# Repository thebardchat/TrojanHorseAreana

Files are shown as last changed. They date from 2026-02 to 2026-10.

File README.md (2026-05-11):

# Hazel Green Trojans Sports Complex — Phase 1 3D Model

**North Alabama Regional Athletic Complex**
*"Building Champions, One Mat at a Time"*

School Colors: **Red (#CC0000)** and **Black (#1A1A1A)**

This project operates under the [ShaneTheBrain Constitution](https://github.com/thebardchat/constitution/blob/main/CONSTITUTION.md).

---

## Infrastructure

All `thebardchat` repositories run on the following local-first infrastructure:

| Component | Detail |
|---|---|
| **Compute** | Raspberry Pi 5 (16 GB RAM) |
| **Chassis** | Pironman 5-MAX by Sunfounder (NVMe RAID) |
| **Storage** | 2x WD Blue SN5000 2 TB NVMe — RAID 1 via mdadm |
| **Core path** | `/mnt/shanebrain-raid/shanebrain-core/` |
| **Dev environment** | Claude Code on Pi 5 |

> Pi before cloud. Privacy before convenience. — Pillar 4

---

## Phase 1 Specifications

| Attribute | Value |
|---|---|
| Building Footprint | 120 ft x 250 ft |
| Total Area | ~30,000 SF |
| Ceiling Height | 24 ft (single story, arena clearance) |
| Seating Capacity | ~800 (bleachers on 2 sides) |
| Wrestling Mats | 4 practice (32 ft dia.) + 1 championship (42 ft dia.) |
| Estimated Budget | $4M - $6M |

### Layout Zones

- **Entrance Lobby** (1,500 SF) — Public entry with ticket/check-in
- **Boys Locker Room** (2,000 SF)
- **Girls Locker Room** (2,000 SF)
- **S&C / Weight Room** (3,000 SF)
- **Restrooms & Concessions** (1,000 SF)
- **Wrestling Arena** — Championship center mat + 4 practice mats with bleacher seating

---

## Generated Files

### 3D CAD Models
- `Hazel_Green_Trojans_Complex.step` — Universal CAD exchange format (opens in any CAD software)
- `Hazel_Green_Trojans_Complex.stl` — 3D print / mesh render format

### Rendered Views
- `render_floorplan_2d.png` — Professional annotated 2D floor plan (for presentations)
- `render_aerial.png` — Bird's eye 3D aerial view
- `render_entrance.png` — Front entrance perspective
- `render_arena.png` — Interior arena view showing championship mat

### FreeCAD Conversion
- `import_to_freecad.py` — Macro to import STEP into FreeCAD and save as `.FCStd`

### Source Scripts
- `build_3d_model.py` — CadQuery parametric 3D model generator (produces STEP & STL)
- `render_floorplan.py` — matplotlib 2D floor plan renderer
- `render_3d_views.py` — matplotlib 3D perspective view renderer

---

## How to Regenerate

```bash
# Install dependencies
pip install cadquery matplotlib Pillow numpy

# Generate 3D model (STEP + STL)
python3 build_3d_model.py

# Generate 2D floor plan
python3 render_floorplan.py

# Generate 3D rendered views
python3 render_3d_views.py

# Convert STEP to FreeCAD native format (run inside FreeCAD)
# Open FreeCAD > Macro > Execute Macro > select import_to_freecad.py
```

---

---

## Credits

Built with Claude (Anthropic) · Runs on Raspberry Pi 5 + Pironman 5-MAX

| Partner | Role |
|---|---|
| **Claude by Anthropic** · [claude.ai](https://claude.ai) | Co-built this entire ecosystem |
| **Raspberry Pi 5** · [raspberrypi.com](https://www.raspberrypi.com) | Local compute backbone |
| **Pironman 5-MAX** · [pironman.com](https://www.pironman.com) | NVMe RAID 1 chassis that made it real |

---

*Created for Hazel Green Trojans — [@thebardchat](https://github.com/thebardchat) · Hazel Green, Alabama*

---

<div align="center">

Pulsar Sentinel — Quantum Security (https://sentinel.shanebrain.cloud)

### ⚡ Pulsar Sentinel — Quantum Security for the Rest of Us





**800 million Windows computers just lost security updates.**
Pulsar Sentinel wraps them in ML-KEM post-quantum encryption, immutable blockchain audit trails, and automatic digital inheritance — no lawyers, no cloud dependency, no corporate kill switch.

**[→ Get Protected at sentinel.shanebrain.cloud](https://sentinel.shanebrain.cloud)**

*Built by Shane Brazelton + Claude (Anthropic) · Hazel Green, Alabama*



</div>

---

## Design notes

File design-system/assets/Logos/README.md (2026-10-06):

# Logos

The THA (Trojan Horse Arena) mark lives in `blueprints/brand/` and is not duplicated here, so there is one copy to keep current.

| File | Ink | Use on |
|---|---|---|
| `blueprints/brand/THA_logo_red.svg` | #cc0000 (`school-red`) | paper or light grounds |
| `blueprints/brand/THA_logo_white.svg` | #ffffff | dark grounds, `brand` fills |
| `blueprints/brand/THA_logo_black.svg` | #1a1a1a (`school-black`) | one-color print |

Each file is a fixed fill. Do not recolor or redraw the mark.

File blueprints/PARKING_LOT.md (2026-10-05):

# PARKING LOT — KEYSTONE

Ideas that don't serve the current mission go here. Nothing on this list gets drawn, sized, or put in a params file until Shane promotes it in writing.

## Sustainability inspiration (parked per prompt §4)
- 2026-10-03: **D-018 DECIDED.** Rooftop solar + stormwater storage PROMOTED to Phase 2 as design intent (phase2.yaml `sustainability`, unsized). Retractable roof CUT. The stadium numbers below stay reference only and never go in params.

The concept compares Phase 2 to **Mercedes-Benz Stadium**. **These are that stadium's numbers, not this project's.** Don't draw them, size them, or put them in `phase2.yaml`.

- Retractable 8-petal ETFE roof (CUT per D-018)
- 4,000+ solar panels
- 680,000-gallon cistern
- 2.1M-gallon vault
- "47% less water"

If Shane asks later: a cited R-file on what *scaled* versions would mean here (rooftop solar, rainwater harvest for field irrigation, daylighting, LED + efficient HVAC). Source: prompt §4 and intake LOOK & FEEL.

## Phase 2 program (parked by D-030)

- 2026-10-03 11:39 PM CT (D-030, "Shane, firsthand"): **Suites** — future add-on, study after attendance is proven. Not drawn and not in the locked program. Starting point when promoted: P2-G-003 Rev C (frozen) + R-016 (suite sizes, precedents, code flags; a suite level would be a 3rd story).

## Other parked items

- From the 2026-10-03 intake: an early Gemini prompt used Kelly Green #006B3C + gold. **Rejected.** Red and black, never green. Kept here only so nobody brings it back.
- The repo's public landing page (`index.html`, protected) calls the project "A strategy battle arena built in the ShaneBrain ecosystem." That doesn't describe the athletic complex. KEYSTONE won't edit it (protected file). Shane, your call.

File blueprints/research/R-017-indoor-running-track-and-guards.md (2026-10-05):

# R-017 — Indoor running / walking track: lane width, lane count, laps per mile, crossings, guards (Phase 2, Level 2 loop)

Researched by KEYSTONE 2026-10-04 for P2-T-004 Rev D (P2-A-101/102 Rev D) and P2-G-003 Rev F, after Shane's 4:55 AM CT direction (D-035 DECIDED): a complete continuous walkway / running-training loop around the top of Level 2. All sources retrieved 2026-10-04.
Status: research note. The track sources are design guides (one DoD criteria document, two trade-press articles), not building code. Guard text is IBC 2021 (UpCodes, Alabama). AHJ and code edition are OPEN (D-008).

## Sources
- **S1** — UFC 4-740-02N, *Fitness and Recreational Facilities* (DoD Unified Facilities Criteria), §4.1.7 indoor running track — https://www.constructionknowledge.net/public_domain_documents/Div_11_Equipment/DOD_Fitness_and_Rec_facilities_4_740_02n.pdf — retrieved 2026-10-04. CRITERIA (federal design guide; not binding here).
- **S2** — Athletic Business, "A Running Start" — https://www.athleticbusiness.com/facilities/fitness/article/15140481/a-running-start — retrieved 2026-10-04. TRADE PRESS.
- **S3** — Athletic Business, "Designing Tracks for Recreational Users" — https://www.athleticbusiness.com/facilities/rec-center/article/15146121/designing-tracks-for-recreational-users — retrieved 2026-10-04. TRADE PRESS.
- **S4** — IBC 2021 Chapter 10, Means of Egress, §§1015.2-1015.4, 1030.17 (UpCodes, Alabama) — https://up.codes/viewer/alabama/ibc-2021/chapter/10/means-of-egress — retrieved 2026-10-04. PRIMARY (via viewer).

## R-017.1 Lane width and lane count

QUESTION: How wide should a recreational indoor running / walking loop be, per lane and overall?

ANSWER: S1 §4.1.7 sets an indoor running track at a minimum of 12 ft wide with at least 3 lanes of 42 in. S2 reports three lanes of 36-42 in as typically adequate for recreational tracks and cites ACSM's 20 ft inside radius for turns. KEYSTONE uses **42 in per lane** (the top of S2's range, S1's figure). With the upper tier fixed at 15 ft and the box at 204 x 252 ft, only **7 ft = 2 lanes** fits without moving the tier or growing the box; the existing Rev C east walkway was already 7 ft. **2 lanes is ASSUMED and is fewer than both guides recommend (3).** 3 lanes x 42 in = 10.5 ft (S2); 12 ft (S1). The loop has squared corners (no 20 ft radius turns), so it suits walking and easy running more than fast running.

## R-017.2 Laps per mile

ANSWER: S3: no more than 12 laps per mile, 8-10 preferred. Rev D centerline = 2 x (148 + 205) = 706 ft → 5,280 / 706 = **7.48 laps per mile**, which is fewer laps (a longer loop) than the preferred range, so it meets the guidance. Lane 1 (inside) ≈ 2 x (144.5 + 201.5) = 692 ft; lane 2 (outside) ≈ 720 ft (arithmetic, lane centerlines 1.75 ft in from each edge).

## R-017.3 Crossings

ANSWER: S3 names users crossing the track as a hazard and recommends bringing stairs up inside the track perimeter. In Rev D the stairs and the elevator open onto the outside of the loop, and on event days spectators cross it to reach the upper tier (the loop is the upper concourse on event days). KEYSTONE treats the loop as a training feature on non-event days only; crossing points, signage and lane markings are architect / operations items.

## R-017.4 Guards at open edges

ANSWER: S4 §1015.2: guards are required along open-sided walking surfaces located more than 30 in above the floor or grade below, measured within 36 in horizontally of the edge. §1015.3: guards at least 42 in high. §1015.4: openings must not pass a 4 in sphere (with listed exceptions). §1030.17: guards at assembly seating (cross aisles, perimeter of tiers) have their own heights. Rev D marks 42 in guards on the loop's west edge (over the arena / athlete corridor) and the south edge over the double-height lobby; the tier backs need rails / guards per 1030.17 (architect).

EDITION / SECTION: IBC 2021 §§1015.2, 1015.3, 1015.4, 1030.17. 2018 numbering differs for assembly (1029.x); D-008 edition OPEN.

CONFIDENCE: MEDIUM for lane width and laps (design guides) / HIGH for the guard rules / LOW for the loop geometry (ASSUMED).

NEEDS ARCHITECT CONFIRMATION: YES (lane count, track surface, corner treatment, crossings, guard design, structure under the west leg).

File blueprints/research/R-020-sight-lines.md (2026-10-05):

# R-020 — Sight-line study: C-values for the telescopic lower tier and the fixed upper tier (P2-A-302 Rev A)

Researched and computed by KEYSTONE 2026-10-04 (Shane 7:24 AM CT: "sight-line study BEFORE more seating detail"). All sources retrieved 2026-10-04.
Status: research note + schematic calculation. Not a design by a licensed architect; the AHJ / architect confirm. Values and method: `params/phase2_sightlines.yaml`; sheet P2-A-302 Rev A; generator `phase2/src/p2_a_302.py` (`--md` prints the table below).

## Sources
- **S1** — Starena Group, "Sight Lines for Seated Spectators" (reprints Green Guide diagram 12.1 and the C formula) — https://www.starenaaust.com/products/stadium-seating/sight-lines — SECONDARY (the Green Guide itself, DCMS *Guide to Safety at Sports Grounds* 5th ed. 2008 §12.3, was not purchased).
- **S2** — Parametric Monkey, "Stadium seating bowl with Dynamo" (2017) — https://parametricmonkey.com/2017/10/23/seating-bowl/ — formula C = D(N+R)/(D+T) − R (Green Guide §12.3, p.109); BVN Stadium.Cvalue defaults: eye 1,200 mm above the tread, 150 mm forward of the row's rear edge, "considered industry standard"; C descriptors 60 / 90 / 120 / 150 mm.
- **S3** — FIFA, *Football Stadiums Guidelines* 2.3 Stadium Bowl — https://publications.fifa.com/es/football-stadiums-guidelines/general-process-guidelines/design/stadium-bowl/ — C = 120 optimal, 90 preferred, 60 minimum in specific areas, "should be avoided in lower tiers"; upper tiers may go lower.
- **S4** — CEN/TR 15913:2009 (iTeh preview) — https://cdn.standards.iteh.ai/samples/32554/d7b4616fb5e0479f8e98daf147f88d63/SIST-TP-CEN-TR-15913-2009.pdf — "C ≥ 90 mm generally acceptable for all newly constructed spectator stands"; uses 1.15 m (wheelchair user) and 1.8 m (standing person) in accessible-viewing checks.
- **S5** — DIN EN 13200-1:2019 summary (kpt-bj.com listing) — standing eye 1.6 m (SECONDARY; standard text not purchased). Shane's range 5'-2"–5'-6" (1.57–1.68 m) contains it.
- **S6** — Hussey Seating, MAXAM brochure, Dimensional Data + Notes (box copy `research_src/hussey_maxam.pdf`, R-008 S4): 6 rows @ 11⅝" → overall seat height 6'-3⅛", closed 3'-6"; recessed: +6" depth (4'-0"), +2¼" height (6'-5⅜"); rear row stays in the recess when open.
- **S7** — IBC 2021 1003.2 (ceiling ≥ 7'-6" in means of egress), 1003.3.1 (80" headroom), 1030.14.2 (aisle risers 4–8", treads ≥ 11"), 1030.17.3 (26" sightline-constrained guard) — UpCodes.

## Method
- C (mm) = D_front × R_behind / D_behind − R_front, every eye placed from the actual tier geometry (equivalent to S2's formula; also handles the step from the lower to the upper tier and the loop rail).
- Eyes: seated 1.2 m above the row tread, 0.15 m forward of the row's rear edge (S2); standing 1.6 m (S5). Rail stander: 1 ft behind the upper tier's back edge on the loop, standing (ASSUMED).
- Focal point (Shane): near edge of the nearest mat, at the floor (mat thickness ignored — slightly conservative). From the frozen plan Rev D: N and S tier fronts **25 ft** from the nearest mat edge (10 ft clear + 15 ft table zone); E tier front **10 ft**. No west tier.
- Grades (KEYSTONE): ≥ 90 mm PASS (S3 preferred, S4), 60–90 MARGINAL (Shane's 60–90 target; S3 minimum), < 60 FAIL.
- AS DRAWN = P2-A-301 geometry: lower 6 rows × 24" @ 11⅝" (Hussey, ASSUMED choice), front at the floor; upper 5 rows × 36" @ 14" stepping DOWN from the loop (L2 FF 15 ft, D-049) to a 9.17 ft front row; 26" fascia.
- PROPOSED (D-053, OPEN): upper riser 19" per row (3 aisle risers of 6⅓" on 12" treads — within 1030.14.2) → front row 15 − 5 × 19/12 = **7.08 ft**; east tier 6 ft further from the mats (focal 16 ft). Lower tier unchanged.
- 2D sections only (perpendicular to each side). Corners, wheelchair positions (S4 1.15 m eye), the mixed case (front row standing, row behind seated) and the focal height of a raised mat are NOT checked.

## Results (C in mm; ~ = marginal, ✗ = fail)

| Row | drawn N/S 25 ft seated | drawn N/S 25 ft standing | drawn E 10 ft seated | drawn E 10 ft standing | proposed N/S 25 ft seated | proposed N/S 25 ft standing | proposed E 16 ft seated | proposed E 16 ft standing |
|---|---|---|---|---|---|---|---|---|
| L2 | 190 | 162 | 74 ~ | 15 ✗ | 190 | 162 | 142 | 101 |
| L3 | 178 | 152 | 64 ~ | 13 ✗ | 178 | 152 | 129 | 92 |
| L4 | 167 | 142 | 57 ✗ | 11 ✗ | 167 | 142 | 118 | 84 ~ |
| L5 | 157 | 134 | 51 ✗ | 10 ✗ | 157 | 134 | 109 | 77 ~ |
| L6 | 149 | 127 | 46 ✗ | 9 ✗ | 149 | 127 | 101 | 72 ~ |
| U1 | 1014 | 984 | 829 | 780 | 428 | 397 | 352 | 313 |
| U2 | 49 ✗ | 20 ✗ | -119 ✗ | -162 ✗ | 211 | 183 | 139 | 103 |
| U3 | 45 ✗ | 19 ✗ | -107 ✗ | -146 ✗ | 198 | 171 | 127 | 94 |
| U4 | 43 ✗ | 18 ✗ | -97 ✗ | -133 ✗ | 185 | 161 | 118 | 87 ~ |
| U5 | 40 ✗ | 17 ✗ | -89 ✗ | -122 ✗ | 175 | 151 | 109 | 81 ~ |
| RAIL | 582 | 182 | 513 | 113 | 709 | 309 | 673 | 273 |
| fascia clearance U1 (mm) | 286 | 661 | 131 | 490 | 326 | 701 | 263 | 631 |
| upper front row deck (ft) | 9.17 | 9.17 | 9.17 | 9.17 | 7.08 | 7.08 | 7.08 | 7.08 |

Failures AS DRAWN:
- **Upper tier fails on every side**: N/S seated 40–49, standing 17–20; east negative (rows U2–U5 cannot see the near mat edge over the row in front). 14" per 36" row is too flat for a 25 ft (or 10 ft) focal distance.
- **East lower tier** (10 ft focal): seated L4–L6 fail (46–57), L2–L3 marginal (64–74); standing 9–15 (all fail).
- N/S lower tier passes (seated 149–190, standing 127–162). U1 sees well over the lower tier (≥ 780) and over the fascia (clearance 131–661 mm). Rail standers pass (113–582).

Riser / layout changes that close it (all seated rows ≥ 101, PROPOSED column):
1. **Upper riser 14" → 19" per row.** Because the back stays at the loop (D-049), the front row drops 9.17 → 7.08 ft. 16" passes N/S (94–114) but not the east side; 19" is the smallest round value tested that passes both with change 2.
2. **East side: move the east tier 6 ft further from the mats (10 → 16 ft clear).** With the loop fixed at 15 ft and a 10 ft focal distance no riser pair reaches 60 mm (best ≈ 46 mm with 19" upper). 12 ft → 68; 14 ft → 85; 16 ft → 101 (seated). Cost: +6 ft east-west ≈ +1,512 SF footprint (51,503 → 53,015, still < 55,000 cap, D-031), or take 6 ft from the 22 ft east support zone.
3. Lower tier stays at 11⅝" (Hussey). A 16" Hussey rise fixes the east lower rows alone, but its top (≈ 6.7 ft) then collides with the stepped-down upper tier front.
- East standing stays MARGINAL (72–103) with the proposal. Sensitivity: with S4's 1.8 m standing eye the east L6 standing value drops to 57 (fail), N/S stays ≥ 116.

## Telescopic stack under the upper-tier front (D-049)
- **Closed, recessed** (S6 minimum recess 4'-0" deep × 6'-5⅜" high): as drawn (front 9.17 ft) it fits only if the tier structure + finish at the front edge is **≤ 32.6 in** (9.17 − 6.45 ft). With the proposed 7.08 ft front only **7.6 in** remain → does not fit.
- **Open**: in a recessed application the rear rows stay in the recess (S6), so rows 5–6 would sit under the overhang. Row 6 deck 4.84 ft + 7'-6" (1003.2, aisle = means of egress) = 12.34 ft needed vs the tier deck ≈ 10.72 ft at the recess back, less structure → **CONFLICT** (as drawn and proposed).
- Recommendation: keep the stack **wall-attached in front of the upper-tier face** (as P2-A-301 Rev A/B draws it); use the low zone under the tier for storage / mechanical only (D-049). Exit passages that run under the tier front (EXIT N / E passages) still need a ≥ 7'-6" ceiling → local raise or vomitory cut at the next A-101/A-102 revision.

QUESTION: Do the drawn tiers give acceptable sight lines to the near mat edge, seated and standing?

ANSWER: **No for the upper tier (all sides) and the east lower tier.** Upper risers of 19" per row plus a 16 ft east focal distance bring every seated row to ≥ 101 mm (PASS) and standing to ≥ 72 mm (east marginal). Logged as D-053 (OPEN, Shane decides). Seating detail should wait for that decision.

CONFIDENCE: HIGH for the arithmetic / MEDIUM for the inputs (secondary sources for eye heights; geometry schematic; focal point per Shane).

NEEDS ARCHITECT CONFIRMATION: YES (final tier section, wheelchair sightlines, guard type at the fascia, structure depth under the tier, scoreboard / rigging obstructions).

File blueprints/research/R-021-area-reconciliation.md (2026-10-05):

# R-021 — Area reconciliation: program basis vs drawn basis (Phase 2)

Written 2026-10-04 8:40 AM CT by KEYSTONE for Shane (8:36 AM CT order, item 4). Read-only arithmetic; no drawing, no new sheet.
**Rules applied:** there is **no 55,000 SF cap** (D-056 — "55,000 SF = early rough estimate, not a limit"; D-031 retired), so this note has no margin lines. Every area table reports **L1 footprint, L2 area, TOTAL GSF and change vs the last revision** (D-057).

## Sources

- **S1** `params/phase2_plan_rev_d.yaml` — P2-A-101/102 Rev D geometry (building 204 x 252 ft + NE tower 19 x 5; arena volume [56,56,182,224]; L2 open-to-below: arena 126 x 168, lobby 58 x 34). Frozen with Phase 2 Schematic Set Rev A (D-036).
- **S2** P2-A-102 Rev D area check (sheet text): "Drawn L2 floor 28,363 SF (building minus open-to-below) … Total drawn ≈ 79,866 vs 78,784 program GSF (P2-G-003 Rev F)."
- **S3** `phase2/src/p2_testfit.py` `summary_f()` / `compute_loop()` + `params/phase2_program.yaml` — P2-G-003 Rev F method: gross-up g = 1.25, mechanical 5 % of gross on L1, arena volume AV = g x (event floor + lower seating), footprint F = max(L1, AV + L2), loop 4,942 SF added to L2 without gross-up. Re-run 2026-10-04 8:38 AM CT (unchanged code, output below).
- **S4** D-052 (4 stairs x 76 in, mid landing = width → 152 x 256 in = 12.67 x 21.33 ft = 270.2 SF per stair per level; Rev F program stair = 63.95 in x (132 + 2 x 48) in = 202.5 SF); D-051 (landing ≥ width, IBC 2021 1011.6).
- **S5** D-053 (east seats 6 ft further from the mats → east wall + 6 ft; 6 x 252 = 1,512 SF L1).
- **S6** `params/phase2_site.yaml` `footprint_check` (P2-C-101 Rev A arithmetic, 7:44 AM CT).

ASSUMED (KEYSTONE, LOW): the east shift widens the arena volume / L2 open-to-below by 6 ft over its 168 ft N-S length (6 x 168 = 1,008 SF), so L2 gains 1,512 − 1,008 = 504 SF; the 19 in upper risers (D-053) change heights, not plan area; the 76 in stairs grow inward from their corners (P2-C-101 Rev A), so only the NE tower (ST-2) widens (2.333 x 5 = 11.67 SF, on both levels).

## 1. True current size (drawn basis) — D-057 table

| Basis | L1 footprint (SF) | L2 area (SF) | TOTAL GSF (SF) | Change vs last revision |
|---|---:|---:|---:|---|
| **As drawn: P2-A-101/102 Rev D** (frozen) | 51,503.0 | 28,363.0 | 79,866.0 | vs Rev C: see P2-A-102 Rev D |
| **Decided, next A-101/A-102 revision** (D-052 + D-053, not yet drawn) | **53,026.7** | **28,878.7** | **81,905.3** | **+1,523.7 / +515.7 / +2,039.3** vs Rev D |

Arithmetic:
- Rev D L1 = 204 x 252 = 51,408 + 19 x 5 = 95 → **51,503.0** (S1).
- Rev D L2 = 51,503 − 126 x 168 (21,168, arena open) − 58 x 34 (1,972, lobby open) → **28,363.0** (S1, S2). TOTAL = 51,503 + 28,363 = **79,866.0**.
- Next rev L1 = 51,503 + 1,512 (east shift) + 11.67 (NE tower) = **53,026.7**.
- Next rev L2 = 28,363 + 1,512 − 1,008 (wider arena opening, ASSUMED) + 11.67 = **28,878.7**. TOTAL = **81,905.3**.

**Answer: the true current size is L1 footprint 53,027 SF / L2 area 28,879 SF / TOTAL GSF 81,905 SF** (decided state; the frozen drawings still show 51,503 / 28,363 / 79,866). The program basis below is a planning-factor estimate, not the size.

## 2. Program basis (P2-G-003 Rev F method) — same table form

| Step | L1 gross (SF) | L2 gross (SF) | Footprint F (SF) | TOTAL GSF (SF) |
|---|---:|---:|---:|---:|
| Rev F as approved (S3) | 51,194.1 | 27,589.5 | 52,738.4 (AV 25,148.8 + L2) | 78,783.6 |
| + 76 in stairs (S4): stairs + elevator 874.0 → 1,144.9 net per level (+270.9) | 51,577.8 | 27,928.1 | 53,076.9 | 79,505.9 |
| + east shift (S5, flat add as on P2-C-101 Rev A; L2 +504 ASSUMED as above) | — | 28,432.1 | **54,588.9** | **81,521.9** (79,505.9 + 1,512 + 504) |

Note: in the program the footprint is set by AV + L2 (25,148.8 + 27,589.5 = 52,738.4), which is larger than the programmed L1 gross (51,194.1): the L2 deck needs 1,544 SF more ring than the L1 rooms make, so the footprint carries ≈ 1,544 SF of L1 space that no program line counts. In the drawn plan that is the FLEX space (team assembly ≈ 2,072, FLEX / storage 1,011).

## 3. Line-by-line reconciliation: footprint 54,588.9 (program) vs 53,026.7 (drawn) = 1,562.2

| # | Line | What the program counts | What the drawing counts | Program | Drawn | Δ (P − D) |
|---|---|---|---|---:|---:|---:|
| 1 | Arena volume (event floor + telescopic lower tier, double height) | 1.25 x (16,400 floor + 3,719 telescopic seats [1,100 x 3.38]) | 126 x 168 box: floor 114 x 144 = 16,416 + tier bands N/S 2 x 126 x 12 = 3,024 + E 12 x 144 = 1,728 | 25,148.8 | 21,168.0 | **+3,980.8** |
| 2 | L2 deck over the L1 ring (upper tier, S&C, cross-training, admin, restrooms, stairs/elevator, loop) | 1.25 x 18,118.0 net + 4,942 loop | building − arena opening − lobby opening (incl. L2 corridor, stretch strip, upper concourse) | 27,589.5 | 28,363.0 | **−773.5** |
| 3 | Lobby open-to-below (double-height lobby inside the footprint) | not modelled (foyer is 800 net on L1 only) | 58 x 34 inside the footprint, no L2 floor | 0.0 | 1,972.0 | **−1,972.0** |
| = | Subtotal: Rev F program vs Rev D drawn | | | 52,738.4 | 51,503.0 | **+1,235.4** |
| 4 | 76 in stairs (D-052) | 4 x (270.2 − 202.5) = 270.9 net per level, x 1.25 on L2 (F follows AV + L2) | stairs grow inward; only the NE tower widens 2.333 x 5 | +338.6 | +11.7 | **+326.9** |
| 5 | East shift 6 ft (D-053) | flat +6 x 252 | +6 x 252 | +1,512.0 | +1,512.0 | **0.0** |
| = | **Total** | | | **54,588.9** | **53,026.7** | **+1,562.2** |

Check: 3,980.8 − 773.5 − 1,972.0 = 1,235.3 (1,235.35 unrounded) + 326.9 + 0 = **1,562.2** ✓.

Where the gap comes from, in plain terms:
1. **+3,981** — the program grosses up the event floor and seats by 25 % as if they were rooms with walls and corridors (16,400 x 0.25 = 4,100 alone). The real arena volume is one open box, so the drawing is smaller there.
2. **−774** — the drawn L2 deck is a bit bigger than the program's L2 (the drawing has a full L2 corridor zone and a 6 ft stretch strip that the program does not list).
3. **−1,972** — the program never counted the double-height lobby's footprint above the 800 SF foyer; the drawing does.
4. **+327** — the program adds the 76 in stairs as new grossed-up area; the drawing absorbs them inside the existing box.

## 4. TOTAL GSF reconciliation (decided state)

| | Program estimate | Drawn basis | Δ (P − D) |
|---|---:|---:|---:|
| L1 | 53,089.8 (51,577.8 + 1,512; programmed rooms only) | 53,026.7 (full footprint) | +63.1 |
| L2 | 28,432.1 | 28,878.7 | −446.6 |
| **TOTAL GSF** | **81,521.9** | **81,905.3** | **−383.4** |

The totals sit within 0.5 %: the program's extra arena gross-up is roughly offset by the space it never counts (lobby void footprint, unprogrammed L1 ring under the L2 overhang).

## Confidence

HIGH for the arithmetic (re-run from params); LOW for the geometry behind it (every plan coordinate is ASSUMED, schematic). The east-shift L2 split (+504) is ASSUMED until the next A-101/A-102 revision draws it.

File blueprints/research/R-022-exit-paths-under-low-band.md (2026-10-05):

# R-022 — Exit paths under the upper tier's low band (Phase 2)

Written 2026-10-04 by KEYSTONE for Shane (9:47 AM CT order: "do NOT redesign silently — write the finding with TWO options with numbers, log OPEN, show the conflict on A-301 Rev C"). This is arithmetic only. Nothing is redesigned: P2-A-101/102 Rev E stay as drawn and P2-A-301 Rev C shows the conflict in red. Decision: **D-061 OPEN**.

## Sources

- **S1** `params/phase2_plan_rev_e.yaml` (P2-A-101/102 Rev E). Upper tier: 5 rows × 36 in, 19 in risers, front row 7.08 ft, steps down from the loop at L2 FF 15 ft (D-049, D-053). `low_band_ft: 6` = rows 1–2. Zones: exit_n [123.85,224,131.85,252], exit_e [188,175.09,210,183.09], conc_e [165,0,210,56], lobby [84,0,142,56] (PORTAL x 107–119), ath_route [56,48,84,56], concession [127,37.67,142,56]. Upper bands: N [56,224,188,239], S [56,41,188,56], E [188,41,203,239].
- **S2** `params/phase2_sect.yaml` `rev_c`: 1.5 ft deck structure under each tread (ASSUMED). Clear under rows 1–5 = 5.58 / 7.17 / 8.75 / 10.33 / 11.92 ft.
- **S3** IBC 2021 1003.2: the means of egress needs a ceiling height of at least 7 ft 6 in (UpCodes, retrieved 2026-10-04, the same citation as P2-A-301 Rev B and P2-A-302 Rev A).
- **S4** `phase2/src/p2_testfit.py` `summary_g()` / P2-G-003 Rev G: upper-tier capacity 1,155 for the 1,100 required (55 spare). Upper seat factor is 6.0 SF/seat (R-008) on 3 ft rows, so 2 ft of row per seat = **0.5 seat per foot per row**.
- **S5** `phase2/src/p2_a_302.py` `calc()`: C-values for the raised-tier variant (Option B).
- **S6** D-052 (76 in stairs, 26 risers at 6.92 in), D-051 (intermediate landing = width, IBC 2021 1011.6), IBC 2021 1011.5.2 (risers 4–7 in, treads ≥ 11 in), 1030.14.2 (aisle risers 4–8 in), 1030.6.2.2 (roof ≥ 15 ft above the highest aisle, if smoke-protected).

## 1. Finding: exit paths under the 6 ft low band

The clear height under rows 1–2 is 5.6 ft and 7.2 ft (S2). Both are below 7'-6" (S3). These paths cross the band:

| Path | Where it crosses the band | Length under rows 1–2 |
|---|---|---:|
| EXIT (N) | x 123.85–131.85, y 224–230 (V1 → X5) | 8 ft |
| EXIT (E) | y 175.09–183.09, x 188–194 (V2 → X7) | 8 ft |
| SE concourse | S strip x 165–188 (y 50–56) + E strip y 41–56 (x 188–194) | 23 + 15 = 38 ft |
| Lobby / portal / athlete-route edge | x 56–127, y 50–56: athlete route 28 ft (x 56–84) + lobby 43 ft (x 84–127, incl. PORTAL 12 ft at x 107–119) | 71 ft |
| **Total** | | **125 ft** |

Also noted (not an egress path): the concession's north 6 ft (x 127–142) is under the band. An occupiable room also needs a 7'-6" ceiling (IBC 2021 1208.2, KEYSTONE recollection, not re-read today). That strip should be counter-back storage, or it is resolved by Option B.

D-060 (which locker reading) stays OPEN, drawn as on A-101 Rev E: event lockers start behind the band (2,723 SF vs 3,600 programmed).

## 2. Option A — omit upper rows 1–2 over each path (vomitory-style cut)

Seats lost = 2 rows × length × 0.5 seat/ft (S4).

| Path | Seats lost |
|---|---:|
| EXIT (N) 8 ft | 8 |
| EXIT (E) 8 ft | 8 |
| SE concourse 38 ft | 38 |
| Lobby / portal / athlete-route edge 71 ft | 71 |
| **A (all paths)** | **125** |

- Upper capacity 1,155 → **1,030**, which is **70 short** of the 1,100 upper seats (only 55 spare). Holding 1,100 would need 70 × 6.0 = 420 SF of upper band somewhere else, or 70 seats moved to the lower tier (lower-tier room not checked).
- Building SF is unchanged. Seats delivered = 1,100 lower + 1,030 upper = 2,130, so GSF per seat = 81,976.4 ÷ 2,200 = 37.3 → 81,976.4 ÷ 2,130 = **38.5 SF/seat** if the 70 are not replaced.
- **A-min variant:** rail off the strips that are not exit paths (the SE concourse strip as storage, the lobby strip except the portal as display). Cut rows 1–2 only over EXIT (N) 8 + EXIT (E) 8 + PORTAL 12 + athlete route 28 = **56 seats** → 1,099, **1 short** of 1,100. The athlete route is 8 ft wide with 6 ft under the band, so it cannot be railed off.
- Clear under the cut: the soffit becomes row 3 = 8.75 ft ≥ 7'-6". The upper tier gets openings with guards at each cut (1015 / 1030.17). Lower-tier vomitories V1 / V2 already line up with Exit N / Exit E.
- Not drawn. (A non-option note: shifting the athlete route 6 ft south into Concourse W would take it out from under the band and cut A-min to 28 seats. That is a layout change and is not drawn either.)

## 3. Option B — raise the upper tier (and all of Level 2) so row 1 clears 7'-6"

The tier's back stays at the loop = L2 FF (D-049), so clearing row 1 means raising L2.

- **L2 FF 15'-0" → 17'-9" (213 in), upper risers 19 → 21 in** (3 aisle risers of 7.0 in, 12 in treads, inside 1030.14.2). Front row = 17.75 − 5 × 1.75 = **9.0 ft**. Clear under row 1 = 9.0 − 1.5 = **7.5 ft = 7'-6"** (meets 1003.2 exactly; no margin).
- Why 21 in and not 19: raising L2 by 1.92 ft with 19 in risers would also give a 9.0 ft front row, but east seated C would drop to 68 mm (standing 40, FAIL) (S5). At 21 in the minimum C equals Rev E: **N/S seated 149 / standing 127, E seated 101 / standing 72 mm**. Higher risers gain nothing because the lower tier then sets the minimum.
- **Seats lost: 0.** The low band disappears, so the event lockers can run back to the tier lines: **3,600 SF (+877)**, which makes D-060 moot.
- **Stairs:** 213 in ÷ 7 in max → 31 risers at 6.87 in, 2 flights (16 + 15), 15 treads × 11 in = 165 in run. Each stair is 152 × (48 + 165 + 76) = 152 × 289 in = 12.67 × 24.08 ft = **305.1 SF vs 270.2: +34.8 SF per stair per level, ≈ +279 SF** for 4 stairs × 2 levels (clear dimensions). Each stair is 2.75 ft longer. If ST-2 grows outward, the NE tower goes 6.67 → about 9.4 ft deep (+58.7 SF L1 footprint).
- **SF/seat:** +279 SF ÷ 2,200 = **+0.13 SF/seat** (37.3 → 37.4 GSF/seat), with no seats lost.
- **Heights:** ring roof 30 → **32.75 ft** (L2 + 15). Ring walls on A-201 are 2.75 ft taller. Arena U/S structure stays 36 ft and roof 42 ft, so the court clear is unchanged. 1030.6.2.2 (if smoke-protected): highest aisle = loop 17.75 ft → roof ≥ 32.75 ft; 36 ft drawn (3.25 ft margin). Elevator travel 17.75 ft.
- **Also re-check:** the telescopic stack still sits at the tier face (P2-A-302 Rev B). L2 rooms (S&C, cross-training) sit 2.75 ft higher. The 26 in fascia at the front still clears (U1 C unchanged).

## 4. Comparison

| | Option A (cut rows 1–2) | A-min (rails + cut 4 paths) | Option B (L2 17'-9", 21 in risers) |
|---|---:|---:|---:|
| Upper capacity lost | 125 | 56 | 0 |
| Upper capacity vs 1,100 | 1,030 (−70) | 1,099 (−1) | 1,155 (+55) |
| Building SF change | 0 | 0 | ≈ +279 (stairs) |
| Seats delivered / GSF per seat | 2,130 / 38.5 | 2,199 / 37.3 | 2,200 / 37.4 |
| Event lockers | 2,723 SF (D-060 open) | 2,723 SF (D-060 open) | 3,600 SF (D-060 moot) |
| Sight lines (min C seated N/S / E) | unchanged 149 / 101 | unchanged | 149 / 101 |
| Other | guards at each cut | rails + storage strips | ring roof 32.75', taller walls, longer stairs |

KEYSTONE does not pick an option. Shane decides **D-061**.

## 5. Decided (2026-10-04 10:27 AM CT)

Shane chose **Option B** (D-061 DECIDED): "raise Level 2 to 17'-9" with 21 in upper risers. No seats lost; upper-tier front row ≥ 7'-6" clear over ALL exit paths." D-060 is settled in the same message: event lockers go back to the full 3,600 SF behind the tier.

How it was drawn (P2-A-101/102 Rev F, P2-A-301 Rev D, P2-A-302 Rev C, P2-A-201 Rev G, P2-C-101 Rev C, P2-G-003 Rev I):

- **Stairs grow inward.** Each stair is 12.67 × 24.08 ft (31 risers at 6.87 in, 16 + 15). ST-2 grows **west** along the north wall, not north. The NE tower becomes 24.08 × 6.67 ft (was 21.33 × 6.67), not the ~9.4 ft deep tower estimated in §3. The rest of the growth comes out of interior rooms (mech N, S&C, stretch).
- **Drawn size (D-057):** L1 53,080.6 / L2 28,932.6 / TOTAL 82,013.1 GSF, which is **+36.7 vs Rev E** (only the tower's +18.3 SF on each level). §3's ≈ +279 SF was the program-side growth. The program (G-003 Rev I) grows +371.6 (L1 + L2 gross 81,119.1) because vertical circulation goes from 1,144.9 to 1,284.2 SF per level.
- **Clearance:** front row 9.0 ft. Clear = 7'-6" exactly with 1.5 ft structure ASSUMED: **no margin, structural engineer to confirm.**
- **Sight lines (A-302 Rev C):** the lower tier still governs, at N/S 149 / 127 and E 101 / 72 mm. Upper tier N/S 179 / 156, E 105 / 76 mm. No FAIL. East standing stays MARGINAL.
- **1030.6.2.2 (if smoke-protected):** highest aisle = loop 17.75 ft, so the roof must be ≥ 32.75 ft. The arena's U/S structure is drawn at 36 ft, so it PASSES with a 3.25 ft margin.

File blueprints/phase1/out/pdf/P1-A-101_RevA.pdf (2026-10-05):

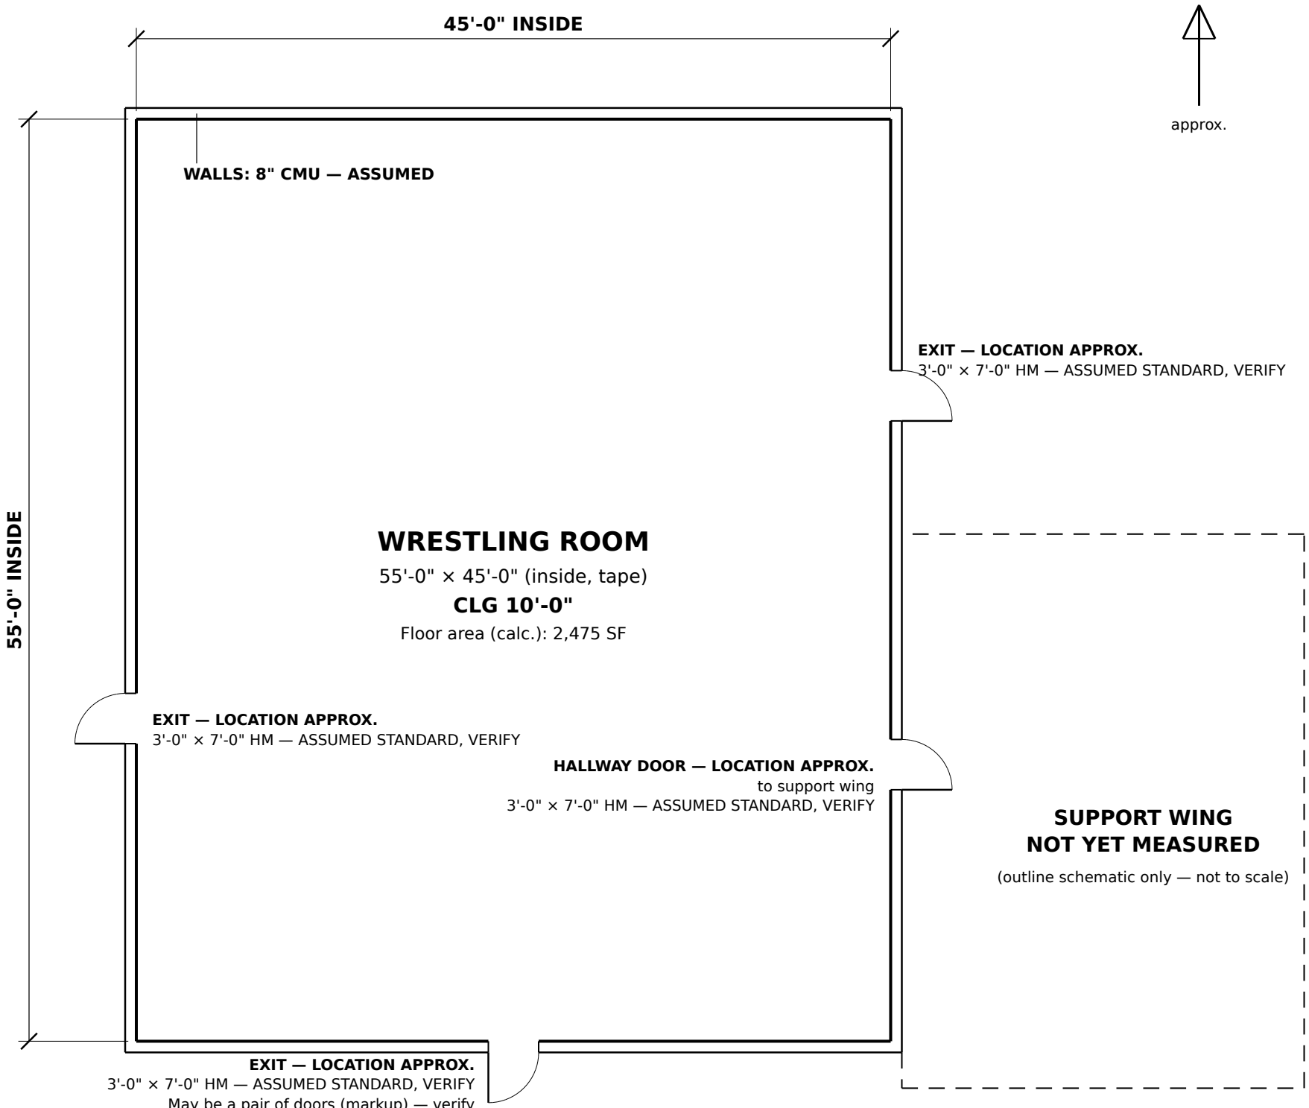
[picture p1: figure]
EXIT — LOCATION APPROX.; HALLWAY DOOR — LOCATION APPROX. to support wing; WRESTLING ROOM; 55'-0" × 45'-0" (inside, tape) CLG 10'-0"; Floor area (calc.): 2,475 SF; WALLS: 8" CMU — ASSUMED; 45'-0" INSIDE; 55'-0" INSIDE; SUPPORT WING NOT YET MEASURED; (outline schematic only — not to scale); approx.

# PRELIMINARY — CONCEPTUAL DESIGN — NOT FOR CONSTRUCTION

PROJECT

### Hazel Green Regional Athletic Complex Hazel Green, Madison County, Alabama

PHASE

## PHASE 1 REMODEL

SHEET TITLE

### EXISTING CONDITIONS PLAN WRESTLING ROOM — ROOM OUTLINE ONLY

SCALE
1/8" =
1'-0"

DATE

## October

2026

REV
A

DRAWN BY
Drawn by KEYSTONE (AI) for Shane Brazelton

SHEET
P1-A-101

# EXISTING CONDITIONS PLAN

### WRESTLING ROOM — ROOM OUTLINE ONLY

Scale 1/8" = 1'-0" (11x17 printed at 100%)

3'-0" × 7'-0" HM — ASSUMED STANDARD, VERIFY

3'-0" × 7'-0" HM — ASSUMED STANDARD, VERIFY May be a pair of doors (markup) — verify

3'-0" × 7'-0" HM — ASSUMED STANDARD, VERIFY

3'-0" × 7'-0" HM — ASSUMED STANDARD, VERIFY

N

0' | 4' | 8' | 16'
GRAPHIC SCALE 1/8" = 1'-0"

## NOTES

1. Dimensions are to the INSIDE face of the walls, from Shane's tape measurement 2026-10-03: 55'-0" north-south × 45'-0" east-west, wall to wall.
2. Walls: CMU building. Walls drawn as 8" CMU outside the inside face — thickness ASSUMED, verify.
3. Ceiling: 10'-0" (Shane, firsthand).
4. Doors: all 4 openings (3 emergency exits + 1 hallway door) drawn as 3'-0" × 7'-0" single hollow metal doors — ASSUMED STANDARD, VERIFY. Swing and hinge side drawn are assumed.
5. Door LOCATIONS are APPROXIMATE, read from Shane's aerial sketch markup. Not measured, not dimensioned.
6. The south exit may be a pair of doors (two marks on Shane's markup) — verify.
7. The support wing is not yet measured. Its dashed outline is schematic only and not to scale.
8. North arrow is approximate (from the Google Maps aerial). Plan north is up.
9. Windows, wall devices, and existing pads are TBD.

## LEGEND

CMU wall, 8" ASSUMED (inner line = tape-measured inside face)

Door, 3'-0" leaf + swing — ASSUMED STANDARD, VERIFY; location APPROX.

Not yet measured (schematic only)

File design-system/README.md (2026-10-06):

# Trojan Horse Arena

> Building Champions, One Mat at a Time.

The visual language of the Hazel Green Trojans Sports Complex project (North Alabama Regional Athletic Complex): school red and black on architectural drawing sheets, and a neon-on-dark look for the web pages and 3D viewer. Extracted from `thebardchat/TrojanHorseAreana` (render scripts, `index.html`, the 3D viewer, and the KEYSTONE sheet kit in `blueprints/`).

This project operates under the [ShaneTheBrain Constitution](https://github.com/thebardchat/constitution/blob/main/CONSTITUTION.md).

## One brand, two themes

| Theme | Where it is used | Ground |
|---|---|---|
| `paper` | PDF and PNG drawing sheets, floor plans, elevations, print | `surface` #f5f5f0 with white `panel` |
| `arena` | `index.html` landing page, the 3D viewer | `surface` #080c10 with `panel` #0d1520 |

Both share the same role names (`surface`, `panel`, `ink`, `ink-muted`, `brand`, `accent`). Only the values change, so a component written against the tokens works in either.

## Content fundamentals

- **Voice:** short, declarative, sports-program confident. Taglines are three beats: "Strategy. Deception. Victory." and "Building Champions, One Mat at a Time."
- **Casing:** headings, buttons, nav links and labels are UPPERCASE with tracking. Body copy is sentence case.
- **Labels:** web section labels are written as code comments, `// Core Features`. Do not decorate them further.
- **Sheets:** every sheet carries the stamp `PRELIMINARY — CONCEPTUAL DESIGN — NOT FOR CONSTRUCTION` and never says anything stronger than that. Dimensions are written `120 ft`, `32ft Dia.`, `1" = 250'`.
- **Credit line:** `Built together, not alone.` and `Hazel Green, AL` in the footer.

## Visual foundations

- **Color:** red is the only loud color. Use `brand` for the one thing that matters on a screen or sheet; use `ink` and `ink-muted` for everything else. `accent` (yellow on arena, gold fill on paper) marks labels and badges. `success` and `violet` are decoration for feature accents on arena, one per card.
- **Contrast:** `ink` and `ink-muted` hold 4.5:1 on `surface` and `panel` in both themes. `brand` text holds it on `surface` in both themes. `accent` on paper and `violet` on paper are fills only. `brand-deep` is a fill or border, never text.
- **Shape:** square. `radius-sharp` (0) everywhere on the web. The only rounding is `radius-glass` on the 3D viewer's info panel. The only circles are wrestling mats on plans: 42 ft championship, 32 ft practice.
- **Lines:** drawings are built from line weights, not shadows. Use `lw-exterior` for the building outline, `lw-sheet-border` for the sheet frame, `lw-detail` for ordinary edges, `lw-hairline` for tags.
- **Glow:** arena only. `glow-brand` under a primary button, `glow-accent` on the pulsing badge. Never on paper.
- **Backdrop:** arena pages carry a 40px grid of 3%-opacity cyan lines behind content. Sections are separated by a 1px gradient rule, `brand` fading to transparent at 25% opacity.
- **Motion:** one pulse on the accent badge (2s, box-shadow only), color transitions at 0.2s, and a 2–3px lift on hover. Nothing else moves.
- **Layout:** sections max 1000px wide with `space-16` vertical padding and `space-8` gutters. Feature grids use `minmax(240px, 1fr)` with `space-5` gaps.
- **Type:** arena is monospace (`arena` family, Courier New), sheets are DejaVu Sans, the 3D viewer is Inter. Do not mix them on one surface.

## Iconography and marks

- The `THA` mark ships in three single-ink versions in `blueprints/brand/` (see `assets/Logos/README.md`): red (#cc0000), black (#1a1a1a), white. Use red on paper, white on dark or on a `brand` fill, black for one-color print. Never recolor, outline or stretch it. Keep clear space of at least one quarter of the mark's width.
- The web pages use the stadium emoji as a stand-in logo in `index.html`. That is a placeholder; prefer the THA mark.
- No icon set exists in the repo. Use text labels.

## Components

Four static component cards document the patterns that exist in the source: `Button`, `Badge`, `StatBlock`, `TitleBlock`. They are hand-written from `index.html` and `blueprints/shared/titleblock.py`; there is no compiled library to bundle.

## Using it

- CSS: every token is a custom property (`var(--brand)`, `var(--space-6)`, `var(--font-arena)`). Switch theme with `data-theme="paper"` or `data-theme="arena"` on `<html>`.
- Python drawings: the same hexes are constants in `render_floorplan.py`, `render_3d_views.py`, and `blueprints/shared/titleblock.py`. Match `school-red`, `school-black`, `plan-*`.

## Not extracted

- `index.html` uses `color-mix()` in glows and `rgba()` cyan for the grid. Both are rebuilt here as literal shadow and described above, not tokenized.
- The 3D viewer's blue (`rgba(0,170,255)`) drop-zone overlay is a tool state, not part of the brand, and is left out.
- Phase 2 tints (`plan-tint-*`, `brick*`) were read from script palettes; their exact room mapping is inferred.
- The blueprint scripts include many one-off hexes (greys, rooms). Only the ones repeated across scripts became tokens.
- No font files live in the repo; all three families are system or hosted fonts.

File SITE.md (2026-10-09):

# Site: how it updates

`index.html` is a fixed shell. Everything that changes lives in `updates.json` (hero image, direction text, update feed, gallery, upcoming list, documents). Push to `main` and `.github/workflows/deploy.yml` publishes ONLY the public site files (index.html, updates.json, hazel-green-complex-3d.html, concepts/) to Cloudflare Pages (`trojan-horse-arena`). Everything else in the repo (blueprints/, research, decisions, status, cost notes, the Set Rev D PDF, whose cover prints the planning budget range) is never served; add a path to the `Assemble public site` step to publish it.

```
python add_update.py "Title" "What changed." --tag Concept --image concepts/new.png     # new update card
python add_update.py --gallery concepts/new.png "Title" "Caption."                       # new gallery image
python add_update.py --upcoming "Title" "What is next." --status Open                    # new upcoming item
git add -A && git commit -m "site: <what>" && git push origin main
```

Concept images are generated by `render_revD_srm_concept.py`, `render_srm_concept_interior.py`, `render_srm_concept_plan.py` and `render_revD_views.py` into `concepts/`.

Rules: keep the PRELIMINARY stamp; do not publish budget figures, owner-only planning numbers or any claim of an agreement with a named company; no company logos or marks without written permission. The approved set stays `blueprints/phase2/out/pdf/Phase2_Schematic_Set_RevD.pdf` (not published); concept work never overwrites it.

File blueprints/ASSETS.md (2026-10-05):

# ASSETS — KEYSTONE inventory

Inventory date: 2026-10-03 (P1-T-001). **Full ARENA re-inventory 2026-10-04 8:16 AM CT (C-0, prompt v1.3) — §0 is current; §1-§3 are the 2026-10-03 snapshot kept as history.** Times are Central (CT).
Rule: Shane's files are read-only. ARENA is the master (v1.3). **None of Shane's originals are committed to this repo.**

## 0. ARENA master inventory — C-0 (2026-10-04 8:16 AM CT, KEYSTONE prompt v1.3)

**Rule (v1.3):** `C:\Users\Hubby\Desktop\ARENA\` on Shane's PC (Pulsar00100) is the **MASTER**. Repo `blueprints/` is a mirror whose layout follows ARENA. KEYSTONE never moves, renames, reorganizes, deletes or overwrites anything in ARENA. Only `ARENA\_KEYSTONE\` is ours. New revs are new files (sheet + rev letter) in the folder where like files live.
**Method:** read-only `Get-ChildItem -Recurse -Force` + `Get-FileHash SHA256` on Pulsar00100, 2026-10-04 8:15 AM CT. Box copies (read-only pulls) of the intake, the arch photo and the two `_KEYSTONE` STATUS files went to `/workspace/arena_c0/`. Nothing was created or changed in ARENA outside `_KEYSTONE`.
**Count:** 1 folder (`_KEYSTONE`), 27 files, 4,439,503 B total.

### 0a. Folder tree as found (top two levels)

```
C:\Users\Hubby\Desktop\ARENA\
├── _KEYSTONE\            (KEYSTONE's folder: STATUS.json, STATUS.md — now + ASSETS.md)
└── 25 files at the root, no other subfolders:
    sheets (flat, no rev letter in the name):  P1-G-001.pdf, P1-A-101.pdf, P2-G-003.pdf, P2-A-101.pdf, P2-A-102.pdf,
                                               P2-A-201.pdf, P2-A-301.pdf, P2-A-302.pdf, P2-C-101.pdf
    bundles:                                   Phase1_Package_for_Dr_Headen.pdf, Phase2_Schematic_Set_RevA.pdf
    brand:                                     THA_logo_black.svg, THA_logo_red.svg, THA_logo_white.svg,
                                               trojan_horse_logo_Gemini_Generated.jpg
    references / images:                       arenav1-floor-plan.png, Phase2-floor-plan-flat.png, Phase2-floor-plan.jpeg,
                                               wrestle-room-measure.png, THA_grand_entrance_stand_alone_structure_champions_walk.png
    vendor data:                               Champion_Walk_Brick_Pricing - Vendor Prices.pdf
    governing / tooling:                       KEYSTONE_ARCHITECT_PROMPT.md, KEYSTONE_INTAKE_2026-10-03.md, keystone_status.sh,
                                               north_alabama_3d_diorama.html
```

### 0b. Inventory (every file; modified = Pulsar00100 local time, CT)

| # | File (path under ARENA) | Type | Size (B) | Modified (CT) | What it shows (best guess from name / peek / hash match) | Phase | Status |
|---|---|---|---|---|---|---|---|
| 1 | `_KEYSTONE\` | folder | — | 2026-10-04 7:58 AM | KEYSTONE's own folder (status bridge) | shared | ours |
| 2 | `_KEYSTONE\STATUS.json` | JSON | 3,496 | 2026-10-04 7:58 AM | KEYSTONE status; sha256 `e2d3dc90…7334` = repo `blueprints/STATUS.json` @ 1068709 | shared | current (replaced by this C-0 update) |
| 3 | `_KEYSTONE\STATUS.md` | Markdown | 1,028 | 2026-10-04 7:58 AM | Human status; sha256 `495f92b1…1635` = repo `STATUS.md` — **stale text from the 7:24 AM session** (repo had not regenerated it) | shared | stale → replaced by this C-0 update |
| 4 | `KEYSTONE_ARCHITECT_PROMPT.md` | Markdown | 26,643 | 2026-10-03 4:08 PM | KEYSTONE standing instructions, **prompt v1.1** (sha256 `6673735b…1081`). v1.3 (8:13 AM CT) is **not** in ARENA | shared (governing) | superseded by v1.3 (not on disk) |
| 5 | `KEYSTONE_INTAKE_2026-10-03.md` | Markdown | 4,901 | 2026-10-03 4:08 PM | First-session intake (header says "MOVIE MAKER INTAKE", D-015) | shared | **SUPERSEDED where it conflicts (C-9)** — see 0c |
| 6 | `keystone_status.sh` | Bash | 3,360 | 2026-10-03 4:08 PM | Pi-side status reader (SSH to Pulsar00100, GitHub raw fallback, stale after 26 h) | shared (tooling) | current |
| 7 | `north_alabama_3d_diorama.html` | HTML + Three.js | 19,103 | 2026-10-03 4:02 PM | Interactive diorama; hover zones Arena 22,000 / Boys 3,500 / Girls 3,503 / S&C 6,000 / XT 4,000 SF. Same content as repo `hazel-green-complex-3d.html` (CRLF there) | P2 | **SUPERSEDED (C-9): zone data stale; file PROTECTED — do not edit** |
| 8 | `arenav1-floor-plan.png` | PNG 1024×687 | 744,067 | 2026-10-03 5:47 PM | First-draft "Master Floor Plan" board: 55,000 SF, Arena 22,000 SF, green/gold ("Kelly Green") legend, garbled labels. sha256 `d030dcb4…bd54` | P2 | **SUPERSEDED (C-9)** — history; layout source is now the frozen set + decisions |
| 9 | `Phase2-floor-plan-flat.png` | PNG 1024×687 | 744,067 | 2026-10-03 5:47 PM | **Byte-identical copy of #8** (same sha256). Was the D-017 "reference plan" | P2 | **SUPERSEDED (C-9)** (same image as #8) |
| 10 | `Phase2-floor-plan.jpeg` | **WebP** despite .jpeg, 1024×687 | 105,532 | 2026-10-03 5:44 PM | Photo-style render of a 3D tabletop model of the same first-draft plan (wrong labels "CENTEB", girls 3,500). sha256 `528414ea…` | P2 | **SUPERSEDED** (derivative of #8; KEYSTONE call — confirm) |
| 11 | `wrestle-room-measure.png` | PNG 1108×816 | 127,301 | 2026-10-03 9:40 PM | Google Maps aerial of the existing wrestling-room building with measure path 276.85 ft + Shane's markup. **C-12 / D-063: ignore the 250 / 150 / 50 / 276.85 ft labels; never dimensions.** sha256 `4cd9756a…5808` (= box copy, §1c) | P1 | current (input) |
| 12 | `P1-G-001.pdf` | PDF | 54,988 | 2026-10-03 10:26 PM | P1 cover / scope, **Rev D principal** (sha256 = repo `phase1/out/pdf/P1-G-001_RevD_principal.pdf`) | P1 | current |
| 13 | `P1-A-101.pdf` | PDF | 44,766 | 2026-10-03 10:26 PM | P1 wrestling-room plan **Rev A** (= repo `P1-A-101_RevA.pdf`) | P1 | current |
| 14 | `Phase1_Package_for_Dr_Headen.pdf` | PDF | 99,554 | 2026-10-03 10:34 PM | P1 principal package bundle (= repo `phase1/out/pdf/Phase1_Package_for_Dr_Headen.pdf`) | P1 | current |
| 15 | `P2-G-003.pdf` | PDF | 58,134 | 2026-10-04 5:24 AM | Program test-fit **Rev F** (frozen; = repo `P2-G-003_RevF.pdf`) | P2 | current (frozen) |
| 16 | `P2-A-101.pdf` | PDF | 62,033 | 2026-10-04 5:24 AM | Level 1 block plan **"Rev D" — EARLY render, NOT the frozen Rev D**: room 23 "STORAGE (SW)", note "Unprogrammed … storage (SW)" (sha256 `6abfa622…cff7` = repo commit 900c1da, 5:06 AM CT) | P2 | **CONFLICT — C-1** (see 0e) |
| 17 | `P2-A-102.pdf` | PDF | 60,606 | 2026-10-04 5:24 AM | Level 2 block plan **Rev D** (frozen; = repo `P2-A-102_RevD.pdf`) | P2 | current (frozen) |
| 18 | `Phase2_Schematic_Set_RevA.pdf` | PDF | 103,948 | 2026-10-04 5:48 AM | Frozen set: G-003 F + A-101 D (**FLEX / STORAGE, D-039**) + A-102 D (= repo) | P2 | current (frozen) |
| 19 | `P2-A-201.pdf` | PDF | 100,246 | 2026-10-04 8:01 AM | Exterior elevations **Rev D** (portal 50 ft, crown 34 ft; = repo `P2-A-201_RevD.pdf`) | P2 | current |
| 20 | `P2-A-301.pdf` | PDF | 65,715 | 2026-10-04 8:01 AM | Building sections **Rev B** (70 in mid landing; = repo `P2-A-301_RevB.pdf`) | P2 | current (76 in stairs apply next rev) |
| 21 | `P2-A-302.pdf` | PDF | 59,246 | 2026-10-04 8:01 AM | Sight-line study **Rev A** (= repo `P2-A-302_RevA.pdf`) | P2 | current |
| 22 | `P2-C-101.pdf` | PDF | 57,696 | 2026-10-04 7:59 AM | Site plan / campus diagram **Rev A** (= repo `P2-C-101_RevA.pdf`) | P2 | current |
| 23 | `THA_logo_black.svg` | SVG | 24,732 | 2026-10-04 6:14 AM | Official mark, black (= repo `brand/`, sha256 `81d190a7…`) | brand | current |
| 24 | `THA_logo_red.svg` | SVG | 24,732 | 2026-10-04 6:14 AM | Official mark, red #CC0000 (= repo `brand/`) | brand | current |
| 25 | `THA_logo_white.svg` | SVG | 24,732 | 2026-10-04 6:14 AM | Official mark, white (= repo `brand/`) | brand | current |
| 26 | `trojan_horse_logo_Gemini_Generated.jpg` | JPG 2256×1888 | 1,651,859 | 2026-10-04 6:11 AM | Shane's source image of the horse-head badge (black on checker); sha256 `452cbfde…` (not committed, by rule) | brand | current (source) |
| 27 | `THA_grand_entrance_stand_alone_structure_champions_walk.png` | **WebP** despite .png, 1024×576 | 84,624 | 2026-10-04 6:25 AM | Freestanding limestone arch, crimson soffit, lit building beyond, paved promenade with low walls (Shane's own image, D-048). Same picture as the off-repo box ref `portal_freestanding_champion_walk_ref.png` (PNG, 847,527 B, sha256 `93ae1c77…`), different encoding | P2 / brand | current (reference; off-repo) |
| 28 | `Champion_Walk_Brick_Pricing - Vendor Prices.pdf` | PDF, 1 p | 82,394 | 2026-10-04 7:11 AM | Champion Walk brick vendor prices (= the 7:24 AM chat attachment, sha256 `13fcc39c…`; D-044 input) | P2 | current (input; not committed) |

### 0c. SUPERSEDED marks (C-9)

- **First-draft Master Floor Plan image (22,000 SF, Kelly Green legend):** `arenav1-floor-plan.png` and its byte-identical copy `Phase2-floor-plan-flat.png`; also the tabletop render `Phase2-floor-plan.jpeg` (same plan; KEYSTONE call). Superseded by the locked program (D-030: 16,400 SF floor), the frozen Phase 2 Schematic Set Rev A and today's decisions. Red/black only.
- **3D diorama zone data:** `north_alabama_3d_diorama.html` (and repo `hazel-green-complex-3d.html`): Arena 22,000 / S&C 6,000 / XT 4,000 SF and "permanent stadium seating" are stale (D-030, D-035, D-009 MIX). **Protected — not edited.**
- **Feb 2026 concept:** **not found in ARENA.** It lives only in the repo root (`README.md`, `CLAUDE.md`, `build_3d_model.py`, `render_*.py/.png`, `.step/.stl`: 120 x 250 ft, ~30,000 SF, ~800 seats, $4–6M) — already SUPERSEDED (§3), protected.
- **Intake (`KEYSTONE_INTAKE_2026-10-03.md`) — superseded where it conflicts:** "Total 55,000 SF" → footprint cap only, total GSF uncapped (D-031, D-055); "Championship arena 22,000 SF" → 16,400 SF floor (D-030); S&C 6,000 / XT 4,000 → 5,224 / 3,500 (D-035); "South portal … gold soffit; drive clear" → freestanding portal over the Champion Walk, crimson underside + gold trim, ≤ 50 ft (D-043, D-045, D-050); "Phase 2 master floor plan … path UNKNOWN" → found (#8, now superseded); "MOVIE MAKER INTAKE" header (D-015). The rest (vision, Phase 1 program, colors, constraints) stands.
- Also superseded by v1.3: `KEYSTONE_ARCHITECT_PROMPT.md` (v1.1) where v1.3 differs; and per D-055, today's decisions win over v1.3 text.

### 0d. Where things live — ARENA vs repo

| Item | ARENA (master) | Repo mirror (`blueprints/`) |
|---|---|---|
| Sheets (PDF) | root, **current rev only, no rev letter** (`P2-A-201.pdf`) | `phase1/out/pdf/`, `phase2/out/pdf/`, every rev as `<sheet>_Rev<X>.pdf` |
| Sheets (DXF) | **none** | `phase{1,2}/out/dxf/` |
| Bundles | root (`Phase1_Package_for_Dr_Headen.pdf`, `Phase2_Schematic_Set_RevA.pdf`) | `phase{1,2}/out/pdf/` |
| params (YAML) | **none** | `params/` (15 files) |
| DECISIONS / CHANGELOG / BACKLOG / PARKING_LOT / ENVIRONMENT | **none** | `blueprints/` root |
| research (R-files) | **none** | `research/` (18 files) |
| generators / validator | **none** | `phase{1,2}/src/`, `shared/` |
| brand | root (3 SVG + Gemini JPG) | `brand/` (3 SVG; JPG not committed) |
| references / photos / vendor PDF | root | not committed (box copies only) |
| ASSETS / STATUS | `_KEYSTONE\` | `blueprints/ASSETS.md`, `STATUS.json`, `STATUS.md` |
| prompt / intake / status script / diorama | root | not in `blueprints/` (diorama copy at repo root) |

### 0e. ARENA vs repo differences (ARENA wins — reported, NOT fixed)

1. **C-1 — two different "P2-A-101 Rev D" files.** `C:\Users\Hubby\Desktop\ARENA\P2-A-101.pdf` (62,033 B, 2026-10-04 5:24 AM, sha256 `6abfa622ca59b004ecc066c11f9cf82d86c292bfd2409fe45ab2da6948bacff7`) labels room 23 **"STORAGE (SW)"** ("unprogrammed (ASSUMED); team side"). Repo `blueprints/phase2/out/pdf/P2-A-101_RevD.pdf` (frozen, commit 0ec1fb2 5:40 AM, sha256 `6916d6115899c09f7403b8472ffdb14eae4b06a25cf1132b05d3a95d64d915cf`) and page 2 of `Phase2_Schematic_Set_RevA.pdf` (in both places) label it **"FLEX / STORAGE — kept as-is (D-039)"**. The ARENA standalone file is the first Rev D render (commit 900c1da 5:06 AM); the box preview `/workspace/keystone_previews/P2-A-101.pdf/.png` is that same early render. Both carry "REV D".
2. ARENA holds only the current rev of each sheet, with no rev letter in the file name; frozen older revs (P1-G-001 A-C, P2-G-003 A-E, P2-A-101/102 A-C, P2-A-201 A-C, P2-A-301 A) exist only in the repo.
3. **`P1-P-001` Rev A (plumbing scope) is not in ARENA** (repo only).
4. ARENA has no params, DECISIONS, research, CHANGELOG, BACKLOG, DXF or generators — repo-only content.
5. `_KEYSTONE\STATUS.md` (and repo `STATUS.md`) were stale (7:24 AM text) while `STATUS.json` was current — regenerated in this update.
6. Prompt in ARENA is v1.1; v1.3 is not on disk.
7. Arch photo: ARENA has a WebP-encoded `.png` (84,624 B); the box ref is a PNG (847,527 B) of the same picture.
8. Diorama: same content, line endings differ (ARENA LF 19,103 B; repo CRLF 19,531 B).
9. Repo root holds the Feb 2026 concept files and the public `index.html`; none are in ARENA.

## 1. Shane's ARENA folder: `C:\Users\Hubby\Desktop\ARENA\` (pulsar00100) — 2026-10-03 snapshot (history; see §0)

Per Shane, the folder first held **exactly 4 files**. On 2026-10-03 Shane added 2 images, and a byte-identical copy of the reference plan was saved there as `Phase2-floor-plan-flat.png`. **The folder then held 7 files.** Later on 2026-10-03 Shane added `wrestle-room-measure.png` (Phase 1 site sketch). **The folder now holds 8 files.** KEYSTONE read the box copies in `/workspace/arena_src/` and got nothing from Shane's PC. Sizes/times for the new files: box copies, plus Shane's info.

| File | Type | Size | Modified (CT) | What it is / shows | Phase |
|---|---|---|---|---|---|
| `KEYSTONE_ARCHITECT_PROMPT.md` | Markdown | 26,643 B | 2026-10-03 4:08 PM | KEYSTONE standing instructions, prompt v1.1: locked facts, repo contract, backlog, status bridge | Both (governing doc) |
| `KEYSTONE_INTAKE_2026-10-03.md` | Markdown | 4,901 B | 2026-10-03 4:08 PM | First-session intake compiled from the Gemini, Grok, and Claude sessions. **Header says "MOVIE MAKER INTAKE," but the content is KEYSTONE's** (D-015) | Both |
| `keystone_status.sh` | Bash script | 3,360 B | 2026-10-03 4:08 PM | Pi-side ShaneBrain preflight reader. Reads STATUS.json from pulsar00100 over SSH, falls back to the GitHub raw mirror on `grok/keystone`, flags stale after 26 h, always exits 0. Has a `KEYSTONE_LOCAL_FILE` test override | Bridge (both) |
| `north_alabama_3d_diorama.html` | HTML + Three.js r128 (CDN) | 19,103 B | 2026-10-03 4:02 PM | Interactive 3D diorama, see §1a. **Demoted to secondary 2026-10-03:** presentation viewer, not the layout source | Phase 2 (secondary) |
| `Phase2-floor-plan-flat.png` | PNG, 1024×687 | 744,067 B | 2026-10-03, time not given (copy saved on Shane's PC) | Byte-identical copy of `arenav1-floor-plan.png` (sha256 `d030dcb4…bd54`). **Phase 2 REFERENCE PLAN (primary), designated by Shane 2026-10-03.** See §1b | **Phase 2 (primary reference)** |
| `arenav1-floor-plan.png` | PNG, 1024×687 | 744,067 B | 2026-10-03, time not given (added by Shane) | Flat color-coded "HAZEL GREEN REGIONAL ATHLETIC COMPLEX - Master Floor Plan." sha256 `d030dcb46a65d98e47b2c0041a20554dc38465aa0028c8130b196723f880bd54`. **Phase 2 REFERENCE PLAN (primary), designated by Shane 2026-10-03** (D-017). See §1b | **Phase 2 (primary reference)** |
| `Phase2-floor-plan.jpeg` | Image, 1024×687. **The file is WebP-encoded despite the .jpeg name** | 105,532 B | 2026-10-03, time not given (added by Shane) | Photo-style render of a lit 3D tabletop model of the same plan in a lobby. sha256 `528414ead71092ce357e592dc0028bdb06672a901a6de23ce2094a853aba1b20`. **Presentation render only, NOT a source.** Its text is wrong: boys 3,900, girls 3,500, seating labels swapped (north 2,200 / south 3,200), and a "Conversion" legend (Wrestling 15,000 / Jiujitsu 36,000 / Basketball 25,000 / Volleyball 15,000 SF) that conflicts with the 22,000 SF floor | Phase 2 (presentation only) |
| `wrestle-room-measure.png` | PNG, 1108×816 (RGBA) | 127,301 B | 2026-10-03 ~9:46 PM (box copy; Shane's time not given) | Google Maps aerial of the wrestling room building with the 'Measure distance' tool (total path 276.85 ft / 84.38 m) and Shane's hand markup of rooms, exits, and fixtures. **C-12 / D-063: labels 250 / 150 / 50 / 276.85 ft are NOT dimensions.** sha256 `4cd9756ae606f7e8c688053619528abc0220d6045f12230eddc17ba071df5808`. Original `C:\Users\Hubby\Desktop\ARENA\wrestle-room-measure.png`. **Not committed.** See §1c | **Phase 1 (rough estimate + layout notes only)** |

### 1a. What the diorama shows (`north_alabama_3d_diorama.html`)

- Page title "North Alabama Interactive Diorama." A dark scene with a 3D presentation board (100 × 60 scene units, **not to scale, no feet**) under bloom lighting and orbit controls.
- The board top starts as a grid placeholder: "DRAG & DROP MASTER FLOOR PLAN HERE." Dropping an image on the page maps it onto the board. **The master floor plan image is not bundled.**
- 5 hidden hover zones light up with a neon glow and an info panel (name, SF, blurb):
  - Championship Arena, 22,000 SF: "4 regulation wrestling mats… Permanent stadium seating surrounds the lowered event floor"
  - Boys Locker Room, 3,500 SF
  - Girls Locker Room, 3,503 SF
  - Strength & Conditioning, 6,000 SF
  - Cross-Training Mat Area, 4,000 SF
- SF values match the prompt §3 Phase 2 table. **Nothing in it is Phase 1** (no wrestling-room remodel content).
- **Same file as the repo's `hazel-green-complex-3d.html` (commit 8a2f4c6).** Content is identical once line endings are ignored. The repo copy uses CRLF (19,531 B); Shane's copy uses LF (19,103 B).
- Findings (no changes made):
  - The arena blurb says "Permanent stadium seating" and "lowered event floor." Seating type is still OPEN (D-009), and a lowered floor isn't a locked fact.
  - "4 regulation wrestling mats" is unverified (D-014 / R-005). **Update 2026-10-03:** R-005 written; 4 mats fit 22,000 SF by area only (arithmetic, room dims TBD). D-014 still OPEN.
  - Zone glow colors include blue and pink. That's a viewer UI choice, not a brand color, but brand colors are red/black (prompt §3).

### 1b. Phase 2 reference plan: what it shows (`Phase2-floor-plan-flat.png` = `arenav1-floor-plan.png`)

Shane's rule (D-017): **USE** zones, adjacencies, the 5 SF tags, and the room list. **IGNORE** dimension strings, scale bar, garbled text (e.g. "CENTEB," "ETAKD"), and the green/gold legend (red/black is locked). North is taken as up per prompt §3. The north arrow sits bottom-right but its direction isn't legible at this resolution.

**SF tags used:** Championship Wrestling Arena 22,000 · Boys Locker Room 3,500 · Girls Locker Room 3,503 · Strength & Conditioning 6,000 · Cross-Training Mat Area 4,000. Legend: "Total Square Footage 55,0?0 SF" (digits garbled) and "Arena Capacity: 2,200 Spectators."

**Adjacencies as drawn (objective read):**
- **Northwest:** Strength & Conditioning.
- **North center:** Cross-Training Mat Area, east of S&C.
- **West side:** Boys Locker Room directly above (north of) Girls Locker Room, under S&C. A north–south athlete corridor (solid gray arrows) runs on their east side.
- **Center:** concourse / concession core. A "Concession Stand" with a counter and seating sits next to a "Public Restroom" (flanked by two small fixture rooms labeled "RR"/"RM," garbled). The **Stage** is on the arena's west edge, facing the concourse.
- **East:** the arena, 4 mats labeled Wrestling Mat 1–4 in a 2×2 grid, on a red floor border. Seating banks on the **north** ("Stadium Seating (3,200 Capacity)"), **south** ("(2,200 Capacity)"), and **east** (no label). Short curved banks wrap the NW and SW corners and flank the stage on the west.
- **South center:** Public Entry. Dashed red spectator-flow arrows go from the entry north into the concourse and east into the arena. More dashed arrows run east–west along the north concourse between the Cross-Training door and the arena's NW corner.
- **Southwest of the concourse:** "Public Restroom," two "First Aid" rooms, an "Administrative Office," and a "First Aid Room" further south by the entry.
- **South edge, east of entry** (service strip under the south seating): an unlabeled room with toilets/sinks, an unlabeled room with a table, "Utility Room," "Administrative Storage," "Equipment Room," and "Mechanical / Electrical Room."
- **Northeast corner:** "Equipment Storage."
- **Southeast corner:** "Mechanical / Storage / Utility."
- Other small rooms: a fixture room at the north wall between Cross-Training and the arena (label garbled "P&D #08"), and a small room SW of the stage with a stair/lift-like symbol (label garbled).

**Observations (nothing changed):**
- **No 4 event/visitor locker rooms** under the bowl are shown yet, and **no mezzanine overlook** on the daily mat. Both are §3 design rules (3) and (4) still to add.
- The plan shows a **"Public Restroom" in the concourse core and another "Public Restroom" SW.** That's two, matching Shane's x2.
- Seating labels: north 3,200 vs south 2,200, while the legend says arena capacity 2,200. Locked value stays **2,200 total** (D-016 OPEN).
- The legend calls spectator arrows "Dashed Gold," but they're drawn red. The legend calls the arena "Nelly Green/Gold," but the arena is drawn red. Ignored per D-017.
- A gray athlete-flow arrow runs east–west from the locker corridor into the concourse, where the dashed spectator arrows also run. Whether the athlete/spectator split holds (§3 design rule 1) needs checking at A-101. No change made.
- Dimension strings and scale bar are inconsistent (e.g., overall "27.30'"). Ignored per D-017.

### 1c. Phase 1 aerial sketch: what it shows (`wrestle-room-measure.png`, Shane 2026-10-03)

**RULE (C-12, D-063, Shane 2026-10-04 10:48 AM CT, v1.3 §15): ignore the 250 / 150 / 50 / 276.85 ft labels on this markup; never use them as dimensions.** **What it is:** a Google Maps aerial with the measure tool, plus Shane's hand markup. **It is a rough aerial estimate, NOT a tape measurement.** It is never drawn as existing conditions and does not close D-001.

**Measure path (KEYSTONE check):** starts at "0" at the NW corner of the wrestling room roof, runs down the west side, across the south, up the east side, back across the north, then diagonally NW → SE. Total **276.85 ft (84.38 m)**. Side pixel lengths are about 413 / 350 / 413 / 354 px, and the diagonal is about 545 px. That gives 7.49 px/ft, and the 5 ft minor ticks independently measure 7.46 px/ft. **Exterior roof footprint ≈ 55 ft N-S × 47 ft E-W (diagonal ≈ 72.7 ft), confidence LOW.** The interior room will be smaller (walls, eaves). Tick check: the 50 ft tick lands about 49.9 ft down the west side, the 150 ft tick about 7 ft below the NE corner, and the 250 ft label about 63% along the diagonal. All three match the labels. Recorded in phase1.yaml `existing.wrestling_room.estimate_aerial`. **Update 2026-10-03 10:06 PM CT:** Shane's tape gives the inside dimensions as 55'-0" × 45'-0", which agrees with the estimate. The estimate stays a cross-check only.

**Used on P1-A-101 Rev A (door marks only):** the four door/exit triangles were read off this sketch as APPROX. positions along each wall (`existing.wrestling_room.doors_approx`):
- west exit about 0.65 of the way down from the north
- south exit at about mid-wall (two triangles, possibly a pair of doors)
- NE exit on the east wall about 0.30 from the north
- hallway door on the east wall about 0.70 from the north

These are not measured, and no dimensions are given.

**Update 2026-10-03 10:12 PM CT:**
- P1-A-101 now draws these four openings as 3'-0" doors. That size is ASSUMED STANDARD, VERIFY; the locations are still APPROX.
- The walls are drawn as 8" CMU (ASSUMED).
- **Photos not yet received:** Shane says Dr. Headen (principal) took photos. Copies are requested on P1-G-001 Rev D (ask #5). Once received, they go here.

**Layout per Shane's markup (qualitative, phase1.yaml `existing.layout_notes`):**
- The **wrestling room** is the large west block.
- **Emergency exits** are marked on its west side, its south side, and one near its NE corner.
- **Support wing** to the east:
  - two "broken showers"
  - a "private toilet"
  - a urinal
  - two toilets
  - a washer/dryer
  - an office
  - two storage rooms
- Two **"open hallway"** segments run east–west through the wing. This is the walk-through route.
- **Yellow stars** (water fountain / sink) sit near the urinal and hallway.
- The map label reads "Hazel Green Wrestling."
- Doors and exits are drawn as triangles.
- A **"flag football side"** field lies to the east.

**Odd or unclear items (no change made):**
- The vertex circles sit a few px off the path's corners. It looks like a screenshot rendering offset. KEYSTONE measured the path lines and ticks, not the circles.
- The path is drawn about 1.4° off north. So the aspect ratio taken from the diagonal (0.82) differs from the side lengths (0.85).
- The NE emergency-exit triangle is drawn just outside the roof outline.
- The "Hazel Green Wrestling" map label overlaps the support wing.
- The yellow-star legend floats north of the wing.
- There is a whited-out blank area between the private toilet and the storage rooms.
- One storage room has a green scribbled oval in it.
- The office/wing reaches east toward the red-outlined "flag football side" area.
- A separate gray building edge shows at the far west.

## 2. Assets referenced but NOT in the ARENA folder

| Asset | Status | Action |
|---|---|---|
| **Phase 2 master floor plan image** (55,000 SF, color-coded). Base reference for Phase 2 layout | **RECEIVED 2026-10-03:** `arenav1-floor-plan.png`, saved in ARENA as `Phase2-floor-plan-flat.png` (§1, §1b) | Use per D-017. Phase 1 still first |
| Grok session "Wrestling Facility Phase One Remodel Planning": proposal page with `/model.html` maquette | **Location unknown.** Not on this box. pulsar00100 not searched (see ENVIRONMENT.md) | Ask Shane where it's hosted/saved |
| Google Drive: "Trojan Horse Arena Trailer v2 - Widescreen.m4v", "Trojan Horse Arena Trailer v2 - Vertical.m4v" | Exist per intake. **Not inspected** | Reference only. Not needed for drawings |

### 2a. Possibly related material found on the KEYSTONE box (not in ARENA, not used, not committed)

- `/workspace/trojan-horse-arena/assets/floorplan_src.png` (1024×687), from an earlier trailer session on this box. It's an **AI render of a "HAZEL GREEN REGIONAL ATHLETIC COMPLEX - Master Floor Plan" board.** It *may* be a render of the master floor plan Shane means, but that's **unconfirmed.** Its AI text is unreliable and conflicts with locked facts:
  - boys locker tag reads like "3,900 SF"
  - girls reads "3,500 SF"
  - one seating sign reads "3,200"
  - legend says "Neily Green/Gold"
  - a "Conversion" legend lists SF numbers that don't match the 22,000 SF floor
  Per the intake: **don't copy text from renders.**
  **Update 2026-10-03:** this file (sha256 `39467dabdc8caef54f9fb200ae9b3d450c934e6afa3465d8030adc2263ec07f3`) is a **different file from both** new ARENA images. It's the same tabletop render as `Phase2-floor-plan.jpeg` (pixel mean difference ~0.8/255, i.e. a re-encode), with the same wrong labels. **Still unused.** The reference plan is `Phase2-floor-plan-flat.png`.
- `/workspace/trojan-horse-arena/loudon/` is a clone of `thebardchat/loudon-desarro` ("Loudon / DeSarro Athletic Complex," 50,000 SF). Its `wrestling_facility_phase1.py` describes a *new* 10,000 SF metal building as "Phase 1." **That's a different, older concept.** It doesn't match the locked Phase 1 (remodel) or Phase 2 (55,000 SF). Ignored.

## 3. Repo root inventory: `thebardchat/TrojanHorseAreana` @ `main` 8a2f4c6 (read-only)

| File | Last commit | What it is | Status |
|---|---|---|---|
| `README.md` | a102198 (2026-05-11) | Says "Phase 1 3D Model": 120 ft × 250 ft, ~30,000 SF, 24 ft ceiling, ~800 seats, $4M–$6M | **Superseded Feb 2026 concept.** Protected |
| `CLAUDE.md` | 537af8e (2026-03-14) | Claude Code config. Describes the same Feb 2026 model. Tells Claude to push to `claude/trojans-sports-complex-3d-r07Pw` | Protected. Claude's rules, not KEYSTONE's |
| `build_3d_model.py` | 3795c57 (2026-02-05) | CadQuery generator: 120×250×24 ft building | **Superseded Feb 2026 concept** |
| `render_floorplan.py` | 3795c57 (2026-02-05) | matplotlib 2D floor plan of that building | **Superseded** |
| `render_3d_views.py` | f834e50 (2026-02-05) | matplotlib 3D views of that building | **Superseded** |
| `import_to_freecad.py` | f834e50 (2026-02-05) | FreeCAD macro: STEP → FCStd | Superseded-concept tooling |
| `Hazel_Green_Trojans_Complex.step` / `.stl` | 3795c57 (2026-02-05) | CAD output of the Feb 2026 model | **Superseded** |
| `render_floorplan_2d.png` | 3795c57 (2026-02-05) | 2D plan render of the Feb 2026 model | **Superseded** |
| `render_aerial.png`, `render_entrance.png`, `render_arena.png` | f834e50 (2026-02-05) | 3D renders of the Feb 2026 model | **Superseded** |
| `hazel-green-complex-3d.html` | 8a2f4c6 (2026-10-03) | Phase 2 interactive diorama. Same as Shane's `north_alabama_3d_diorama.html` (§1a) | **Current, Phase 2.** Protected |
| `index.html` | 6beb65e (2026-04-23) | Public landing page: "Trojan Horse Arena — A strategy battle arena built in the ShaneBrain ecosystem." Doesn't describe the complex (see PARKING_LOT) | Protected. Auto-deploys |
| `LICENSE` | c0e58fa | GPL v3 | Protected |
| `.github/workflows/deploy.yml` | 435aed6 | Push to `main` → `wrangler pages deploy .` to Cloudflare Pages project `trojan-horse-arena` (public) | Protected. **Why KEYSTONE never touches `main`** |
| `.github/` other | — | FUNDING.yml, PR template, issue templates | Read-only |

Remote branches seen: `main`, `claude/add-article-vii-sponsorship-qtkOG`, `claude/trojans-sports-complex-3d-r07Pw` (not touched), plus `grok/keystone` (KEYSTONE's).
**Superseded numbers (120×250, ~30,000 SF, ~800 seats, $4–6M) are history. They're blocked from `params/` by `shared/validate.py`.**

## 2026-10-03 additions (10:29 PM CT session)
- **R-005 source copies** (box scratch `/workspace/research_src/`, **not committed**): `utah_2014_15.pdf` / `utah.txt` (NFHS 2014-15 Wrestling Rules Book, full public copy), `ahsaa_wr_2026_27.pdf` / `ahsaa.txt` (AHSAA 2026-27 Wrestling), `nfhs_changes_2026_27.pdf` (NFHS 2026-27 rule changes via LHSAA). `nfhs_wr_2023_24.pdf` is an AccessDenied error page, not a rulebook. The current NFHS rulebook is paywalled and was not obtained.
- **Print bundle** `blueprints/phase1/out/pdf/Phase1_Package_for_Dr_Headen.pdf` (also `/workspace/keystone_previews/`): `pdfunite` of the frozen `P1-G-001_RevD_principal.pdf` + `P1-A-101_RevA.pdf`, 2 pages, 1224 × 792 pt. Built from the committed files, not regenerated.

## 2026-10-03 additions (10:45 PM CT session, P2-T-003b)
- **Research source copies** (box scratch `/workspace/research_src/`, **not committed**): `upc_ibc10.txt` (IBC 2021 ch. 10 via UpCodes, Alabama), `upc_alabama_ipc-2021_…txt` (IPC 2021 ch. 4), `upc_texas_ibc-2018_…txt` (IBC 2018 ch. 29, for comparison), `loudoun.pdf/.txt` (Loudoun County Capital Facilities Manual 2014), `groton.pdf` (Groton MA feasibility study), `hussey_maxam.pdf` (Hussey MAXAM brochure). codes.iccsafe.org pages need a login to render; UFC 4-740-02 PDF returned 403.
- **New Phase 2 data file** `params/phase2_program.yaml` (test-fit factors + room list, every group sourced). Locked values stay in `phase2.yaml`.
- **New Phase 2 sheet** `phase2/out/pdf/P2-G-003_RevA.pdf` + `phase2/out/dxf/P2-G-003_RevA.dxf` (tabloid landscape, one page), generated by `phase2/src/p2_g_003.py`. Previews (box only): `/workspace/keystone_previews/P2-G-003.png`, `/workspace/keystone_previews/P2-G-003.pdf`.

## 2026-10-03 additions (11:09 PM CT session, P2-G-003 Rev B)
- **New Phase 2 sheet** `phase2/out/pdf/P2-G-003_RevB.pdf` + `phase2/out/dxf/P2-G-003_RevB.dxf` (two-level test-fit, tabloid landscape, one page), from `phase2/src/p2_g_003.py --rev B`. Rev A files are FROZEN and unchanged.
- **Previews (box only):** `/workspace/keystone_previews/P2-G-003.png` (now Rev B), `/workspace/keystone_previews/P2-G-003_RevA.png` (Rev A preview kept), `/workspace/keystone_previews/P2-G-003.pdf` (now Rev B).
- **New research** `research/R-015-two-level-stacking-and-vertical-circulation.md`.
- **Research source copies** (box scratch `/workspace/research_src/`, **not committed**): `upc_ibc_chapter_11_accessibility.html/.txt` (IBC 2021 ch. 11), `upc_ibc_chapter_9_fire-protection-and-life-safety-systems.html/.txt` (IBC 2021 ch. 9), `ada2010.html/.txt` (2010 ADA Standards, access-board.gov), `reed.pdf/.txt` (Reed Arena Facility Guide), `orleans.pdf/.txt` (Orleans Arena Production Guide 2024).

## 2026-10-03 additions (11:26 PM CT session, P2-G-003 Rev C)
- **New Phase 2 sheet** `phase2/out/pdf/P2-G-003_RevC.pdf` + `phase2/out/dxf/P2-G-003_RevC.dxf` (suites study, tabloid landscape, one page), from `phase2/src/p2_g_003.py --rev C`. Rev A and Rev B are FROZEN and unchanged.
- **Previews (box only):** `/workspace/keystone_previews/P2-G-003.png` (now Rev C), `P2-G-003_RevB.png` (Rev B kept), `P2-G-003_RevA.png`, `P2-G-003.pdf` (now Rev C).
- **New research** `research/R-016-suites-small-arenas.md`.
- **Research source copies** (box scratch `/workspace/research_src/`, **not committed**): `pitt.pdf/.txt` (Petersen Events Center Production Guide 2020), `wku.html/.txt` (College Heights Herald 2002), `sheldon.pdf/.txt` (Sheldon ISD Panther Stadium), `ttu.html/.txt` (Texas Tech arena facts).

## 2026-10-03 additions (11:39 PM CT session, D-030 locked program + block plans)
- **New Phase 2 sheet** `phase2/out/pdf/P2-G-003_RevD.pdf` + `phase2/out/dxf/P2-G-003_RevD.dxf` (LOCKED PROGRAM, tabloid landscape, one page), from `phase2/src/p2_g_003.py --rev D` (now the default). Revs A, B and C are FROZEN and unchanged.
- **New Phase 2 sheets** `phase2/out/{pdf,dxf}/P2-A-101_RevA` (Level 1) and `P2-A-102_RevA` (Level 2): schematic block plans, 1/32 in = 1 ft-0 in on tabloid, from `phase2/src/p2_a_plan.py --sheet P2-A-101|P2-A-102`. DXF in paper inches (1 in = 32 ft).
- **New Phase 2 data file** `params/phase2_plan.yaml` (block-plan coordinates in feet, every group sourced; layout ASSUMED).
- **Previews (box only):** `/workspace/keystone_previews/P2-G-003.png` + `P2-G-003.pdf` (now Rev D), `P2-G-003_RevC.png` (Rev C kept), `P2-G-003_RevB.png`, `P2-G-003_RevA.png`; `P2-A-101.png` + `P2-A-101.pdf`, `P2-A-102.png` + `P2-A-102.pdf`.
- Layout reference used (box only, not committed): `/workspace/arena_src/arenav1-floor-plan.png` (same plan as `Phase2-floor-plan-flat.png`).

## 2026-10-04 additions (4:30 AM CT session, D-009 MIX seating + Rev B block plans)
- **New Phase 2 sheet** `phase2/out/pdf/P2-G-003_RevE.pdf` + `phase2/out/dxf/P2-G-003_RevE.dxf` (LOCKED PROGRAM, MIX seating, tabloid landscape, one page), from `phase2/src/p2_g_003.py --rev E` (now the default). Revs A–D are FROZEN and unchanged.
- **New Phase 2 sheets** `phase2/out/{pdf,dxf}/P2-A-101_RevB` (Level 1) and `P2-A-102_RevB` (Level 2), from `phase2/src/p2_a_plan.py --sheet P2-A-101|P2-A-102` (`--rev B` default). Rev A files are FROZEN and unchanged (`--rev A` regenerates them byte-identical).
- **New Phase 2 data file** `params/phase2_plan_rev_b.yaml` (Rev B block-plan coordinates in feet, 204 × 252 ft box, every group sourced; layout ASSUMED). `params/phase2_plan.yaml` stays as the frozen Rev A geometry.
- **Previews (box only):** `/workspace/keystone_previews/P2-G-003.png` + `.pdf` (now Rev E), `P2-G-003_RevD.png` (Rev D kept); `P2-A-101.png` + `.pdf`, `P2-A-102.png` + `.pdf` (now Rev B), `P2-A-101_RevA.png`, `P2-A-102_RevA.png` (Rev A kept).

## 2026-10-04 additions (4:43 AM CT session, D-033 single controlled entry, Rev C block plans)
- **New Phase 2 sheets** `phase2/out/{pdf,dxf}/P2-A-101_RevC` (Level 1) and `P2-A-102_RevC` (Level 2), from `phase2/src/p2_a_plan.py --sheet P2-A-101|P2-A-102` (`--rev C` default). Rev A and Rev B files are FROZEN and unchanged.
- **New Phase 2 data file** `params/phase2_plan_rev_c.yaml` (Rev C geometry: checkpoint, controlled door, perimeter doors, exit passages; ASSUMED). `phase2_plan_rev_b.yaml` stays as the frozen Rev B geometry (also read by P2-G-003 Rev E).
- **Research:** `research/R-015-two-level-stacking-and-vertical-circulation.md` gains R-015.6 (single controlled entry: exit-only doors, main exit, checkpoint; IBC 2021 Ch. 10 re-read 2026-10-04).
- **Previews (box only):** `/workspace/keystone_previews/P2-A-101.png` + `.pdf`, `P2-A-102.png` + `.pdf` (now Rev C); `P2-A-101_RevB.png`, `P2-A-102_RevB.png` (Rev B kept); Rev A previews kept.

## 2026-10-04 additions (4:55 AM CT session, D-035 Level 2 loop, Rev D block plans, P2-G-003 Rev F)
- **New Phase 2 sheets** `phase2/out/{pdf,dxf}/P2-A-101_RevD` (Level 1) and `P2-A-102_RevD` (Level 2), from `phase2/src/p2_a_plan.py --sheet P2-A-101|P2-A-102` (`--rev D` default). Revs A-C are FROZEN and unchanged.
- **New Phase 2 sheet** `phase2/out/{pdf,dxf}/P2-G-003_RevF` (locked program + Level 2 loop), from `phase2/src/p2_g_003.py` (`--rev F` default). Revs A-E are FROZEN and unchanged.
- **New Phase 2 data file** `params/phase2_plan_rev_d.yaml` (Rev D geometry: loop, NE stair tower, moved stairs / elevator, trimmed S&C + cross-training; ASSUMED). `phase2_plan_rev_c.yaml` stays as the frozen Rev C geometry.
- **New research** `research/R-017-indoor-running-track-and-guards.md`.
- **Previews (box only):** `/workspace/keystone_previews/P2-G-003.png` + `.pdf` (now Rev F), `P2-G-003_RevE.png` (Rev E kept); `P2-A-101.png` + `.pdf`, `P2-A-102.png` + `.pdf` (now Rev D), `P2-A-101_RevC.png`, `P2-A-102_RevC.png` (Rev C kept).

## 2026-10-04 additions (5:27 AM CT session, Phase 2 Schematic Set Rev A freeze, R-018 egress, P2-A-201 Rev A)
- **New set bundle** `phase2/out/pdf/Phase2_Schematic_Set_RevA.pdf` (3 pages, 17 x 11 in: P2-G-003 Rev F, P2-A-101 Rev D, P2-A-102 Rev D; FROZEN) from new `phase2/src/p2_set.py`.
- **Re-issued (label-only)** `phase2/out/{pdf,dxf}/P2-A-101_RevD` with the FLEX labels (D-039); `params/phase2_plan_rev_d.yaml` labels updated.
- **New Phase 2 sheet** `phase2/out/{pdf,dxf}/P2-A-201_RevA` (exterior elevations: south primary with the portal, north / east / west schematic), from new `phase2/src/p2_a_201.py`; new data file `params/phase2_elev.yaml` (heights, portal, finishes; every group sourced, ASSUMED where marked).
- **New research** `research/R-018-level-2-egress-assembly.md`, `research/R-019-arena-clear-height.md`. IBC 2021 Ch. 10 text copy kept box-only (`/workspace/research_src/ibc2021_ch10_upcodes_full.txt`, not committed).
- **Look references used (box only, not committed):** `/workspace/trojan-horse-arena/PROJECT-BRIEF.md`, `assets/arch_src.png` (portal proportions, colors); `assets/logo_hghs_rgba.png` reviewed but NOT used (D-040).
- **Previews (box only):** `/workspace/keystone_previews/P2-A-201.png` + `.pdf`, `Phase2_Schematic_Set_RevA.pdf`; `P2-A-101.png` + `.pdf` (Rev D with FLEX labels).

## 2026-10-04 additions (~6:10 AM CT session, P1-T-008 plumbing scope)
- **New Phase 1 sheet** `phase1/out/{pdf,dxf}/P1-P-001_RevA` (plumbing / water restore scope narrative, 11x17 landscape, NTS), from new `phase1/src/p1_p_001.py`. Params: `existing.plumbing` structured inventory/scope/asks/licensed_trade + `sheets.P1-P-001`. Scope narrative only — no pipe sizing / no design. Cross-refs frozen P1-G-001 Rev D + P1-A-101 Rev A (`Phase1_Package_for_Dr_Headen`).
- **Preview (box only):** `/workspace/keystone_previews/P1-P-001.png`.

## 2026-10-04 additions (6:16 / 6:22 AM CT session, official mark, freestanding portal, P2-A-201 Rev B)
- **New brand files** (`blueprints/brand/`), Shane's chat attachments 6:16 AM CT = copies of `Desktop\ARENA\THA_logo_*.svg` on his PC; colour identified by the `fill` of the single path; identical geometry; official mark per D-041:

| File | Fill | sha256 |
|---|---|---|
| `brand/THA_logo_black.svg` | #1A1A1A | `81d190a7d3f9f95072ce683fa216d7c94a93202f9e7d77f8e41255cd67e6487f` |
| `brand/THA_logo_red.svg` | #CC0000 | `ae2423c926759bc07babfaef70b2154fb73be7a09222250de45687104741ed16` |
| `brand/THA_logo_white.svg` | #FFFFFF | `b6a8fea9a77b0e7d3d9a6cde903e0f5daa9e9f690e63ed5ca385aeb387b50510` |

- Not committed: Shane's JPG preview (black mark on a transparency checker, 2256 x 1888, sha256 `452cbfde78659d0dbed0a75ba7c9b553d9c1884c664992064f6f03eaf06ddd81`, box attachment only) and the `THA_logo_*.png` files on his PC (not on the box). Logo Concepts 01 / 02: SUPERSEDED by D-041, kept as history; not located in the repo or on the box.
- **New reference** `references/portal_freestanding_champion_walk_ref.png` (Shane 6:22 AM CT: freestanding limestone arch, crimson soffit, paved promenade, low walls / planters; 1024 x 576 PNG; sha256 `93ae1c778c192c3db4af6a21463264571d8e39402b64d5c71a8b80eedadd7570`). Look reference only (D-043).
- **New Phase 2 sheet** `phase2/out/{pdf,dxf}/P2-A-201_RevB` (exterior elevations with the official mark, freestanding portal, Champion Walk, key plan, brand detail) from `phase2/src/p2_a_201.py --rev B` (default); Rev A FROZEN and unchanged. New data file `params/phase2_elev_rev_b.yaml` (Rev B overlay; `phase2_elev.yaml` stays the frozen Rev A input).
- **Previews (box only):** `/workspace/keystone_previews/P2-A-201.png` + `.pdf` (now Rev B), `P2-A-201_RevA.png` (Rev A kept).

## 2026-10-04 additions (6:45 AM CT session, P2-A-201 Rev B frozen, Rev C, P2-A-301 Rev A)
- **Reference photo removed from the repo — held off-repo pending rights confirmation from Shane (D-048 OPEN).** `references/portal_freestanding_champion_walk_ref.png` was deleted with `git rm` (history NOT rewritten: the file is still in earlier commits of this public repo). Box copy: `/workspace/keystone_previews/refs/portal_freestanding_champion_walk_ref.png` (1024 x 576 PNG, sha256 `93ae1c778c192c3db4af6a21463264571d8e39402b64d5c71a8b80eedadd7570`, same file). AI-made → restore; from the internet → stays off-repo. The `references/` folder no longer exists in the branch.
- **New data files:** `params/phase2_elev_rev_c.yaml` (P2-A-201 Rev C overlay: 11 ft badge, portal 56 ft ASSUMED, wordmark 27 in caps, Champion Walk 28 x 30 ft + brick tiers, crimson underside + gold trim, layout keys); `params/phase2_sect.yaml` (P2-A-301 cuts, telescopic / fixed tier section geometry, guards, stair; each value CITED or ASSUMED).
- **New / updated sheets:** `phase2/out/{pdf,dxf}/P2-A-201_RevC` (from `phase2/src/p2_a_201.py --rev C`, default); `phase2/out/{pdf,dxf}/P2-A-301_RevA` building sections (new `phase2/src/p2_a_301.py`). P2-A-201 Rev B now FROZEN (regenerates byte-identical).
- **Source used for the tier section:** Hussey Seating MAXAM brochure Dimensional Data (box copy `/workspace/research_src/hussey_maxam.pdf`, retrieved 2026-10-03, R-008 S4): rises 9-5/8 / 11-5/8 / 16 in; 6 rows at 11-5/8 in overall seat height 6'-3 1/8"; 6 rows closed 3'-6"; 6 rows open at 24 in spacing 11'-3".
- **Previews (box only):** `/workspace/keystone_previews/P2-A-201.png` + `.pdf` (now Rev C), `P2-A-201_RevB.png` (frozen Rev B kept), `P2-A-201_RevA.png`; `P2-A-301.png` + `.pdf`.

## 2026-10-04 additions (7:24 AM CT session, D-048 closed, P2-A-201 Rev D, P2-A-301 Rev B, P2-A-302 Rev A)
- **Arch reference photo** `portal_freestanding_champion_walk_ref.png` (sha256 `93ae1c778c192c3db4af6a21463264571d8e39402b64d5c71a8b80eedadd7570`): **Shane's own image; held off-repo by choice** (D-048 CLOSED 7:24 AM CT — Shane made it himself, rights clear; the 6:45 AM CT `git rm` stands, history not rewritten). Box copy unchanged: `/workspace/keystone_previews/refs/portal_freestanding_champion_walk_ref.png`.
- **Shane's brick vendor cost sheet** (chat attachment 7:24 AM CT, PDF "Champion_Walk_Brick_Pricing", 1 page, Google Sheets export; vendor prices 2026 incl. engraving + shipping, pulled 2026-10-04): NOT committed. Box-only copy `/workspace/research_src/Champion_Walk_Brick_Pricing_Shane_2026-10-04.pdf`, sha256 `13fcc39c5fc6d5b3014798b7ba1b8296198e6404dfa39826ecf4ad1a89dd1179`. Values used in `phase2.yaml approach.champion_walk.vendor_cost` and D-044 (not re-verified by KEYSTONE).
- **New data files:** `params/phase2_elev_rev_d.yaml` (P2-A-201 Rev D overlay: portal 50 ft, crown 34 / springline 22.1 ft semi-elliptical, badge 34.4-45.4 ft, wordmark baseline 46.1 ft); `params/phase2_sightlines.yaml` (C-value method, eye heights, targets, focal point, cases, Hussey recess data — each sourced). `params/phase2_sect.yaml` gains a `rev_b` block (70 in mid landing, stair footprint, D-049 under-tier rule).
- **New / updated sheets:** `phase2/out/{pdf,dxf}/P2-A-201_RevD` (`p2_a_201.py --rev D`, default; Rev C FROZEN, byte-identical); `phase2/out/{pdf,dxf}/P2-A-301_RevB` (`p2_a_301.py --rev B`, default; Rev A FROZEN, byte-identical); `phase2/out/{pdf,dxf}/P2-A-302_RevA` sight-line study (new `phase2/src/p2_a_302.py`).
- **New research:** `research/R-020-sight-lines.md` (sources: Starena / Green Guide reprint, Parametric Monkey, FIFA Stadium Guidelines 2.3, CEN/TR 15913 iTeh preview, DIN EN 13200-1 summary, Hussey MAXAM, IBC 2021 — retrieved 2026-10-04). R-018.9 addendum (egress worst case).
- **Previews (box only):** `/workspace/keystone_previews/P2-A-201.png` + `.pdf` (now Rev D), `P2-A-201_RevC.png` (frozen Rev C kept); `P2-A-301.png` + `.pdf` (now Rev B), `P2-A-301_RevA.png` (frozen Rev A kept); `P2-A-302.png` + `.pdf`.

## 2026-10-04 additions (7:44 / 7:49 AM CT session, D-052 + D-053 decided, R-006 / R-007, P2-C-101 Rev A)
- **New data file:** `params/phase2_site.yaml` (campus diagram inputs: frozen Rev D outline, east shift 6 ft (D-053), stair growth 76 in (D-052), portal + 28 x 30 ft Champion Walk, south bus drop loop offset east, service drive + apron at north door S1, assumed road, fire access note, `footprint_check`). All site-level geometry is DIAGRAM ONLY (site TBD, D-006); nothing is surveyed.
- **New sheet:** `phase2/out/{pdf,dxf}/P2-C-101_RevA` — site plan / campus diagram (new `phase2/src/p2_c_101.py`), 17 x 11, 1 in = 60 ft. PDF sha256 `111c4938eb81761caf15e2ce105d9f5727a033a8d5e99d80b82c1c66827e43bc`.
- **New research:** `research/R-006-code-edition-and-ahj.md` (Madison County Inspection Department, county code adoption page, Alabama State Fire Marshal / ADECA, DCM State Building Code, Alabama architect licensing law — retrieved 2026-10-04); `research/R-007-occupancy-and-occupant-load.md` (IBC 2021 chapters 3 and 10, UpCodes / ICC digital codes — retrieved 2026-10-04).
- **Previews (box only):** `/workspace/keystone_previews/P2-C-101.png` + `.pdf`.

## 2026-10-04 additions (8:36 AM CT session, D-056 / D-057, R-021)
- **New note:** `research/R-021-area-reconciliation.md` (program vs drawn area, L1 / L2 / TOTAL GSF table per D-057). Copy at `C:\Users\Hubby\Desktop\ARENA\_KEYSTONE\R-021-area-reconciliation.md` (saved first).
- **ARENA backup status (read-only check, 8:45 AM CT):** Desktop = `C:\Users\Hubby\Desktop` (not redirected to OneDrive); OneDrive (personal) configured but not running; File History not configured (service stopped); Google Drive for desktop running, but ARENA is not in My Drive and not in `Other computers\My Laptop\Desktop` (that backup's newest item is Jan 2026); no Dropbox; Windows Backup / restore points need admin (not verified). **No backup of ARENA found.** ARENA-only files (not in the repo): `KEYSTONE_ARCHITECT_PROMPT.md`, `KEYSTONE_INTAKE_2026-10-03.md`, `keystone_status.sh`, `arenav1-floor-plan.png`, `Phase2-floor-plan-flat.png`, `Phase2-floor-plan.jpeg`, `wrestle-room-measure.png`, `THA_grand_entrance_stand_alone_structure_champions_walk.png`, `trojan_horse_logo_Gemini_Generated.jpg`, `Champion_Walk_Brick_Pricing - Vendor Prices.pdf`; `P2-A-101.pdf` (only in git history, commit 900c1da); `north_alabama_3d_diorama.html` (content in repo as `hazel-green-complex-3d.html`, line endings differ). KEYSTONE box copies of all of these exist (`/workspace/arena_src/`, `/workspace/research_src/`, `/workspace/arena_c0/`, chat attachments) — a working copy, not a backup.

## 2026-10-04 additions (9:10 AM CT session, v1.3.1 errata, Plan Rev E set) + 9:35 AM CT backup
- **ARENA backup: LIVE (D-059, Shane 9:35 AM CT) — the 8:45 AM CT "no backup found" flag above is CLEARED.** `C:\Users\Hubby\Desktop\ARENA` → `shanebrain:/tank/backups/ARENA`, nightly 11:00 PM CT (pulsar Task Scheduler, scp; test run Last Result 0), ZFS snapshot 11:30 PM CT, 30-day retention; first snapshot `tank/backups@first` verified by Shane. **bullfrog RETIRED; tank lives on the shanebrain Pi.** Search for "bullfrog" (9:40 AM CT, read-only): no hits in the repo, in `ARENA\_KEYSTONE` or in any text file under ARENA → nothing to update, no protected file affected.
- **Errata (new file, accepted D-058):** `ARENA\_KEYSTONE\KEYSTONE_PROMPT_v1.3.1_ERRATA.md` (saved first) + repo `blueprints/KEYSTONE_PROMPT_v1.3.1_ERRATA.md`, E-1..E-11 exact draft text, sha256 `c780e781…`. Shane's prompt files untouched.
- **New sheets (repo):** `phase2/out/{pdf,dxf}/P2-G-003_RevG`, `P2-A-101_RevE`, `P2-A-102_RevE`; geometry `params/phase2_plan_rev_e.yaml` (new); program `phase2_program.yaml` `meta_rev_g` + `rev_g`.
- **New files in the ARENA root (CopyFromBox, checked absent first; naming `<sheet>_Rev<X>.pdf` ASSUMED):** `P2-G-003_RevG.pdf`, `P2-A-101_RevE.pdf`, `P2-A-102_RevE.pdf`. Existing plain-named `P2-A-101.pdf`, `P2-A-102.pdf`, `P2-G-003.pdf` (= Rev D / Rev D / Rev F) not touched.
- **Previews (box only):** `/workspace/keystone_previews/P2-G-003.png/.pdf`, `P2-A-101.png/.pdf`, `P2-A-102.png/.pdf` (Rev G / Rev E).
- **C-4 check:** ARENA `P2-A-201.pdf` = repo P2-A-201 Rev D byte-identical (sha256 `945745df…`); its heights note already says "the highest aisle is the loop at 15'", same as P2-A-301 Rev A / B → no A-201 Rev E needed for C-4.

## 2026-10-04 additions (9:47 AM CT session, set coordinated with Plan Rev E)
- **New data:** `params/phase2_elev_rev_e.yaml` (A-201 Rev E overlay, `plan_file` = Plan Rev E, arena volume override); `phase2_sect.yaml` `rev_c`; `phase2_sightlines.yaml` `rev_b`; `phase2_site.yaml` `rev_b`; `phase2.yaml` sheet entries A-201 E, A-301 C, A-302 B, C-101 B (A-201 D, A-301 B, A-302 A, C-101 A now frozen).
- **New sheets (repo):** `phase2/out/{pdf,dxf}/P2-A-201_RevE` (PDF sha256 `f3b53df3a21215f5…`), `P2-A-301_RevC` (`c83f405a22782a19…`), `P2-A-302_RevB` (`1acc663014bdd774…`), `P2-C-101_RevB` (`ec0b8e1803cf66f9…`).
- **New research:** `research/R-022-exit-paths-under-low-band.md` (arithmetic from Plan Rev E + p2_testfit / p2_a_302; IBC 2021 1003.2, 1011, 1030). Copy at `ARENA\_KEYSTONE\R-022-exit-paths-under-low-band.md`.
- **New files in the ARENA root (CopyFromBox, checked absent first; naming `<sheet>_Rev<X>.pdf` ASSUMED):** `P2-A-201_RevE.pdf`, `P2-A-301_RevC.pdf`, `P2-A-302_RevB.pdf`, `P2-C-101_RevB.pdf`. Plain-named files untouched.
- **Previews (box only):** `/workspace/keystone_previews/P2-A-201.png/.pdf` (Rev E), `P2-A-301.png/.pdf` (Rev C), `P2-A-302.png/.pdf` (Rev B), `P2-C-101.png/.pdf` (Rev B).

## 2026-10-04 additions (10:03 AM CT session, reviewer C-5..C-11 without D-061)
- **New data:** `params/phase2_elev_rev_f.yaml` (A-201 Rev F overlay: REFERENCE label, `se_callout`, `notes_override.not_shown` / `open_question`, `layout.notes_dy`); `phase1.yaml` `sheets.P1-G-001.revisions.E` (`code_edition_suffix`, `code_edition_note`, `hide_phase2_size`); `phase2_program.yaml` `meta_rev_h`; `phase2.yaml` sheet entries A-201 F, G-003 H (A-201 E, G-003 G now frozen; P1-G-001 D frozen as approved).
- **New sheets (repo):** `phase2/out/{pdf,dxf}/P2-A-201_RevF` (PDF sha256 `0815ca977f8152a4…`), `phase2/out/{pdf,dxf}/P2-G-003_RevH` (`2048bf828bec355e…`), `phase1/out/{pdf,dxf}/P1-G-001_RevE_principal` (`c9255d7769f05dfe…`).
- **New tools:** `shared/status_writer.py` (C-10); `shared/keystone_status.sh` (byte-identical copy of `ARENA\keystone_status.sh`, sha256 `47ecb0637f26ae4a…`; ShaneBrain preflight bridge, `C:\Users\Hubby\shanebrain-core\scripts\preflight.sh` exists on Pulsar00100 — not read or edited).
- **New files in the ARENA root (CopyFromBox, checked absent first; naming `<sheet>_Rev<X>.pdf` ASSUMED):** `P2-A-201_RevF.pdf`, `P2-G-003_RevH.pdf`, `P1-G-001_RevE.pdf`. Plain-named files untouched.
- **Previews (box only):** `/workspace/keystone_previews/P2-A-201.png/.pdf` (Rev F), `P2-G-003.png/.pdf` (Rev H), `P1-G-001.png/.pdf` (Rev E).

## 2026-10-04 additions (10:17 AM CT session, R-023 brick budget)
- **New research:** `research/R-023-champion-walk-brick-budget.md`, also at `ARENA\_KEYSTONE\R-023-champion-walk-brick-budget.md` (saved there first). Inputs: Shane's vendor price sheet (ARENA #28 `Champion_Walk_Brick_Pricing - Vendor Prices.pdf`, sha256 `13fcc39c…`, not committed) and HomeGuide brick walkway cost page (https://homeguide.com/costs/brick-walkway-cost, retrieved 2026-10-04, REFERENCE LOW).

## 2026-10-04 additions (10:27 AM CT session, D-061 Option B + approvals)
- **New data:** `params/phase2_plan_rev_f.yaml` (Plan Rev F: stairs 12.67 x 24.08, NE tower 24.08 x 6.67, event lockers to the tier lines = 3,600 SF, upper tier 21 in / front row 9.0 / L2 17.75). `params/phase2_elev_rev_g.yaml` (A-201 Rev G overlay: heights_override, datum_labels, tower label, raised labels). Other params: `phase2_program.yaml` `meta_rev_i` + `rev_i`; `phase2_sect.yaml` `rev_d`; `phase2_sightlines.yaml` `rev_c`; `phase2_site.yaml` `rev_c`; `phase2.yaml` v16 (new revs; A-101 E, A-102 E, G-003 H, A-201 F, A-301 C, A-302 B, C-101 B frozen); `phase1.yaml` P1-G-001 E frozen (approved, D-062).
- **New sheets (repo, `phase2/out/{pdf,dxf}/`), with PDF sha256:**
  - `P2-A-101_RevF` (`565cc88e54287c95…`)
  - `P2-A-102_RevF` (`76cd29c440d9dac4…`)
  - `P2-G-003_RevI` (`5a36b05105aac5c2…`)
  - `P2-A-301_RevD` (`3464113d2c139d87…`)
  - `P2-A-302_RevC` (`80f2bd987c16df98…`)
  - `P2-A-201_RevG` (`c2373b643082ff58…`)
  - `P2-C-101_RevC` (`30cb2e154291d86b…`)
- **Research updated:** `research/R-022-exit-paths-under-low-band.md` §5 Decided; `research/R-023-champion-walk-brick-budget.md` APPROVED. Copies are in `ARENA\_KEYSTONE`.
- **New files in the ARENA root** (CopyFromBox, checked absent first; naming `<sheet>_Rev<X>.pdf` ASSUMED): `P2-A-101_RevF.pdf`, `P2-A-102_RevF.pdf`, `P2-G-003_RevI.pdf`, `P2-A-301_RevD.pdf`, `P2-A-302_RevC.pdf`, `P2-A-201_RevG.pdf`, `P2-C-101_RevC.pdf`. Plain-named files untouched.
- **Previews (box only):** `/workspace/keystone_previews/` P2-A-101, P2-A-102 (Rev F), P2-G-003 (Rev I), P2-A-301 (Rev D), P2-A-302 (Rev C), P2-A-201 (Rev G), P2-C-101 (Rev C), each `.png` + `.pdf`.

## 2026-10-04 additions (10:48 AM CT session, C-12 + P2-G-002 Rev A)
- **Rule marks:** `wrestle-room-measure.png` rows (§0 #11, §1a) and §1c carry the C-12 / D-063 rule: the 250 / 150 / 50 / 276.85 ft labels are never dimensions. `validate.py` check 8 enforces it in params.
- **New data:** `params/phase2_code.yaml` (code analysis inputs: editions, occupancy, factors, spaces, event-floor cases, door width assumption, open items). `phase2.yaml` v17 adds sheet P2-G-002. `phase2_sect.yaml rev_d.structure_status` (1'-6" ASSUMED basis). `phase1.yaml estimate_aerial.c12_rule`.
- **New sheet (repo):** `phase2/out/{pdf,dxf}/P2-G-002_RevA` (PDF sha256 `de283046fc4d9ccf…`).
- **Research updated:** `research/R-007-occupancy-and-occupant-load.md` §R-007.3 (sections looked up this session, from the box copy `research_src/upc_ibc10.txt`).
- **New file in the ARENA root** (CopyFromBox, checked absent first; naming `<sheet>_Rev<X>.pdf` ASSUMED): `P2-G-002_RevA.pdf`.
- **Preview (box only):** `/workspace/keystone_previews/P2-G-002.png` / `.pdf`.

## 2026-10-04 additions (11:07 AM CT session, Option 1 + P2-A-101 Rev G + P2-A-111 Rev A)
- **New data:**
  - `params/phase2_plan_rev_g.yaml`: Plan Rev G, Level 1 only. Adds the E1 bank, the widened vestibule, the moved first aid room and the checkpoint conflict flag.
  - `params/phase2_life_safety.yaml`: P2-A-111 inputs (travel paths, common path, separation pairs, findings).
  - `phase2.yaml` v18.
- **New sheets (repo):**
  - `phase2/out/{pdf,dxf}/P2-A-101_RevG` (PDF sha256 `745973e0c547eabf…`). Rev F is frozen.
  - `phase2/out/{pdf,dxf}/P2-A-111_RevA` (PDF sha256 `190e8cfbb03360ca…`).
- **Research updated:** `research/R-007-occupancy-and-occupant-load.md` §R-007.4 (life safety sections, from `research_src/upc_ibc10.txt`).
- **New files in the ARENA root** (CopyFromBox, checked absent first; naming `<sheet>_Rev<X>.pdf` ASSUMED): `P2-A-101_RevG.pdf`, `P2-A-111_RevA.pdf`.
- **Previews (box only):** `/workspace/keystone_previews/P2-A-101.png` / `.pdf` (Rev G), `P2-A-111.png` / `.pdf`.

## 2026-10-04 additions (11:24 AM CT session, D-066 + P2-A-401 Rev A)
- **New data:** `params/phase2_enlarged.yaml` holds the event locker room templates N / E, the ADA 2010 rules and the common path routes. `phase2.yaml` is now v19.
- **New sheet (repo):** `phase2/out/{pdf,dxf}/P2-A-401_RevA` (PDF sha256 `e25dc447334e3373…`).
- **New research source (box only):** `research_src/ada2010_v2.txt`, the 2010 ADA Standards text from www.ada.gov (retrieved 2026-10-04). New note `research/R-024-ada-locker-rooms.md`.
- **New file in the ARENA root** (CopyFromBox, checked absent first; naming `<sheet>_Rev<X>.pdf` ASSUMED): `P2-A-401_RevA.pdf`.
- **Preview (box only):** `/workspace/keystone_previews/P2-A-401.png` / `.pdf`.

## 2026-10-04 additions (11:45 AM CT session, P2-A-103 Rev A)
- **New data:** `params/phase2_overlays.yaml` holds the wrestling clearances (NFHS, R-005), the furniture sets (ASSUMED), the court notes, the telescopic open / closed basis and the floor-case hatches and notes. `phase2.yaml` is now v20.
- **New sheet (repo):** `phase2/out/{pdf,dxf}/P2-A-103_RevA` (PDF sha256 `c2c743efd8592130…`).
- **Research:** `research/R-007-occupancy-and-occupant-load.md` §R-007.5 (sections quoted from `research_src/upc_ibc10.txt`).
- **New file in the ARENA root** (CopyFromBox, checked absent first; naming `<sheet>_Rev<X>.pdf` ASSUMED): `P2-A-103_RevA.pdf`.
- **Preview (box only):** `/workspace/keystone_previews/P2-A-103.png` / `.pdf`.

## 2026-10-04 additions (12:10 PM CT session, P2-A-901 Rev A massing)
- **New data:** `params/phase2_massing.yaml` holds the model inputs (references to the plan / elevation / site / section params), the drawn door symbol (ASSUMED), colours by finish id, the 5 view definitions and the open-item notes. `phase2.yaml` is now v21.
- **New sheet (repo):** `phase2/out/{pdf,dxf}/P2-A-901_RevA` (PDF sha256 `a0f3068b3eb344f0…`).
- **New model files (repo):** `phase2/out/3d/P2-A-901_RevA_massing.obj` (sha256 `692f1826f68a56a5…`) + `.mtl` (sha256 `ad45ca9ed684bc36…`); feet, Y-up, massing only.
- **New file in the ARENA root** (CopyFromBox, checked absent first; naming `<sheet>_Rev<X>.pdf` ASSUMED): `P2-A-901_RevA.pdf`.
- **Preview (box only):** `/workspace/keystone_previews/P2-A-901.png` / `.pdf`.

## 2026-10-04 additions (1:21 PM CT session, decisions D-054 / 064 / 065 / 066 + D-067 storage applied)
- **New data:** `params/phase2_plan_rev_h.yaml`, `phase2_code_rev_b.yaml`, `phase2_life_safety_rev_b.yaml`, `phase2_enlarged_rev_b.yaml`, `phase2_overlays_rev_b.yaml`, `phase2_massing_rev_b.yaml`; `phase2_site.yaml` rev_d; `phase2_program.yaml` rev_j. `phase2.yaml` is now v22 (A-111 A, A-401 A, A-103 A, G-002 A frozen + approved, D-068).
- **New sheets (repo, `phase2/out/{pdf,dxf}/`)** — PDF sha256 (first 16):
  - `P2-A-101_RevH` `f5779c999d5733c8`
  - `P2-A-111_RevB` `a07197bb4fc4f967`
  - `P2-G-002_RevB` `7cf8fc84ada11452`
  - `P2-G-003_RevJ` `eb4008bceb9dc5f9`
  - `P2-A-401_RevB` `9065da62c61f7be2`
  - `P2-A-103_RevB` `2ce22f72dcf88d23`
  - `P2-C-101_RevD` `abdf40208c9256f8`
  - `P2-A-901_RevB` `91e30b16546e38c3`
- **New model files (repo):** `phase2/out/3d/P2-A-901_RevB_massing.obj` (sha256 `2a33cf8382d7793c…`) + `.mtl` (sha256 `459343775539683b…`); feet, Y-up, massing only.
- **Storage sizing source (D-067):** National Public Seating 42-8 chair / table truck, 67 x 33.25 in, 42 chairs (vendor listings, retrieved 2026-10-04); stage carts ASSUMED.
- **New files in the ARENA root** (CopyFromBox, checked absent first; naming `<sheet>_Rev<X>.pdf` ASSUMED): `P2-A-101_RevH.pdf`, `P2-A-111_RevB.pdf`, `P2-G-002_RevB.pdf`, `P2-G-003_RevJ.pdf`, `P2-A-401_RevB.pdf`, `P2-A-103_RevB.pdf`, `P2-C-101_RevD.pdf`, `P2-A-901_RevB.pdf`.
- **Previews (box only):** `/workspace/keystone_previews/<sheet>.png` / `.pdf` for the 8 sheets above.
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

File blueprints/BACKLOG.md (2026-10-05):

# BACKLOG — KEYSTONE

Source: KEYSTONE_ARCHITECT_PROMPT.md v1.1, Section 15 (verbatim). Checked = done. One ticket IN PROGRESS at a time.

**PRIORITY NOTE (Shane 2026-10-03 10:45 PM CT, D-027):** Phase 2 is ACTIVE in parallel with Phase 1. The Phase 1 package was delivered and Phase 1 waits on Dr. Headen. **When Shane brings Phase 1 data, Phase 1 tickets jump the line** (Phase 1 still outranks Phase 2 whenever its data exists). Phase 2 is Shane's build, not a school project (D-028).
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

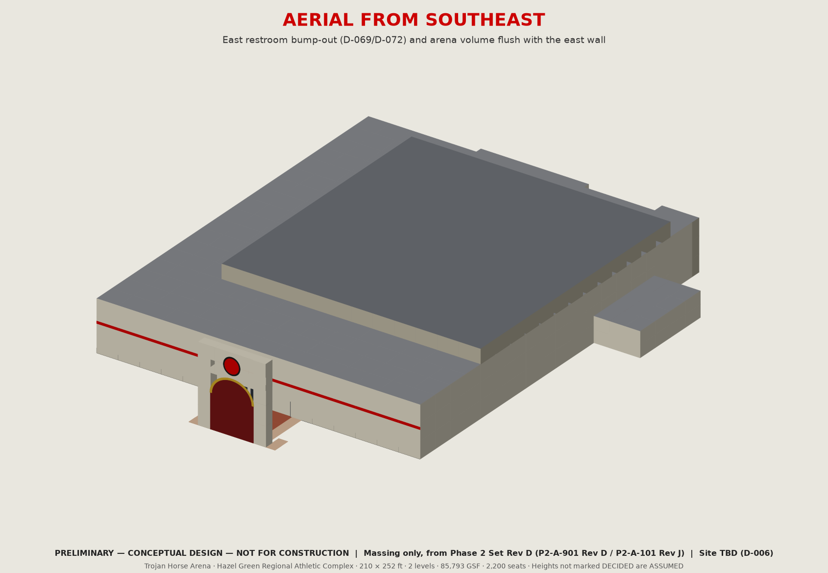
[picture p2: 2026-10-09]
concepts/render_revD_aerial_se.png

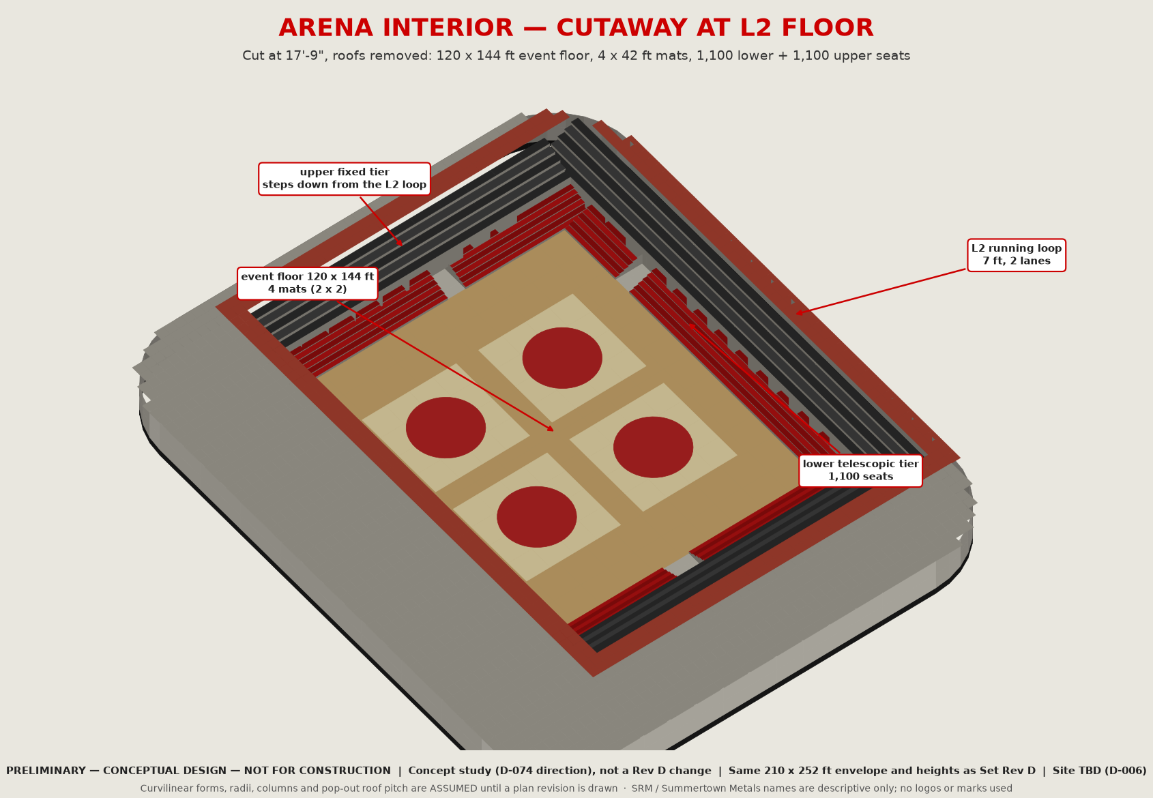
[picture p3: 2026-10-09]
concepts/render_srm_concept_interior.png

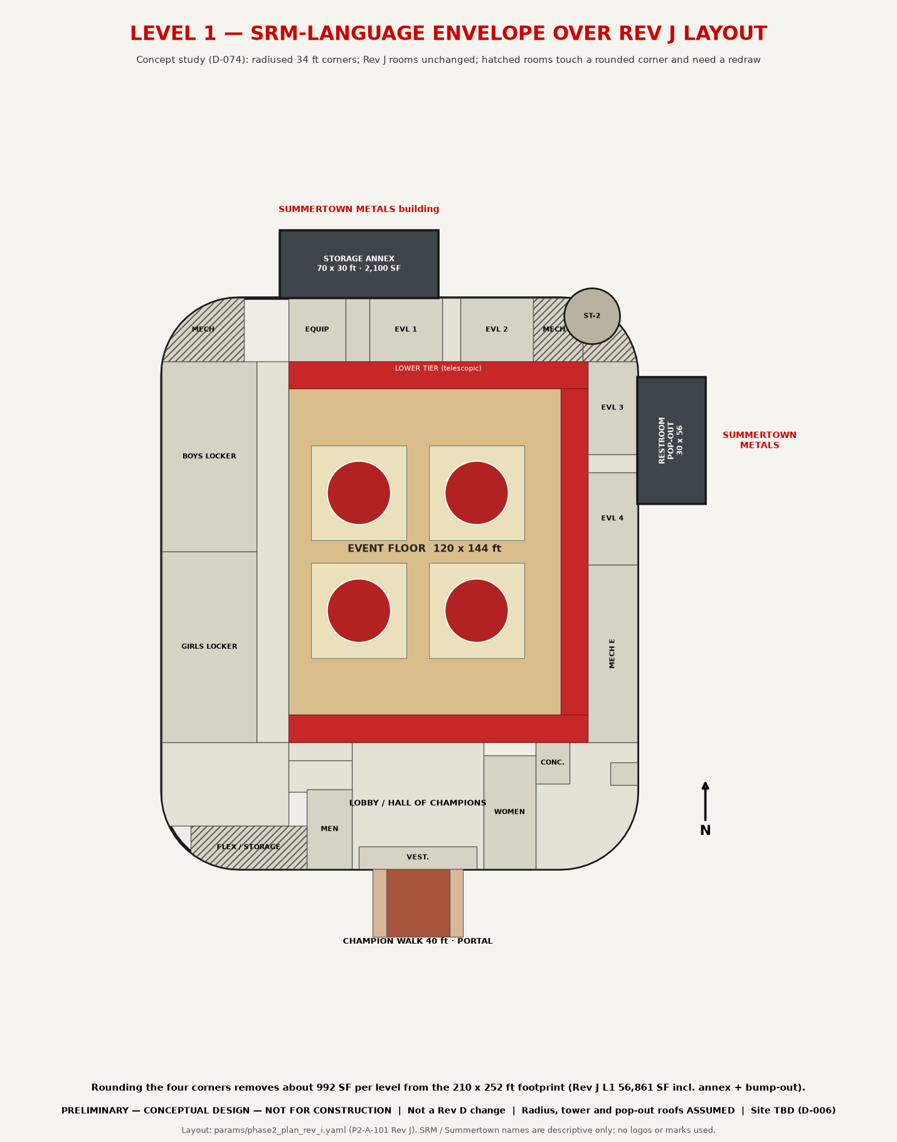
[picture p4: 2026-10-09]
concepts/render_srm_concept_plan.png

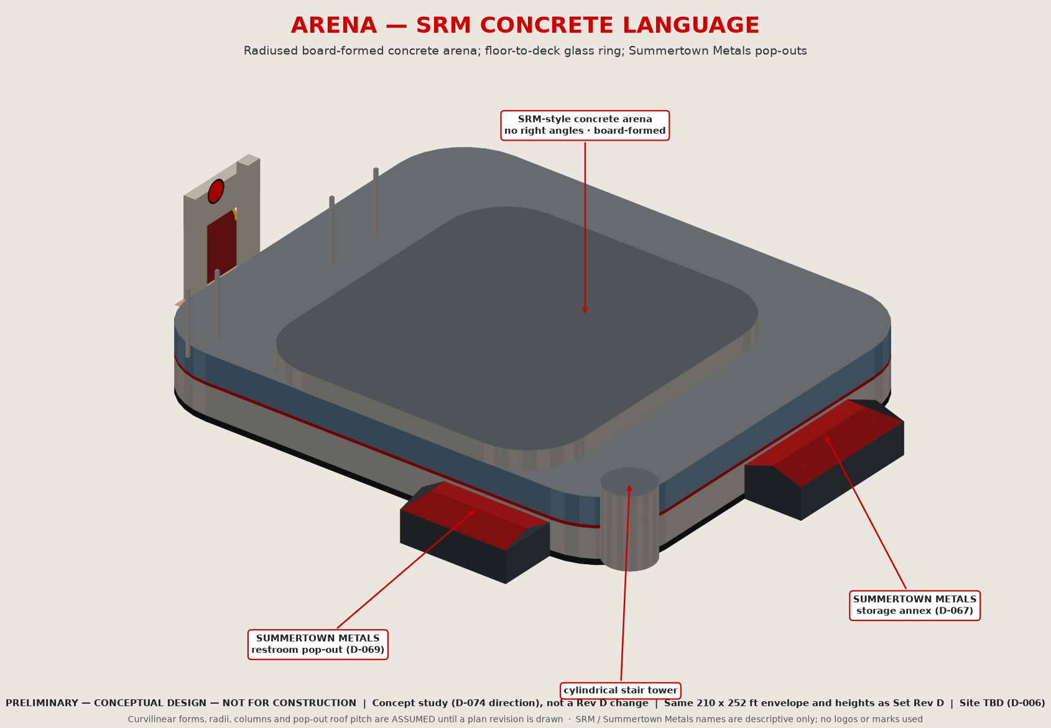
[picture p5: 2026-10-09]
concepts/render_srm_concept_aerial_ne.png

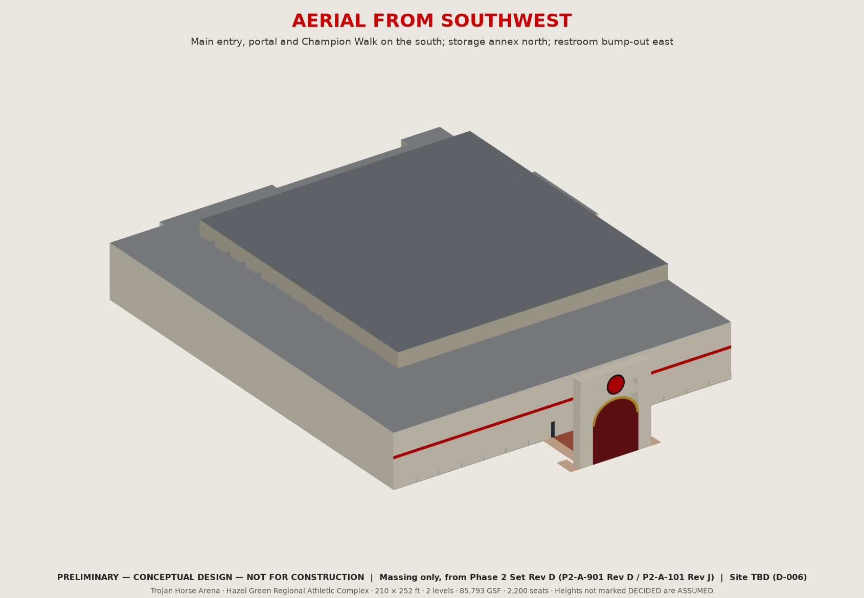
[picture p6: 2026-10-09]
concepts/render_revD_aerial_sw.png

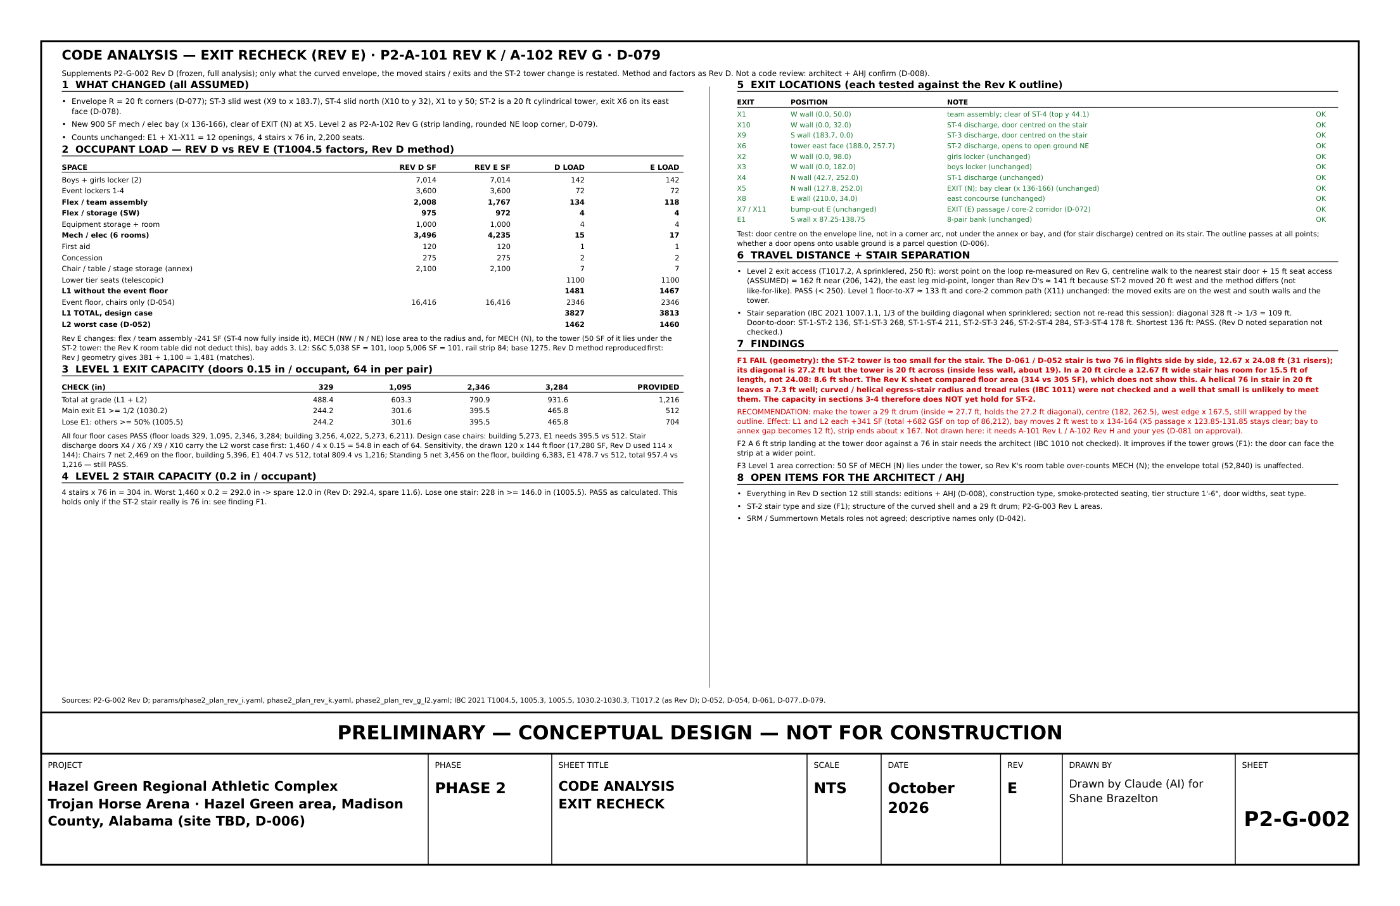
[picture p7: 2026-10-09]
concepts/P2-G-002_RevE_sheet.png

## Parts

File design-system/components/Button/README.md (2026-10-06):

The square, uppercase, monospace action button from the arena web pages, in a solid primary and an outlined ghost form.

**When to use:** one primary per view for the main action ("View on GitHub"); ghost for secondary links beside it.

**Rules**
- Primary: `brand` fill, `on-brand` text, `glow-brand` shadow, no border. On hover lift 2px and brighten.
- Ghost: transparent, 1px `border`, `ink` text; on hover border and text turn `brand`.
- Type is `arena-button` (uppercase, 0.1em tracking). Padding `space-3` by `space-8`. Radius `radius-sharp`.
- Buttons sit in a row with `space-4` between, wrapping on narrow screens.

**The consumer supplies** the label and the link target.

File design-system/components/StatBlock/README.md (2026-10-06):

A large brand-colored figure over a small muted caption, used in a centered stat bar under the hero.

**When to use:** two to four headline numbers (capacity, footprint, mats). Put them on a full-width `panel` strip with 1px `border` above and below.

**Rules**
- Figure: `arena-stat` in `brand`. Caption: `arena-label` in `ink-muted`, uppercase.
- Blocks sit in a row with 64px gaps, wrapping; 32px on narrow screens.
- Figures are facts from the Phase 1 spec: 120 x 250 ft footprint, about 800 seats, 5 mats.

**The consumer supplies** the figure and its caption.

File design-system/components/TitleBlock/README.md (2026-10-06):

The KEYSTONE drawing-sheet frame: a 1.6 pt border, a full-width PRELIMINARY stamp band, and an eight-cell title block along the bottom.

**When to use:** every PDF/DXF sheet. It is layout only; all values come from the `params/phase*.yaml` file for the sheet.

**Rules**
- Border `lw-sheet-border`, stamp band `lw-stamp-band`, cell dividers `lw-cell`, all in `ink` on `surface`. No fills, no color. `brand` is reserved for the drawing itself.
- Stamp text is exactly `PRELIMINARY — CONCEPTUAL DESIGN — NOT FOR CONSTRUCTION`, `sheet-stamp`, centered, on every sheet.
- Cells, left to right with width shares 4.7 / 1.5 / 3.1 / 0.9 / 1.45 / 0.75 / 2.1 / 1.5: PROJECT, PHASE, SHEET TITLE, SCALE, DATE, REV, DRAWN BY, SHEET. Labels `sheet-note`; values `sheet-cell`; the sheet number `sheet-number`, centered.
- Layers: `G-ANNO-TTLB` for the frame, `A-ANNO-TEXT` for text; DXF color 7 (prints black).
- Margin 0.5 in, title block 1.35 in tall, stamp band 0.5 in.

**The consumer supplies** project, phase, title, scale, date, revision, drafter and sheet number.

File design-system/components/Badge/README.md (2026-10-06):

The outlined accent badge that tags a hero or status, set in `arena-label` type.

**When to use:** once, above the hero title, to name the program or state ("ShaneBrain Ecosystem"). Not for counts or inline status.

**Rules**
- 1px `accent` border, `accent` text, transparent fill, `radius-sharp`.
- Padding 4px by 14px (source: 0.25rem by 0.9rem). Uppercase with 0.2em tracking.
- The only animation in the system: a 2s pulse of `glow-accent` on arena. Turn it off on paper and for reduced motion.
- On paper the accent is a gold fill that fails text contrast: there, use a `brand` outline and `brand` text instead.

**The consumer supplies** the label text.

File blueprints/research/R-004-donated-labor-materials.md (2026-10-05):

# R-004 — Donated labor and materials on Alabama public school property: bid law, licensing, insurance (Phase 1)

Researched by KEYSTONE 2026-10-03 for P1-T-009. All sources retrieved 2026-10-03.
Status: research note. **Not legal, procurement, or insurance advice.** It reports what the cited sources say and does not decide how they apply to this project. The district and its counsel decide. **PRELIMINARY — CONCEPTUAL DESIGN — NOT FOR CONSTRUCTION.**
Format follows prompt §10. Four sub-questions. Gaps and conflicts are at the end.

---

## R-004.1 — Bid law thresholds for school work in Alabama

QUESTION: Above what dollar amounts must a county board of education competitively bid construction work, and other purchases?

ANSWER (one paragraph): **Construction ("public works"): sealed bids above $100,000. Other purchases by a school board (Title 16 competitive bid law): $40,000 or more.**
- Ala. Code §39-2-2(a)(1): "Before entering into any contract for a public works involving an amount in excess of one hundred thousand dollars ($100,000), the awarding authority shall advertise for sealed bids."
- §39-2-2(b)(1): contracts of $100,000 or less may be let "with or without advertising or sealed bids."
- §39-2-2(a)(5): a project over $100,000 may not "be split into parts" to avoid bidding.
- "Public works" (§39-2-1(6), as quoted by DCM) means work on public property "to be paid, in whole or in part, with public funds."
- 2026 change: the enrolled text of 2026 SB196 amends §39-2-2, keeps the $100,000 threshold, and says "This act shall become effective on June 1, 2026."
- DCM adds its own rule for projects in its jurisdiction (which includes K-12 schools): for public works of $100,000 or less, DCM "requires solicitation of at least three bids," documented.
- Non-construction purchases by city and county boards of education fall under Ala. Code §16-13B-1. The threshold is **$40,000** "per Act 2023-203," according to the Alabama Department of Examiners of Public Accounts (Feb 2025 manual).
- The same manual lists an AG opinion: purchases by individual schools of money raised at "athletic events, snack bars, and other non-tax sources need not comply with the Competitive Bid Law" (AG 81-00584).

SOURCE:
- Ala. Code §39-2-2, quoted on DCM's "Public Works Projects Costing $100,000.00 or Less" — https://dcm.alabama.gov/forms_100K.aspx — retrieved 2026-10-03
- 2026 Regular Session SB196, Enrolled (amends §39-2-2) — https://alison.legislature.state.al.us/files/pdf/SearchableInstruments/2026RS/SB196-enr.pdf — retrieved 2026-10-03
- Alabama Dept. of Examiners of Public Accounts, *Alabama Competitive Bid and Public Works Law Manual for Counties and Local Governmental Entities* (Feb 2025) — https://alison.legislature.state.al.us/files/pdf/eopa/publications/county-local-bid.pdf — retrieved 2026-10-03
- DCM Memo "Title 39 public works updates, Act 2023-497" (informal bid threshold raised from $50,000 to $100,000, §39-1-1(e)) — https://dcm.alabama.gov/PDF/bulletins/02-01-24_Memo_Public_Works_updates_ACT_2023-497.pdf — retrieved 2026-10-03 (search-result excerpt; full memo not read)

EDITION / SECTION: Ala. Code §§39-2-1(6), 39-2-2(a)(1), (a)(5), (b)(1); §16-13B-1(a) (Act 2023-203). Examiners manual, Feb 2025. SB196 (2026 RS) enrolled text; **the governor's signature / act number was not confirmed.**

CONFIDENCE: HIGH on the $100,000 public-works threshold (statute text quoted by DCM, Examiners, and the 2026 enrolled bill). MEDIUM on $40,000 for §16-13B-1 (one state-agency source, Feb 2025; it may have changed since).

NEEDS ARCHITECT CONFIRMATION: NO (procurement, not design). **NEEDS DISTRICT CONFIRMATION: YES.** The district's purchasing office applies these.

---

## R-004.2 — Do donated labor or donated materials change the rules?

QUESTION: If labor or materials are donated (not paid with school money), do the bid law and state review still apply?

ANSWER (one paragraph): **The sources split the two questions. On bidding, Alabama AG opinions say work paid entirely with private funds is not "public works." On review and inspection, DCM and the district apply the same process whatever the funding.**
- AG opinions listed in the Examiners manual (Feb 2025):
  - "Works to be performed on public property … that are paid for entirely with private funds are not public works, and contracts to perform such works are not subject to the competitive bidding requirements of the Public Works Law" (AG 2004-026, City of Pelham).
  - "If the project will be paid for entirely with private funds, the project is not subject to the competitive bidding requirements of the Public Works Law" (AG 2004-223, City of Boaz).
  - "The donation of construction services to the Park and Recreation Authority is not subject to the Competitive Bid Law or the Public Works Law" (AG 2000-003, Tuscaloosa County Park and Recreation Authority).
- **None of these opinions involves a board of education**, and none was read in the original. They were read as summarized by the Examiners.
- The Alabama League of Municipalities adds its own view: "if private funds are disbursed by the city or through the city, they would become public funds." That is the League's opinion, not an AG holding.
- DCM: "fully locally-funded" K-12 projects expressly include "grants and donations," and DCM's jurisdiction covers K-12 work "regardless of funding source." Donations do not remove DCM review or inspection (see R-002.1).
- The MCSS Booster & Support Organizations Guidelines say:
  - "All projects should follow the same process regardless of funding."
  - Bid-law compliance "will be applicable in most situations depending on the funding sources."
  - A "Board employee should be in charge of the project."
- No source found addresses **volunteer (unpaid) labor** on a public school construction project in Alabama. The only volunteer-labor policy found was an ADECA CDBG housing policy (1995): volunteers supervised by a licensed contractor who carries liability insurance and workers' comp. It is a different program, noted for context only.

SOURCE:
- Examiners of Public Accounts manual (Feb 2025), Part II AG opinion lists (AG 2004-026, 2004-223, 2000-003, 81-00584) — https://alison.legislature.state.al.us/files/pdf/eopa/publications/county-local-bid.pdf — retrieved 2026-10-03
- Alabama League of Municipalities, "Public Works Bidding" (revised Jan 2026) — https://almonline.org/Assets/Files/46.%20Public-Works-Bidding_REVISED-01-2026.pdf — retrieved 2026-10-03 (secondary)
- DCM "Fully Locally-Funded Public K-12 School Projects" — https://dcm.alabama.gov/forms_publicK12.aspx — retrieved 2026-10-03
- MCSS "Booster & Support Organizations Guidelines" (2021 file date), "Self-Work Projects" — https://resources.finalsite.net/images/v1702383899/mcssk12org/t6hjd8fgrpwmbygecmpl/mcssboosterandsupportorganizationsguidelinesjuly.pdf — retrieved 2026-10-03
- ADECA CDBG Policy Letter 20, "Policy on Volunteer Labor…" (May 5, 1995) — https://adeca.alabama.gov/wp-content/uploads/Policy-Letter-20-Volunteer-labor.pdf — retrieved 2026-10-03 (search-result text; context only)

EDITION / SECTION: AG opinions as summarized by Examiners (Feb 2025). The AG opinions themselves were NOT read. MCSS guidelines (2021 file).

CONFIDENCE: MEDIUM that AG opinions treat entirely privately funded work as outside the Public Works bid law (two state-agency summaries agree). LOW on how that applies to a school board when donations pass through school accounts. HIGH that DCM review and inspection still apply to donated K-12 work.

NEEDS ARCHITECT CONFIRMATION: NO. **NEEDS DISTRICT CONFIRMATION: YES.** Whether the district accepts donated labor or materials at all, and how (D-004).

---

## R-004.3 — Licensing: general contractor, plumbing, electrical

QUESTION: What state licenses apply to the people doing the work (general contractor threshold, plumbing, electrical)?

ANSWER (one paragraph): **General contractor license: at $100,000 or more. Plumbing and electrical: a state license is required except listed exemptions (owner, owner's regular maintenance employee). The sources do not say whether volunteers fit any exemption.**
- **General contractor.** Ala. Code §34-8-1(a), as changed by Act 2024-277 (effective Oct 1, 2024), defines a general contractor as one who "for a fixed price, commission, fee, or wage" undertakes construction, alteration, maintenance, or repair "where the cost of the undertaking is one hundred thousand dollars ($100,000) or more."
  - The GC Board says the cost includes "labor and materials."
  - DCM: "A General Contractor's License is not required for contracts in amounts of less than $100,000.00."
- **Plumbing.** Ala. Code §34-37-6(a) makes it unlawful to "contract, engage in, offer to engage, or convey the impression that he or she is certified in plumbing" without a state certificate, "except as hereinafter provided." §34-37-15(a) lists work anyone may do without a certificate, still "subject to an inspection and approval." That includes:
  - (1) a person "regularly employed or acting as a maintenance person" doing work "on the premises of the employer"
  - (5) "Plumbing work performed by a property owner in or about a building owned or occupied by the owner"
  - The PGFB FAQ lists the same exemptions plus small items: lavatory fixture work that doesn't remove a stop valve; toilet filler/flapper/handle repair.
  - Note: the chapter defines "plumbing work" as work on pipes and fixtures "located on private property" (§34-37-1(12)). The sources do not explain how that applies on public school property.
- **Electrical.** Board of Electrical Contractors rule 303-X-3-.07 (eff. Feb 14, 2026) exempts, among others:
  - "(2) Electrical installation, service or repair work performed by an owner of a building on said building owned by him or her"
  - "(3) … anyone who is regularly employed as a maintenance person … on the premises of said owner"
  - "(8) The owner of any premises or any employee of any such owner"
- **This project's own rule** (prompt §2 / phase1.yaml W2): plumbing design is "BY LICENSED PLUMBER / ENGINEER OF RECORD" whatever the exemptions.

SOURCE:
- Alabama Licensing Board for General Contractors, "Changes to the … Code of Alabama" (Act 2024-277) — https://genconbd.alabama.gov/14104/changes-to-the-alabama-licensing-board-for-general-contractors-section-of-the-code-of-alabama/ — retrieved 2026-10-03; Board "Law" page — https://genconbd.alabama.gov/about/law/ — retrieved 2026-10-03 (search-result text)
- DCM "Public Works Projects Costing $100,000.00 or Less" — https://dcm.alabama.gov/forms_100K.aspx — retrieved 2026-10-03
- State of Alabama Plumbers and Gas Fitters Examining Board, law text PDF (Ch. 34-37, from 2022 signed bill) — https://pgfb.alabama.gov/wp-content/uploads/2023/01/PGFB-Law-from-Legislature-2022-draft-from-signed-bill.pdf — retrieved 2026-10-03; PGFB FAQ — https://pgfb.alabama.gov/licensees/frequently-asked-questions/ — retrieved 2026-10-03
- Alabama Administrative Code 303-X-3 (Board of Electrical Contractors, Licensing and Fees), rule 303-X-3-.07 — https://admincode.legislature.state.al.us/api/chapter/303-X-3 — retrieved 2026-10-03

EDITION / SECTION: Ala. Code §34-8-1(a) (Act 2024-277); §§34-37-1(12), 34-37-6(a), 34-37-15(a)–(b) (PGFB-hosted text, 2022); Ala. Admin. Code 303-X-3-.07 (effective 2026-02-14). The electrical statute §34-36-13 itself was not read; only the board rule was.

CONFIDENCE: HIGH on the $100,000 GC threshold. HIGH that plumbing and electrical licenses apply except listed exemptions. LOW on whether any exemption covers a school board's volunteers (no source addresses it).

NEEDS ARCHITECT CONFIRMATION: YES (architect/engineer of record and DCM inspector). **NEEDS DISTRICT CONFIRMATION: YES.**

---

## R-004.4 — Bonds and insurance

QUESTION: What do the sources say about bonds and insurance for small school projects or owner-run/volunteer work?

ANSWER (one paragraph): **Bonds: not required under $100,000. Insurance: DCM tells owners who self-perform to check with their carrier. No MCSS insurance or volunteer rule was found.**
- DCM: "Performance & Payment Bonds are not required for contracts in amounts of less than $100,000.00. §39-1-1(e)." Also: "Bid Bonds are not required for contracts in amounts of less than $100,000.00" (DCM Manual Ch. 6.D.2).
- DCM self-performance page: "Owners must consult their insurance carrier and verify the insurance carried is adequate for the proposed project to cover all parties."
- When there is a construction contract, DCM's General Conditions (Form C-8, Article 37) set the contractor's insurance requirements. That article was **not read**.
- MCSS guidelines mention insurance only as an operating cost of new structures. An MCSS policy on volunteers or contractor insurance was not found (the board policy manual did not load).

SOURCE:
- DCM "Public Works Projects Costing $100,000.00 or Less" — https://dcm.alabama.gov/forms_100K.aspx — retrieved 2026-10-03
- DCM "Construction Self-Performance Projects" — https://dcm.alabama.gov/forms_self-perform.aspx — retrieved 2026-10-03
- DCM "Fully Locally-Funded Public K-12 School Projects" (lists C-8 Article 37 "Instructions for Contractor's insurance co.") — https://dcm.alabama.gov/forms_publicK12.aspx — retrieved 2026-10-03

EDITION / SECTION: DCM web pages as of 2026-10-03; §39-1-1(e) as cited by DCM.

CONFIDENCE: HIGH on the bond thresholds (DCM citing statute). LOW on insurance specifics (not found).

NEEDS ARCHITECT CONFIRMATION: NO. **NEEDS DISTRICT CONFIRMATION: YES** (the district's risk management / insurance carrier).

---

## Could not verify
- The AG opinions themselves (2004-026, 2004-223, 2000-003, 81-00584). Read only as summarized by the Examiners. None involves a board of education.
- Any AG opinion or statute on **volunteer labor** on public school construction.
- Whether 2026 SB196 was signed (act number). The $100,000 threshold is the same either way.
- §16-13B-1 current text. Its $40,000 threshold comes from the Feb 2025 Examiners manual.
- The electrical statute §34-36-13 (only the board rule was read) and DCM C-8 Article 37 insurance terms.
- MCSS board policies on donations, volunteers, and insurance (Simbli did not load).
- Justia and FindLaw blocked or redirected code pages, so statute text came from state agency and board documents instead.

## Conflicts / flags
- **Bid law vs. state review:** AG opinions (as summarized) put entirely privately funded work outside the Public Works *bid* law. DCM still claims *review and inspection* of K-12 work "regardless of funding source." The MCSS guidelines apply "the same process regardless of funding." **Donated does not mean unreviewed.**
- **Plumbing scope wording:** §34-37-1(12) speaks of plumbing "located on private property." How the PGFB chapter applies on public school property was not found. Ask PGFB or the DCM inspector.
- **GC license wording:** §34-8-1(a) covers work done "for a fixed price, commission, fee, or wage." The sources do not address unpaid volunteers. Not interpreted here.

## What this means for Phase 1 (scope notes; no design decided)
- If school money pays for Phase 1 and it is $100,000 or less, the statute allows contracts without sealed bids. DCM still asks for 3 quotes on projects in its jurisdiction.
- Donated pads or labor still go through the district's process. Expect state review and inspection of the restroom and plumbing work.
- Plumbing work should be done by a licensed plumber unless the district confirms an exemption applies. This matches the scope sheet's "BY LICENSED PLUMBER / ENGINEER OF RECORD."
- The district's insurance carrier should weigh in before any volunteer work.

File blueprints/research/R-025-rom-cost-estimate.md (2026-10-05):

# R-025 — Rough-order-of-magnitude (ROM) cost estimate, Phase 2 (Trojan Horse Arena)

Written 2026-10-04 5:20 PM CT by Claude (Claude Code session covering for KEYSTONE), ARENA CLAUDE.md step 5 (Shane: "go").
**PRELIMINARY — NOT A BID, NOT A CONTRACTOR QUOTE, NOT FOR CONSTRUCTION.** A ROM at schematic design is normally good to about −25% / +50%.
Its job is to set the money conversation (land, lenders / donors, architect fee) and to be replaced by the architect's estimator.
Labels: **CITED** = from a source below · **ASSUMED** = Claude allowance, no source · **DECIDED** = Shane (D-###).

## Basis

- **Size:** 85,793 GSF drawn (L1 56,861 + L2 28,933) — P2-G-003 Rev K / P2-A-101 Rev I / A-102 Rev F, incl. storage annex and restroom bump-out (D-067, D-069, D-070). No SF cap (D-056).
- **Program:** 2,200 seats (1,100 telescopic + 1,100 fixed upper tier), 2 levels, L2 FF 17'-9", arena roof 42 ft, 4 locker suites + event lockers, chairs-only restroom count 22 / 42 WC, sprinklers + voice alarm (ASSUMED, P2-G-002).
- **Location:** unincorporated Hazel Green, Madison County (site TBD, D-006). Location factor = RSMeans Huntsville.
- **Price date:** Q2–Q3 2026 dollars. No escalation to a construction start (start unknown, needs the parcel).

## Building $/SF — how the three bands were set

| Step | Value | Source |
|---|---:|---|
| RSMeans gymnasium model, 20,000 SF, 1 storey, US national, open shop, 2019 | $173.39 / SF | S1 (CITED) |
| Escalate 2019 → 2026: Turner BCI 1552 (Q2 2026) ÷ 1149 (Q2 2019) = 1.351 | $234.20 / SF | S2, S3 (CITED) |
| Locate to Huntsville: RSMeans CCI weighted average 85.2 (national = 100) | **$199.54 / SF** | S4 (CITED; 2021 edition, latest free table) |
| Cross-check, 2026 national ranges × 0.852: school gym $190–$320 → $162–$273; field house / multi-sport $210–$425+ → $179–$362 | | S5 (CITED) |
| Cross-check, 2026 "multi-sport, spectator-grade" $275–$336 × 0.852 | $234–$286 / SF | S6 (CITED) |

The RSMeans model is a plain one-storey gym. This building costs more per SF than that: it has two levels, a long-span roof at 42 ft, a fixed upper seating tier on structure, four locker suites plus event lockers, 64+ restroom fixtures on L1, and voice alarm. So:

| Band | $/SF | Reasoning (ASSUMED, anchored on the CITED numbers above) |
|---|---:|---|
| **LOW** | **$215** | RSMeans localized $200 + ~8 % for seating tier / 2 levels; pre-engineered-style structure, plain finishes, competitive bid |
| **MID** | **$260** | Middle of the localized spectator-grade range ($234–$286, S6); conventional steel + masonry, school-grade finishes |
| **HIGH** | **$340** | Near the top of localized field-house range ($362, S5); upgraded envelope / brand finishes, tight market |

## ROM estimate (2026 dollars, Hazel Green / Huntsville market)

| Line | LOW | MID | HIGH | Basis |
|---|---:|---:|---:|---|
| **1 Building** (85,793 GSF × $/SF) | **$18,445,000** | **$22,306,000** | **$29,170,000** | $215 / $260 / $340 per SF (above) |
| 2 Spectator seating, 2,200 seats (telescopic + upper chairs) | $176,000 | $363,000 | $550,000 | $80 / $165 / $250 per seat; S7 range $80–$250 (CITED, LOW confidence) |
| 3 Event equipment / FF&E (4 × 42 ft mats, scoreboards, sound, AV, lockers' loose FF&E) | $400,000 | $750,000 | $1,500,000 | ASSUMED allowance |
| 4 **Grand Entrance Portal** (freestanding limestone, ≤ 50 ft, D-043/045/047/050) | **$566,000** | **$1,051,000** | **$1,802,000** | Stone ≈ 4,013 SF face (44 W × 50 H × 6 D ft, 28 ft semi-elliptical opening; P2-A-201 params) × $60 / $100 / $150 per SF (S8 lists $35–$100 installed for general limestone exteriors; carved full-bed monumental stone runs higher — ASSUMED) + structure + foundation $250k / $500k / $900k (ASSUMED; **structural engineer required**, 50 ft freestanding, overturning) + badge, wordmark, lighting $75k / $150k / $300k (ASSUMED) |
| 5 **Champion Walk** (840 SF engraved brick + 6 ft paved bands; 40 ft at doors, D-046/D-066) | **$98,000** | **$131,000** | **$165,000** | Bricks $69,111 (R-023 scenario S3, vendor avg, APPROVED D-062) + logo upside $0 / $10k / $20k + base & install 1,200 SF × $20 / $35 / $50 (ASSUMED; R-023 lists residential labor $8–$16, LOW) + border $5k / $10k / $15k (ASSUMED) |
| 6 **Site — parking** (≈ 734 surface spaces = 1 per 3 seats, ASSUMED) | $3,303,000 | $4,147,000 | $4,991,000 | $4,500 / $5,650 / $6,800 per space complete (paving, drainage, striping, lighting) — S9 (CITED) |
| 7 **Site — development** (grading, utilities to the building, stormwater detention, bus loop + drives, landscaping, site lighting) | $922,000 | $1,784,000 | $3,500,000 | 5 % / 8 % / 12 % of line 1 (ASSUMED; depends on the parcel) |
| **Hard cost subtotal (1–7)** | **$23,911,000** | **$30,533,000** | **$41,678,000** | |
| 8 Soft costs (A/E design fees, geotech, survey, permits, testing / inspections, owner's insurance) | $1,913,000 | $3,359,000 | $5,835,000 | 8 % / 11 % / 14 % of hard cost (ASSUMED) |
| 9 Design + estimating contingency (schematic stage) | $2,582,000 | $5,084,000 | $9,502,000 | 10 % / 15 % / 20 % of hard + soft (ASSUMED) |
| **TOTAL PROJECT ROM (excl. land)** | **≈ $28.4 M** | **≈ $39.0 M** | **≈ $57.0 M** | |
| All-in $/GSF | $331 | $454 | $665 | total ÷ 85,793 |

**Say it this way:** *about $39 million all-in (mid), with a credible range of $28–57 million, not counting land. The building alone is about $18–29 million.*

Checks:
- Site share (lines 6 + 7) = 18 % (low), 19 % (mid), 20 % (high) of hard cost; S5 puts site development at 15–25 % of total project cost. The bands sit at or below the middle of that range; a hilly or wet parcel pushes up.
- Portal + Champion Walk together = 2.3–3.5 % of the total ($0.66M–$1.97M). They are not what drives the budget; the building and the parking are.

## NOT included

Land purchase (D-006) · financing / interest during construction · utility tap, impact and connection fees · off-site road, turn-lane or water / sewer extensions (parcel dependent) · escalation to the construction start (Turner BCI is up **5.15 % year over year** at Q2 2026, S3 — add roughly that per year of delay) · sales tax treatment (owner entity, D-007) · donor-program admin (D-044) · trademark work (D-042) · solar / stormwater reuse (D-018) · suites (PARKED).

## Biggest swings (in order)

1. **$/SF band** — each $10 / SF = **$858,000**.
2. **Parking count** — set by zoning / the AHJ (Madison County unincorporated) and shared-parking options. Each 100 spaces ≈ $450k–$680k.
3. **Parcel** — grading, rock, floodplain, utility distance (D-006).
4. **Market timing** — 4–5 % a year.
5. **Portal** — stone type (Indiana full-bed vs cast stone vs precast with limestone face) can swing $0.5M+.

## Sources

- **S1** RSMeans, *Gymnasium construction costs per square foot* (model page, 2019 data, US national; union $189.23, open shop $173.39 total building cost): https://www.rsmeans.com/model-pages/gymnasium — retrieved 2026-10-04.
- **S2** Turner Construction, *Turner Building Cost Index — Construction Activity Continues at High Level* (Q2 2019 = 1149): https://www.turnerconstruction.com/insights/turner-building-cost-index-construction-activity-continues-at-high-level
- **S3** ConstructionOwners.com, *Turner Building Cost Index Rises 5.15% Year Over Year in Q2 2026* (Q2 2026 = 1552): https://www.constructionowners.com/news/turner-building-cost-index-climbs-in-second-quarter-as-high-demand-sectors-sustain-construction-activity
- **S4** RSMeans, *City Cost Indexes 2021, V2* — Alabama, Huntsville weighted average MAT 96.9 / INST 69.9 / **TOTAL 85.2**: https://www.rsmeans.com/media/wysiwyg/quarterly_updates/2021-CCI-LocationFactors-V2.pdf (newer quarterly notices show small changes: Q2 2025 Huntsville +1.04 average — not applied).
- **S5** APX Construction Group, *Athletic Facility Pricing Guide 2026* (school gyms $190–$320; field houses / multi-sport $210–$425+; site development 15–25 % of total): https://apxconstructiongroup.com/athletic-facility-pricing-guide/
- **S6** Terrapin Construction Group, *Indoor Sports & Recreation Facility Construction Cost Per Square Foot (2026)* (fieldhouse full fit-out $150–$250; multi-sport tourism complex, spectator-grade $275–$336): https://terrapincg.com/news/indoor-sports-recreation-facility-construction-cost-per-square-foot-2026
- **S7** Bleacher per-seat ranges ($80–$250; telescopic $100–$160): https://brocllc.com/how-much-do-bleachers-cost-a-comprehensive-guide/ and https://www.accio.com/business/retractable-gym-bleachers-cost — vendor / marketing guides, **LOW** confidence.
- **S8** LatestCost, *Limestone Exterior Cost Per Square Foot 2026* ($35–$100 installed): https://latestcost.com/limestone-exterior-cost-per-square-foot-price/ — residential-leaning guide, **LOW** confidence for a monumental arch.
- **S9** Trutec, *Parking Lot Paving Cost Per Space: 2026 Guide* ($4,500–$6,800 per complete surface space): https://trutec.ai/blog/parking-lot-paving-cost-per-space
- **R-023** Champion Walk brick budget (vendor sheet, APPROVED D-062).
- Context, not used in the math: Moody HS (St. Clair Co., AL) is building a 25,800 SF / 1,200-seat gym inside a $47M school (cost not split out): https://www.asumag.com/planning-design/new-construction/article/21284797/47-million-high-school-under-construction-in-st-clair-county-alabama

## CONFIDENCE

- Building $/SF: **MEDIUM-LOW.** The RSMeans chain is solid, but the model building is simpler than this one, the CCI is the 2021 edition, and the 2026 ranges come from contractor guides. No local arena bid with both cost and SF was found.
- Seating, portal, FF&E, soft costs and contingency: **LOW** (allowances).
- Parking: **MEDIUM** for $/space, **LOW** for the count (zoning TBD).

## NEEDS ARCHITECT / ESTIMATOR CONFIRMATION

**YES.** Before any number goes into a loan or pledge document, get the architect of record's estimator or a North Alabama general contractor (preconstruction services) to price the schematic set (`Phase2_Schematic_Set_RevB.pdf`). The budget target itself stays with Shane (**D-012 OPEN**). Recommendation: carry **$39M (mid) as the working number** and treat $28M as what it would take if land is cheap, the site is flat and the finishes stay plain.

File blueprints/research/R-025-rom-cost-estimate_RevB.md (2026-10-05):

# R-025 Rev B — Rough-order-of-magnitude (ROM) cost estimate, Phase 2 (Trojan Horse Arena)

Written 2026-10-04 evening by Claude (Claude Code session covering for KEYSTONE), at Shane's direction (D-073). **Rev A (`R-025-rom-cost-estimate.md`) is unchanged;** this file corrects and updates it.
**PRELIMINARY — NOT A BID, NOT A CONTRACTOR QUOTE, NOT FOR CONSTRUCTION.** ROM at schematic design is normally good to about −25% / +50%.
Labels: **CITED** = from a source in Rev A's list · **ASSUMED** = Claude allowance, no source · **DECIDED** = Shane (D-###).

## Status of the number (D-073)

- **D-012 (budget target) stays OPEN.**
- Shane's instruction: carry **$39M (mid; range $28–57M; excl. land) as the WORKING planning number only.** That is Rev A's result. It is not a budget target and should not go into lender or donor documents until a GC or estimator prices Set Rev D.
- **Rev B's corrected mid is $37.3M** (range $27.1–54.7M). The working number is about $1.7M (4.6%) above it. Recommendation: **keep $39M as the working number.** Rev B still leaves out escalation (about 5% a year), any GC markup missing on lines 2–7 (up to $2.1M at mid, see Open point), and portal risk (see below). Shane's call.

## What changed from Rev A

1. **S1 check (RSMeans gymnasium model): the $173.39 already includes architect fees and contractor overhead / profit.** RSMeans page, retrieved 2026-10-04: SubTotal → + "Contractor Fees (General Conditions, Overhead, Profit)" 25% → + "Architectural Fees" 7% → "Total Building Cost." Union: $141.48 + $35.37 + $12.38 = **$189.23**. Open shop (the figure I used): $129.64 × 1.25 × 1.07 = **$173.39** (A/E = **$11.34 / SF = 6.54 % of the total**). So Rev A's line 8 counted the architect fee a second time on the building.
   **Fix:** line 8 = Rev A's rate × hard cost, **minus 6.54 % of line 1** (the A/E already inside the building $/SF). Line 8 now covers A/E on the non-building lines plus geotech, survey, permits, testing / inspections and owner's insurance. Its effective rate is 3.0 % / 6.2 % / 9.4 % of hard cost (Rev A: 8 / 11 / 14 %).
2. **Stale references updated:** Set Rev D (`Phase2_Schematic_Set_RevD.pdf`, approved + frozen D-073); A-101 Rev J (core 2 moved 42 ft south, public corridor, X11; **GSF unchanged 85,793**, program P2-G-003 Rev K); site C-101 Rev F.
3. **Parking sensitivity added** (below).
4. **Portal HIGH-case note added** (below).

## Basis (unchanged)

85,793 GSF drawn (L1 56,861 + L2 28,933; P2-A-101 Rev J / A-102 Rev F); 2,200 seats; 2 levels; Hazel Green / Huntsville market (RSMeans CCI 85.2); 2026 dollars, no escalation to a start date. Building $/SF bands are as Rev A: RSMeans model $173.39 → × 1.351 (Turner BCI 1552 / 1149) → × 0.852 (Huntsville) = $199.54 / SF, then **LOW $215 / MID $260 / HIGH $340** (ASSUMED uplift for two levels, 42 ft roof, fixed upper tier, locker suites, 64+ fixtures), cross-checked to 2026 published ranges (Rev A, S5 / S6). Because the RSMeans anchor includes A/E and GC fees, the bands do too.

## Corrected ROM estimate (2026 dollars)

| Line | LOW | MID | HIGH | Change from Rev A |
|---|---:|---:|---:|---|
| 1 Building (85,793 GSF × $215 / $260 / $340) — includes GC fees + A/E | $18,445,000 | $22,306,000 | $29,170,000 | none |
| 2 Spectator seating, 2,200 seats | $176,000 | $363,000 | $550,000 | none |
| 3 Event equipment / FF&E | $400,000 | $750,000 | $1,500,000 | none |
| 4 Grand Entrance Portal | $566,000 | $1,051,000 | $1,802,000 | none (HIGH may be higher, below) |
| 5 Champion Walk | $98,000 | $131,000 | $165,000 | none |
| 6 Parking, 734 surface spaces (1 per 3 seats, ASSUMED) | $3,303,000 | $4,147,000 | $4,991,000 | none |
| 7 Other site development (5 / 8 / 12 % of line 1) | $922,000 | $1,784,000 | $3,500,000 | none |
| **Hard cost subtotal** | **$23,911,000** | **$30,533,000** | **$41,678,000** | none |
| 8 Soft costs, **A/E share on the building removed** | $706,000 | $1,899,000 | $3,927,000 | was $1,913k / $3,359k / $5,835k (−$1,207k / −$1,459k / −$1,908k) |
| 9 Contingency (10 / 15 / 20 % of hard + soft) | $2,462,000 | $4,865,000 | $9,121,000 | was $2,582k / $5,084k / $9,502k |
| **TOTAL PROJECT ROM (excl. land)** | **≈ $27.1 M** | **≈ $37.3 M** | **≈ $54.7 M** | was $28.4 / $39.0 / $57.0 M (−$1.3 / −$1.7 / −$2.3 M) |
| All-in $/GSF | $316 | $435 | $638 | was $331 / $454 / $665 |

**Say it this way:** *about $37 million all-in (mid), range $27–55 million, not counting land; the building alone is about $18–29 million.* The working planning number stays **$39M** (D-073).

## Parking sensitivity (new)

Assumed count 734 = 1 space per 3 seats (ASSUMED; zoning / AHJ and shared-parking options decide, D-006 / D-008). Everything else as above; line 8 and 9 recomputed. $/space $4,500 / $5,650 / $6,800 (Rev A, S9).

| Parking provided on this parcel | Spaces | LOW | **MID** | HIGH | Mid vs 100 % |
|---|---:|---:|---:|---:|---:|
| 100 % | 734 | $27.08 M | **$37.30 M** | $54.73 M | — |
| 50 % | 367 | $25.12 M | **$34.65 M** | $51.31 M | −$2.65 M |
| 25 % | 184 | $24.14 M | **$33.33 M** | $49.61 M | −$3.97 M |

Notes: parking at 100 % is about 11 % of the mid total (line 6 alone = $4.15 M). Each 100 spaces ≈ $0.45–0.68 M before fees and contingency. A lower on-site count only saves money if the missing spaces are really supplied elsewhere (school or church lots, shared use, overflow grass / gravel); that cost is **not** in this table.

## Portal HIGH case (new note)

The HIGH portal figure ($1.80 M: stone ≈ 4,013 SF at $150 / SF + $0.9 M structure and foundation + $0.3 M badge, wordmark and lighting) **may be exceeded.** It is a placeholder for a freestanding, 50 ft, 44 ft wide masonry arch that the **structural engineer has not yet sized** (foundations, wind, overturning). Illustration only, not a quote: carved full-bed stone at $200 / SF, $1.5 M structure and $0.3 M badge = about $2.6 M, i.e. +$0.8 M on line 4, or about **+$1.1 M on the HIGH total** after soft costs and contingency. LOW and MID are less exposed, but have the same unknown. Stone type (Indiana full-bed, cast stone, precast with limestone face) can also swing the cost.

## Open point (flagged, not changed)

RSMeans' 25 % contractor fees are inside line 1 only. Lines 2–7 use CITED installed or complete unit costs (seats, parking per space) and ASSUMED allowances (FF&E, portal, walk, site). If none of them carried GC overhead / profit, the upper bound is 25 % of lines 2–7: about **$1.4 M / $2.1 M / $3.1 M** (LOW / MID / HIGH), partly covered by contingency. An estimator should settle this. It is one reason to keep $39M as the working number.

## NOT included (as Rev A)

Land (D-006) · financing · utility tap, impact and connection fees · off-site road or utility extensions · escalation to a start date (Turner BCI +5.15 % year over year at Q2 2026) · owner-entity sales tax (D-007) · donor-program admin (D-044) · trademark work (D-042) · solar / stormwater reuse (D-018) · suites (PARKED).

## Sources and confidence

Sources S1–S9, R-023 and the Moody HS context note are listed in Rev A and are unchanged, except that **S1 was re-read for this revision** (https://www.rsmeans.com/model-pages/gymnasium: subtotal, 25 % contractor fees, 7 % architectural fees, total).
Confidence as Rev A: building $/SF MEDIUM-LOW; seating, portal, FF&E, soft costs and contingency LOW (allowances); parking MEDIUM for $/space, LOW for the count.

## NEEDS ARCHITECT / ESTIMATOR CONFIRMATION

**YES.** Before any number goes into a loan or pledge document, have the architect of record's estimator or a North Alabama GC (preconstruction services) price `Phase2_Schematic_Set_RevD.pdf`. The budget target itself stays with Shane (**D-012 OPEN**).

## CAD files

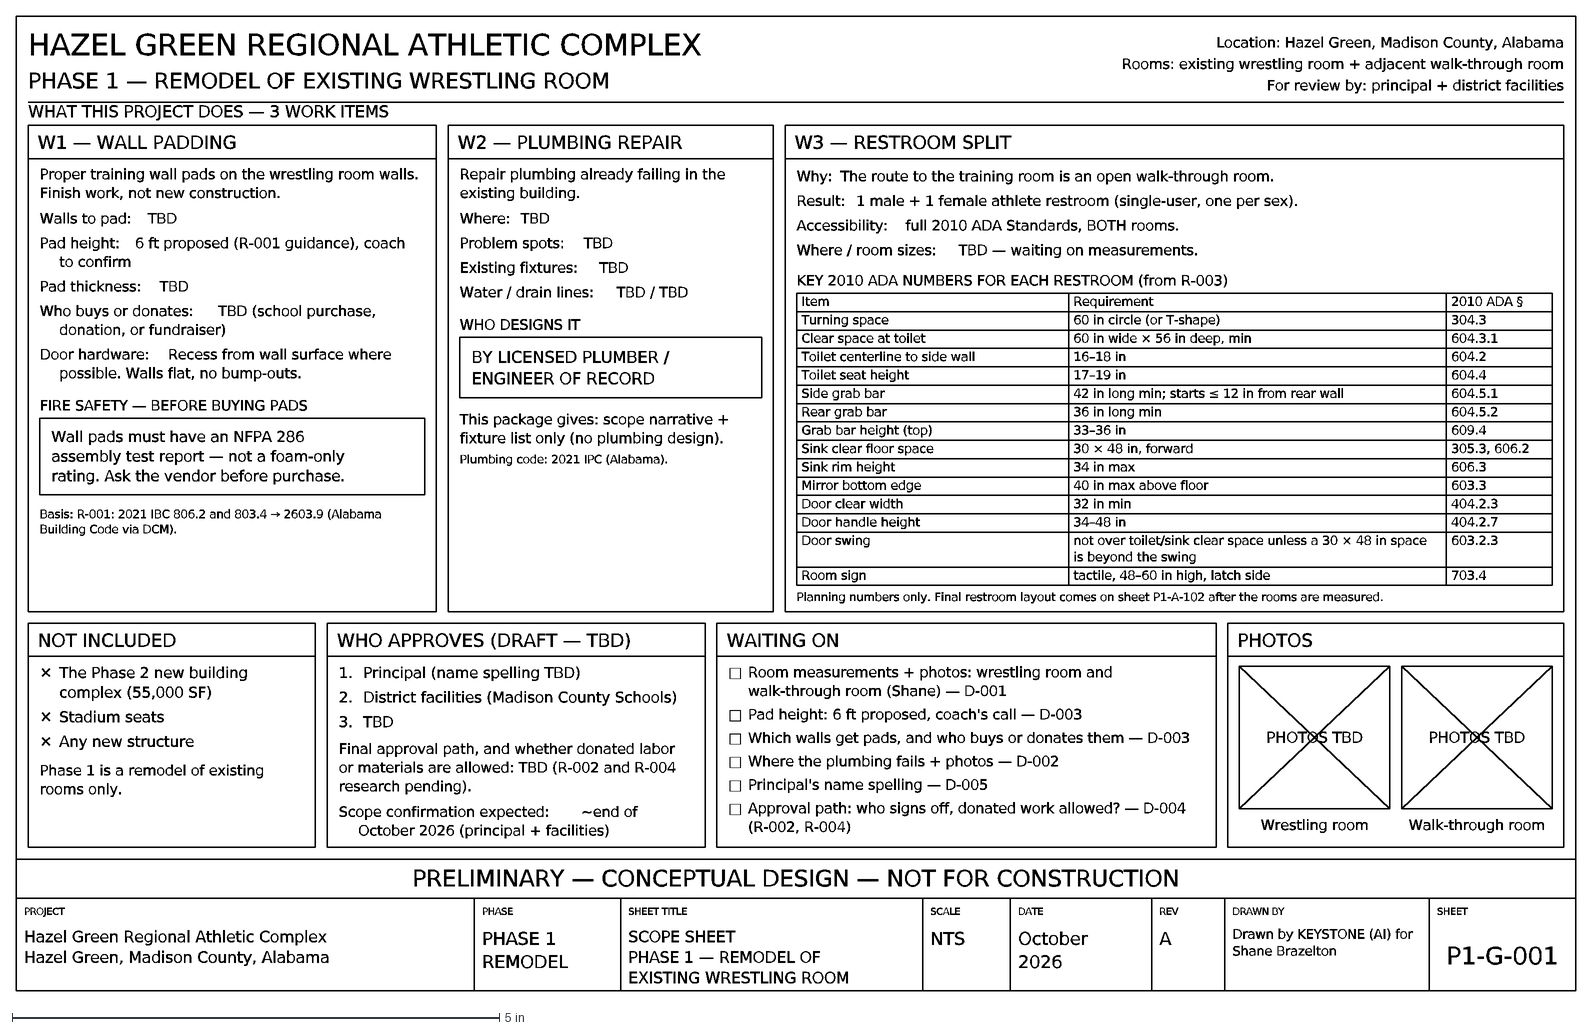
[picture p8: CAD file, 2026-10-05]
blueprints/phase1/out/dxf/P1-G-001_RevA_internal.dxf
PRELIMINARY — CONCEPTUAL DESIGN — NOT FOR CONSTRUCTION
PROJECT
Hazel Green Regional Athletic Complex
Hazel Green, Madison County, Alabama
PHASE
PHASE 1
REMODEL
SHEET TITLE
SCOPE SHEET
PHASE 1 — REMODEL OF
EXISTING WRESTLING ROOM
SCALE
NTS
DATE
October
2026
REV
A
DRAWN BY
Drawn by KEYSTONE (AI) for
Shane Brazelton
SHEET
P1-G-001
HAZEL GREEN REGIONAL ATHLETIC COMPLEX
PHASE 1 — REMODEL OF EXISTING WRESTLING ROOM
Location: Hazel Green, Madison County, Alabama
Rooms: existing wrestling room + adjacent walk-through room
For review by: principal + district facilities
WHAT THIS PROJECT DOES — 3 WORK ITEMS
W1 — WALL PADDING
Proper training wall pads on the wrestling room walls.
Finish work, not new construction.
Walls to pad:
TBD
Pad height:
6 ft proposed (R-001 guidance), coach
to confirm
Pad thickness:
Who buys or donates:
TBD (school purchase,
donation, or fundraiser)
Door hardware:
Recess from wall surface where
possible. Walls flat, no bump-outs.
FIRE SAFETY — BEFORE BUYING PADS
Wall pads must have an NFPA 286
assembly test report — not a foam-only
rating. Ask the vendor before purchase.
Basis: R-001: 2021 IBC 806.2 and 803.4 → 2603.9 (Alabama
Building Code via DCM).
W2 — PLUMBING REPAIR
Repair plumbing already failing in the
existing building.
Where:
Problem spots:
Existing fixtures:
Water / drain lines:
TBD / TBD
WHO DESIGNS IT
BY LICENSED PLUMBER /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

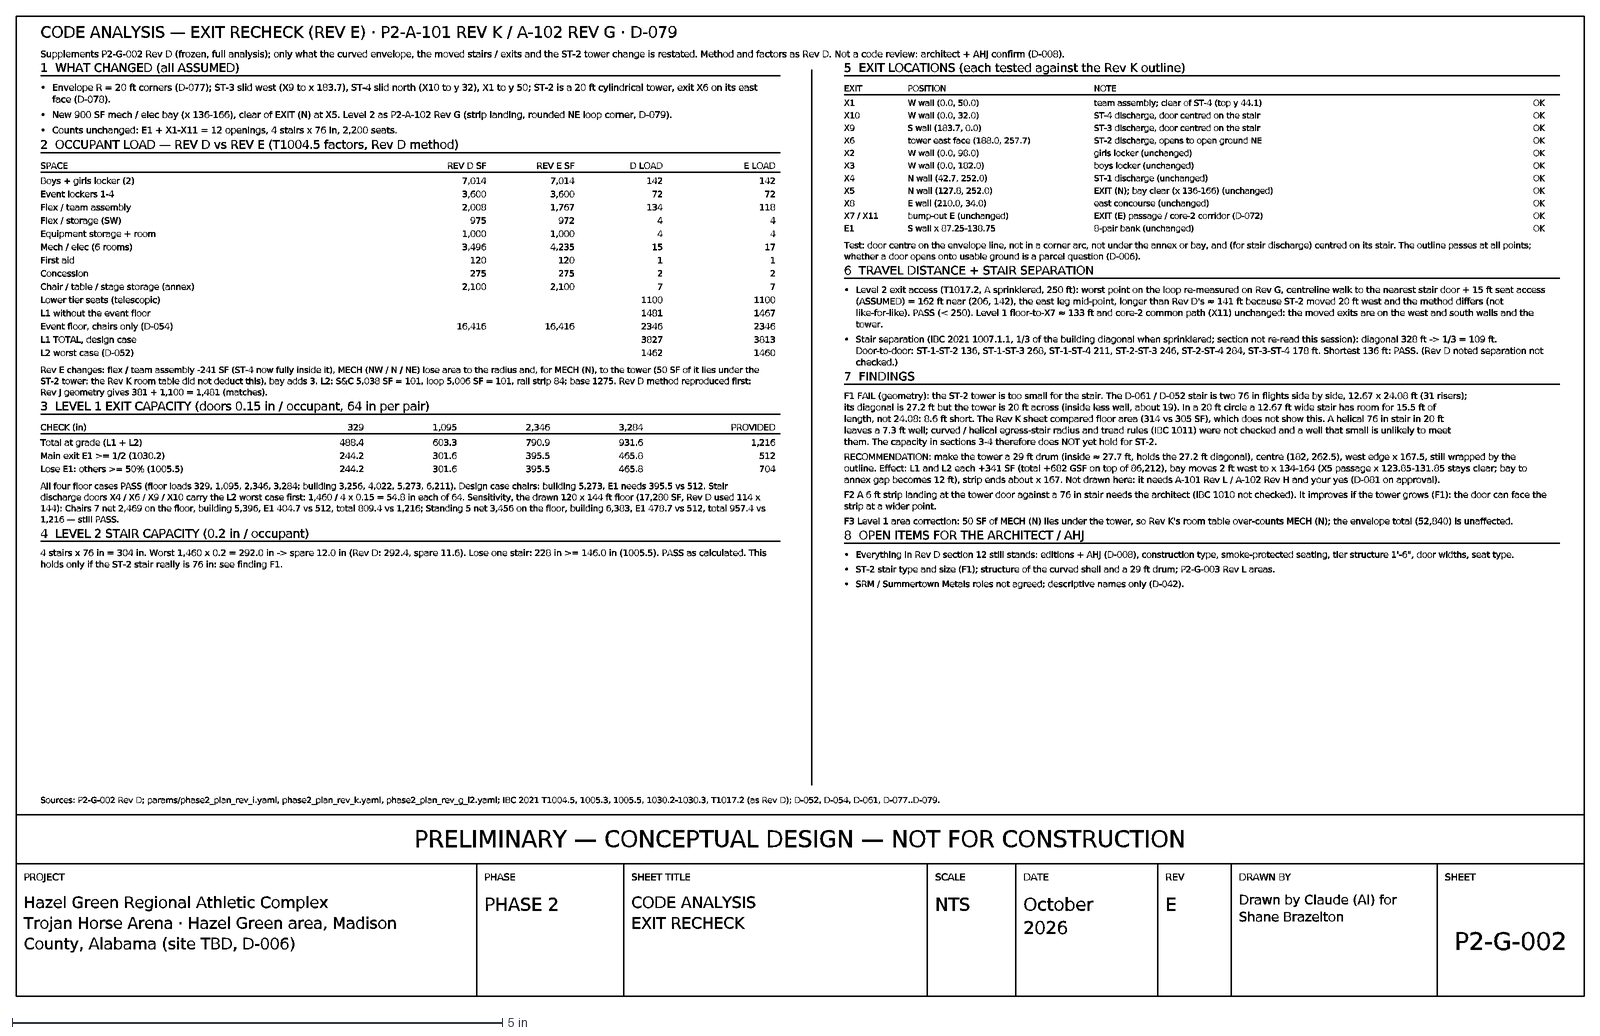
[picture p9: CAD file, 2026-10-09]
blueprints/phase2/out/dxf/P2-G-002_RevE.dxf
PRELIMINARY — CONCEPTUAL DESIGN — NOT FOR CONSTRUCTION
PROJECT
Hazel Green Regional Athletic Complex
Trojan Horse Arena · Hazel Green area, Madison
County, Alabama (site TBD, D-006)
PHASE
PHASE 2
SHEET TITLE
CODE ANALYSIS
EXIT RECHECK
SCALE
NTS
DATE
October
2026
REV
E
DRAWN BY
Drawn by Claude (AI) for
Shane Brazelton
SHEET
P2-G-002
CODE ANALYSIS — EXIT RECHECK (REV E) · P2-A-101 REV K / A-102 REV G · D-079
Supplements P2-G-002 Rev D (frozen, full analysis); only what the curved envelope, the moved stairs / exits and the ST-2 tower change is restated. Method and fa
1 WHAT CHANGED (all ASSUMED)
•
Envelope R = 20 ft corners (D-077); ST-3 slid west (X9 to x 183.7), ST-4 slid north (X10 to y 32), X1 to y 50; ST-2 is a 20 ft cylindrical tower, exit X6 on its
face (D-078).
New 900 SF mech / elec bay (x 136-166), clear of EXIT (N) at X5. Level 2 as P2-A-102 Rev G (strip landing, rounded NE loop corner, D-079).
Counts unchanged: E1 + X1-X11 = 12 openings, 4 stairs x 76 in, 2,200 seats.
2 OCCUPANT LOAD — REV D vs REV E (T1004.5 factors, Rev D method)
SPACE
REV D SF
REV E SF
D LOAD
E LOAD
Boys + girls locker (2)
7,014
142
Event lockers 1-4
3,600
72
Flex / team assembly
2,008
1,767
134
118
Flex / storage (SW)
975
972
4
Equipment storage + room
1,000
Mech / elec (6 rooms)
3,496
4,235
15
17
First aid
120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

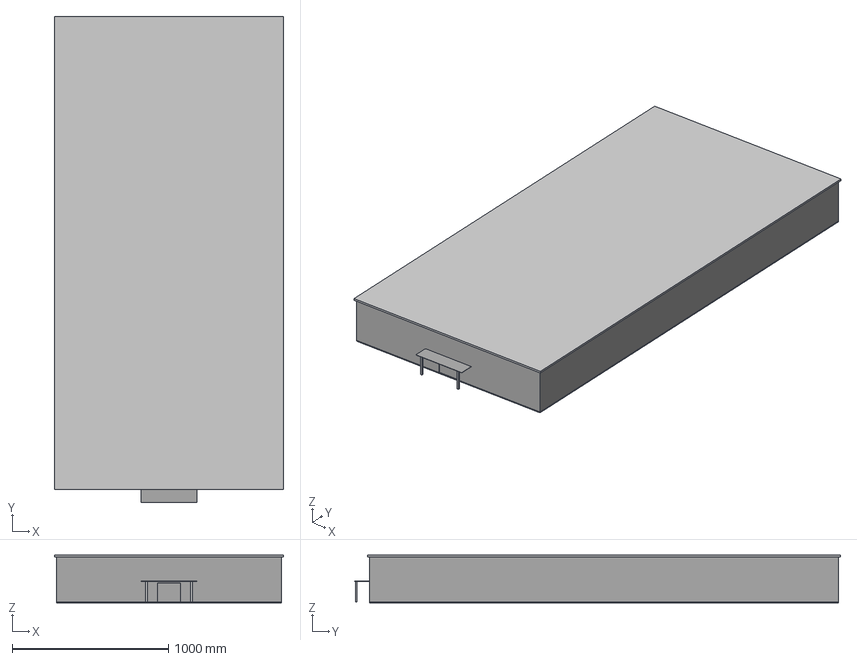
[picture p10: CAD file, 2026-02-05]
Hazel_Green_Trojans_Complex.step
1464.0 x 3108.0 x 306.0 mm
floor_slab_part
exterior_walls_part
roof_part
interior_wall_0_part
interior_wall_1_part
interior_wall_2_part
interior_wall_3_part
interior_wall_4_part
champ_part
champ_border_part
practice_0_part
practice_border_0_part
practice_1_part
practice_border_1_part
practice_2_part
practice_border_2_part
practice_3_part
practice_border_3_part
bleacher_0_part
bleacher_1_part
bleacher_2_part
bleacher_3_part
bleacher_4_part
bleacher_5_part
bleacher_6_part
bleacher_7_part
bleacher_8_part
bleacher_9_part
bleacher_10_part
bleacher_11_part
bleacher_12_part
bleacher_13_part
bleacher_14_part
bleacher_15_part
canopy_part
canopy_col_0_part
canopy_col_1_part
steel_beam_0_part
steel_beam_1_part
steel_beam_2_part
steel_beam_3_part
steel_beam_4_part
steel_beam_5_part
steel_beam_6_part
steel_beam_7_part
steel_beam_8_part
steel_beam_9_part

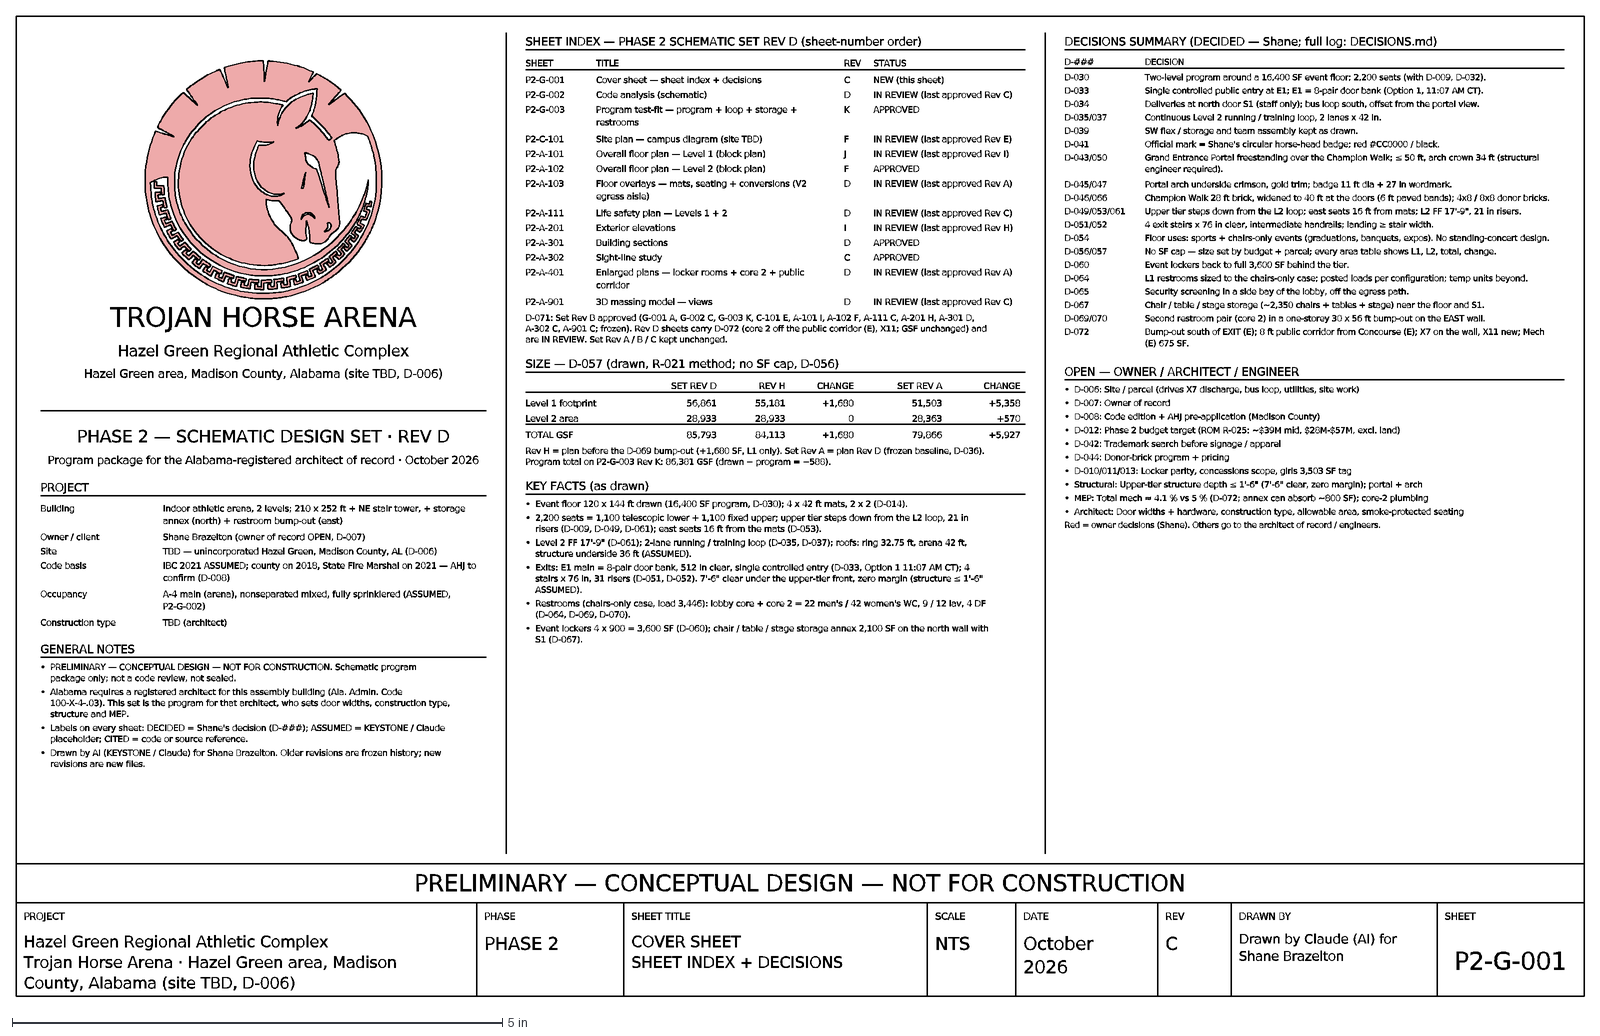
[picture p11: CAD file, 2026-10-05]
blueprints/phase2/handoff_2026-10-04/P2-G-001_RevC.dxf
PRELIMINARY — CONCEPTUAL DESIGN — NOT FOR CONSTRUCTION
PROJECT
Hazel Green Regional Athletic Complex
Trojan Horse Arena · Hazel Green area, Madison
County, Alabama (site TBD, D-006)
PHASE
PHASE 2
SHEET TITLE
COVER SHEET
SHEET INDEX + DECISIONS
SCALE
NTS
DATE
October
2026
REV
C
DRAWN BY
Drawn by Claude (AI) for
Shane Brazelton
SHEET
P2-G-001
TROJAN HORSE ARENA
Hazel Green area, Madison County, Alabama (site TBD, D-006)
PHASE 2 — SCHEMATIC DESIGN SET · REV D
Program package for the Alabama-registered architect of record · October 2026
Building
Indoor athletic arena, 2 levels; 210 x 252 ft + NE stair tower, + storage
annex (north) + restroom bump-out (east)
Owner / client
Shane Brazelton (owner of record OPEN, D-007)
Site
TBD — unincorporated Hazel Green, Madison County, AL (D-006)
Code basis
IBC 2021 ASSUMED; county on 2018, State Fire Marshal on 2021 — AHJ to
confirm (D-008)
Occupancy
A-4 main (arena), nonseparated mixed, fully sprinklered (ASSUMED,
P2-G-002)
Construction type
TBD (architect)
GENERAL NOTES
•
PRELIMINARY — CONCEPTUAL DESIGN — NOT FOR CONSTRUCTION. Schematic program
package only; not a code review, not sealed.
Alabama requires a registered architect for this assembly building (Ala. Admin. Code
100-X-4-.03). This set is the program for that architect, who sets door widths, construction type,
structure and MEP.
Labels on every sheet: DECIDED = Shane's decision (D-###); ASSUMED = KEYSTONE / Claude
placeholder; CITED = code or source reference.
Drawn by AI (KEYSTONE / Claude) for Shane Brazelton. Older revisions are frozen history; new
revisions are new files.
SHEET INDEX — PHASE 2 SCHEMATIC SET REV D (sheet-number order)
TITLE
STATUS
Cover sheet — sheet index + decisions
NEW (this sheet)
P2-G-002
Code analysis (schematic)
D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

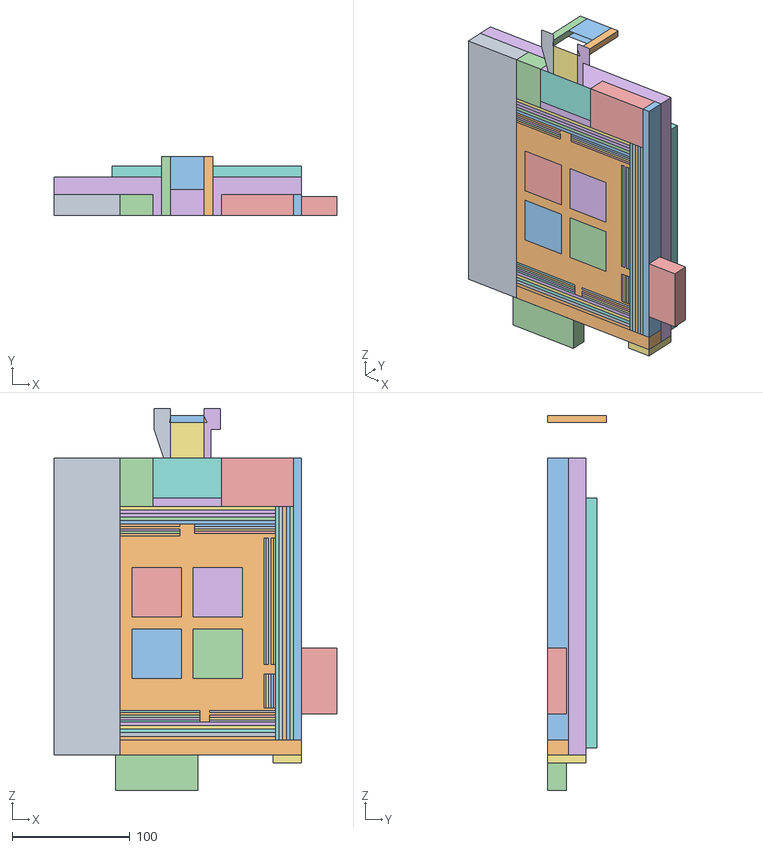
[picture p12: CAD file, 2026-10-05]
blueprints/phase2/out/3d/P2-A-901_RevC_massing.obj
240.0 x 50.0 x 324.0
exterior_portal_pier_w
exterior_portal_pier_e
exterior_portal_spandrel
exterior_storage_annex
exterior_restroom_bumpout
exterior_building_ring
exterior_ne_stair_tower
exterior_arena_volume
exterior_ground_band_0
exterior_ground_band_1
exterior_ground_walk_2
cutaway_portal_pier_w
cutaway_portal_pier_e
cutaway_portal_spandrel
cutaway_storage_annex_cut
cutaway_restroom_bumpout_cut
cutaway_ring_cut_0
cutaway_ring_cut_1
cutaway_ring_cut_2
cutaway_ring_cut_3
cutaway_ring_cut_4
cutaway_ring_cut_5
cutaway_ne_stair_tower_cut
cutaway_lower_N_2_0
cutaway_lower_N_2_1
cutaway_lower_N_3_0
cutaway_lower_N_3_1
cutaway_lower_N_4_0
cutaway_lower_N_4_1
cutaway_lower_N_5_0
cutaway_lower_N_5_1
cutaway_lower_N_6_0
cutaway_lower_N_6_1
cutaway_lower_S_2_0
cutaway_lower_S_2_1
cutaway_lower_S_3_0
cutaway_lower_S_3_1
cutaway_lower_S_4_0
cutaway_lower_S_4_1
cutaway_lower_S_5_0
cutaway_lower_S_5_1
cutaway_lower_S_6_0
cutaway_lower_S_6_1
cutaway_lower_E_2_0
cutaway_lower_E_2_1
cutaway_lower_E_3_0
cutaway_lower_E_3_1
cutaway_lower_E_4_0
cutaway_lower_E_4_1
cutaway_lower_E_5_0
cutaway_lower_E_5_1
cutaway_lower_E_6_0
cutaway_lower_E_6_1
cutaway_upper_N_1
cutaway_upper_N_2
cutaway_upper_N_3
cutaway_upper_N_4
cutaway_upper_N_5
cutaway_upper_S_1
cutaway_upper_S_2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

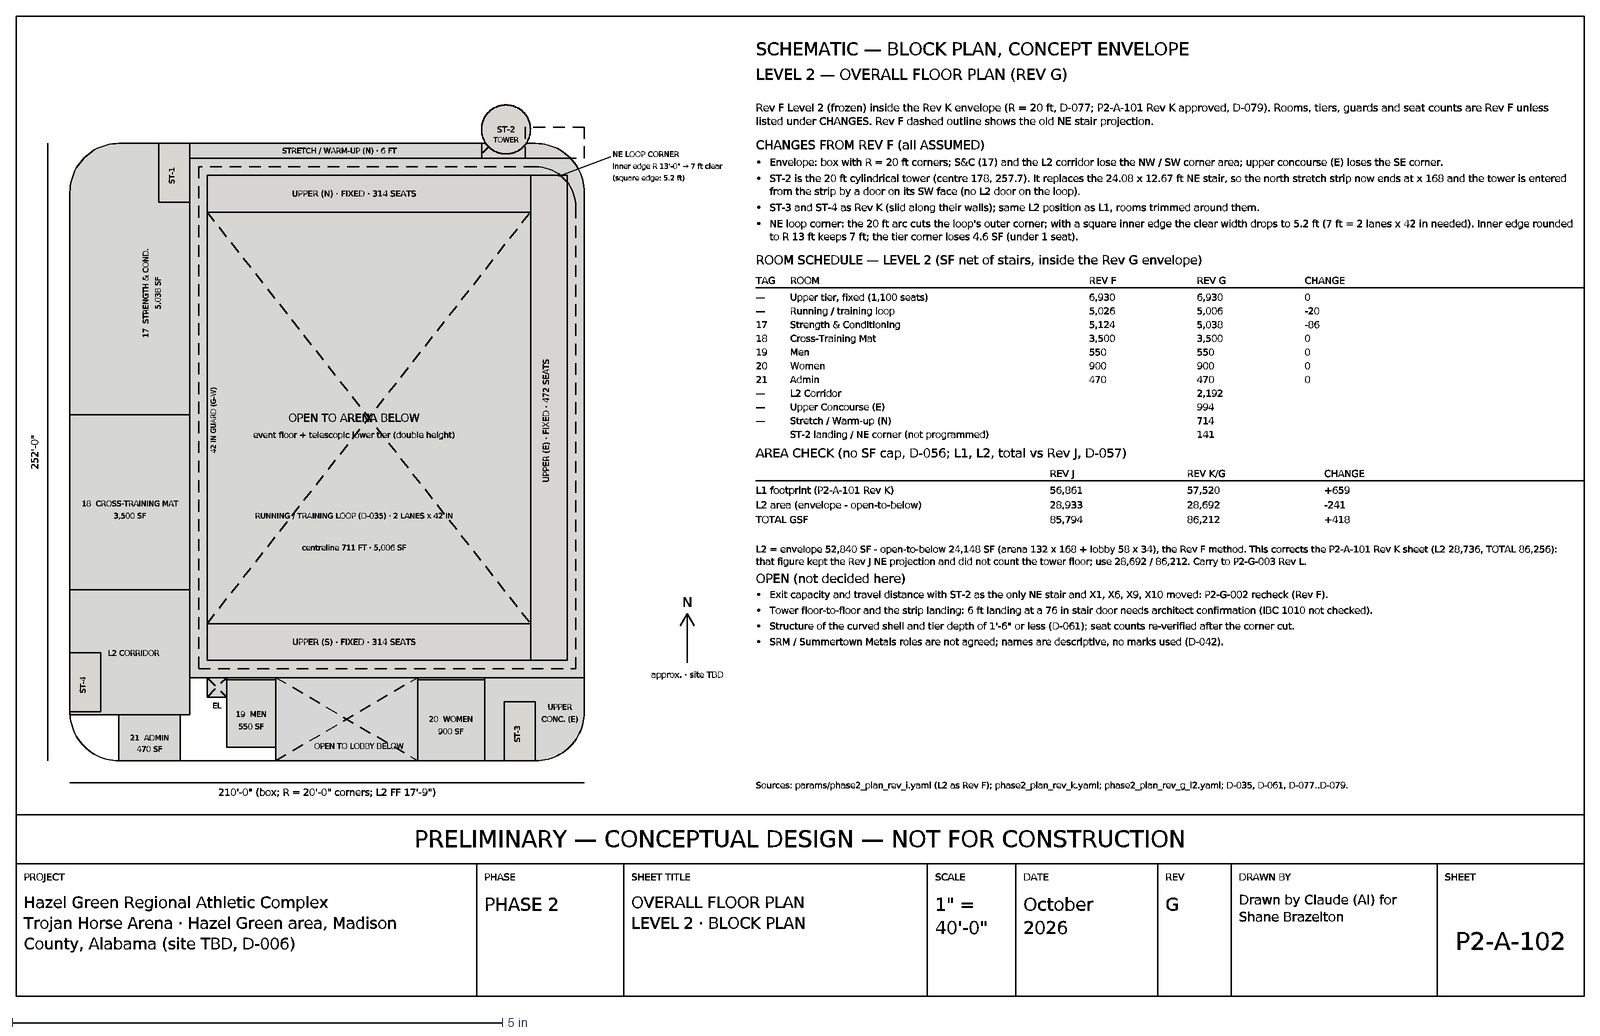
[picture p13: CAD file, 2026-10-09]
blueprints/phase2/out/dxf/P2-A-102_RevG.dxf
PRELIMINARY — CONCEPTUAL DESIGN — NOT FOR CONSTRUCTION
PROJECT
Hazel Green Regional Athletic Complex
Trojan Horse Arena · Hazel Green area, Madison
County, Alabama (site TBD, D-006)
PHASE
PHASE 2
SHEET TITLE
OVERALL FLOOR PLAN
LEVEL 2 · BLOCK PLAN
SCALE
1" =
40'-0"
DATE
October
2026
REV
G
DRAWN BY
Drawn by Claude (AI) for
Shane Brazelton
SHEET
P2-A-102
ST-1
ST-3
ST-4
ST-2
TOWER
EL
17 STRENGTH & COND.
5,038 SF
18 CROSS-TRAINING MAT
3,500 SF
L2 CORRIDOR
19 MEN
550 SF
20 WOMEN
900 SF
21 ADMIN
470 SF
UPPER
CONC. (E)
OPEN TO LOBBY BELOW
OPEN TO ARENA BELOW
event floor + telescopic lower tier (double height)
STRETCH / WARM-UP (N) · 6 FT
UPPER (N) · FIXED · 314 SEATS
UPPER (S) · FIXED · 314 SEATS
UPPER (E) · FIXED · 472 SEATS
RUNNING / TRAINING LOOP (D-035) · 2 LANES x 42 IN
centreline 711 FT · 5,006 SF
42 IN GUARD (G-W)
NE LOOP CORNER
inner edge R 13'-0" → 7 ft clear
(square edge: 5.2 ft)
210'-0" (box; R = 20'-0" corners; L2 FF 17'-9")
252'-0"
N
approx. · site TBD
SCHEMATIC — BLOCK PLAN, CONCEPT ENVELOPE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

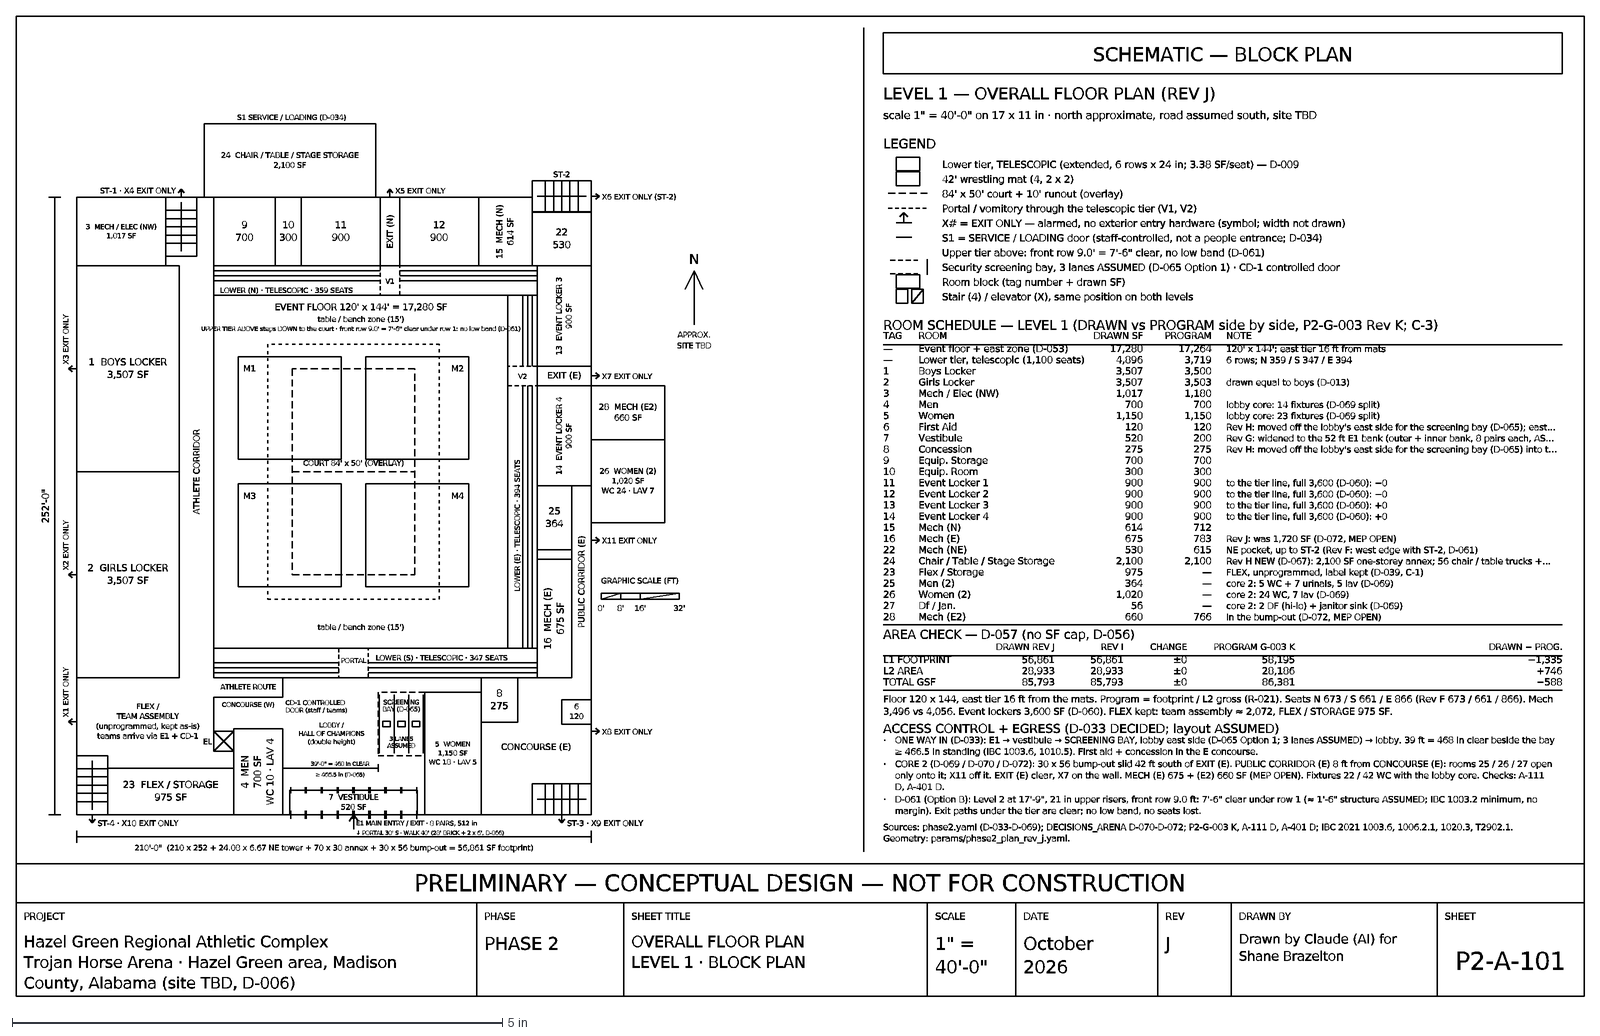
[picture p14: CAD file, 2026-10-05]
blueprints/phase2/handoff_2026-10-04/P2-A-101_RevJ.dxf
PRELIMINARY — CONCEPTUAL DESIGN — NOT FOR CONSTRUCTION
PROJECT
Hazel Green Regional Athletic Complex
Trojan Horse Arena · Hazel Green area, Madison
County, Alabama (site TBD, D-006)
PHASE
PHASE 2
SHEET TITLE
OVERALL FLOOR PLAN
LEVEL 1 · BLOCK PLAN
SCALE
1" =
40'-0"
DATE
October
2026
REV
J
DRAWN BY
Drawn by Claude (AI) for
Shane Brazelton
SHEET
P2-A-101
210'-0" (210 x 252 + 24.08 x 6.67 NE tower + 70 x 30 annex + 30 x 56 bump-out = 56,861 SF footprint)
252'-0"
LOWER (N) · TELESCOPIC · 359 SEATS
LOWER (S) · TELESCOPIC · 347 SEATS
LOWER (E) · TELESCOPIC · 394 SEATS
PORTAL
V1
V2
M1
M2
M3
M4
EVENT FLOOR 120' x 144' = 17,280 SF
table / bench zone (15')
COURT 84' x 50' (OVERLAY)
UPPER TIER ABOVE steps DOWN to the court · front row 9.0' = 7'-6" clear under row 1: no low band (D-061)
E1 MAIN ENTRY / EXIT · 8 PAIRS, 512 in
↓ PORTAL 30' S · WALK 40' (28' BRICK + 2 x 6', D-066)
SCREENING
BAY (D-065)
3 LANES
ASSUMED
39'-0" = 468 in CLEAR
≥ 466.5 in (D-065)
CD-1 CONTROLLED
DOOR (staff / teams)
X1 EXIT ONLY
X2 EXIT ONLY
X3 EXIT ONLY
X5 EXIT ONLY
X7 EXIT ONLY
X11 EXIT ONLY
X8 EXIT ONLY
S1 SERVICE / LOADING (D-034)
1 BOYS LOCKER
3,507 SF
2 GIRLS LOCKER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

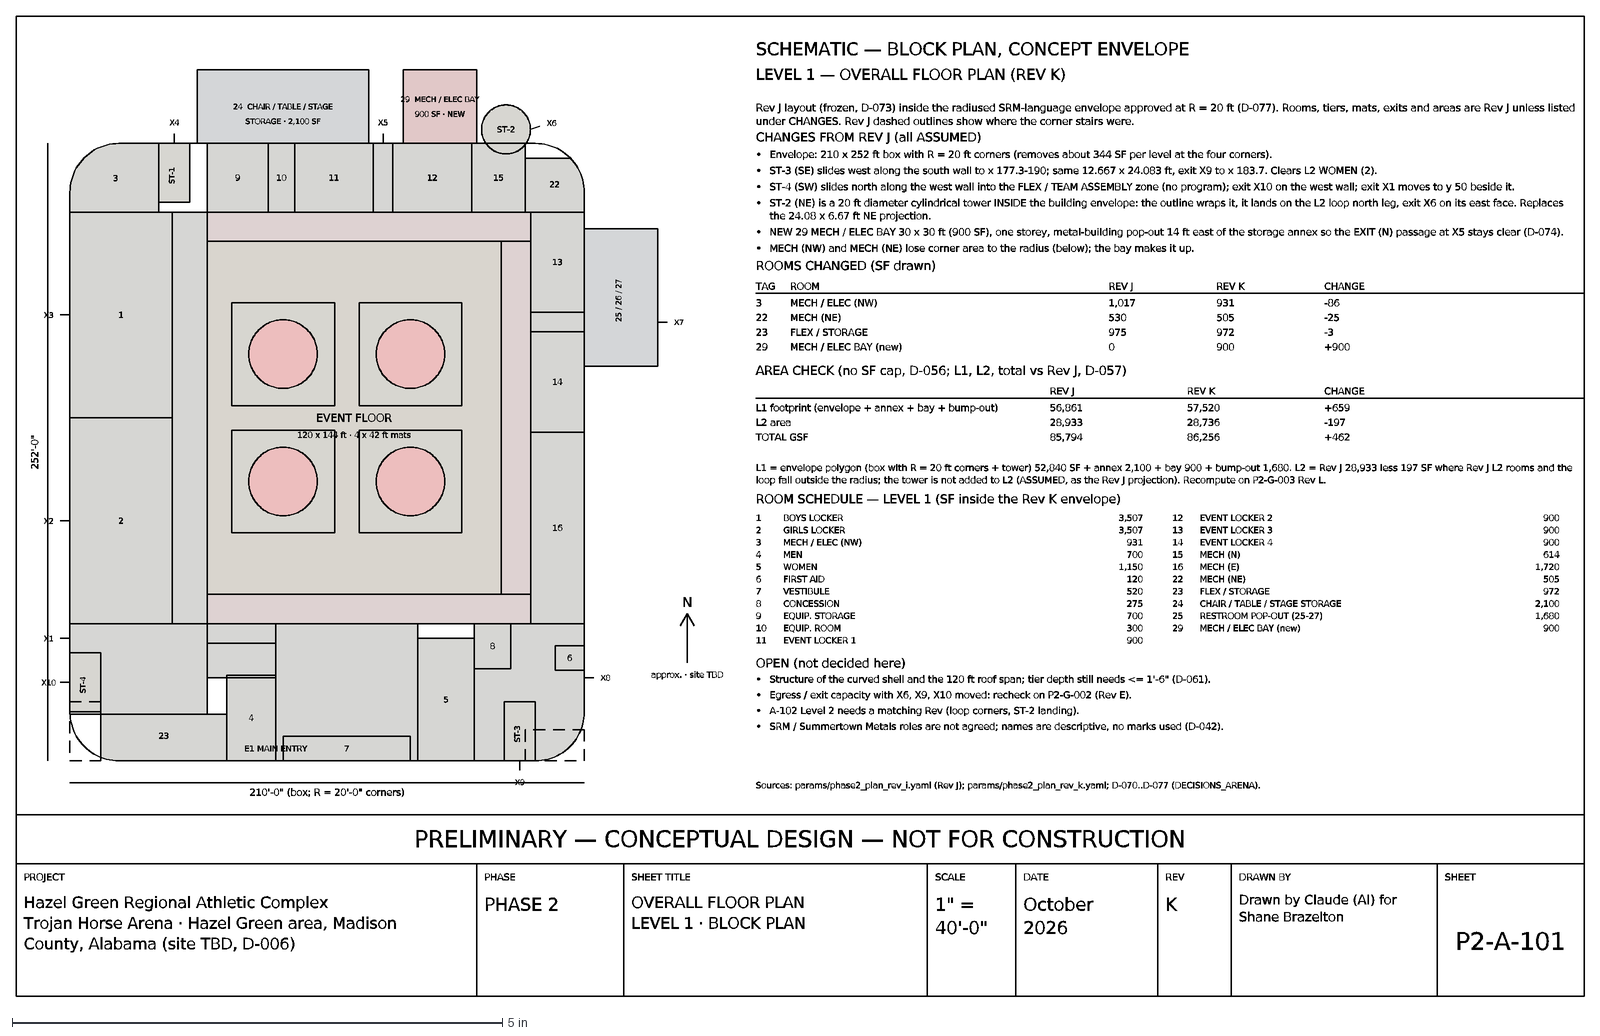
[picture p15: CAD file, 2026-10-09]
blueprints/phase2/out/dxf/P2-A-101_RevK.dxf
PRELIMINARY — CONCEPTUAL DESIGN — NOT FOR CONSTRUCTION
PROJECT
Hazel Green Regional Athletic Complex
Trojan Horse Arena · Hazel Green area, Madison
County, Alabama (site TBD, D-006)
PHASE
PHASE 2
SHEET TITLE
OVERALL FLOOR PLAN
LEVEL 1 · BLOCK PLAN
SCALE
1" =
40'-0"
DATE
October
2026
REV
K
DRAWN BY
Drawn by Claude (AI) for
Shane Brazelton
SHEET
P2-A-101
ST-3
ST-4
ST-1
ST-2
X1
X2
X3
X4
X5
X6
X7
X8
X9
X10
1
2
3
4
5
6
7
8
9
10
11
12
13
14
15
16
22
23
EVENT FLOOR
120 x 144 ft · 4 x 42 ft mats
24 CHAIR / TABLE / STAGE
STORAGE · 2,100 SF
29 MECH / ELEC BAY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

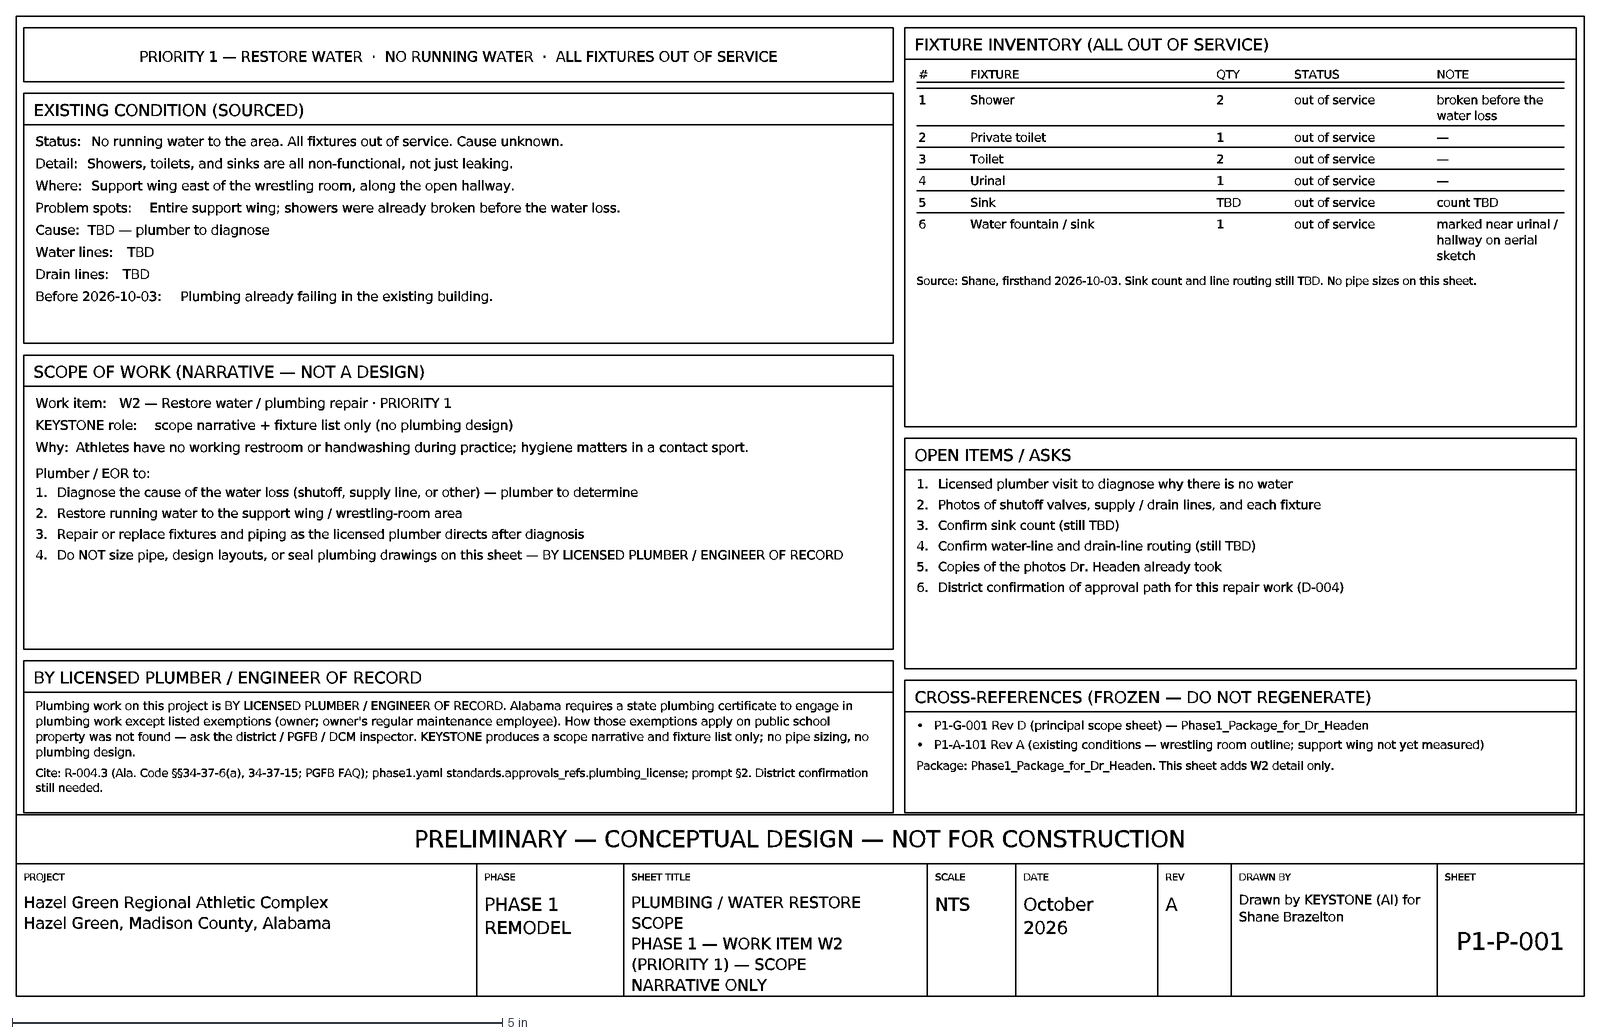
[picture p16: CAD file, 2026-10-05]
blueprints/phase1/out/dxf/P1-P-001_RevA.dxf
PRELIMINARY — CONCEPTUAL DESIGN — NOT FOR CONSTRUCTION
PROJECT
Hazel Green Regional Athletic Complex
Hazel Green, Madison County, Alabama
PHASE
PHASE 1
REMODEL
SHEET TITLE
PLUMBING / WATER RESTORE
SCOPE
PHASE 1 — WORK ITEM W2
(PRIORITY 1) — SCOPE
NARRATIVE ONLY
SCALE
NTS
DATE
October
2026
REV
A
DRAWN BY
Drawn by KEYSTONE (AI) for
Shane Brazelton
SHEET
P1-P-001
BY LICENSED PLUMBER / ENGINEER OF RECORD
Plumbing work on this project is BY LICENSED PLUMBER / ENGINEER OF RECORD. Alabama requires a state plumbing certificate to engage in
plumbing work except listed exemptions (owner; owner's regular maintenance employee). How those exemptions apply on public school
property was not found — ask the district / PGFB / DCM inspector. KEYSTONE produces a scope narrative and fixture list only; no pipe sizing, no
plumbing design.
Cite: R-004.3 (Ala. Code §§34-37-6(a), 34-37-15; PGFB FAQ); phase1.yaml standards.approvals_refs.plumbing_license; prompt §2. District confirmation
still needed.
SCOPE OF WORK (NARRATIVE — NOT A DESIGN)
Work item:
W2 — Restore water / plumbing repair · PRIORITY 1
KEYSTONE role:
scope narrative + fixture list only (no plumbing design)
Why:
Athletes have no working restroom or handwashing during practice; hygiene matters in a contact sport.
Plumber / EOR to:
1.
Diagnose the cause of the water loss (shutoff, supply line, or other) — plumber to determine
2.
Restore running water to the support wing / wrestling-room area
3.
Repair or replace fixtures and piping as the licensed plumber directs after diagnosis
4.
Do NOT size pipe, design layouts, or seal plumbing drawings on this sheet — BY LICENSED PLUMBER / ENGINEER OF RECORD
EXISTING CONDITION (SOURCED)
Status:
No running water to the area. All fixtures out of service. Cause unknown.
Detail:
Showers, toilets, and sinks are all non-functional, not just leaking.
Where:
Support wing east of the wrestling room, along the open hallway.
Problem spots:
Entire support wing; showers were already broken before the water loss.
Cause:
TBD — plumber to diagnose
Water lines: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

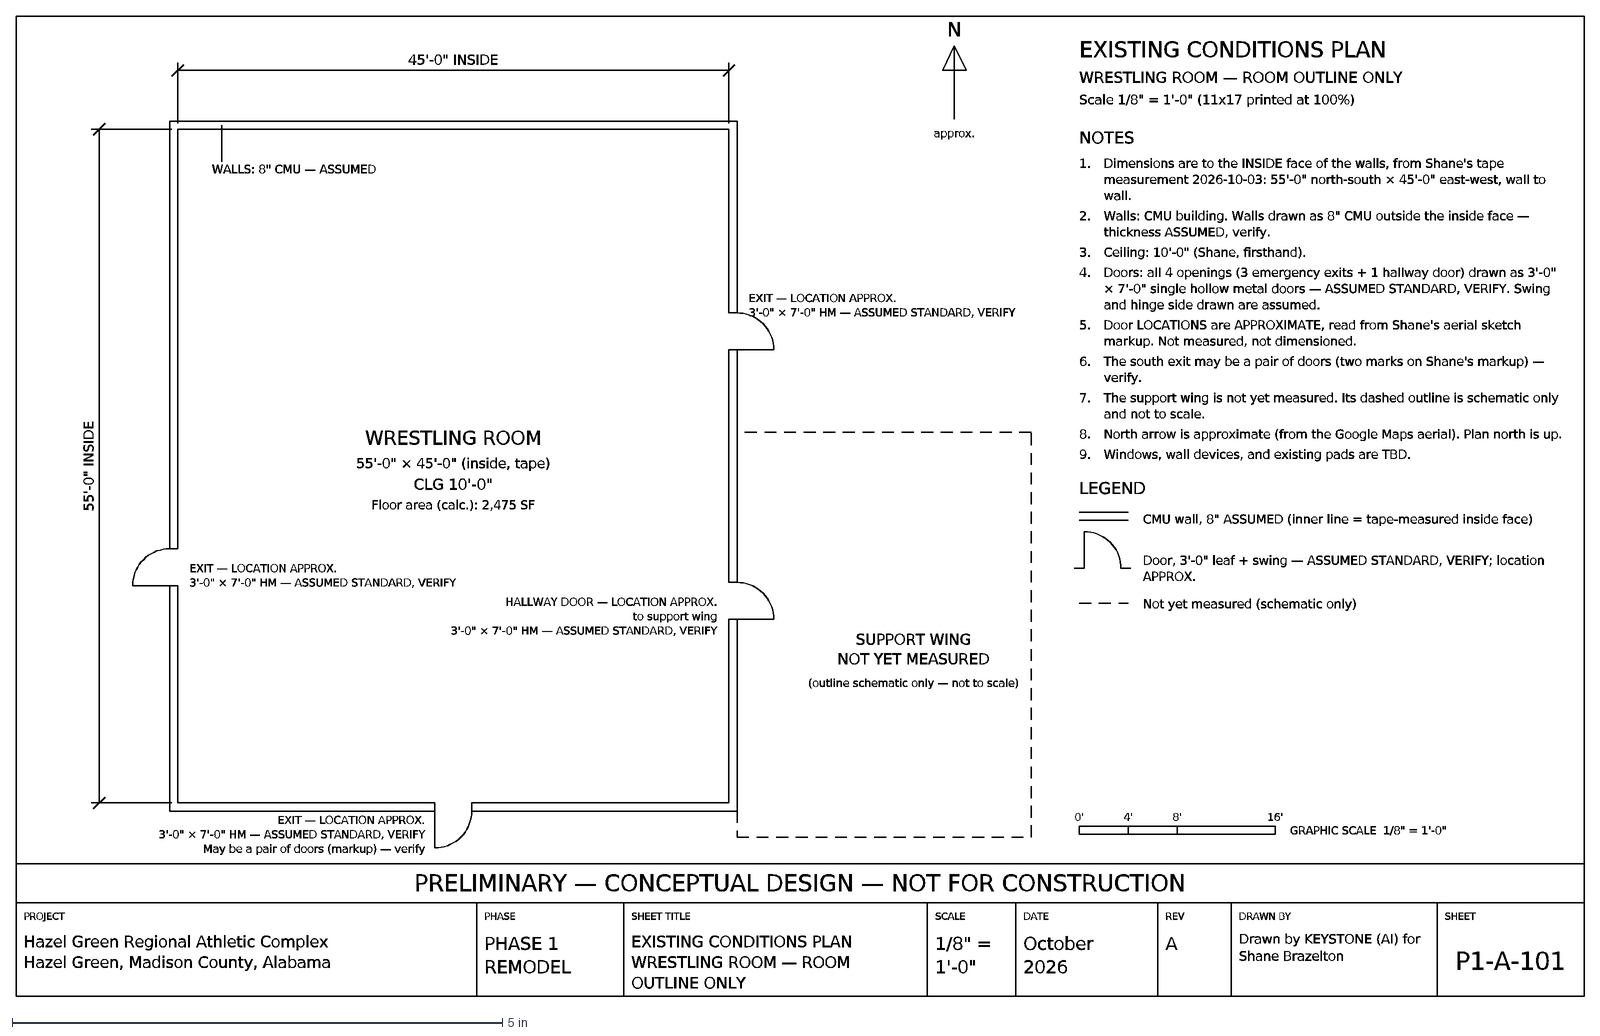
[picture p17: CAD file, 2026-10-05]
blueprints/phase1/out/dxf/P1-A-101_RevA.dxf
PRELIMINARY — CONCEPTUAL DESIGN — NOT FOR CONSTRUCTION
PROJECT
Hazel Green Regional Athletic Complex
Hazel Green, Madison County, Alabama
PHASE
PHASE 1
REMODEL
SHEET TITLE
EXISTING CONDITIONS PLAN
WRESTLING ROOM — ROOM
OUTLINE ONLY
SCALE
1/8" =
1'-0"
DATE
October
2026
REV
A
DRAWN BY
Drawn by KEYSTONE (AI) for
Shane Brazelton
SHEET
P1-A-101
WRESTLING ROOM — ROOM OUTLINE ONLY
Scale 1/8" = 1'-0" (11x17 printed at 100%)
EXIT — LOCATION APPROX.
3'-0" × 7'-0" HM — ASSUMED STANDARD, VERIFY
May be a pair of doors (markup) — verify
HALLWAY DOOR — LOCATION APPROX.
to support wing
WRESTLING ROOM
55'-0" × 45'-0" (inside, tape)
CLG 10'-0"
Floor area (calc.): 2,475 SF
WALLS: 8" CMU — ASSUMED
45'-0" INSIDE
55'-0" INSIDE
SUPPORT WING
NOT YET MEASURED
(outline schematic only — not to scale)
N
approx.
0'
4'
8'
16'
GRAPHIC SCALE 1/8" = 1'-0"
NOTES
1.
Dimensions are to the INSIDE face of the walls, from Shane's tape
measurement 2026-10-03: 55'-0" north-south × 45'-0" east-west, wall to
wall.
2.
Walls: CMU building. Walls drawn as 8" CMU outside the inside face —
thickness ASSUMED, verify.
3.
Ceiling: 10'-0" (Shane, firsthand).
4.
Doors: all 4 openings (3 emergency exits + 1 hallway door) drawn as 3'-0"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

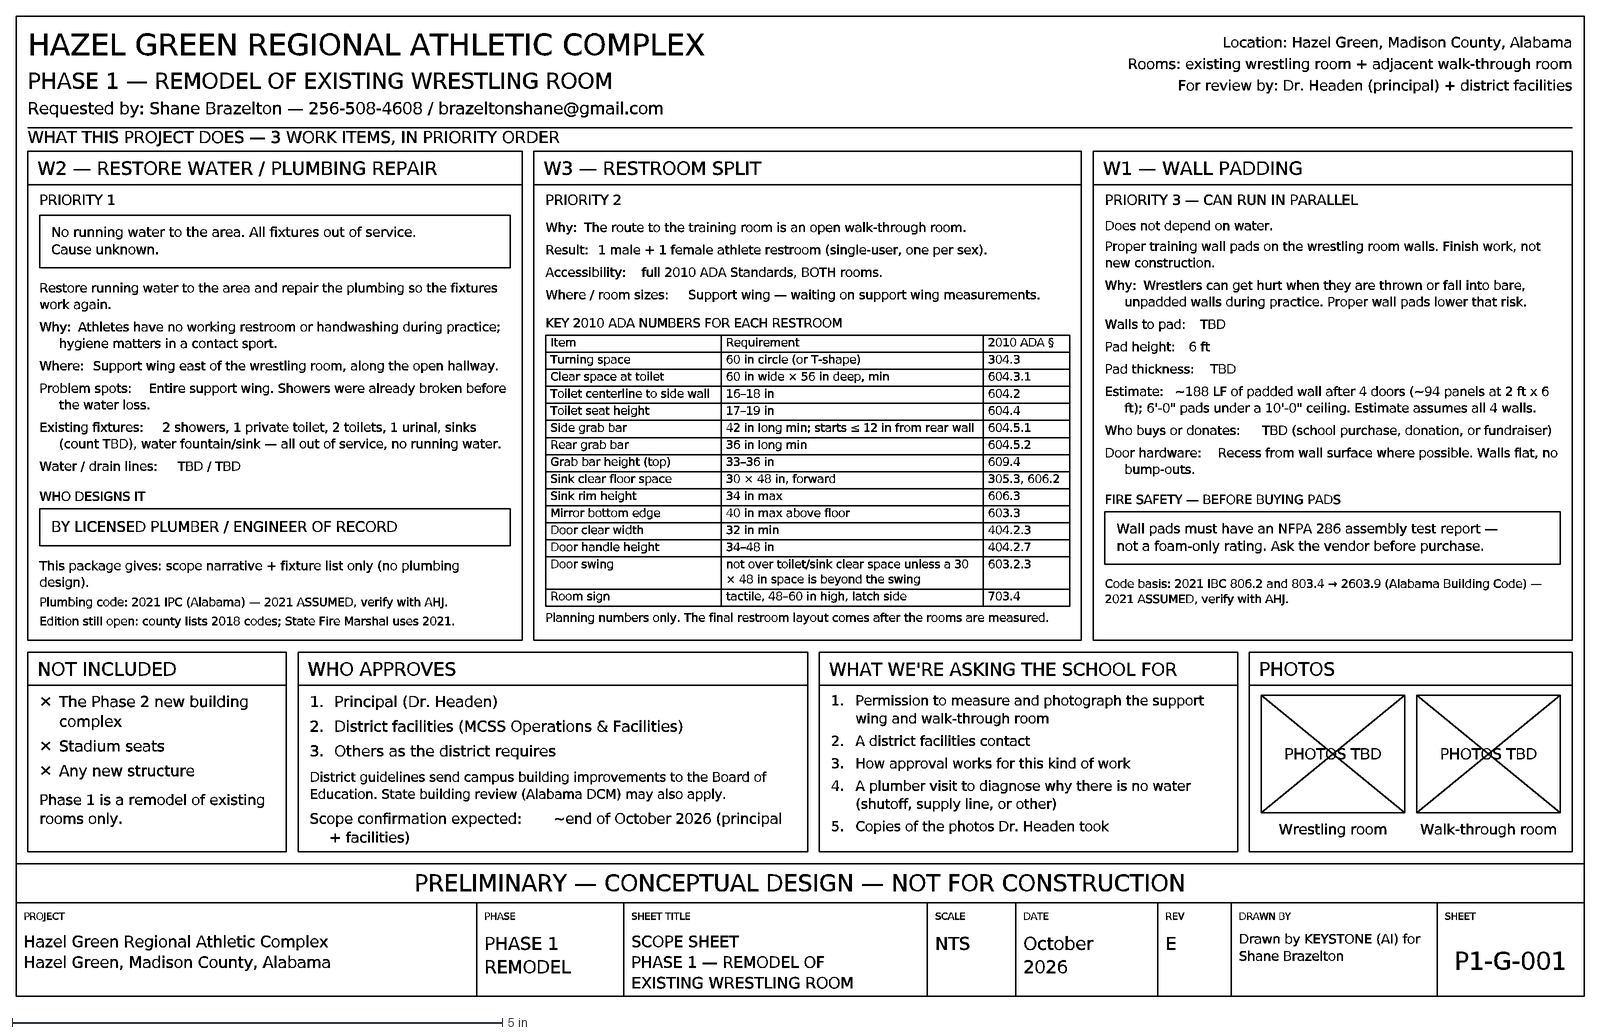
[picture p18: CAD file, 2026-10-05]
blueprints/phase1/out/dxf/P1-G-001_RevE_principal.dxf
PRELIMINARY — CONCEPTUAL DESIGN — NOT FOR CONSTRUCTION
PROJECT
Hazel Green Regional Athletic Complex
Hazel Green, Madison County, Alabama
PHASE
PHASE 1
REMODEL
SHEET TITLE
SCOPE SHEET
PHASE 1 — REMODEL OF
EXISTING WRESTLING ROOM
SCALE
NTS
DATE
October
2026
REV
E
DRAWN BY
Drawn by KEYSTONE (AI) for
Shane Brazelton
SHEET
P1-G-001
HAZEL GREEN REGIONAL ATHLETIC COMPLEX
PHASE 1 — REMODEL OF EXISTING WRESTLING ROOM
Requested by: Shane Brazelton — 256-508-4608 / brazeltonshane@gmail.com
Location: Hazel Green, Madison County, Alabama
Rooms: existing wrestling room + adjacent walk-through room
For review by: Dr. Headen (principal) + district facilities
WHAT THIS PROJECT DOES — 3 WORK ITEMS, IN PRIORITY ORDER
W2 — RESTORE WATER / PLUMBING REPAIR
PRIORITY 1
No running water to the area. All fixtures out of service.
Cause unknown.
Restore running water to the area and repair the plumbing so the fixtures
work again.
Why:
Athletes have no working restroom or handwashing during practice;
hygiene matters in a contact sport.
Where:
Support wing east of the wrestling room, along the open hallway.
Problem spots:
Entire support wing. Showers were already broken before
the water loss.
Existing fixtures:
2 showers, 1 private toilet, 2 toilets, 1 urinal, sinks
(count TBD), water fountain/sink — all out of service, no running water.
Water / drain lines:
TBD / TBD
WHO DESIGNS IT
BY LICENSED PLUMBER / ENGINEER OF RECORD
This package gives: scope narrative + fixture list only (no plumbing
design).
Plumbing code: 2021 IPC (Alabama) — 2021 ASSUMED, verify with AHJ.
Edition still open: county lists 2018 codes; State Fire Marshal uses 2021.
W3 — RESTROOM SPLIT
PRIORITY 2
The route to the training room is an open walk-through room.
Result:
1 male + 1 female athlete restroom (single-user, one per sex).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

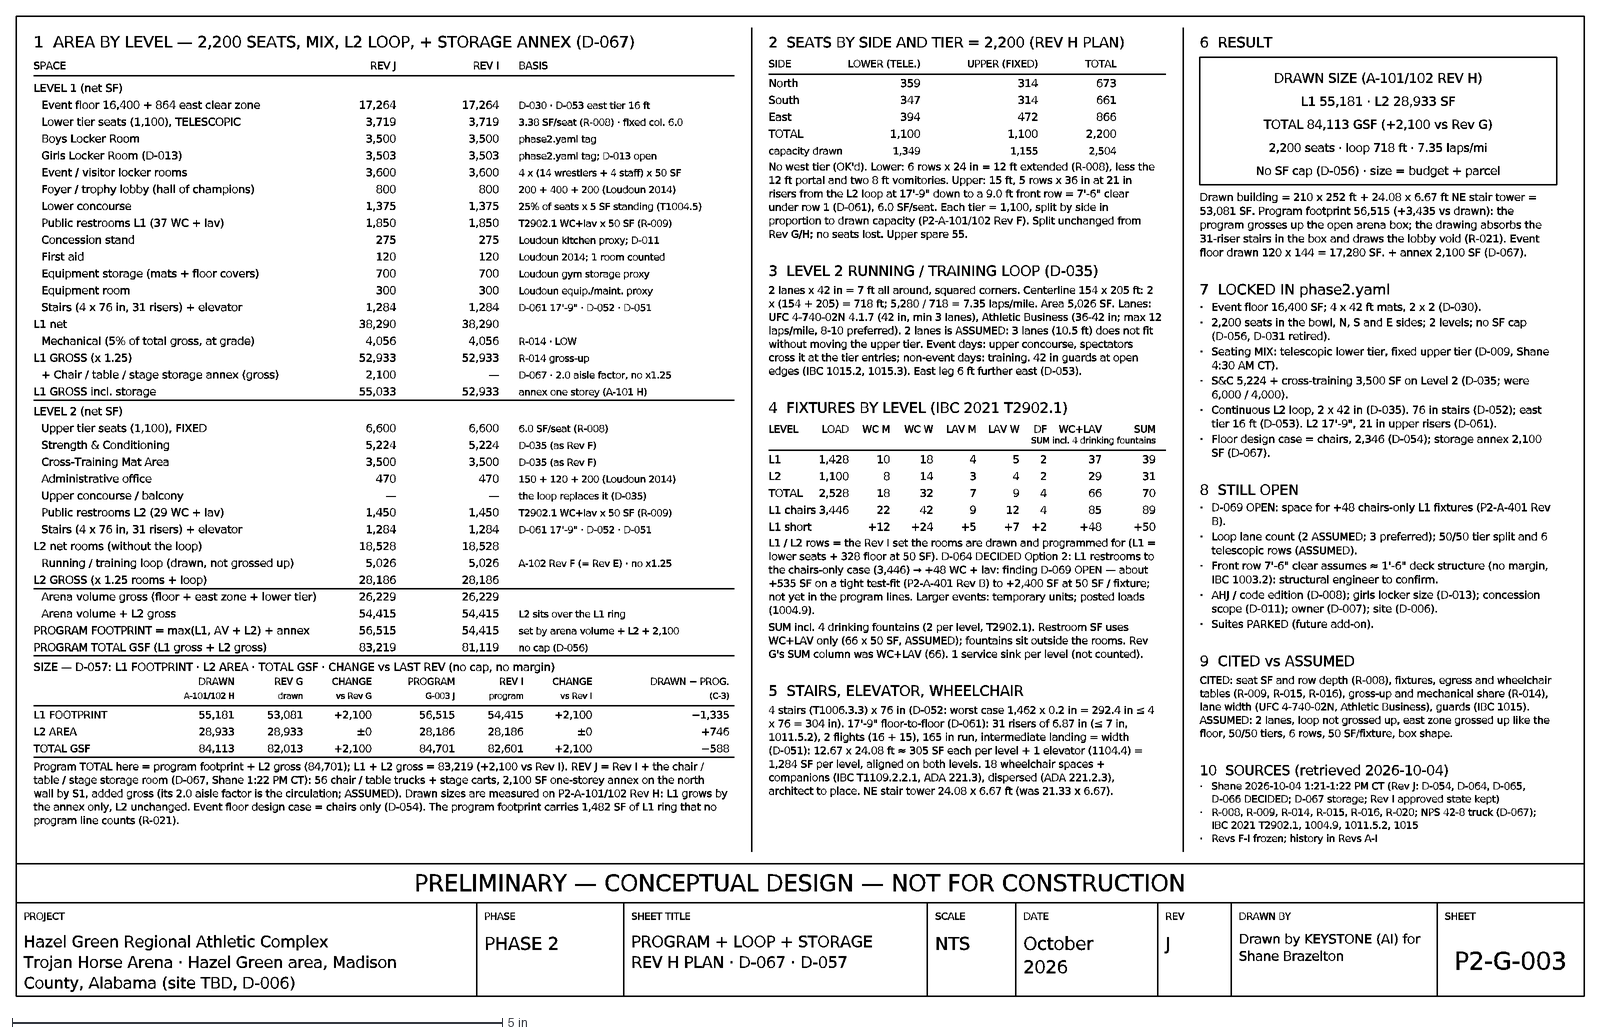
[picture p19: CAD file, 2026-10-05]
blueprints/phase2/out/dxf/P2-G-003_RevJ.dxf
PRELIMINARY — CONCEPTUAL DESIGN — NOT FOR CONSTRUCTION
PROJECT
Hazel Green Regional Athletic Complex
Trojan Horse Arena · Hazel Green area, Madison
County, Alabama (site TBD, D-006)
PHASE
PHASE 2
SHEET TITLE
PROGRAM + LOOP + STORAGE
REV H PLAN · D-067 · D-057
SCALE
NTS
DATE
October
2026
REV
J
DRAWN BY
Drawn by KEYSTONE (AI) for
Shane Brazelton
SHEET
P2-G-003
1 AREA BY LEVEL — 2,200 SEATS, MIX, L2 LOOP, + STORAGE ANNEX (D-067)
SPACE
REV J
REV I
BASIS
LEVEL 1 (net SF)
Event floor 16,400 + 864 east clear zone
17,264
D-030 · D-053 east tier 16 ft
Lower tier seats (1,100), TELESCOPIC
3,719
3.38 SF/seat (R-008) · fixed col. 6.0
Boys Locker Room
3,500
phase2.yaml tag
Girls Locker Room (D-013)
3,503
phase2.yaml tag; D-013 open
Event / visitor locker rooms
3,600
4 x (14 wrestlers + 4 staff) x 50 SF
Foyer / trophy lobby (hall of champions)
800
200 + 400 + 200 (Loudoun 2014)
Lower concourse
1,375
25% of seats x 5 SF standing (T1004.5)
Public restrooms L1 (37 WC + lav)
1,850
T2902.1 WC+lav x 50 SF (R-009)
Concession stand
275
Loudoun kitchen proxy; D-011
First aid
120
Loudoun 2014; 1 room counted
Equipment storage (mats + floor covers)
700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

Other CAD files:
blueprints/phase2/handoff_2026-10-04/P2-C-101_RevF.dxf
blueprints/phase2/handoff_2026-10-04/P2-A-111_RevD.dxf
blueprints/phase2/handoff_2026-10-04/P2-A-103_RevD.dxf
blueprints/phase2/handoff_2026-10-04/P2-A-401_RevD.dxf
blueprints/phase2/out/dxf/P2-A-201_RevH.dxf
blueprints/phase2/handoff_2026-10-04/P2-A-901_RevD_massing.obj
Hazel_Green_Trojans_Complex.stl
blueprints/phase1/out/dxf/P1-G-001_RevB_principal.dxf
blueprints/phase1/out/dxf/P1-G-001_RevC_principal.dxf
blueprints/phase1/out/dxf/P1-G-001_RevD_principal.dxf
blueprints/phase2/handoff_2026-10-04/P2-A-103_RevC.dxf
blueprints/phase2/handoff_2026-10-04/P2-A-201_RevI.dxf
blueprints/phase2/handoff_2026-10-04/P2-A-901_RevD.dxf
blueprints/phase2/handoff_2026-10-04/P2-G-001_RevA.dxf
blueprints/phase2/handoff_2026-10-04/P2-G-001_RevB.dxf
blueprints/phase2/handoff_2026-10-04/P2-G-002_RevC.dxf
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

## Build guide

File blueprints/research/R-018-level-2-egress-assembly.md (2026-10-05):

# R-018 — Level 2 egress: occupant load, stair and concourse (loop) capacity, assembly aisles, travel, guards, event-day cross-flow

Researched by KEYSTONE 2026-10-04 for D-038 (OPEN: "Upper concourse width vs egress calc — if code requires wider, go to 3 lanes (10.5 ft)"), after Shane approved P2-A-101/102 Rev D + P2-G-003 Rev F (5:27 AM CT). Geometry: params/phase2_plan_rev_d.yaml (frozen, Phase 2 Schematic Set Rev A). Builds on R-015 (stairs, sprinklers + voice alarm) and R-017 (track lanes, guards).
Status: research note, not a code review. KEYSTONE is not an architect or code official: the occupant load, catchments and widths must be confirmed by the architect of record and the AHJ (D-008). No legal advice.

## Sources
- **S1** — IBC 2021, Chapter 10 Means of Egress (Alabama), UpCodes viewer — https://up.codes/viewer/alabama/ibc-2021/chapter/10/means-of-egress — retrieved 2026-10-04 (full chapter text saved on the box, not committed). PRIMARY via a free viewer; the ICC original is paywalled / script-only.
- **S2** — IBC 2018 text, secondary copies seen as search excerpts on 2026-10-04: a flipbuilder copy of the 2018 code, §1029.6 / 1029.6.1 / Table 1029.6.2 (https://online.flipbuilder.com/mewf/msoi/files/basic-html/page323.html), and UpCodes 2018 IBC state viewers (Texas, Illinois) showing the 1005.3.1 / 1005.3.2 exceptions pointing to §1029 (https://up.codes/viewer/texas/ibc-2018/chapter/10/means-of-egress, https://up.codes/viewer/illinois/ibc-2018/chapter/10/means-of-egress). **UNVERIFIED**: excerpts only, not the full chapter, and not the Alabama/Madison County adoption; ICC original (https://codes.iccsafe.org/content/IBC2018/chapter-10-means-of-egress) is paywalled / script-only.
- **S3** — R-015 §R-015.5: IBC 2021 903.2.1.4 (sprinklers, Group A-4) and 907.2.1.1 (emergency voice/alarm, Group A ≥ 1,000 occupants), retrieved 2026-10-03.
- **S4** — Athletic Business, "Designing Tracks for Recreational Users" (users crossing a track are a hazard) — see R-017, retrieved 2026-10-04. TRADE PRESS.
- Not reviewed (paywalled): NFPA 101 (life safety evaluation required by IBC 1030.6.2 for smoke-protected seating), ICC 300 (bleachers / telescopic seating, governs the L1 lower tier).

Edition note: Madison County lists the 2018 IBC for county permits; Shane said 2021 (D-008 OPEN). The assembly section is **1029 in 2018 and 1030 in 2021** (same subsection numbers: 1029.6 ↔ 1030.6, 1029.7 ↔ 1030.7 …). S2 shows 2018 1029.6.1 with the same aisle factors as 2021 1030.6.1, the same Table 1029.6.2 values (≤ 5,000 seats: 0.200 / 0.250 / 0.150 / 0.165) and the same 1005.3.1 / 1005.3.2 sprinkler + voice-alarm exceptions (0.2 / 0.15 in). 1004.5, 1005.3, 1015, 1017.2 and 1020.3 keep their numbers; their 2018 text was not re-read (UNVERIFIED).

## R-018.1 Level 2 occupant load (event day)

| Space | Basis (S1) | Area | Load |
|---|---|---|---|
| Upper tier, fixed seats | 1004.6 (number of fixed seats) | — | 1,100 |
| S&C (17) | T1004.5 exercise rooms, 50 gross | 5,224 SF | 5,224 / 50 = 104.5 → 105 |
| Cross-training (18) | T1004.5 exercise rooms, 50 gross | 3,500 SF | 3,500 / 50 = 70 |
| Admin (21) | T1004.5 business areas, 150 gross | 470 SF | 470 / 150 = 3.1 → 4 |
| Restrooms, loop, corridor, stretch strip | circulation / accessory (same people) | — | not added |
| **Total** | | | **1,279** (= P2-G-003 Rev F) |

Sensitivities (AHJ decisions, not KEYSTONE's): (a) loop counted as an exercise room while seats are full: 4,942 / 50 = 98.8 → 99, total 1,378; (b) spectators standing at the west-leg rail over the arena counted as standing space (T1004.5, 5 net): e.g. a 2.5 ft strip x 168 ft = 420 SF / 5 = 84 (strip depth ASSUMED), total 1,363. The table also lists "concourse 100 gross", but only under airport terminals.

1,279 > 1,000 → **4 exits from Level 2** (T1006.3.3) = the 4 stairs. 1030.5: a balcony / gallery with ≥ 50 seats needs 2 means of egress, one from each side — the loop gives both directions on every side.

## R-018.2 Stair capacity (1005.3.1)

1005.3.1: 0.3 in per occupant; **exception 1** (all but H and I-2): 0.2 in per occupant with sprinklers (903.3.1.1) + emergency voice/alarm (907.5.2.2), both required here anyway (S3). Exception 2 allows Table 1030.6.2 stepped-aisle factors only for smoke-protected seating with a 909 smoke-control system along the whole path.

- 1,279 x 0.2 = **255.8 in** total → 4 stairs x 64 in (P2-G-003 Rev F: 63.95 in). **Zero slack.**
- Without the exception: 1,279 x 0.3 = 383.7 in → 96 in per stair.
- Sensitivity (a): 1,378 x 0.2 = 275.6 in → 69 in per stair; (b): 1,363 x 0.2 = 272.6 in → 68 in per stair.
- 1005.5: losing any one stair leaves 3 x 64 = 192 in ≥ 50% x 255.8 = 127.9 in ✓.
- 1030.6.1 (0.3 in stepped / 0.2 in level, no sprinkler reduction) applies to **aisles** in the seating, not to the exit stairs (2021 title "Capacity of aisle for assembly"; same in 2018 per S2).

## R-018.3 The loop as the upper concourse (egress path to the stairs)

Width factor: where the loop is the cross aisle behind the seats it is an assembly aisle → **0.2 in per occupant** for level aisles (1030.6.1 item 4; no sprinkler reduction). As an "other egress component" it could use 0.15 in (1005.3.2 exc. 1); KEYSTONE uses the stricter 0.2.

Catchment: 1030.9.2 — assume **balanced use of all means of egress, people in proportion to egress capacity**. 4 equal stairs → 1,279 / 4 = 319.75 → 320 per stair. Rooms go straight to a stair (S&C 105 → ST-1; cross-training 70 + admin 4 → ST-4 via the L2 corridor), so the loop carries seat occupants only:

| Path on the loop | Occupants | Required width (x 0.2 in) |
|---|---|---|
| into ST-2 (NE corner, from N + E legs) | 320 | 64.0 in |
| into ST-3 (SE corner → upper concourse E) | 320 | 64.0 in |
| into ST-4 (SW corner → L2 corridor) | 320 − 74 = 246 | 49.2 in |
| into ST-1 (W leg) | 320 − 105 = 215 | 43.0 in |
| **Unbalanced check** (each tier side splits to its two end stairs: N 308 → 154 + 154; E 484 → 242 + 242; S 308 → 154 + 154; NE and SE corners each take 154 + 242) | 396 | **79.2 in** |
| Loop as drawn | — | **84 in (7 ft)** |

Minimum widths: 36 in level aisle with seating on one side (1030.9.1); 44 in corridor (T1020.3) if the AHJ calls it a corridor; 36 in accessible route. 84 in clears all of them. 1030.9.4: a path usable in two directions must be uniform in width — the loop is a uniform 7 ft. Dead ends (1030.9.5): none on a continuous loop. 1005.4: width may not shrink toward the exit — the corners and the paths to ST-3 (35 ft concourse) and ST-4 (49 ft corridor) are wider.

Clear width is measured to walls, edges of seating and tread edges, with no obstructions (1030.9.6, 1030.9.6.1). At the worst-case corner the spare width is 84 − 79.2 = **4.8 in**; in the balanced case 20 in.

Doors onto the loop: S&C and cross-training each hold ≥ 50 people, so their doors swing out into the loop (1010.1.2.1). 1005.7.1: a fully open door may take ≤ 7 in of the required width and ≤ 1/2 in any position (a 36 in leaf swinging into 84 in leaves 48 in ≥ 39.6 in, OK) — recessed door alcoves keep the lanes clear. Stair doors swing into the stairs.

## R-018.4 Travel distance, common path, aisles

- T1017.2 (1030.7): Group A, sprinklered, **250 ft** exit access (400 ft total if smoke-protected). Rough worst cases measured along the plan (stepped aisle ≈ 15 ft + loop + to the stair door): E-tier middle → ST-2 ≈ 15 + 102.5 + 10 ≈ **128 ft**; S-tier middle → ST-3 ≈ 15 + 81.5 + 26.7 ≈ 123 ft (→ ST-4 ≈ 141 ft); N-tier middle → ST-1 ≈ 86 ft; S&C far corner → ST-1 ≈ 136 ft; cross-training far corner → ST-4 ≈ 127 ft. All < 250 ft.
- 1030.8: common path ≤ 30 ft from any seat to a choice of two paths. The upper tier is only 15 ft deep, so a stepped aisle reaches the loop (two directions) within ≈ 15 ft; row layout is not drawn, so rows with an aisle at each end (1030.13.2.1) are ASSUMED.
- 1030.9.1: stepped aisles 48 in (seats both sides) / 36 in (one side); handrails per 1030.16; aisle capacity 0.3 in per occupant on stepped aisles with ≤ 7 in risers (1030.6.1).

## R-018.5 Guards and handrails

- Loop open edges (west over the arena / athlete corridor, south over the lobby): drop ≈ 15 ft > 30 in → **42 in guards** (1015.2, 1015.3), 4 in sphere (4-3/8 in from 36 to 42 in) (1015.4).
- Upper tier: perimeter guards (1030.17.1) at the arena edge — 42 in from the seatboard where seats are next to the edge, or a 26 in sightline-constrained guard (1030.17.3); 36 in rail at the foot of each stepped aisle (1030.17.4). Where the loop is the cross aisle at the back of the tier: guard per 1015 if the drop is > 30 in, 26 in if ≤ 30 in, none if the seat backs stand ≥ 24 in above the aisle (1030.17.2). The tier section is not drawn, so which applies is TBD (architect).
- Handrails: none required on the level loop; stepped aisles need them (1030.16); stairs need them (1011.11, 1014).

## R-018.6 Event-day cross-flow

Everyone enters at the L1 grand entrance (D-033), so ingress to the upper tier comes up the south stairs / elevator and walks along the loop to the N and E tiers; egress at the end splits to all 4 stairs. Conflicts: training users vs spectators (S4: crossing users are a hazard); S&C / cross-training users stepping out onto the loop; restroom and concession queues on the south leg; spectators stopping at the west rail to watch. Recommendation (operational, not code): the loop is closed to running from doors-open until the building clears; lane markings and crossing marks at tier entries and stair doors; queue space off the loop; no standing / viewing zone inside the 7 ft (or the AHJ may count it, sensitivity b).

## R-018.7 Conclusion (D-038)

QUESTION: Does code require the upper concourse / loop to be wider than 7 ft?

ANSWER: **No, not on this calculation.** At 0.2 in per occupant the loop needs 64 in with balanced use of the 4 stairs (1030.9.2) and 79.2 in in a deliberately unbalanced check; 7 ft = 84 in. All minimum widths (36 / 44 in) are met. **3 lanes (10.5 ft = 126 in) would satisfy it** with 46.8 in to spare and would absorb queues, standing at the rail or an AHJ load increase. The 7 ft works only if it stays **clear** (no columns, guard posts, queues or doors in the lanes; ≤ 4.8 in of projections in the worst case). The loop would need to exceed 84 in only if more than 420 people (84 / 0.2) were assigned to one loop path.

The tighter item is the **stairs**: 4 x 64 in = 255.8 in required, zero slack; if the AHJ counts the loop (a) or rail standing (b), each stair grows to ≈ 68-69 in. Recommendation: no change to the frozen set; carry D-038 OPEN for the architect's egress model and the AHJ (D-008); when the stairs are detailed, size them ≈ 70 in or more (or add capacity), and keep the loop clear.

EDITION / SECTION: IBC 2021 §§1004.5 (Table), 1004.6, 1005.3.1, 1005.3.2, 1005.4, 1005.5, 1005.7.1, 1006.3.3 (Table), 1010.1.2.1, 1015.2-1015.4, 1017.2 (Table), 1020.3 (Table), 1030.5, 1030.6.1, 1030.6.2, 1030.7, 1030.8, 1030.9.1-1030.9.6, 1030.13.2, 1030.16, 1030.17. 2018: 1029.x for the assembly sections (S2, UNVERIFIED).

CONFIDENCE: HIGH for the code factors (2021 text read) / MEDIUM for the 2018 equivalence / LOW for the occupant distribution (tier aisles, vomitories and the tier section are not designed).

NEEDS ARCHITECT CONFIRMATION: YES (occupant load classification, catchments, stair widths, guard types, smoke protection, final egress plan).

## R-018.8 Addendum 2026-10-04 6:45 AM CT — stairs 70 in clear (D-038 CLOSED)

Shane, 6:45 AM CT: "stairs 70 in clear". Recheck with the same factors (IBC 2021 1005.3.1 exc. 1, 0.2 in per occupant):

| Case | Occupants | Required total (x 0.2 in) | Provided 4 x 70 in | Spare |
|---|---|---|---|---|
| Base (R-018.1) | 1,279 | 255.8 in | 280 in | 24.2 in |
| (a) loop counted as exercise room | 1,378 | 275.6 in | 280 in | 4.4 in |
| (b) standing at the west rail | 1,363 | 272.6 in | 280 in | 7.4 in |
| Both (a) + (b) | 1,462 | 292.4 in | 280 in | **−12.4 in** |

- 4 x 70 in serves up to 280 / 0.2 = **1,400** occupants. Both sensitivities together (1,462) would still exceed it; keep standing / viewing off the loop (R-018.6) or the architect adds capacity.
- 1005.5: losing one stair leaves 3 x 70 = 210 in ≥ 50% of 275.6 in = 137.8 in ✓.
- "Clear" is read as the clear width used for capacity; handrails may project up to 4.5 in into the required width on each side (1014.8), so the architect should confirm whether 70 in is measured between walls or between handrails.
- Loop width is unchanged by this (64 in balanced / 79.2 in unbalanced vs 84 in, R-018.3).
- Plan effect (next A-101/A-102 revision, not done — the set is frozen): same switch-back stair (26 risers of 6.92 in, 2 flights of 13, 12 treads x 11 in = 132 in run, 48 in landings, R-015 / phase2_program.yaml): plan 2 x 70 = 140 in (11.67 ft) wide x 19 ft, ≈ 221.7 SF per stair per level vs 205.2 SF drawn (19 x 10.8 ft) → about +16.5 SF per stair per level, ≈ +66 SF footprint and ≈ +132 SF GSF for 4 stairs before gross-up (KEYSTONE arithmetic). [2026-10-04 8:36 AM CT: margin wording removed — there is no 55,000 SF cap, D-056.]

CONFIDENCE: HIGH for the arithmetic / MEDIUM for the inputs (same as R-018.7). NEEDS ARCHITECT CONFIRMATION: YES.

## R-018.9 Addendum 2026-10-04 7:24 AM CT — design to PASS the worst case (D-052 proposed)

Shane, 7:24 AM CT: design to pass the WORST case (loop counted + rail standing), currently 12.4 in short with 4 x 70 in; recommend with numbers. Plans are NOT redrawn (frozen set); this is a proposal for the next A-101/A-102 revision.

Basis: worst case 1,462 occupants (R-018.8). IBC 2021 1005.3.1: 0.3 in per occupant for stairways; exception 1 allows 0.2 in where the building is sprinklered (903.3.1.1) and has an emergency voice/alarm communication system (907.5.2.2) — both are required here (R-015), so 0.2 in governs: **1,462 x 0.2 = 292.4 in**. (Without the exception: 438.6 in = 4 x 110 in — informational only.) Switchback footprint per stair per level (clear, walls excluded) = 2w x (48 floor landing + 132 run + w intermediate landing, 1011.6 / D-051).

**Option W — four wider stairs** (each ≥ 292.4 / 4 = 73.1 in):

| Clear width each | Total | Spare vs 292.4 | Occupants served (÷ 0.2) | SF per stair per level | vs 70 in | vs frozen 205.2 SF |
|---|---|---|---|---|---|---|
| 70 in (now) | 280 in | −12.4 in | 1,400 | 243.06 | — | +37.9 |
| 74 in | 296 in | +3.6 in | 1,480 | 261.06 | +18.0 | +55.9 |
| **76 in** | **304 in** | **+11.6 in** | **1,520** | **270.22** | **+27.2** | **+65.0** |
| 78 in | 312 in | +19.6 in | 1,560 | 279.50 | +36.4 | +74.3 |

- GSF vs 70 in (4 stairs x 2 levels): +144 (74 in), +217.8 (76 in), +291 (78 in). 76 in plan ≈ 12.67 x 21.33 ft.
- 1014.9: all required capacity width within 30 in of a handrail → an intermediate handrail is needed above 60 in (already true at 70 in).
- 1005.5 (lose one stair): 3 x 76 = 228 in ≥ 50% x 292.4 = 146.2 in ✓.

**Option 5 — a fifth exit stair:** at the 44 in minimum (1011.2): total 280 + 44 = 324 in (+31.6 in); footprint 88 x 224 in = 136.9 SF per level ≈ +273.8 GSF, plus a new enclosure, exit door, exit discharge, separation (1007.1.1) and travel-distance checks and a location on the loop. A 5th stair at 70 in: 350 in total, ≈ +486 GSF.

**Option O — operational:** no rail standing on the loop → 1,378 x 0.2 = 275.6 in, passes 4 x 70 in by 4.4 in. Not a worst-case design; relies on management.

**Recommendation:** four stairs at **76 in clear** with intermediate handrails — closes the worst case with 11.6 in (≈ 58 occupants) to spare, keeps 4 cores in the same locations, costs ≈ +218 GSF vs 70 in (≈ +520 GSF vs the frozen plan) — less than a 5th stair's area and none of its new core, door and discharge. Logged as **D-052 (OPEN, proposed)** for Shane; the architect / AHJ confirm the occupant load and the exception.

EDITION / SECTION: IBC 2021 §§1005.3.1 (exc. 1), 1005.5, 1007.1.1, 1011.2, 1011.6, 1014.9, 903.3.1.1, 907.5.2.2 (UpCodes, retrieved 2026-10-04).

CONFIDENCE: HIGH for the arithmetic / MEDIUM for the occupant inputs (R-018.7). NEEDS ARCHITECT CONFIRMATION: YES.

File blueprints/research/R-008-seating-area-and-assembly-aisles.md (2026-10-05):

# R-008 — Spectator seating area for 2,200 seats: SF per seat, assembly aisles, row spacing (Phase 2)

Researched by KEYSTONE 2026-10-03 for P2-T-003b (program test-fit, sheet P2-G-003). All sources retrieved 2026-10-03.
Status: research note for a test-fit. Not a seating layout. Seating type is OPEN (D-009); the 2,200 total is locked (D-016 still OPEN on the plan labels). **PRELIMINARY — CONCEPTUAL DESIGN — NOT FOR CONSTRUCTION.**
Format follows prompt §10. Covers the seating-area part of R-008 (egress). Exit counts, exit widths and travel distance are NOT done yet (later, with R-007 and a plan).

**Code edition note:** Shane said Alabama uses the 2021 IBC. The text below is the 2021 IBC as published on UpCodes ("Alabama Building Code 2021"). **But Madison County's Building Codes page lists the 2018 IBC/IPC** (effective January 2021) for county permits. Phase 2 is a private build (D-028), so the AHJ is probably local and is OPEN (D-008). **Section numbers:** the 2021 IBC puts assembly egress in **Section 1030** (Section 1029 is Egress Courts). The same rules were Section 1029 in the 2018 IBC, which is why "IBC 1029" is commonly quoted.

## Sources
- **S1** — IBC 2021, Chapter 10, as published by UpCodes (Alabama Building Code 2021) — https://up.codes/viewer/alabama/ibc-2021/chapter/10/means-of-egress — retrieved 2026-10-03. PRIMARY (code text via a third-party viewer; codes.iccsafe.org would not render without a login).
- **S2** — Madison County, AL, "Building Codes" — https://www.madisoncountyal.gov/departments/inspection/building-codes — retrieved 2026-10-03. PRIMARY.
- **S3** — Loudoun County, VA, *Capital Facilities Manual* (June 2014), §4.3 Recreation Center standard area requirement — https://www.loudoun.gov/DocumentCenter/View/123942/Attach-2---Pre-Program-Summary?bidId= — retrieved 2026-10-03. PUBLISHED PLANNING STANDARD (another jurisdiction, 2014).
- **S4** — Hussey Seating, *MAXAM Telescopic Systems* brochure — https://husseyseatway.com/wp-content/uploads/2025/03/MAXAM_Brochure.pdf — retrieved 2026-10-03. MANUFACTURER (secondary).
- **S5** — Hussey Seating, ARCAT spec 12 60 00 Telescopic Stands — https://www.arcat.com/specification/hussey-seating-co-33161/12_60_00hsy — retrieved 2026-10-03 (search excerpt). MANUFACTURER (secondary).

---

## R-008.1 — Area per seat for planning (base case)

QUESTION: What area per seat (including aisles) should a test-fit use for 2,200 seats?

ANSWER (one paragraph): **Base case: 6.0 SF per seat.** Loudoun County's recreation-center standard (S3) allots a "Spectator/Team Seating" area of 4,800 SF for its stated seat count, noting "Area can be reduced with use of tip-and-roll bleachers … Elevated seating preferred." 4,800 ÷ that seat count = **6.0 SF/seat** (arithmetic from S3). For 2,200 seats: 2,200 × 6.0 = **13,200 SF**. (S3's seat count is not repeated in params because that number collides with a superseded concept number blocked by validate.py; it is a different project.) No US building code gives an area per seat; codes control aisle and row widths (R-008.2).

SOURCE: S3.

EDITION / SECTION: Loudoun County Capital Facilities Manual, June 2014, §4.3 Recreation Center, "Program Space — Spectator/Team Seating".

CONFIDENCE: MEDIUM (a published public planning standard, but for a natatorium seating area in 2014, not an arena).

NEEDS ARCHITECT CONFIRMATION: YES.

---

## R-008.2 — Code limits that set the seating geometry (IBC 2021)

QUESTION: Which code rules set row spacing, row length and aisle widths?

ANSWER (one paragraph): From S1 (IBC 2021):
- **1004.6 Fixed seating:** occupant load = number of fixed seats; "For areas having fixed seating without dividing arms, the occupant load shall be not less than the number of seats based on one person for each **18 inches** … of seating length."
- **1030.1.1 Bleachers:** bleachers, grandstands and folding/telescopic seating that are not building elements "shall comply with **ICC 300**." (ICC 300 not read; paywalled.)
- **1030.1.1.1:** spaces under grandstands or bleachers need 1-hour fire barriers, except ticket booths under 100 SF, toilet rooms, and other accessory areas of 1,000 SF or less with sprinklers. (Matters for DR3 rooms "under the bowl".)
- **1030.9.1 Minimum aisle width:** **48 in** for stepped aisles with seating on both sides (36 in if serving fewer than 50 seats); 36 in with seating on one side; 42 in for level/ramped aisles with seating on both sides.
- **1030.13.2 Aisle accessways:** rows of 14 or fewer seats need at least **12 in** clear between the back of one row and the nearest projection of the row behind.
- **1030.13.2.1 Dual access:** with aisles at both ends, max **100 seats per row**; the 12 in minimum grows 0.3 in per seat beyond **14 seats (with backrests)** or **21 seats (without backrests)**, up to 22 in.
- **1030.6.1 Aisle capacity (no smoke protection):** 0.3 in per occupant on stepped aisles (risers ≤ 7 in, treads ≥ 11 in); 0.2 in per occupant on level or ramped aisles ≤ 1:12.
- **1030.8 Common path:** 30 ft max from any seat to a choice of two paths (50 ft smoke-protected).

SOURCE: S1.

EDITION / SECTION: IBC 2021 §§1004.6, 1030.1.1, 1030.1.1.1, 1030.6.1, 1030.8, 1030.9.1, 1030.13.2, 1030.13.2.1. (2018 IBC: same rules numbered 1029.x — not re-checked line by line.)

CONFIDENCE: HIGH for the 2021 text. MEDIUM that the AHJ will use 2021 (S2 says 2018 for the county).

NEEDS ARCHITECT CONFIRMATION: YES.

---

## R-008.3 — Lean check: telescopic-bleacher geometry

QUESTION: What is the smallest area per seat the cited dimensions support?

ANSWER (one paragraph): **3.38 SF/seat (KEYSTONE arithmetic from cited dimensions).** Hussey's MAXAM telescopic system offers standard row spacing of "22” (559 mm), 24” (610 mm), and 26” (660 mm)" (S4); its spec bases net capacity on 18 in per seat (S5), matching IBC 1004.6. Using **24 in rows × 18 in per person = 3.0 SF**, plus one **48 in** stepped aisle (1030.9.1) per block of **21 seats** (bleachers without backrests can run 21 seats before the 12 in accessway must widen, 1030.13.2.1): 3.0 × (21 × 18 + 48) ÷ (21 × 18) = **3.38 SF/seat** → 2,200 × 3.38 ≈ **7,440 SF**. Left out: front walkway, cross aisles, vomitories, wheelchair spaces and companion seats (R-010 not done), rail and end clearances. So the true figure lies above 3.38. Fixed chairs with backrests would be larger (wider seats, deeper rows, 14-seat blocks).

SOURCE: S4, S5, S1.

EDITION / SECTION: Hussey MAXAM brochure (row spacing); IBC 2021 1004.6, 1030.9.1, 1030.13.2.1.

CONFIDENCE: MEDIUM (the arithmetic is exact; it is a lower bound, not a layout).

NEEDS ARCHITECT CONFIRMATION: YES.

---

## Gaps and conflicts
1. Code edition: 2021 (Shane; UpCodes Alabama) vs 2018 (Madison County page). AHJ OPEN (D-008). R-006 not done.
2. ICC 300 (bleachers) not read (paywalled).
3. Wheelchair seating counts and dispersion (2010 ADA 221 / IBC 1108) not done → R-010.
4. Exit count, exit widths, travel distance, main-exit rule (1030.2) not applied: they need a plan (later R-008 sections).
5. The base 6.0 SF/seat comes from one 2014 county standard for a different venue type. A sports-venue planning guide (e.g. NIRSA, Sawyer's *Facility Planning*) would be better; those are paid books and were not obtained.

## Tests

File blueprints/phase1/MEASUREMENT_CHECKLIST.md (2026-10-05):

# Phase 1 Measure + Photo Checklist (P1-T-002)

For: Shane, in the wrestling room with a tape and your phone.
Write everything in feet-inches (example: 32'-6"). If you can't get something, write "skip" and move on.
Tip: sketch a box for each room on paper, mark north if you know it, and put the numbers on the sketch. Then snap a photo of the sketch.

## A. Wrestling room
1. Length, wall to wall (long way).
2. Width, wall to wall (short way).
3. Ceiling height (floor to ceiling, or to the bottom of beams if it's open).
4. Each door: which wall, distance from the nearest corner, door width, and which way it swings (in/out, hinge left/right).
5. Each window: which wall, width, height, and height of the sill off the floor.
6. Anything on the walls that pads would cover: outlets, light switches, thermostats, fire alarms, fire extinguishers, vents. For each: which wall, distance from the corner, height off the floor.
7. Wall material (block, drywall, metal, brick, other). Knock on it.
8. Existing wall pads, if any: which walls, height off the floor to the top of the pad, thickness, and condition.

## B. Walk-through room (route to the training room)
9. Length and width.
10. Ceiling height.
11. Layout: where every door is and which rooms they lead to (wrestling room, training room, hallway, outside).

## C. Restrooms + plumbing
12. Existing restroom fixtures anywhere nearby: count the toilets, urinals, sinks, showers, and floor drains, and note where each one is.
13. Where leaks or water damage show: stains, wet spots, soft floor, rust, mold. Which room and which wall.
14. Where water lines or drain pipes show: exposed pipes, cleanouts, shutoff valves, floor drains.

## D. Photos (straight on, room lights on)
15. Each wall of the wrestling room, straight on (4 photos).
16. Each corner of the wrestling room.
17. The ceiling.
18. Each wall of the walk-through room, plus each of its doors.
19. Every existing restroom fixture.
20. Every leak or water-damage spot, close up, with something in the shot for scale (tape, a hand, a shoe).
21. Any exposed pipes, valves, or drains.
22. Your paper sketch with the numbers on it.

Send photos + numbers back however is easiest. KEYSTONE turns them into the existing-conditions plan (P1-A-101).

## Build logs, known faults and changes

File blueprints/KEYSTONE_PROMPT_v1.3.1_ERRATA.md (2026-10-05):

## v1.3.1 ERRATA — Section 3 LOCKED FACTS (Shane, 2026-10-04; supersedes conflicting v1.3 text)
Today's decisions win over v1.3 text (D-055). Source tags in brackets.

E-1  SIZE: There is NO 55,000 SF cap — not footprint, not total. 55,000 SF was an early rough estimate, not a limit. D-031 retired. Size is controlled by budget and parcel. [D-056; D-055 cap clause superseded]
E-2  AREA TABLES: every area table reports L1 footprint, L2 area, TOTAL GSF, and change vs the last revision. No "margin" / "under the cap" lines in future revisions (frozen sheets unchanged). [D-057]
E-3  EXIT STAIRS: 4 stairs, 76 in clear, intermediate handrails; switchback intermediate landing >= stair width (= 76 in), floor landings 48 in; ~12.67 ft x 21.33 ft per stair per level. Worst-case L2 egress 304 in vs 292.4 in required (~11.6 in spare). Applies at the next A-101/A-102/A-301 revision. [D-052, D-051; IBC 2021 1005.3.1, 1011.6]
E-4  GRAND ENTRANCE PORTAL: freestanding over the Champion Walk; overall height <= 50 ft (arena roof 42 ft); arch crown 34 ft; springline 22.1 ft (ASSUMED, proportional; semi-elliptical arch); official mark badge 11 ft diameter (34.4-45.4 ft above grade) + wordmark (baseline 46.1 ft), all inside 50 ft. [D-050, D-047, D-043]
E-5  PORTAL COLORS: arch underside crimson, gold trim. [D-045]
E-6  CHAMPION WALK: brick, 28 ft wide x 30 ft long (portal to the E1 doors) = 840 SF; donor-brick tiers 4x8 = single name, 8x8 = family / business; donor pricing OPEN. [D-046; D-044]
E-7  UPPER TIER: fixed upper tier steps DOWN from the L2 loop toward the court. Under its low front edge: telescopic stack, storage, mechanical; lockers only where headroom is full. [D-049]
E-8  SIGHT LINES: upper-tier risers 19 in (front row 7.08 ft); east seats 6 ft further from the mats (east clear 10 -> 16 ft, +1,512 SF L1 footprint). Applies at the next A-101/A-102/A-301 revision. [D-053; R-020]
E-9  SERVICE / BUSES: service and deliveries at north door S1 (staff-controlled, not a people entrance); bus drop = south loop offset east or west so it does not block the portal view. [D-034]
E-10 ARCH PHOTO: D-048 CLOSED — the arch reference photo is Shane's own image; held off-repo by choice (no history rewrite). [D-048]
E-11 CURRENT SHEET REVISIONS: Phase 2 — P2-G-003 Rev F, P2-A-101 Rev D, P2-A-102 Rev D (G-003 F + A-101 D + A-102 D = Phase 2 Schematic Set Rev A, frozen), P2-A-201 Rev D, P2-A-301 Rev B, P2-A-302 Rev A, P2-C-101 Rev A. Phase 1 — P1-G-001 Rev D, P1-A-101 Rev A, P1-P-001 Rev A. Older revisions are frozen history. [STATUS 2026-10-04]

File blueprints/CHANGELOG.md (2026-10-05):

# CHANGELOG — KEYSTONE

## 2026-10-04 ~6:10 AM CT · P1-T-008 · P1-P-001 Rev A plumbing / water restore scope narrative
- **Unblocked Phase 1 ticket** taken ahead of P2-T-009 A-301 (Phase 1 outranks; P1-T-005…007 still wait on Dr. Headen / support-wing measurements).
- **params/phase1.yaml:** structured `existing.plumbing` fields for the sheet — `fixture_inventory.items` (2 showers, 1 private toilet, 2 toilets, 1 urinal, sinks TBD, 1 water fountain/sink; all OOS), `scope_of_work.items`, `open_asks.items`, `licensed_trade` (note + R-004.3 cite), `cross_refs` to frozen P1-G-001 Rev D / P1-A-101 Rev A package. New `sheets.P1-P-001` register (Rev A). Every group sourced; no invented pipe sizes or costs. D-002 stays OPEN.
- **New sheet** `phase1/out/{pdf,dxf}/P1-P-001_RevA` from new `phase1/src/p1_p_001.py` (11x17 landscape, NTS): existing-condition narrative, fixture inventory table, scope-of-work bullets (diagnose / restore / repair as plumber directs — NOT design), BY LICENSED PLUMBER / ENGINEER OF RECORD callout (Ala. Code §§34-37-6(a), 34-37-15 via R-004.3), open asks, cross-refs. PRELIMINARY stamp + title block via shared/titleblock.py. Drawn by KEYSTONE (AI) for Shane Brazelton.
- Preview (box only): `/workspace/keystone_previews/P1-P-001.png`.
- Frozen P1-G-001 Revs A–D and P1-A-101 Rev A untouched. Phase 2 Schematic Set Rev A untouched.
- BACKLOG: P1-T-008 done. Next: resume P2-T-009 (A-301) or P2-T-007; Phase 1 jumps when data arrives.
- DECISIONS: no new decisions; D-002 remains OPEN until plumber visit + photos.
- ASSETS + STATUS updated.

## 2026-10-03 · P1-T-000 · bootstrap blueprints/
- Environment check recorded in ENVIRONMENT.md. KEYSTONE runs on a separate Linux box, not pulsar00100. Python 3.13.5, git 2.47.3, no FreeCAD. Venv `/workspace/.venv-keystone`: ezdxf, matplotlib, numpy, pillow, pyyaml, cadquery 2.8.0 all installed.
- Cloned repo. Created branch `grok/keystone` from `main` @ 8a2f4c6.
- Created the `blueprints/` tree per prompt §7: README, STATUS.json/.md, DECISIONS (15 OPEN), BACKLOG (§15 verbatim), CHANGELOG, PARKING_LOT (Mercedes-Benz items parked), ENVIRONMENT. Empty dirs hold .gitkeep.
- NOT done: `ARENA\_KEYSTONE` on pulsar00100 (no access, by instruction). GitHub mirror is the bridge.

## 2026-10-03 · P1-T-001 · asset inventory + phase1.yaml v1
- ASSETS.md covers:
  - Shane's ARENA folder (4 files). The diorama HTML is the Phase 2 viewer, the same file as the repo's `hazel-green-complex-3d.html`.
  - Missing items: master floor plan image (needed from Shane), `/model.html` location unknown, Drive trailers not inspected.
  - Repo root: the Feb 2026 concept files are marked superseded.
- `params/phase1.yaml` v1: every value sourced, every unknown TBD. Principal = "TBD (Headen or Hedden, unconfirmed)".
- `shared/validate.py` v1 checks:
  - yaml parses
  - `source` on every value group
  - no superseded numbers and no Phase 2 numbers in phase1
  - PDF stamp (vacuous pass, no PDFs yet)
  - STATUS.json schema + open-decision count
  Passes. Negative test confirmed it fails on bad input.
- `phase1/MEASUREMENT_CHECKLIST.md`: 22-step tape + photo checklist for Shane (P1-T-002 content, not yet sent).
- STATUS → P1-T-002, YELLOW, waiting on measurements. Sign-off commit sets STATUS.json last_commit = 235125d (P1-T-001 commit).

## 2026-10-03 17:01 CT
- P1-T-002: checklist sent to Shane in chat. Daily 6:00 AM CT scheduled run created. STATUS -> P1-T-003.

## 2026-10-03 ~5:50 PM CT · P2-T-001 (seed only) · reference plan intake + phase2.yaml v1 seed
- Shane added 2 images to ARENA. **Phase 2 REFERENCE PLAN = `Phase2-floor-plan-flat.png`** (= `arenav1-floor-plan.png`, sha256 d030dcb4…bd54), designated by Shane (D-017 DECIDED). The diorama is demoted to secondary. `Phase2-floor-plan.jpeg` is the tabletop render (WebP inside a .jpeg name), with wrong labels. Not a source.
- ASSETS.md:
  - folder now 7 files
  - §1b describes the reference plan's zones/adjacencies and observations (no event lockers or mezzanine shown yet; 2 public restrooms)
  - §2 master plan → RECEIVED
  - §2a: the box's `floorplan_src.png` (39467dab…) is a re-encode of the tabletop render, still unused
- `params/phase2.yaml` v1 seed:
  - prompt §3 Phase 2 table + reference plan
  - seating 2,200 total locked
  - girls 3,503 tag with D-013 draw-equal rule
  - 9 support rooms "shown on reference plan, SF TBD"
  - no dimensions
- `shared/validate.py` v2:
  - parses phase2.yaml with the same source/superseded checks
  - blocks Phase 1 values in phase2.yaml
  - checks locked Phase 2 values
  - area reconciliation SKIPPED until SFs exist
  Passes. Negative test confirmed it fails on bad input.
- DECISIONS: D-016 OPEN (seating labels 3,200 vs 2,200). D-017 DECIDED. D-009 now points to D-016. 16 OPEN.
- BACKLOG: P2-T-001 marked "v1 seeded… Phase 1 still first." Active ticket stays **P1-T-003**.

## 2026-10-03 17:53 CT
- D-018 logged (solar + stormwater per MOVIE MAKER brief; stays parked). Look reference: /workspace/trojan-horse-arena/ (MOVIE MAKER, read-only).

## 2026-10-03 17:57 CT
- CHANGE APPROVED (Shane): solar + stormwater storage into Phase 2 as design intent, unsized. Retractable roof CUT. D-018 DECIDED. phase2.yaml `sustainability` added.

## 2026-10-03 · P1-T-003 · R-001 wall pads + R-003 ADA single-user restroom
- `research/R-001-wall-pads.md`:
  - NFHS guidance (HST 2022): about 6 ft high, 2 in pads, recessed door hardware.
  - The NFHS rules book is paywalled, so no NFHS *rule* on practice-room pads was verified.
  - IBC 2021 806.2 makes pads interior finish. 803.4 → 2603.9 means foam pads need a large-scale test of the finished assembly (NFPA 286 or equal). Table 803.13 room minimum is Class C, but the foam rule governs.
  - Alabama DCM adopts the 2021 IBC/IEBC/IFC for K-12.
  - Flag: some common pads are "foam core not fire-rated" or E84-only.
- `research/R-003-ada-single-user-restroom.md`:
  - 2010 ADA governs (Title II alteration; DCM says ADA supersedes IBC/A117.1).
  - Key-numbers table with section cites: 304, 305/306, 404, 603, 604, 606, 609, 703.
  - Flags: 213.2 Exc. 4 read conservatively (both rooms comply); path of travel may be triggered.
- `params/phase1.yaml`: new `standards` group (governing codes, wall_pads, ada_single_user_restroom), with `source: R-001` / `R-003`. Reference values only. No room dimensions. W1/W3 still TBD.
- BACKLOG: P1-T-003 done, P1-T-004 next. STATUS → P1-T-004, P1 10%, YELLOW, waiting on measurements.

## 2026-10-03 · R-001/R-003 approval: decisions recorded
- D-019 DECIDED (Shane, chat): full 2010 ADA compliance on BOTH new restrooms. This settles the 213.2 Exc. 4 question. phase1.yaml W3 `ada_compliance`, `restroom_type: single-user, one per sex`, `both_rooms_comply: YES`.
- D-020 DECIDED (Shane, chat): the scope sheet carries the NFPA 286 note verbatim. phase1.yaml W1 `purchase_note`.
- D-003 stays OPEN. Shane returned the pad-height template unfilled ("coach's call"). `pad_height: TBD`, with a note and sheet label "6 ft proposed (R-001 guidance), coach to confirm".
- Open decisions: 16, unchanged.

## 2026-10-03 · P1-T-004 · P1-G-001 scope sheet v1 (rev A)
- New `shared/titleblock.py`: one layout model renders to both a vector PDF (matplotlib, embedded searchable TrueType) and a DXF (ezdxf, inches). It draws the standard border, the PRELIMINARY stamp band and the title block (prompt §9).
- New `phase1/src/p1_g_001.py`: 11x17 landscape scope sheet built from phase1.yaml.
  - Work items W1, W2 and W3. W3 includes a 14-row 2010 ADA key-number table with section cites.
  - Sections: NOT INCLUDED, WHO APPROVES (draft/TBD), WAITING ON, and 2 "PHOTOS TBD" boxes.
  - The Phase 2 total is read from phase2.yaml for the NOT INCLUDED line.
  - The script exits non-zero if text runs past any box.
- Outputs: `phase1/out/pdf/P1-G-001.pdf`, `phase1/out/dxf/P1-G-001.dxf` (layers G-ANNO-TTLB, A-ANNO-TEXT). PNG preview kept outside the repo at /workspace/keystone_previews/P1-G-001.png.
- phase1.yaml additions:
  - `sheets.P1-G-001`: title block data, waiting_on, photo boxes
  - `approvals.chain_shown` / `research_pending`
  - `standards.wall_pads.sheet_basis`
  - `standards.ada_single_user_restroom.cites`
  - W1 `supplied_by_options`
  - No room dimensions added.
- Validate: the PDF stamp check is now non-vacuous and passes.

## 2026-10-03 · D-003 decided + P1-G-001 Rev B (principal version)
- D-003 DECIDED (Shane, chat): pad height 6 ft. phase1.yaml W1 `pad_height: 6 ft`.
- The unsettled parts of D-003 (which walls get pads, who supplies them) moved to new **D-021 OPEN**. Open count stays 16.
- **Rev A = INTERNAL copy, frozen.** Files renamed with `git mv`, bytes unchanged:
  - `phase1/out/pdf/P1-G-001_RevA_internal.pdf` (sha256 bfcffb05…)
  - `phase1/out/dxf/P1-G-001_RevA_internal.dxf` (sha256 31a36c02…)
- Rev A content is frozen in phase1.yaml `sheets.P1-G-001.revisions.A`.
- Reproducibility check: `p1_g_001.py --rev A --out-dir /tmp/…` gives identical PDF text, identical DXF entity text and geometry, and identical rendered pixels. The generator refuses to overwrite a frozen revision in the repo without `--force`.
- **Rev B = PRINCIPAL version:** `phase1/out/pdf/P1-G-001_RevB_principal.pdf` + `phase1/out/dxf/P1-G-001_RevB_principal.dxf`, built from `revisions.B`. Changes from Rev A:
  - No D-/R- codes and no name-spelling lines. IBC and ADA section numbers stay.
  - Requester line under the title.
  - W1 and W2 each get a "Why:" line.
  - Pad height prints "6 ft".
  - "WHAT WE'RE ASKING THE SCHOOL FOR" (3 asks) replaces WAITING ON.
  - WHO APPROVES reads: Principal / District facilities (Madison County Schools) / Others as the district requires.
  - Title block shows rev B.
- New phase1.yaml fields, sourced "Shane 2026-10-03": `contacts.requester`, W1/W2 `why`, `approvals.chain_plain`, `standards.wall_pads.sheet_basis_plain`.
- `shared/titleblock.py`: the PDF CreationDate is no longer stamped, so later builds can be reproduced exactly.
- `shared/validate.py` adds check 6b: every `*principal*.pdf` must contain no `D-0`/`R-0` codes and no "spelling". Tested against the Rev A text, it catches 9 codes plus "spelling".

## 2026-10-03 · P1-T-009 · R-002 approval path + R-004 donated labor/materials
- `research/R-002-approval-path.md`:
  - DCM says all public K-12 work gets DCM plan review, a pre-construction conference and inspections, at any cost and from any funding source, donations included. DCM fees are waived at or below $750k. DCM's own "Step 1" verifies each small scope.
  - The MCSS Booster & Support Organizations Guidelines (2021 file) say: campus building/land improvements go to the Board of Education; a Board employee is in charge; full design team; state review and inspection; "same process regardless of funding."
  - District facilities office: MCSS Operations & Facilities.
  - Gap: MCSS board policy (Simbli) was not readable.
- `research/R-004-donated-labor-materials.md`:
  - Public works sealed bids above $100,000 (§39-2-2). School-board purchases $40,000+ (§16-13B-1, per Examiners Feb 2025).
  - AG opinions (via Examiners): work paid entirely with private funds is not "public works" for bid law. None involve a school board.
  - GC license at $100,000+ (Act 2024-277).
  - Plumbing (§34-37-15) and electrical (303-X-3-.07) licenses required except owner / owner-employee exemptions. Volunteers are not addressed.
  - Bonds not required under $100,000. Insurance: DCM tells self-performing owners to consult their carrier.
  - Every finding is flagged NEEDS DISTRICT CONFIRMATION. No legal advice.
- phase1.yaml: `approvals.chain_per_sources`, `approvals.district_facilities_office`, `approvals.note_plain`, `standards.approvals_refs` (sources R-002 / R-004). Rev B approver line 2 is now "District facilities (MCSS Operations & Facilities)".
- P1-G-001 Rev B regenerated:
  - WHO APPROVES adds a plain note: "District guidelines send campus building improvements to the Board of Education. State building review (Alabama DCM) may also apply."
  - Row-2 widths changed for Rev B, and long box headings now shrink to fit.
- **Rev A unchanged.** Regenerating to /tmp still gives identical text. It stays frozen as the internal copy, so its "Who approves" was not edited, even though the R-files are in.
- D-004 notes updated; still OPEN. DECISIONS open count: 16.

## 2026-10-03 20:49 CT
- D-023 DECIDED: Rev B approved as-is, contact info stays, no history rewrite. D-022 OPEN: 1A/1B split, no restructure until Shane decides.

## 2026-10-03 ~10:00 PM CT · W2 no-water update + P1-G-001 Rev C
- **Shane, firsthand 2026-10-03:**
  - There is no running water to the area. All fixtures (showers, toilets, sinks) are out of service, not just leaking. Cause unknown.
  - phase1.yaml W2 is renamed "Restore water / plumbing repair". New fields: `status` (exact text), `status_detail`, `cause: TBD`, and a new `scope` and `why`. It is still BY LICENSED PLUMBER / ENGINEER OF RECORD, narrative only.
  - `existing.plumbing.condition` is updated; the old wording is kept as `condition_before_2026_10_03`.
- **D-024 DECIDED:** priority is W2 → W3 → W1, and W1 (pads) can run in parallel. Each work item now has a `priority` field.
- **Shane's aerial sketch** (`wrestle-room-measure.png`, not committed) → `existing.wrestling_room.estimate_aerial`:
  - KEYSTONE estimate of the exterior roof footprint: ≈55 ft N-S × 47 ft E-W.
  - Basis: path 276.85 ft, 7.49 px/ft, cross-checked against the 5 ft ticks and the 50/150/250 ft labels.
  - Confidence LOW. Length and width stay TBD. Never drawn.
- **`existing.layout_notes`:** qualitative room layout from the markup. ASSETS.md §1c and its table now show the folder at 8 files.
- DECISIONS: D-001 notes partial info (estimate + layout; tape + photos still needed). D-002 notes the no-water finding. Open count stays 17.
- **P1-G-001 Rev C (principal) added:** `phase1/out/pdf/P1-G-001_RevC_principal.pdf` + `.dxf`. It is Rev B plus these changes:
  - Panels are ordered W2, W3, W1, with "PRIORITY 1 / 2 / 3 — CAN RUN IN PARALLEL" labels. W1 also says "Does not depend on water."
  - The W2 panel shows the no-water status box, the new scope line and Why, and the licensed-plumber callout.
  - The asks list adds #4, a plumber visit to diagnose the missing water.
  - Row-1 text is slightly smaller (9.6 pt body, 8.4 pt ADA table) so the priority lines fit. Layout changed, content did not.
  - No codes. No aerial estimate.
- **Rev B frozen** (`frozen: true`) and its committed PDF is untouched. Regenerating it to /tmp gives a byte-identical PDF (sha256 6c05e8df…).
  - Rev A regenerates to the same PDF as before the change, with identical text.
  - Frozen revisions read their W2 wording from a `w2_as_issued` snapshot.
- Generator: `--rev A|B|C` (default C). It refuses to overwrite frozen A/B files without `--force`.
  - validate 6b already checks every `*principal*.pdf` (B and C); only the docstring was updated.
- D-022 is still OPEN. No 1A/1B restructure.

## 2026-10-03 ~10:30 PM CT · tape measurement, W2 fill-ins, P1-G-001 Rev D, P1-A-101 Rev A started
- **Wrestling room taped by Shane** ("Shane tape, inside wall-to-wall, 2026-10-03"): 55'-0" N-S × 45'-0" E-W, rectangle, long side N-S.
  - Recorded as `existing.wrestling_room.length_ft: 55` / `width_ft: 45`, with shape, long_side, and measured_at.
  - `floor_area_sf_calc: 2475` is calculated by KEYSTONE.
  - `estimate_aerial` is kept as a cross-check only and notes the agreement (55.1 × 46.9 ft exterior).
- **W2 fill-ins (Shane, firsthand):**
  - Fixtures: 2 showers, 1 private toilet, 2 toilets, 1 urinal, sinks (count TBD), water fountain/sink. All are out of service, with no running water.
  - Problem spots: the entire support wing. The showers were broken before the water loss.
  - Where: the support wing east of the wrestling room, along the open hallway.
- **W1 `pad_estimate` (Shane's estimate):** ~200 LF, ~1,200 SF at 6 ft, ~100 panels of 2×6 ft, before door deductions (3 exits + 1 hallway door). It assumes all 4 walls. KEYSTONE checked the math: 2(55+45) = 200; 200 × 6 = 1,200; 1,200 / 12 = 100. Walls stay TBD (D-021 OPEN). Pad thickness stays TBD.
- **P1-G-001 Rev D (principal)** = Rev C plus:
  - W2 Where / Problem spots / Existing fixtures filled in.
  - A W1 "Estimate:" line.
  - Rev D layout only: panel widths W2 .325 / W3 .36 / W1 .315, 9.2 pt body, ADA table columns widened. Content unchanged.
  - Outputs: `out/pdf/P1-G-001_RevD_principal.pdf` + `.dxf`. Default `--rev` is now D.
  - Shane's single-file copy: `/workspace/keystone_previews/P1-G-001.pdf`.
- **Rev C is now frozen** too. Revs A, B, and C print W2 from their `w2_as_issued` snapshots. Regenerating A/B/C to /tmp gives PDFs identical to before (B and C byte-identical to the committed files).
- **P1-A-101 Rev A (new, `phase1/src/p1_a_101.py`):** existing conditions plan at 1/8" = 1'-0". The 1/4" and 3/16" scales do not fit 55 ft on the 11x17 body.
  - Inside-face rectangle with overall dimension strings.
  - Four door marks tagged APPROX. (west, south, NE exits + east hallway door), with no dimensioned locations or widths.
  - Wall thickness TBD (single line at the inside face).
  - Support wing as a dashed, undimensioned "NOT YET MEASURED" outline.
  - Also: north arrow (approx.), graphic scale, notes, legend, PRELIMINARY stamp.
  - Outputs: `out/pdf/P1-A-101_RevA.pdf` + `out/dxf/P1-A-101_RevA.dxf` (paper inches; 1 in = 8 ft).
- shared/titleblock.py: optional `dashed()` lines, an optional text rotation (stored only when used), and extra DXF layers added only when a sheet uses them. Existing sheets render unchanged.
- DECISIONS: D-001 (room measured; wing, doors, ceiling, and photos TBD), D-002 (fixtures and spots), and D-021 (the estimate assumes all 4 walls). All still OPEN; the count stays 17. ASSETS §1c notes the tape and the door reads. BACKLOG: P1-T-005 IN PROGRESS.

## 2026-10-03 ~10:45 PM CT · Shane update 10:12 PM: Dr. Headen, CLG 10 ft, CMU, doors · Rev D + P1-A-101 Rev A revised in place
- **D-005 DECIDED:** the principal is "Dr. Headen" (phase1.yaml `contacts.principal.name/display_name`). Open count goes to 16.
- **phase1.yaml `existing.wrestling_room`:**
  - `ceiling_ft: 10` (Shane, firsthand)
  - wall_material CMU
  - `wall_thickness_assumed_in: 8` (ASSUMED; actual thickness stays TBD)
  - `door_assumed` 3'-0" × 7'-0" single HM, "ASSUMED STANDARD, VERIFY", including the south-exit pair note
- **W1 `pad_estimate` replaced** (Shane's estimate): ~188 LF after 4 doors (200 − 4×3), ~94 panels (188×6/12), 6'-0" pads under a 10'-0" ceiling, assumes all 4 walls. `pad_area_sf_calc: 1128` is a KEYSTONE calc and is not on the sheet. The earlier estimate is recorded as superseded.
- **W3 `location`:** support wing (waiting on support wing measurements).
- **P1-G-001 Rev D revised in place** (it had not been shown to Shane; no Rev E):
  - "For review by: Dr. Headen (principal) + district facilities".
  - WHO APPROVES 1 reads "Principal (Dr. Headen)".
  - Ask 1 now covers the support wing + walk-through room. New ask 5: "Copies of the photos Dr. Headen took".
  - W3 Where: "Support wing — waiting on support wing measurements."
  - New W1 Estimate line.
  - Asks text is 10 pt to fit five items.
- **Frozen revs:** the snapshot key is renamed `as_issued` (W2 + W3 Where). Regenerating A/B/C to /tmp gives identical PDFs (B and C byte-identical to the committed files).
- **P1-A-101 Rev A revised in place:**
  - Walls are 8" CMU double lines OUTSIDE the tape inside face. The dimension strings are marked INSIDE.
  - Four 3'-0" door openings with jambs, leaves, and 90° swings. Outward swing and hinge side are ASSUMED. Each is tagged "LOCATION APPROX." + "3'-0" × 7'-0" HM — ASSUMED STANDARD, VERIFY". The south tag adds "May be a pair of doors (markup) — verify".
  - New tags: CLG 10'-0" and "WALLS: 8" CMU — ASSUMED".
  - Notes (9) and legend are updated.
- Single-file copies for Shane: `/workspace/keystone_previews/P1-G-001.pdf` (Rev D) and `/workspace/keystone_previews/P1-A-101.pdf`.

## 2026-10-03 ~10:40 PM CT · approvals + Phase 1 package + P2-T-003 (R-005)
- Shane (10:29 PM CT): "P1-A-101 Rev A and P1-G-001 Rev D approved." **D-025** (Rev D approved, frozen) and **D-026** (A-101 Rev A approved, frozen; door locations match his markup; exits swing out) logged as DECIDED. Open count unchanged at 16.
- `params/phase1.yaml`: P1-G-001 Rev D and P1-A-101 Rev A set `frozen: true`. Both generators refuse to overwrite without `--force` (checked). `door_assumed` gets the confirmation note: "locations confirmed by Shane vs markup 2026-10-03; exit swings out confirmed; hallway door swing + south exit single/pair still to verify." Hallway swing + south exit leaves stay ASSUMED, verify. **No sheet regenerated**; /tmp regen of Rev B/C/D and A-101 Rev A is byte-identical to the committed files.
- New `phase1/out/pdf/Phase1_Package_for_Dr_Headen.pdf` (copy in `/workspace/keystone_previews/`): G-001 Rev D then A-101 Rev A via `pdfunite`. Checks: 2 pages, both 1224 × 792 pt (11x17 landscape), stamp on both pages, no D-0/R-0 codes, no "spelling".
- `shared/validate.py` check 6b now also covers `*Package*.pdf` (principal-facing bundles).
- **P2-T-003 started:** `research/R-005-nfhs-wrestling-mats.md`. NFHS Rule 2-1: 28-ft min circle + ~5-ft safety area (38 ft square by arithmetic), 1-in PVC foam equivalent to 4 in max, 10-ft surrounding space and benches/table 10 ft where facilities permit; no padding rule found; AHSAA uses NFHS rules, nothing extra found. Current rulebook paywalled → current wording UNVERIFIED. Arithmetic: 4 mats fit 22,000 SF by area in all cases checked; real fit needs room dims. D-014 stays OPEN; phase2.yaml untouched.
- BACKLOG / ASSETS updated.

## 2026-10-03 ~11:30 PM CT · Phase 2 ACTIVE · P2-T-003b program test-fit (P2-G-003 Rev A)
- Shane (10:45 PM CT): Phase 2 active in parallel (**D-027** DECIDED); Phase 1 package delivered, Phase 1 waits on Dr. Headen, Phase 1 tickets jump the line when data arrives. Phase 2 is Shane's build, not a school project (**D-028** DECIDED). Owner of record stays OPEN: **D-007** reworded to Shane / Hazel Green Trojan Youth Wrestling / partnership. Mats **42' × 42'** (**D-014** DECIDED). Design events home duals + AHSAA/regional tournaments (**D-029** DECIDED). New **D-030** OPEN (test-fit direction). Open count 16.
- `params/phase2.yaml` v2: meta (active, Shane's build, location site TBD, sheet date, drawn by), `spaces.arena.mat_size` 42 ft x 42 ft + `design_events`, `open_items.owner_of_record` and `program_fit`, `sheets.P2-G-003`, courts source → R-012. **Nothing school-derived was found in phase2.yaml to remove** (no school ownership, district approval, DCM/school review, school bidding or principal entries existed). Locked values (55,000 / 22,000 / 4 mats / 2,200 / 5 tags) unchanged.
- New `params/phase2_program.yaml` (test-fit factors + room list, all sourced), `phase2/src/p2_testfit.py` (arithmetic), `phase2/src/p2_g_003.py` (sheet). Output `phase2/out/pdf/P2-G-003_RevA.pdf` + `.dxf`, tabloid landscape, 1 page, 1224 × 792 pt, stamp present; previews `/workspace/keystone_previews/P2-G-003.{png,pdf}` (visually checked, no overlaps).
- **Result:** net program 64,568 SF + mechanical (5% of gross) → **≈ 86,100 GSF (base, gross-up 1.25)** vs 55,000 → **does not fit** (over ≈ 31,100). Lean check (telescopic seating 3.38 SF/seat, gross-up 1.15): ≈ 71,800 GSF, still over ≈ 16,800. The 5 tagged spaces alone gross to ≈ 52,000.
  - A) grow to ≈ 86,100 GSF (lean ≈ 71,800).
  - B) event floor 114 × 126 ft = 14,364 SF (4 × 42' mats 2×2, 10 ft around/between, 6 ft table strips ASSUMED; 84×50 court + 10 ft runout fits) → ≈ 75,800 GSF (lean ≈ 62,300): still over.
  - C) cutting seats alone cannot fit (0 seats → ≈ 61,200 GSF; lean ≈ 56,000). B + C: ≈ 360 seats (base) / ≈ 1,190 (lean).
- Research: **R-008** seating area + IBC 2021 assembly aisles (note: 2021 IBC numbers assembly as §1030, 1029 in 2018), **R-009** occupant load + IBC Table 2902.1 fixtures (18 WC men, 33 WC women, 7 + 9 lavs, 3 DF, 1 service sink at load 2,640), **R-012** NFHS basketball court (partial), **R-014** planning factors (Loudoun 2014, Groton, MIL-HDBK-1027/4A).
- **Code edition flag:** Madison County's page lists the **2018** IBC/IPC; Shane said 2021. Fixture ratios identical in both. AHJ OPEN (D-008).
- README, BACKLOG (priority note; P2-T-003b first Phase 2 ticket; P2-T-003 done), ASSETS updated.

## 2026-10-03 ~11:25 PM CT · D-031 footprint cap · P2-T-003b two-level test-fit (P2-G-003 Rev B)
- Shane, firsthand (11:09 PM CT): 55,000 SF is a **FOOTPRINT cap that could allow two levels**, not a total floor area cap. Logged as **D-031 DECIDED**. Open count unchanged at 16.
- `params/phase2.yaml` v3:
  - `building.footprint_cap_sf: 55000`, `levels: up to 2`, `stories: up to 2 (D-031)`, `total_gsf_cap: none`. Locked `total_sf: 55000` is kept, with its meaning noted (it is the footprint cap).
  - `open_items.program_fit` reworded.
  - `sheets.P2-G-003`: Rev A `frozen: true`; Rev B added (`frozen: false`).
- `params/phase2_program.yaml`: the Rev A sections are unchanged. New sections `meta_rev_b`, `stacking` (L1/L2 room lists with why + source), `seat_split` (50/50 ASSUMED; best of 30-70%) and `vertical_circulation` (IBC/ADA rules plus ASSUMED 15 ft floor-to-floor and 64 SF hoistway).
- `phase2/src/p2_testfit.py`: new two-level functions `compute_two_level`, `best_split`, `exits_required`, `stair_sf`, `max_seats_two_level`, `max_floor_two_level`, `summary_b` (print with `--rev-b`). Footprint = max(L1 gross, arena volume gross + L2 gross).
- `phase2/src/p2_g_003.py`: `--rev A|B` (default B). The frozen `build()` is untouched; new `build_b()`.
- **Rev A frozen check:** regenerated to /tmp after all changes. PDF byte-identical (sha256 6d5bee82…3d92d). DXF entity-identical; only header timestamps and GUIDs differ (ezdxf).
- **Rev B result (full program: 22,000 SF floor, 2,200 seats):**
  - **Base:** ground footprint ≈ 62,700 at the 50/50 split, ≈ 62,300 at the best split (55% upper). Over 55,000 by ≈ 7,300. Total ≈ 88,900 GSF.
  - **Lean:** ≈ 53,500 at 50/50 and ≈ 51,600 at 65% upper. **Fits.** Total ≈ 74,700 GSF.
  - **Option B floor (14,364 SF):** base ≈ 52,200 footprint and ≈ 78,200 GSF (fits with all 2,200 seats); lean ≈ 42,600–44,000.
  - **Smallest change for base:** use the option B floor. Alternatives: keep 22,000 SF and cut to ≈ 1,370 seats, or any floor of ≈ 16,400 SF or less with all seats.
- **Stacking:**
  - L1: event floor + lower tier (double-height arena volume, nothing above), boys/girls lockers, 4 event lockers, foyer, lower concourse, L1 restrooms (41 fixtures), concession, first aid, mat storage, equipment room, mechanical.
  - L2: upper tier, S&C, cross-training (DR4 flips: the daily mat is the mezzanine), admin, upper concourse + hall of champions wall, L2 restrooms (29 fixtures).
  - The upper tier and L2 rooms sit over the L1 ring around the bowl.
- **Vertical circulation (base 50/50):**
  - L2 load 1,304 → 4 exits (T1006.3.3), 0.2 in/occupant (1005.3.1 exception; sprinklers 903.2.1.4 + voice alarm 907.2.1.1) → 4 stairs × 65 in.
  - About 206 SF per stair per level (26 risers of 6.92 in, 11 in treads, 2 flights, 48 in landings).
  - Elevator 1 (IBC 1104.4; ADA car 80 × 54 in; 64 SF hoistway ASSUMED).
  - About 890 net SF on each level.
- New research **R-015** (two-level stacking + vertical circulation; IBC 2021 ch. 9/10/11 via UpCodes, 2010 ADA Standards, Reed and Orleans arena guides as precedent).
- New sheet `phase2/out/pdf/P2-G-003_RevB.pdf` + `.dxf`: 1 page, 1224 × 792 pt, stamp present, reproducible.
- Previews:
  - `/workspace/keystone_previews/P2-G-003.png` = Rev B.
  - `P2-G-003_RevA.png` = the old Rev A preview.
  - `P2-G-003.pdf` = Rev B.
- **D-030** reworded (still OPEN): pick option B floor / cut seats / lean inputs / mix.
- BACKLOG, ASSETS and STATUS updated.

## 2026-10-03 ~11:35 PM CT · D-032 · P2-T-003b suites study (P2-G-003 Rev C)
- Shane, firsthand (11:26 PM CT): rejects the ≈ 1,370-seat option ("not enough") → **D-032 DECIDED**. His direction: keep ≈ 2,200 total spectators by adding rentable **suites just above the top seats**. Recorded under **D-030**, which stays **OPEN** until he picks. Open count unchanged at 16.
- `params/phase2.yaml` v4:
  - `spaces.seating.rejected_option` and `suites_direction`.
  - `open_items.program_fit` reworded.
  - `sheets.P2-G-003`: Rev B `frozen: true`; Rev C added.
  - Locked values unchanged.
- `params/phase2_program.yaml`: Rev A/B sections unchanged. New `meta_rev_c` and `suites`:
  - guests 12/16/20, 25 SF/guest, ASSUMED width rule, 44 in corridor;
  - code load = seats + lounge ÷ 15;
  - placements L2_back / L3_top, 3rd-level flags, floors checked, headline case.
- `phase2/src/p2_testfit.py`: new `suite_module`, `compute_suites` (footprint = max(L1, AV+L2, AV+L3)), `best_suites`, `max_bowl_with_suites`, `max_spectators_with_suites`, `largest_floor_with_suites`, `summary_c` (`--rev-c`). Rev B's `compute_two_level` is untouched.
- `phase2/src/p2_g_003.py`: `--rev A|B|C` (default C), new `build_c()`; `build()` and `build_b()` untouched.
- **Frozen checks:** regenerated A, B and C to /tmp. PDFs byte-identical (A sha256 6d5bee82…, B d16b2dbe…). DXFs entity-identical (227 / 294 entities); only headers differ (ezdxf).
- **Rev C result (base inputs):**
  - **22,000 SF floor:** suites cannot reach 2,200 inside 55,000 at 12, 16 or 20 guests, with suites on L2 or L3. The most that fits is ≈ 1,640 (1,180 bowl + 23 × 20; footprint 54,986; ≈ 96,800 GSF; 3 levels).
  - **Suites on L2** (back of the upper tier) never fit: L2 is already about the size of the L1 ring.
  - **Largest floor that reaches 2,200 with suites:** ≈ 20,200–20,300 SF.
  - **20,000 SF floor:** 1,610 bowl + 50×12 / 37×16 / 30×20 suites; ≈ 105,300–105,800 GSF; 510–550 ft of suite front.
  - **18,000 SF floor (headline):** 1,940 bowl + 13 × 20 = 2,200 (or 17×16 = 2,212, 22×12 = 2,204). Footprint ≈ 54,994 vs 55,000 (no margin). ≈ 92,300–92,900 GSF. 3 levels (L3 suite level ≈ 11,300 GSF, over the L1 ring). Suite SF 6,500 + 810 corridor. 221–242 ft of suite front.
  - **16,400 SF floor:** 2,200 bowl, no suites, 2 levels (≈ 80,900 GSF).
  - **Lean inputs, 22,000 SF:** no suites needed (≈ 74,700 GSF).
- **Headline fixtures and egress:**
  - Fixtures: L1 30 / L2 30 / L3 16 = 76 (Rev B: 70).
  - Stairs: 4 × 68 in on all 3 levels (L2 load 1,368, L3 code load 598). Stairs must be enclosed, 1-hour (1019.3, 1023.2). Elevator to L3 (1104.4).
  - Wheelchair spaces: 16 in the bowl + 1 in each suite (1109.2.2).
- New research **R-016**: suites in small arenas. Precedents: Diddle/WKU, Texas Tech, Pitt Petersen, Sheldon ISD. Code: IBC 1004.6/T1004.5, 1109.2.2, ADA 221.2. No $ figures (revenue out of scope).
- New sheet `phase2/out/{pdf,dxf}/P2-G-003_RevC`: 1 page, 1224 × 792 pt, stamp present, reproducible.
- Previews:
  - `/workspace/keystone_previews/P2-G-003.png` = Rev C.
  - `P2-G-003_RevB.png` kept.
  - `P2-G-003.pdf` = Rev C.
- BACKLOG, ASSETS and STATUS updated.

## 2026-10-03 ~11:50 PM CT · D-030 DECIDED · locked program (P2-G-003 Rev D) · P2-T-004 block plans (P2-A-101/102 Rev A)
- **D-030 DECIDED** — 16,400 SF event floor, all 2,200 seats in the bowl, 2 levels, no suites — "Shane, firsthand, 11:39 PM CT". Open decisions 16 → 15.
- Suites → PARKING_LOT ("future add-on, study after attendance is proven"). Seating type stays OPEN (D-009); D-009 notes updated.
- `params/phase2.yaml` v5 (locked, change only on CHANGE APPROVED):
  - `spaces.arena.event_floor_sf: 16400`, `event_floor_dims` 114 ft E-W × 144 ft N-S = 16,416 SF drawn, with basis (NFHS 2-1-5, 2-3 from R-005; court from R-012).
  - `spaces.arena.sf: 22000` renamed `sf_tagged_superseded: 22000` + history note (frozen Revs A-C read it; their PDFs regenerate byte-identical).
  - `mat_ft: 42`, `mat_layout` 2 × 2; `seating.bowl: 2200` (+ suites PARKED, `type_note` D-009); `building.levels: 2`; S&C + cross-training `level: 2`.
  - `open_items.program_fit` DECIDED; `sheets.P2-G-003` Rev C frozen, Rev D added; new `sheets.P2-A-101`, `P2-A-102` (Rev A).
- `shared/validate.py`: locked checks added for event_floor_sf 16400, sf_tagged_superseded 22000, mat_ft 42, seating.bowl 2200, levels 2, S&C + cross-training level 2.
- **Floor check:** E-W 2 × 42 + 3 × 10 clear = 114 ft; N-S 114 + two 15 ft table/bench zones (depth ASSUMED) = 144 ft. Holds the Rev A 114 × 126 = 14,364 SF layout and an 84 × 50 court + 10 ft runout (104 × 70).
- `params/phase2_program.yaml`: new `meta_rev_d`, `locked_program` (50/50 tiers, FIXED vs TELESCOPIC columns, same 1.25 gross-up, wheelchair table). Earlier sections unchanged.
- `phase2/src/p2_testfit.py`: new `wheelchair_spaces`, `compute_locked` (Rev B method at the locked floor + bowl), `summary_d` (`--rev-d`). Frozen functions read `ARENA_TAG`.
- `phase2/src/p2_g_003.py`: `--rev A|B|C|D` (default D), new `build_d()`; `build()`, `build_b()`, `build_c()` untouched.
- **Frozen checks:** Revs A, B, C regenerated to /tmp after the key rename: PDFs byte-identical, DXFs entity-identical (227 / 294 / 320).
- **P2-G-003 Rev D (LOCKED PROGRAM)**, base = FIXED 6.0 SF/seat, alt = TELESCOPIC 3.38 SF/seat:
  - L1 gross 54,949 / 50,868; L2 gross 25,981 / 22,380; arena volume 28,750 / 25,149.
  - Footprint 54,949 / 50,868 vs 55,000: both FIT (fixed margin 51 SF; the drawn 16,416 floor gives ≈ 54,971).
  - Total 80,930 / 73,248 GSF.
  - Fixtures: L1 37 (WC 10 M / 18 W, lav 4 / 5), L2 29 (WC 8 / 14, lav 3 / 4) = 66; 4 drinking fountains; same both columns.
  - 4 stairs × 65 in (L2 load 1,304), ≈ 206 SF each per level + 1 elevator (64 SF hoistway) = 890 SF per level.
  - Wheelchair spaces 18 (T1109.2.2.1), dispersed.
- **New `params/phase2_plan.yaml`** + **`phase2/src/p2_a_plan.py`** → `phase2/out/{pdf,dxf}/P2-A-101_RevA` (Level 1), `P2-A-102_RevA` (Level 2):
  - Schematic block plans at 1/32 in = 1 ft-0 in (1/16 does not fit) on tabloid; building 250 × 220 ft = 55,000 SF footprint.
  - Floor with 4 mats + court overlay; fixed tiers solid, telescopic depth dashed (9.5 ft lower, 8.5 ft upper vs 16.5 / 15 fixed).
  - 4 stairs + elevator at the same coordinates on both levels; room tags with drawn SF; room schedules vs program.
  - Level 2: S&C + cross-training over the lockers, restrooms + admin stacked, open to the lobby and arena below. Drawn L2 ≈ 27,570 SF vs 25,981 program.
- Previews: `P2-G-003.png/.pdf` = Rev D, `P2-G-003_RevC.png` kept, `P2-A-101.png/.pdf`, `P2-A-102.png/.pdf`.
- DECISIONS, PARKING_LOT, BACKLOG (P2-T-003b done, P2-T-004 in progress, P2-T-005 → A-103), ASSETS, STATUS updated.

## 2026-10-04 ~4:40 AM CT · D-009 DECIDED (MIX seating) · P2-G-003 Rev E · P2-A-101/102 Rev B
- **Shane review (4:30 AM CT):** P2-A-101/102 Rev A "good first block plan". Rev A of both sheets FROZEN (regenerate byte-identical with `--rev A`); previews kept as `P2-A-101_RevA.png`, `P2-A-102_RevA.png`.
- **D-009 DECIDED** — MIX: telescopic lower tier, fixed upper tier — "Shane, firsthand, 4:30 AM CT". Open decisions 15 → 14.
- `params/phase2.yaml` v6: `spaces.seating.type` MIX (LOCKED), new `lower_tier_type: telescopic`, `upper_tier_type: fixed`, `seats_per_tier`, `sides` (N, S, E); `entry.location_block_plan` (south-center, road assumed south, site TBD); `support_rooms.mechanical.location_block_plan` (NW / N / E, off the west public side); `open_items.seating_type` DECIDED; sheets: P2-G-003 Rev D frozen + Rev E, P2-A-101/102 Rev A frozen + Rev B.
- `shared/validate.py`: locks `seating.lower_tier_type == telescopic`, `upper_tier_type == fixed` (D-009).
- `params/phase2_program.yaml`: `meta_rev_e`, `mixed_seating` (target margin 2,000 SF). Earlier sections unchanged.
- `phase2/src/p2_testfit.py`: `compute_mix`, `largest_remainder`, `seats_by_side`, `summary_e` (`--rev-e`). `p2_g_003.py`: `build_e`, `--rev` default E; Revs A–D untouched.
- **P2-G-003 Rev E (MIX):** lower 1,100 telescopic at 3.38 SF/seat, upper 1,100 fixed at 6.0 SF/seat, same 1.25 gross-up. L1 net 37,032 → gross 51,108; L2 net 20,785 → gross 25,981; arena volume 25,149; footprint = max(L1, arena volume + L2) = **51,130 → margin 3,870 SF under 55,000 (target ≥ 2,000 met)**; mech 3,854; **total 77,089 GSF** (all-fixed Rev D: 54,949 / margin 51 / 80,930). Fixtures 66, 4 stairs × 65 in + elevator, 18 wheelchair spaces (unchanged).
- **Seats by side / tier (sheet table, sum 2,200):** N 353 telescopic + 308 fixed = 661; S 341 + 308 = 649; E 406 + 484 = 890; lower 1,100 + upper 1,100. Split per tier by largest remainder in proportion to drawn capacity (lower 1,306, upper 1,125).
- **New `params/phase2_plan_rev_b.yaml`** (Rev A geometry in `phase2_plan.yaml` frozen) + `p2_a_plan.py` `build_b` (`--rev A|B`, default B; room-overlap check fails the build):
  - Box shrinks 250 × 220 → **204 × 252 ft = 51,408 SF** (3,592 under the cap; 278 over the program footprint). Floor 114 × 144 on the arena N-S axis (x = 113 ft).
  - Entry south-center on the axis: vestibule + lobby / hall of champions (double height) under the south tier, 12 ft portal straight to the floor. Men (W of lobby) and women (E) flank it; concession and first aid in the lobby zone.
  - Mech/elec moved off the west side: NW corner (tag 3), N ring (15), E ring behind the bowl (16); old SE mech gone. West = boys + girls lockers + athlete corridor only; team/service entry at the SW.
  - Event lockers N (2) + E (2) via vomitories V1 (N) and V2 (E); equipment storage/room N; 4 stairs + elevator aligned L1/L2.
  - Level 2: S&C + cross-training over the lockers, men/women L2 stacked over L1, admin over the team entry, balcony / upper concourse across the lobby (hall of champions wall), lobby open to below centered south, upper tier N/S/E with rear walkways.
  - Layout fix: plan title moved to the right panel, scale bar beside the building, axis note at the entry arrow (252 ft box fills the sheet height at 1/32 in).
- **Frozen checks:** P2-G-003 Revs A–D and P2-A-101/102 Rev A regenerated to /tmp: PDFs byte-identical; DXFs entity-identical (227 / 294 / 320 / 361; 714 / 598).
- Previews: `P2-G-003.png/.pdf` = Rev E (`P2-G-003_RevD.png` kept); `P2-A-101.png/.pdf`, `P2-A-102.png/.pdf` = Rev B.
- DECISIONS, BACKLOG, ASSETS, STATUS updated.

## 2026-10-04 ~4:50 AM CT · D-033 DECIDED (single controlled entry) · D-034 OPEN · P2-A-101/102 Rev C
- **D-033 DECIDED** — single controlled entry point for all people (public, teams, staff): "Everyone passes through the grand entrance; it will serve as a checkpoint, a security feature." — "Shane, firsthand, 4:43 AM CT".
- **D-034 OPEN** — how deliveries and team buses work under the single-entry rule (no sizes set). Open decisions 14 → 15.
- P2-A-101/102 **Rev B FROZEN** (regenerate byte-identical with `--rev B`; previews kept as `P2-A-101_RevB.png`, `P2-A-102_RevB.png`).
- `params/phase2.yaml` v7: `spaces.entry.access_control` (rule, quote, checkpoint, team route, perimeter exits, service door; sources D-033, R-015, IBC 2021 Ch. 10); `open_items.access_control` DECIDED, `deliveries_buses` OPEN; sheets P2-A-101/102 Rev B frozen + Rev C.
- **New `params/phase2_plan_rev_c.yaml`** (Rev B geometry frozen in `phase2_plan_rev_b.yaml`) + `p2_a_plan.py` `build_c` (`--rev A|B|C`, default C; Rev C seat counts are checked against P2-G-003 Rev E):
  - SW team / service entry removed. Freed SW area: TEAM ASSEMBLY / HOLDING ≈ 2,072 SF + STORAGE (SW) 1,011 SF (tag 23), both unprogrammed, ASSUMED.
  - SECURITY CHECKPOINT — size TBD (ASSUMED): dashed zone between the vestibule and lobby, location only.
  - CD-1 controlled door off the lobby → 8 ft ATHLETE ROUTE along the back of the south tier → team assembly → athlete corridor / lockers; walls separate it from the west concourse (which loses its north 8 ft).
  - Perimeter doors (symbols, widths not drawn): E1 main entry / main exit; X1-X10 EXIT ONLY — alarmed, no exterior entry hardware (team assembly W, girls + boys lockers W, ST-1..ST-4 discharges, exit passages N + E, east concourse); S1 SERVICE / LOADING at equipment storage (staff-controlled, not a people entrance; D-034 OPEN).
  - New exit passages N + E (8 ft = vomitory width, ASSUMED) from V1 / V2 to the north and east walls so the north and east tiers reach perimeter exits (T1006.3.3, 1030.3). V1 moved 3.85 ft east, V2 3.91 ft south (same widths, seat counts unchanged). Event locker 2 shifted east, event locker 4 shifted south (900 SF each kept); Mech N 588, Mech E 1,720, new Mech (NE) 327 (tag 22) → mech drawn 3,804 vs 3,854 program.
  - Sheet blocks: ACCESS CONTROL + EGRESS (both levels) with the IBC citations; legend adds exit / service / checkpoint symbols.
- **Code basis (new R-015.6, IBC 2021 Alabama via UpCodes, retrieved 2026-10-04):** 1010.2 (egress side openable without a key; 2018 1010.1.9), 1010.2.9 (panic hardware only, Group A ≥ 50; 2018 1010.1.10), 1010.2.7 exc. 1 (stair discharge doors lock from outside only), 1010.2.13 (no delayed egress in Group A → alarm only), T1006.3.3 (4 exits per story > 1,000), 1030.2 (main exit ≥ 1/2 occupant load, fronts a street), 1030.3 (other exits ≥ 1/2), 1005.3.2 exc. 1 (0.15 in/occupant; seats alone → E1 ≥ 165 in clear), 1003.6 / 1010.5 (checkpoint may not narrow the egress width), T1004.5 + T1006.2.1 (locker rooms need 2 exits).
- **P2-G-003:** program numbers unchanged → Rev E stands (regenerates byte-identical); no Rev F. Box 204 × 252 = 51,408 SF, 3,592 SF under 55,000; program footprint 51,130 (margin 3,870); 77,089 GSF; seats N 661 / S 649 / E 890 = 2,200.
- **Frozen checks:** P2-A-101/102 Revs A + B and P2-G-003 Rev E regenerated to /tmp: PDFs byte-identical, DXFs entity-identical (714 / 598; 677 / 472; 292).
- Previews: `P2-A-101.png/.pdf`, `P2-A-102.png/.pdf` = Rev C.
- DECISIONS, BACKLOG, ASSETS, STATUS updated.

## 2026-10-04 ~5:10 AM CT · D-035 DECIDED (Level 2 running / training loop) · P2-G-003 Rev F · P2-A-101/102 Rev D
- **Shane, firsthand, 4:55 AM CT:** complete continuous walkway / running-training loop around the top of Level 2, joining REAR WALKWAY (N), WALKWAY (E) and UPPER CONCOURSE / HALL OF CHAMPIONS BALCONY (S); S&C (17) and cross-training (18) may be cut. He wrote "eastside"; those rooms are on the west, so the missing leg is the west one, along their arena-side edge. Logged **D-035 DECIDED**. Open decisions stay 15.
- **params/phase2.yaml v8** (Shane's approval = CHANGE APPROVED): S&C `sf` 5,224 (was 6,000), cross-training `sf` 3,500 (was 4,000), old values kept as `sf_tagged_superseded`; new `spaces.training_loop` (2 lanes x 42 in = 7 ft, squared corners, 706 ft centerline, 7.48 laps/mile, guards, event-day use). Sheets: P2-G-003 Rev E frozen + Rev F; P2-A-101/102 Rev C frozen + Rev D. `phase2_program.yaml`: room tag_paths read `sf_tagged_superseded` so frozen revisions keep 6,000 / 4,000; new `meta_rev_f` + `training_loop` method. `validate.py` PHASE2_LOCKED updated.
- **New `params/phase2_plan_rev_d.yaml`** + `p2_a_plan.py` `build_d` (`--rev A|B|C|D`, default D; seats checked against P2-G-003 Rev E; loop checked against stairs / elevator / rooms):
  - Loop outer [49, 34, 204, 246], inner [56, 41, 197, 239] (= upper-tier backs + arena edge); 4,942 SF; lane line dashed; leg labels; event-day crossing arrows at mid-side tier entries (ASSUMED locations); 42 in guards on the west edge over the arena and the south edge over the lobby.
  - S&C 49 x 110.8 less ST-1 = 5,224 SF; cross-training 49 x 71.43 = 3,500 SF; L2 corridor [0, 18.8, 49, 69.77]; balcony / walkways replaced by the loop; 6 ft STRETCH / WARM-UP STRIP (N) left over (ASSUMED).
  - ST-1 3.55 ft west (L1 Mech NW 1,070, X4 at x 43.6); ST-2 5 ft north into a new 19 x 5 ft NE stair tower (+95 SF; L1 Mech NE 422, X6 at y 251.6); elevator 1 ft south (opens onto the loop). Building 51,503 SF, 3,497 under 55,000. Seats unchanged (N 661 / S 649 / E 890 = 2,200).
- **P2-G-003 Rev F** (`p2_testfit.compute_loop` / `summary_f`, `p2_g_003.py build_f`, default F): Rev E method with the new S&C / XT SF (loads, stairs 64.0 in, fixtures recomputed); the loop replaces the upper concourse line (1,375) and is added to L2 gross as drawn, **not grossed up** (ASSUMED; it is circulation). L1 51,194; L2 27,590; footprint 52,738 (arena volume + L2), **margin 2,262** (≥ 2,000 target met); **78,784 GSF**. Grossed-up alternative shown: 53,974 / margin 1,026 (misses). Flag: program footprint is 1,235 SF more than the drawn building, so the gross-up allowance no longer fully fits inside it.
- **Research:** new `research/R-017-indoor-running-track-and-guards.md` (UFC 4-740-02N 4.1.7, Athletic Business x 2, IBC 2021 1015.2-1015.4 / 1030.17; retrieved 2026-10-04).
- **Frozen checks:** P2-G-003 Revs A-E and P2-A-101/102 Revs A-C regenerated to /tmp: PDFs byte-identical, DXFs entity-identical (227 / 294 / 320 / 361 / 292; 714 / 677 / 786; 598 / 472 / 482).
- Previews: `P2-G-003.png/.pdf` = Rev F (`P2-G-003_RevE.png` kept); `P2-A-101.png/.pdf`, `P2-A-102.png/.pdf` = Rev D (`_RevC.png` kept).
- DECISIONS, BACKLOG, ASSETS, STATUS updated.

## 2026-10-04 ~5:45 AM CT · D-036 approval + Phase 2 Schematic Set Rev A freeze · R-018 egress · P2-A-201 Rev A
- **Shane, firsthand, 5:27 AM CT:** "P2-A-101/102 Rev D + P2-G-003 Rev F approved. Entry south-center, mech off the public side, mixed seating, 2,262 margin — all good." Logged **D-036** DECIDED, **D-037** DECIDED (loop 2 x 42 in = 7 ft for now), **D-038** OPEN (upper concourse width vs egress; 3 lanes / 10.5 ft if code requires), **D-039** DECIDED (west unprogrammed space kept as-is, labeled FLEX), **D-040** OPEN (brand / HGHS badge on the portal). Open decisions 15 → 17.
- **FLEX relabel = label-only re-issue of P2-A-101 Rev D before the freeze** (D-039; Shane's message left the template bracket, KEYSTONE used the stated default KEEP AS-IS): `params/phase2_plan_rev_d.yaml` team assembly → "FLEX / TEAM ASSEMBLY", storage SW → "FLEX / STORAGE"; area-check line in `p2_a_plan.py build_d`. DXF 791 entities before and after, every non-text entity identical, only text strings changed; areas unchanged (≈ 2,072 / 1,011 SF). Revision letter kept (Rev D) because nothing but labels changed. P2-A-102 Rev D and P2-G-003 Rev F untouched (byte-identical).
- **Freeze — Phase 2 Schematic Set Rev A** (`params/phase2.yaml` v9: P2-G-003 Rev F, P2-A-101 Rev D, P2-A-102 Rev D `frozen: true` + `approved`; new `sets.phase2_schematic_set_rev_a`): new `phase2/src/p2_set.py` writes one 3-page 17 x 11 in PDF `phase2/out/pdf/Phase2_Schematic_Set_RevA.pdf` (G-003 F, A-101 D, A-102 D) with matplotlib PdfPages from the same builders; copied to `/workspace/keystone_previews/`. `pdfunite` was rejected because it writes a random /ID (not reproducible). `--out-dir` rebuild is byte-identical; pages pixel-identical to the single-sheet PDFs; stamp on every page. Frozen guard like the sheet generators. Generators' docstrings mark the revisions FROZEN. Git tag `p2-schematic-revA` on the freeze commit (tags are not branches; README limits branches only).
- **shared/titleblock.py**: `text(..., color=)` (stored only when used), new `poly()` primitive (PDF filled polygon; DXF solid HATCH with true color + outline), `render_pdf` split into `figure()` + save (for the bundle). Frozen checks after the change: all P1 sheets, P2-G-003 Revs A-F and P2-A-101/102 Revs A-D regenerate with entity-identical DXFs and byte-identical PDFs, except **P1-G-001 Rev A internal PDF**, which differs in bytes only (text and pixels identical) and also differs with the old titleblock.py, so it is pre-existing drift, not caused by this change; the committed file was left as is.
- **Research:** new `research/R-018-level-2-egress-assembly.md` (IBC 2021 Ch. 10 via UpCodes, retrieved 2026-10-04; 2018 1029.x from secondary excerpts, UNVERIFIED; NFPA 101 / ICC 300 paywalled): L2 load 1,279 (1,100 seats + S&C 105 + cross-training 70 + admin 4); stairs 255.8 in = 4 x 64 in (zero slack); loop 64 in balanced / 79.2 in unbalanced vs 84 in → code does not require > 7 ft; 10.5 ft satisfies; travel ≤ ≈ 144 ft vs 250 ft; guards 42 in; event-day cross-flow rules. New `research/R-019-arena-clear-height.md` (≥ 25 ft clear over the court: Draper reprint of NFHS specs, LA Rec & Parks standard; wrestling practice rooms 9-10 ft, NFHS).
- **P2-A-201 Exterior Elevations Rev A** (P2-T-009; new `params/phase2_elev.yaml`, new `phase2/src/p2_a_201.py`): south elevation at 1/16 in = 1 ft-0 in with the south portal (limestone arch 44 ft wide x 50 ft high, 28 ft opening, springline 26 ft, crown 40 ft, crimson inside the arch, gold soffit / intrados, entry glazing, "BRAND / SIGNAGE — TBD" in brand red / black, no school logo, D-040); north, east and west at 1/32 in. Heights: L2 FF 15 ft (ASSUMED, R-015), ring roof 30 ft (ASSUMED), arena clear ≥ 25 ft (CITED, R-019), underside of arena structure 36 ft and roof 42 ft (ASSUMED), parapet TBD. Portal proportions from Shane's MOVIE MAKER arch render; sizes ASSUMED. Other materials TBD. Color elevations; stamp present.
- Previews: `P2-A-201.png/.pdf`, `Phase2_Schematic_Set_RevA.pdf`; `P2-A-101.png/.pdf` = Rev D with FLEX labels.
- DECISIONS, BACKLOG, ASSETS, STATUS updated.

## 2026-10-04 ~6:30 AM CT · D-041 official mark · D-043 freestanding portal + Champion Walk · P2-A-201 Rev B
- **Shane, firsthand, 6:16 AM CT:** "OFFICIAL MARK — circular horse-head badge with Greek key border." Logged **D-041** DECIDED (supersedes logo Concepts 01 / 02, kept as history, nothing deleted; the concept files are not in the repo or on the box), **D-040 closed** (the portal carries the Trojan Horse Arena mark, not the HGHS badge), **D-042** OPEN (trademark search before signage / apparel).
- **Brand files:** new `brand/THA_logo_black.svg` / `_red.svg` / `_white.svg` = Shane's 3 SVG attachments, identified by fill (#1A1A1A / #CC0000 / #FFFFFF); identical geometry (one even-odd path, viewBox 1373 x 1379); sha256 in ASSETS. His JPG (black mark on a transparency checker) and the PNGs on his PC were not committed.
- **Shane, firsthand, 6:22 AM CT:** the Grand Entrance Portal is **FREESTANDING**, just before the south entrance, straddling the brick **Champion Walk** (engraved donor / sponsor bricks). Logged **D-043** DECIDED (next A-101 revision adds the portal + walk; Rev D stays frozen) and **D-044** OPEN (walk length / width, donor-brick program). New `references/portal_freestanding_champion_walk_ref.png` (his reference photo, sha256 in ASSETS). phase2.yaml v10 (`brand.official_mark`) + v11 (`approach`).
- **P2-A-201 Rev A frozen** (regenerates byte-identical PDF, entity-identical DXF; `phase2_elev.yaml` unchanged). **Rev B** (`p2_a_201.py --rev B`, default; new overlay `params/phase2_elev_rev_b.yaml`):
  - Official mark (black) Ø 6 ft centred above the arch (40.4-46.4 ft, replaces the keystone) + "TROJAN HORSE ARENA" wordmark in brand red, 18 in caps, 26.1 ft long on the 44 ft attic (layout guard stops it overflowing the portal); side panel "HAZEL GREEN REGIONAL / ATHLETIC COMPLEX" (black, red stripe, white letters) on the west ring wall, 46 x 7.5 ft. All sizes ASSUMED.
  - Portal freestanding: open arch (no glazing in the portal); the building's E1 entry glazing (18 x 16 ft ASSUMED) shows behind it; crimson soffit band with a thin gold edge (split TBD); title "GRAND ENTRANCE PORTAL (FREESTANDING) — stands ≈ 30' south of the entrance (gap ASSUMED)"; Champion Walk brick strip at grade + "Engraved donor / sponsor bricks".
  - Key plan (north up, 1 in = 60 ft): building south wall + E1, 30 ft gap (ASSUMED, dimensioned), 2 piers (depth 6 ft ASSUMED), brick walk 28 ft wide (= arch opening, ASSUMED), length TBD.
  - Brand detail at 3/32 in = 1 ft-0 in (portal attic) so the mark and wordmark read at print size. Brick added to the finishes legend; notes updated (D-041 to D-044).
- **shared/titleblock.py:** new `mark()` primitive + `load_svg_mark()`: one-path SVG (M/L/C/Z) drawn as a **vector** path in the PDF (sub-paths re-oriented by nesting depth so the PDF non-zero fill matches the SVG even-odd; no raster: `pdfimages` lists 0 images); DXF block `THA_MARK` (solid HATCH, true colour + outline polylines) inserted twice (scale 0.375 / 0.5625 in). svglib / cairosvg not installed and not needed. Frozen checks re-run after the change (all P1 sheets, P2-G-003 A-F, P2-A-101/102 A-D, the set bundle and P2-A-201 Rev A).
- Previews: `P2-A-201.png/.pdf` = Rev B; `P2-A-201_RevA.png` kept.
- DECISIONS, ASSETS, BACKLOG, STATUS updated.

## 2026-10-04 ~7:00 AM CT · P2-A-201 Rev B frozen · Rev C (11 ft badge) · D-034 / D-038 / D-044..D-048 · P2-A-301 Rev A sections
- **Shane, firsthand, 6:45 AM CT:** "P2-A-201 Rev B APPROVED with changes for Rev C." **Rev B frozen** (`phase2.yaml` v12: `frozen: true`; regenerates byte-identical PDF / entity-identical DXF; preview `P2-A-201_RevB.png` kept).
- **Decisions:** **D-045** DECIDED arch underside crimson + gold trim (as drawn). **D-046** DECIDED Champion Walk 28 x 30 ft (portal to doors) "for now", 840 SF; tiers 4x8 single name / 8x8 family-business; ≈ 3,700 4x8 bricks (840 ÷ 0.222 = 3,780 gross, less border / joints); option to extend to parking later. **D-044** stays OPEN, narrowed to pricing. **D-047** DECIDED badge 11 ft. **D-048** OPEN arch photo rights. **D-038 CLOSED** stairs 70 in clear. **D-034 DECIDED** (default): service / deliveries at north door S1; bus drop loop on the south, offset east or west of the portal view. Open decisions 18 → **17**.
- **P2-A-201 Rev C** (`p2_a_201.py --rev C`, default; new overlay `params/phase2_elev_rev_c.yaml`; Rev B output untouched because every Rev C behaviour is keyed on overlay fields Rev B lacks):
  - Badge Ø 11 ft (was 6), centre 45.9 ft → 40.4-51.4 ft. Wordmark caps 27 in (was 18 in), 39.1 ft long: proportional scaling (2.75 ft caps) gives a 47.9 ft line, wider than the 44 ft portal, so caps are held at 27 in. The badge + wordmark do not fit under 50 ft, so the **portal / attic was raised 50 → 56 ft (ASSUMED; attic band 42-56 ft)**; width 44, opening 28, springline 26, crown 40 unchanged.
  - South elevation moved down 0.45 in on the sheet; brand detail re-fit (attic 40-56 ft at 3/32 in = 1 ft); callouts "CRIMSON underside (D-045)", "GOLD trim (D-045)"; title "30' in front of the E1 doors (D-046) · 56' h ASSUMED".
  - Key plan: Champion Walk 28 x 30 ft brick (portal at the walk's south end, 30 ft = gap, D-046), tiers + capacity note, dashed "extend to parking later", bus drop note (south loop offset E / W, D-034). Notes rewritten (portal, brand, walk).
- **Arch reference photo:** `git rm references/portal_freestanding_champion_walk_ref.png` (no history rewrite); box copy `/workspace/keystone_previews/refs/` (sha256 in ASSETS); ASSETS says "held off-repo pending rights confirmation from Shane".
- **params/phase2.yaml v12:** portal reference held off-repo (D-048), underside D-045, height 56 ASSUMED; `approach.champion_walk` 28 x 30, 840 SF, tiers, capacity, extension, pricing TBD; new `approach.site_access` (D-034) and `approach.egress_next_revision` (stairs 70 in, D-038); `brand.official_mark.portal_badge_dia_ft` 11 (D-047); new sheet entry **P2-A-301** Rev A.
- **R-018.8 addendum** (stairs 70 in): 4 x 70 = 280 in vs 255.8 base (+24.2), 275.6 loop counted (+4.4), 272.6 rail standing (+7.4), 292.4 both (12.4 short); one stair lost 210 ≥ 137.8; handrail projection 4.5 in (1014.8) — architect to confirm how "clear" is measured; stair plan ≈ 11.67 x 19 ft (+16.5 SF per stair per level) at the next A-101/A-102 revision. Frozen set unchanged.
- **P2-A-301 Rev A building sections** (new `params/phase2_sect.yaml`, new `phase2/src/p2_a_301.py`): (1) A-A N-S at x = 100 looking west and (2) B-B E-W at y = 150 looking north, 1/32 in = 1 ft; (3) north bowl edge enlarged, 3/32 in; (4) typical exit stair 70 in clear, 1/8 in; (5) key plan with the cuts; legend + notes.
  - Heights: L2 FF 15, ring roof 30, arena structure underside 36, arena roof 42 (all ASSUMED, phase2_elev.yaml); ≥ 25 ft clear CITED (R-019).
  - Lower tier telescopic 6 rows x 24 in (R-008 / plan), Hussey 11-5/8 in rise (CITED option, ASSUMED choice): top seat 6'-3 1/8", closed 3'-6" (Hussey tables). Upper tier fixed 15 ft band, 5 rows x 36 in, 14 in per row (2 x 7 in aisle risers) ASSUMED, stepping down from the loop (top cross aisle at 15 ft) to a 9.17 ft front row; L1 headroom under the tier front ≈ 9.2 ft less structure — TBD. Guards 42 in at the loop's open edges (1015), ≥ 26 in fascia at the tier front (1030.17.3). Sight lines NOT checked — TBD. Slab / roof thicknesses graphic only.
- **Frozen checks:** P1-G-001 A-D, P1-A-101 A, P2-G-003 A-F, P2-A-101/102 A-D, P2-A-201 A-B and Phase 2 Schematic Set Rev A regenerated to /tmp: PDFs byte-identical and DXFs entity-identical (P2-A-201 A / B: 879 / 1,028 entities); only the known pre-existing P1-G-001 Rev A internal PDF byte difference (text + pixels identical, predates this work).
- Previews: `P2-A-201.png/.pdf` = Rev C (`P2-A-201_RevB.png`, `_RevA.png` kept); `P2-A-301.png/.pdf`.
- DECISIONS, ASSETS, BACKLOG, STATUS updated.

## 2026-10-04 ~7:40 AM CT · D-048 closed · D-049..D-051 decided · D-052 / D-053 proposed · P2-A-201 Rev D · P2-A-301 Rev B · P2-A-302 Rev A

Shane, firsthand, 7:24 AM CT (+ PDF vendor cost sheet for the Champion Walk bricks).
- **D-048 CLOSED:** arch photo is Shane's own image (rights clear); removal stands, no history rewrite; ASSETS "Shane's own image; held off-repo by choice".
- **D-044 input:** vendor cost averages $19.17 (4x8) / $29.50 (8x8), logo +$6, engraving + shipping included; ~3,700 x $19.17 ≈ $70.9k if all 4x8 (excl. install / base). Donor pricing still OPEN. PDF kept box-only (sha256 in ASSETS).
- **D-049 DECIDED:** upper tier steps down from the L2 loop (as drawn); storage / mech / stack under the low front; lockers only at full height. Plan overlaps listed in DECISIONS; event lockers re-planned at the next A-101.
- **P2-A-201 Rev C FROZEN; Rev D (D-050):** portal 50 ft max (was 56 ASSUMED); arch crown 40 → 34 ft, springline 26 → 22.1 ft (proportional, ASSUMED), semi-elliptical (rise 11.9 ft); attic band 36-50; badge 11 ft at 34.4-45.4 ft; wordmark 27 in caps, baseline 46.1, caps top 48.35, under the 48.8-50 ft cornice. `p2_a_201.py`: generic `portal_override`, elliptical `arch_pts`, `callout_targets`, `notes_override.heights`.
- **P2-A-301 Rev A FROZEN; Rev B (D-051):** detail 4 intermediate landing 70 in (= stair width, IBC 2021 1011.6), floor landings 48 in; per stair 11.67 x 20.83 ft = 243.1 SF per level vs frozen 205.2 (+37.9; ≈ +303 GSF for 4 stairs x 2 levels at the next A-101/A-102). A-A / B-B / detail 3: under-tier storage / mech (D-049), lockers at full height; notes point to P2-A-302 (D-053) and R-018.9 (D-052).
- **P2-A-302 Rev A sight-line study (new) + R-020:** Green Guide C-values, seated 1.2 m / standing 1.6 m eyes, focal = near mat edge (N/S 25 ft, E 10 ft). As drawn: upper tier fails everywhere (N/S 40-49 mm seated, east negative); east lower 46-74 seated. Proposed: upper 19 in risers (front 9.17 → 7.08 ft) + east tier 6 ft further out → all seated ≥ 101, standing ≥ 72. Stack: closed recess under the front fits only with ≤ 32.6 in structure; open rows under the overhang conflict with 7'-6" → keep the stack at the tier face.
- **R-018.9 / D-052 (proposed):** worst case 292.4 in; 4 x 76 in = 304 (+11.6), +217.8 GSF vs 70 in; vs 74 / 78 in and a 5th stair (44 in: 324 in, +273.8 GSF + new core). Plans not redrawn.
- **params/phase2.yaml v13:** portal height / arch / badge / wordmark, photo wording, `champion_walk.vendor_cost`, `egress_next_revision_2`, `under_tier_use`, `sight_lines`; sheets A-201 Rev C frozen + Rev D, A-301 Rev A frozen + Rev B, new P2-A-302.
- Frozen checks re-run (adds P2-A-201 Rev C and P2-A-301 Rev A). DECISIONS (open 18), ASSETS, BACKLOG, STATUS updated.

## 2026-10-04 ~7:55 AM CT · D-053 + D-052 DECIDED · footprint margin · R-006 / R-007 · P2-C-101 Rev A site plan

- **Shane, firsthand, 7:44 AM CT — D-053 DECIDED:** upper-tier risers 19 in (front row 7.08 ft) AND east seats 6 ft further from the mats (+≈1,512 SF). Applies at the next A-101/A-102/A-301 revision; frozen sheets stay frozen.
- **Shane, firsthand, 7:49 AM CT — D-052 DECIDED:** 4 exit stairs at 76 in clear with intermediate handrails; worst case 304 in vs 292.4 in (≈ 11.6 in spare); ≈ 12.67 x 21.33 ft per stair per level. Applies at the next A-101/A-102/A-301 revision.
- **Footprint vs 55,000 SF cap (D-031)**, east shift + 76 in stairs: drawn basis (P2-A-101 Rev D 51,503 + 1,512 shift + 11.67 NE tower widening) **53,026.7 SF → 1,973.3 SF margin**; if all stair growth went outward 53,275.1 → 1,724.9; program basis (P2-G-003 Rev F method) **54,588.9 → 411.1 SF**. `phase2.yaml` `building.footprint_margin_next_revision`; `phase2_site.yaml` `footprint_check`.
- **R-006 (code edition + AHJ):** unincorporated Hazel Green → Madison County Inspection Department (2018 IBC / IFC / NFPA 101 adopted; State Fire Marshal enforces 2021 IFC → edition conflict to settle at pre-application); DCM (2021 IBC) only if the "schoolhouse" test applies; assembly occupancy needs an Alabama-registered architect. D-008 stays OPEN (site + pre-app).
- **R-007 (occupancy + occupant load):** Group A-4 main (arena with spectator seating); S&C / cross-training A-3 or accessory; offices B; storage S-1 (ASSUMED until G-002). Fixed seats counted by seat (IBC 2021 1004.6). Event floor 16,416 SF: 329 (50 gross) → 1,095 / 2,346 / 3,284 if used for unconcentrated / chairs / standing → **D-054 OPEN** (event floor uses).
- **P2-C-101 Rev A (new site sheet, campus diagram, SITE TBD):** building outline with the east shift and the 76 in stairs (frozen Rev D outline dashed), freestanding portal 30 ft south of E1 over the 28 x 30 ft brick Champion Walk, south bus drop loop offset east (west mirror allowed), service drive + apron to north door S1, assumed south road, fire access note, footprint table, entry inset 1 in = 30 ft. Generator `phase2/src/p2_c_101.py`, inputs `params/phase2_site.yaml`.
- **params/phase2.yaml v14:** `egress_next_revision_3` (76 in), `sight_lines.decision`, `building.footprint_margin_next_revision`, `open_items.ahj` / `occupancy`, sheet `P2-C-101` Rev A.
- Frozen checks re-run (P1-G-001 A-D, P1-A-101 A, P2-G-003 A-F, P2-A-101/102 A-D, P2-A-201 A-C, P2-A-301 A, Phase 2 Schematic Set Rev A): PDFs byte-identical, DXFs entity-identical (only the known pre-existing P1-G-001 Rev A internal PDF byte drift). Current P2-A-201 Rev D / A-301 Rev B / A-302 Rev A also regenerate unchanged. DECISIONS (open 17), ASSETS, BACKLOG, STATUS updated.

## 2026-10-04 ~8:20 AM CT · prompt v1.3 · D-055 DECIDED · C-0 ARENA inventory

- **KEYSTONE prompt v1.3 (Shane, 8:13 AM CT):** ARENA (`C:\Users\Hubby\Desktop\ARENA`, Pulsar00100) is the master; repo `blueprints/` is a mirror whose layout follows ARENA; never move / rename / reorganize / delete / overwrite in ARENA; new revs = new files (sheet + rev letter) in the folder where like files live; only `_KEYSTONE` is ours. Reviewer correction orders C-0..C-12 first; stop after each report for GO + option number.
- **D-055 DECIDED ("Shane, Grok chat", CHANGE APPROVED 8:14 AM CT):** today's decisions win over v1.3 text (D-052 76 in stairs, D-050 50 ft portal, D-049 upper tier steps down, D-048 closed, D-053 applied, 55,000 SF = footprint cap only).
- **C-0 (read-only):** ARENA inventoried with Get-ChildItem -Recurse + SHA256 (1 folder, 27 files, flat root). `ASSETS.md` §0: tree, full table (type, size, modified, what it shows, phase), SUPERSEDED marks (first-draft master floor plan ×2 + tabletop render, diorama zone data — protected, intake conflicts; Feb 2026 concept is repo-only), ARENA vs repo location map, 9 differences incl. **C-1 evidence** (ARENA `P2-A-101.pdf` = pre-freeze Rev D "STORAGE (SW)", sha256 6abfa622…; repo frozen `P2-A-101_RevD.pdf` "FLEX / STORAGE (D-039)", 6916d611…). Nothing fixed (ARENA wins). Saved first to `ARENA\_KEYSTONE\ASSETS.md`, then the repo.
- `STATUS.json`: sheets_done = current revs only (11, max 12); `STATUS.md` regenerated (it had been stale since the 7:24 AM session). `shared/validate.py` fails if sheets_done > 12.

## 2026-10-04 ~8:50 AM CT · D-056 no 55,000 SF cap · D-057 area tables · R-021 reconciliation · ARENA backup check

Shane, Grok chat, 8:36 AM CT (correction; supersedes the stopped 8:35 message — the margin-recovery list was NOT done).
- **D-056 DECIDED:** "55,000 SF = early rough estimate, not a limit." No footprint or total cap. **D-031 → SUPERSEDED (retired)**; D-055's "cap is footprint only" clause struck. Margin language removed from `params/phase2.yaml` (header v15, `building.total_sf_meaning`, `footprint_cap_status`, new `size_basis` + `size_next_revision` replacing `footprint_margin_next_revision`, `total_gsf_cap`, source), `phase2_program.yaml` (`target_status` RETIRED), `phase2_site.yaml` (`cap_status`, `footprint_check.basis`), STATUS, D-053 notes, R-018 line 106. Keys read by generators stay (marked RETIRED) so frozen / issued sheets regenerate byte-identical; frozen-sheet descriptions in `sheets:` keep their history wording.
- **D-057 DECIDED:** every area table reports L1 footprint, L2 area, TOTAL GSF and change vs the last revision; size is controlled by budget and parcel.
- **R-021 (new):** true size (decided, next revision) **L1 53,026.7 / L2 28,878.7 / TOTAL 81,905.3 SF** (+1,523.7 / +515.7 / +2,039.3 vs Rev D drawn 51,503 / 28,363 / 79,866). Program basis 54,588.9 vs drawn 53,026.7: +3,980.8 arena-volume gross-up, −773.5 L2 deck, −1,972 lobby void, +326.9 stairs (grossed vs inward), 0 east shift = 1,562.2. TOTAL GSF program 81,521.9 vs drawn 81,905.3. Saved to `ARENA\_KEYSTONE\R-021-area-reconciliation.md` first, then the repo.
- **ARENA backup check (read-only):** no backup found (details in STATUS / report). Box copies exist for every ARENA-only file.
- `shared/validate.py`: comments say `building.total_sf` is a history key, not a cap.
- Frozen checks: all frozen PDFs byte-identical, DXFs entity-identical (known P1-G-001 Rev A internal byte drift only); P2-A-201 D, A-301 B, A-302 A, C-101 A unchanged.
- v1.3.1 ERRATA block drafted for Shane's review — **not saved anywhere** (per order).

## 2026-10-04 ~9:40 AM CT · D-058 · v1.3.1 errata saved · Plan Rev E set (C-1..C-4) · D-059 backup live
- **D-058 DECIDED (Shane 9:10 AM CT):** no GO waits / no "next build options" — proceed with the standard next step (overrides v1.3 §11 / §14). Errata E-1..E-11 accepted → NEW file `ARENA\_KEYSTONE\KEYSTONE_PROMPT_v1.3.1_ERRATA.md` + repo mirror.
- **P2-A-101 / P2-A-102 Rev E** (new `build_e`, `params/phase2_plan_rev_e.yaml`): event floor 120 x 144 (east tier 16 ft from the mats, D-053), building 210 x 252; 4 stairs 76 in with 76 in intermediate landings (D-052 / D-051) = 12.67 x 21.33 ft; ST-2 in a 21.33 x 6.67 ft NE tower (must project 6.67 ft, not 5, to clear the loop); loop 5,026 SF, 718 ft, 7.35 laps/mile; FLEX / STORAGE kept (D-039 → C-1); D-049 low band under upper-tier rows 1-2 drawn, event lockers 1-4 start behind it (−877 SF), under-tier storage hatched; portal + Champion Walk label near E1 and S1 / bus notes (D-034 DECIDED; "D-034 OPEN" removed); 19 in risers noted; D-057 area check with drawn vs program side by side (C-3); no cap / margin text.
- **P2-G-003 Rev G** (new `build_g`, `compute_rev_g`, `summary_g`, `drawn_size`): Rev F + 76 in stairs (vc 874 → 1,145 SF) + 864 SF east clear zone + Rev E loop. Program footprint 54,240.9, L2 28,012.1, L1 + L2 80,747.5. D-057 table: drawn 53,062.2 / 28,914.2 / 81,976.4 (+1,559.2 / +551.2 / +2,110.4 vs Rev D).
- **C-4:** A-201 Rev D (= ARENA `P2-A-201.pdf`) already says the highest aisle is the loop at 15', matching A-301 → no change. A-201 Rev E still needed later for the 210 ft width + 6.67 ft tower (BACKLOG).
- **D-060 OPEN:** D-049 headroom reading + egress passages under rows 1-2.
- **D-059 DECIDED (Shane 9:35 AM CT):** ARENA backup live (nightly scp to shanebrain:/tank/backups/ARENA + ZFS snapshots, 30 days); no-backup flag cleared; bullfrog retired (no references found anywhere).
- Frozen revs unchanged (see report); Rev D / F generators untouched.

## 2026-10-04 ~10:00 AM CT · Set coordinated with Plan Rev E · R-022 · D-061 open
- **P2-A-201 Rev E** (`p2_a_201.py --rev E`, default; new overlay `params/phase2_elev_rev_e.yaml` with `plan_file` = Plan Rev E): building 210 ft wide, arena volume flush with the new east wall ([49,34,210,246]), NE stair tower +6.67 ft, doors from A-101 Rev E, heights note with 19 in risers / D-061. Portal + brand as Rev D. Rev D FROZEN.
- **P2-A-301 Rev C** (`p2_a_301.py --rev C`, default; `phase2_sect.yaml` `rev_c`): Plan Rev E cuts, 19 in upper risers (3 × 6.33 in aisle risers, 12 in treads), stepped tier soffit (1.5 ft structure ASSUMED) → 6 ft low band (5.6' / 7.2' clear) as storage per D-049, lockers behind it (D-060 OPEN, as drawn on A-101 Rev E), 76 in stair + 76 in mid landing (12.67' × 21.33'), exit-path conflict red on A-A + key plan (D-061). Rev B FROZEN.
- **P2-A-302 Rev B** (`p2_a_302.py --rev B`, default; `phase2_sightlines.yaml` `rev_b`): the 'as drawn' basis changed (Rev A as drawn 14 in / east 10 ft; Rev E draws 19 in / 16 ft = Rev A proposed). Re-cased: AS DRAWN (Rev E) vs REV D BASIS (superseded); C-values unchanged (seated min 149 N/S, 101 E). Closed recessed stack does not fit at the 7.08' front. Rev A FROZEN.
- **P2-C-101 Rev B** (`p2_c_101.py --rev B`, default; `phase2_site.yaml` `rev_b`): outline 210 × 252 + NE tower 21.33 × 6.67 (Rev A understated it at 5 ft, −35.6 SF), stairs and doors from Plan Rev E, Rev D outline dashed; the cap table is replaced by the D-057 table (L1 53,062.2 / L2 28,914.2 / TOTAL 81,976.4; +1,559.2 / +551.2 / +2,110.4 vs Rev D; program G-003 G 54,240.9 / 28,012.1 / 82,253.0). No cap / margin language. Rev A FROZEN.
- **R-022** (new): exit paths under the low band. Option A cuts rows 1-2 (−125 seats, or −56 with rails); Option B raises L2 to 17'-9" with 21 in risers (0 seats, +279 SF stairs, ring roof 32.75'). **D-061 OPEN** (open count 18 → 19).
- Sizes unchanged from Plan Rev E (drawn 53,062.2 / 28,914.2 / 81,976.4).

## 2026-10-04 ~10:15 AM CT · Reviewer C-5..C-11 (items that do not depend on D-061) · P2-A-201 Rev F · P1-G-001 Rev E · P2-G-003 Rev H
- **C-5 (25' clear = REFERENCE, not CITED):** P2-A-201 Rev F heights note now reads "Arena clear ≥ 25' REFERENCE (NFHS via Draper, LA RAP; R-019)". P2-A-301 (Rev C prints "CITED") is relabelled in its D-061 revision (Rev D) so A-301 is revised only once. R-019 note added. No other current sheet carries it.
- **C-6:** **P1-G-001 Rev E** (principal, 11x17; `p1_g_001.py --rev E`, default; `phase1.yaml` revision E): Rev D + " — 2021 ASSUMED, verify with AHJ" on the W1 code basis and W2 plumbing code lines, and "Edition still open: county lists 2018 codes; State Fire Marshal uses 2021." (R-006; D-008 stays OPEN, note added). Phase 1 content only: the Phase 2 size no longer prints in NOT INCLUDED (it was stale since D-056). No D-/R- codes on the sheet. Rev D FROZEN (approved, D-025). The delivered Phase1_Package_for_Dr_Headen.pdf is not regenerated.
- **C-7:** A-301 Rev C does not show intermediate handrails on the 76 in stairs. Stair geometry depends on D-061 (Option B changes it), so this goes in **BACKLOG for P2-A-301 Rev D** (IBC 2021 1014.9; D-052; architect to confirm).
- **C-8:** **P2-A-201 Rev F** (`p2_a_201.py --rev F`, default; new overlay `params/phase2_elev_rev_f.yaml`): red callout "STRUCTURAL ENGINEER REQUIRED (freestanding portal)" on the east pier + "STRUCTURAL ENGINEER REQUIRED." in the portal note; ETFE roof / solar removed from NOT SHOWN and listed only as "OPEN QUESTION: ETFE roof / solar (aspirations) — not designed, not in the SF or budget." Notes block raised 0.25 in to fit. Geometry, heights and seats unchanged. Rev E FROZEN.
- **C-9:** confirmed done in C-0 (ASSETS §0 SUPERSEDED marks). No change.
- **C-10:** new `shared/status_writer.py` (stamps `updated_at` from the box clock with the -05:00 offset, enforces sheets_done ≤ 12 / strings < 300 / open count, regenerates STATUS.md, prints the age the way the preflight computes it, `--preflight` runs the bridge). `shared/keystone_status.sh` = byte-identical copy of `ARENA\keystone_status.sh` (sha256 47ecb063…). Tested on the box: offset timestamp 5h20m old → "5h old"; 30 h → "RED — STALE"; Z → correct; a naive CT time reads 5 h too old (why the offset is required); the GitHub fallback path also worked.
- **C-11:** **P2-G-003 Rev H** (`p2_g_003.py --rev H`, default; `phase2_program.yaml` `meta_rev_h`; same `summary_g` numbers): Rev G's SUM column was WC + lav only (37 / 29 / 66), so the label alone would have been wrong. Rev H adds a WC+LAV column (the restroom-SF basis, 66 × 50 SF) and SUM now includes the fountains (39 / 31 / 70), labelled "SUM incl. 4 drinking fountains" with a footnote. Rev G FROZEN. P2-G-003 is the only current sheet with a fixture table (P1-P-001's fixture list is an existing-conditions inventory, not a code table).
- Frozen revisions re-rendered byte-identical (PDF) / entity-identical (DXF): A-201 D, E; A-301 B, C; A-302 A; C-101 A; G-003 A-G; P1-G-001 B-D; set Rev A. P1-G-001 Rev A internal: known PDF drift only.
- Open decisions unchanged: 19.

## 2026-10-04 ~10:20 AM CT · R-023 Champion Walk brick budget (vendor cost only)
- **New research** `research/R-023-champion-walk-brick-budget.md` (saved to `ARENA\_KEYSTONE` first). Source: Shane's vendor price sheet (2026-10-04, REFERENCE; engraving + shipping included). 840 SF walk (D-046), nominal face sizes, no border / joint deduction (upper bound).
- Scenarios (vendor range / S1 average / + logo on every brick): all 4x8 3,780 bricks $71,820–$73,710 / $72,450 / +$22,680; all 8x8 1,890 bricks $51,975–$58,590 / $55,755 / +$11,340; 80/20 by area (ASSUMED) 3,024 + 378 = 3,402 bricks $68,796–$69,363 / $69,111 / +$20,412.
- Break-even donor price per brick to cover the vendor cost only: 4x8 $19.00–$19.50, 8x8 $27.50–$31.00 (+$6 with logo). Donor pricing OPEN (D-044, note added).
- Installation, base / sub-base, border and engraving beyond the vendor price are NOT included and NOT estimated. The only published figure is HomeGuide's residential $8–$16/SF labor (REFERENCE, LOW, not added). Not a final cost estimate (v1.3 §2).
- No sheet changed. Open decisions unchanged: 19.

## 2026-10-04 ~10:45 AM CT · D-061 Option B (L2 17'-9", 21 in risers) + D-060 settled + approvals
- **Decisions:** D-061 DECIDED, Option B (Shane 10:27 AM CT). D-060 SETTLED: event lockers 3,600 SF behind the tier. D-062 logs the approvals of P2-A-201 Rev F, P2-G-003 Rev H, P1-G-001 Rev E and R-023; those revs are FROZEN and byte-identical. Open decisions: 19 → 17.
- **Params first:** new `params/phase2_plan_rev_f.yaml` and `params/phase2_elev_rev_g.yaml`. `phase2_program.yaml` gets `meta_rev_i` and `rev_i` (floor-to-floor 213 in, lockers 3,600). `phase2_sect.yaml` gets `rev_d`, `phase2_sightlines.yaml` gets `rev_c`, and `phase2_site.yaml` gets `rev_c`. `phase2.yaml` is v16: new sheet entries plus frozen / approved flags. `phase1.yaml` sets P1-G-001 E to frozen.
- **P2-A-101 / A-102 Rev F** (`p2_a_plan.py --rev F`):
  - Stairs: ST-1..ST-4 are 12.67 × 24.08 ft (31 risers at 6.87 in, 16 + 15), grown inward. ST-2 grows west, so the NE tower is 24.08 × 6.67 ft.
  - Rooms: mech N, S&C and stretch trimmed.
  - Low band and under-tier zones removed. Event lockers run to the tier lines (3,600 SF), and the exit paths under the tier front are clear at 7'-6".
  - D-057 table vs Rev E: L1 53,080.6 (+18.3), L2 28,932.6 (+18.3), TOTAL 82,013.1 GSF (+36.7). Seats unchanged at 2,200.
- **P2-G-003 Rev I:** program on Plan Rev F with floor-to-floor 17'-9". Stair 305.1 SF per stair per level (was 270.2). L1 + L2 gross 81,119.1 (+371.6 vs Rev G/H); footprint 54,415.1; L2 gross 28,186.3.
- **P2-A-301 Rev D:**
  - Heights and tiers: L2 FF 17'-9", ring roof 32.75', upper risers 21 in, front row 9.0 ft with 7'-6" clear (1.5 ft structure ASSUMED).
  - C-5: the 25' clear is labelled REFERENCE (R-019).
  - C-7: the stair detail shows the 16 / 15 flights and an intermediate handrail, labelled "architect to confirm" (IBC 2021 1014.9).
  - Notes cover 1030.6.2.2 and the 17'-9" elevator travel.
- **P2-A-302 Rev C:** sight lines with 21 in risers at L2 17.75.
  - Lower tier governs and is unchanged: N/S seated 149 / standing 127, E seated 101 / standing 72 mm.
  - Upper tier: N/S 179 / 156, E 105 / 76 mm.
  - No FAIL; E standing MARGINAL (L4–L6, U3–U5).
  - Stack: closed fits with 30.6 in for structure. Open still conflicts, so it stays at the tier face.
- **P2-A-201 Rev G:** L2 line at 17'-9" and ring roof at 32'-9" (datums), with the parapet and arena-behind labels raised. NE tower and doors follow Plan Rev F.
- **P2-C-101 Rev C:** NE tower 24.08 × 6.67 (Rev E tower dashed), stairs from Plan Rev F, D-057 table vs Rev E with program G-003 Rev I.
- **IBC 2021 1030.6.2.2 (if smoke-protected):** highest aisle = loop at 17.75 ft, so the roof must be ≥ 32.75 ft. The arena's U/S structure is drawn at 36 ft: PASS, 3.25 ft margin. The ring roof at 32.75 covers the perimeter rooms, not the seating.
- **Research:** R-022 §5 "Decided" added with the as-drawn numbers. R-023 marked APPROVED.
- **Frozen check:** the newly frozen revs were re-rendered and compared: A-101 E, A-102 E, G-003 H, A-201 F, A-301 C, A-302 B, C-101 B and P1-G-001 E. Results are in the commit message / report.

## 2026-10-04 ~10:58 AM CT · C-12 closed (D-063) + P2-G-002 Rev A code analysis
- **C-12 / D-063 (rule, v1.3 §15):** the 250 / 150 / 50 / 276.85 ft labels on Shane's Google measure markup are ignored and never used as dimensions.
  - Logged in DECISIONS (D-063 DECIDED).
  - ASSETS #11 / §1a / §1c are marked.
  - phase1.yaml `estimate_aerial.c12_rule` added (history / cross-check only; the tape governs).
  - `validate.py` gets **check 8**. It fails if 276.85 is a numeric value anywhere in params, or if 250 / 150 / 50 / 276.85 is a dimension value under phase1.yaml `existing`. Tested by injecting both cases into a temp copy: both FAIL; the real repo passes.
  - C-12 CLOSED.
- **Upper-tier structure 1'-6" = ASSUMED design basis** (Shane 10:48 AM CT; not a decision) until a structural engineer sizes it. Zero margin at 7'-6". The note is `phase2_sect.yaml rev_d.structure_status` (A-301 Rev D re-rendered byte-identical) and the flag is in STATUS what_to_verify.
- **P2-G-002 Rev A — CODE ANALYSIS (SCHEMATIC)** (`phase2/src/p2_g_002.py`, new `params/phase2_code.yaml`, phase2.yaml v17). Tabloid sheet with title block and PRELIMINARY stamp.
  - **Code basis:** editions table, 2021 ASSUMED vs 2018 county (verify with AHJ, R-006).
  - **Occupancy and construction:** A-4 main / A-3 or B / B / S-1, nonseparated recommended (R-007.1). Construction type TBD.
  - **Fire protection:** sprinklers + voice alarm ASSUMED (R-015.5). Smoke-protected seating not assumed.
  - **Occupant load by space** from the Plan Rev F drawn areas (T1004.5):
    - L1 1,474 without the floor.
    - L1 with the floor at 329 / 1,095 / 2,346 / 3,284: 1,803 / 2,569 / 3,820 / 4,758.
    - L2 1,277 base / 1,462 worst. Building worst 6,220.
  - **L1 exit check vs D-054:** door widths not drawn, so 64 in per pair is ASSUMED, giving 704 in.
    - Worst case SHORT: total 933.0 in (−229.0) and main exit E1 466.5 in vs 64 in (−402.5).
    - The sports case passes the total, but E1 still needs 4 pairs.
    - Other exits (1030.3) and lose-one (1005.5) pass in every case.
  - **Options (no redesign):** (1) an E1 bank of 8 pairs (512 in; total 1,152 in), or (2) distributed main exits under 1030.2's last sentence: 15 pairs total (+4).
  - **L2 stairs:** 304 in vs 292.4 in worst (+11.6).
  - **Plumbing:** fixture basis G-003 Rev I. The standing case would need 26 / 50 WC on L1 (vs 10 / 18).
  - **Other sections:** travel and common path, plus open items.
- **Research:** R-007.3 addendum quotes the sections looked up this session: 1010.1.1, 1030.2 (full), 1030.3, 1004.2.1, 1005.5, T1006.2.1, T1017.2. A D-054 note is added (still OPEN).
- No frozen sheet changed.

## 2026-10-04 11:07 AM CT — L1 exits Option 1 DECIDED; P2-A-101 Rev G + P2-A-111 Rev A (life safety)
- **Decision (Shane 11:07 AM CT):** Level 1 exits use Option 1, an 8-pair door bank at E1 across the lobby's 58 ft south wall.
  - 512 in clear, with 64 in per pair ASSUMED.
  - The single controlled entry stays (D-033).
  - Folded into the D-054 note. D-054 floor use stays OPEN, but the exits are sized for the standing worst case.
- **New findings (OPEN, not redesigned):**
  - **D-064 restrooms at the worst case:** 26 M / 50 W WC needed vs 10 / 18 drawn.
    - Option 1: size the restrooms for the worst case.
    - Option 2: limit standing events, or bring temporary facilities.
  - **D-065 security checkpoint vs egress:** the clear width beside the checkpoint is 312 in, but the main exit needs 466.5 in (IBC 1003.6, 1010.5, 1030.2).
    - Option 1: move screening to a side bay of the lobby.
    - Option 2: move screening outdoors onto the plaza.
  - Open count 17 → 19.
- **P2-A-101 Rev G** (Level 1 only; new `params/phase2_plan_rev_g.yaml`; `p2_a_plan.py --rev G`):
  - E1 drawn as an 8-pair bank, with an outer bank and an inner (vestibule) bank.
  - Vestibule widened to 52 ft (520 SF).
  - First aid moved to the lobby's east side (ASSUMED).
  - Checkpoint flagged "EGRESS CONFLICT — see P2-A-111".
  - Rev F is frozen and byte-identical. P2-A-102 stays at Rev F. Footprint, areas and seats are unchanged.
- **P2-A-111 Rev A life safety plan** (new `params/phase2_life_safety.yaml`, `phase2/src/p2_a_111.py`): L1 + L2 at 1" = 50'-0".
  - Exits are shown with clear widths and capacities, and occupant loads per room come from P2-G-002.
  - **L1 checks at the worst case (6,220), all PASS:**
    - Total: 1,152 in vs 933.0.
    - E1: 512 vs 466.5.
    - Other L1 exits: 420.7 vs 356.8.
    - Lose E1: 640 vs 466.5.
    - Sensitivity, whole floor zone of 17,280 SF standing: E1 needs 479.4 in, which also passes.
  - **L2 stairs:** 304 vs 292.4 in. Lose one stair: 228 vs 146.2. Loop: 84 vs 78.6.
  - **Travel distance (T1017.2 limit 250 ft; diagram measurements, UNVERIFIED):** L1 maximum 133 ft, L2 maximum 128 ft.
  - **Exit separation (1007.1.1 exception 2):** the diagonal is 333.2 ft, so the minimum is 111.1 ft. E1–X5 is 252.0 ft, ST-1–ST-3 255.1 ft and ST-2–ST-4 281.5 ft. All PASS.
  - **Common path:** event lockers pass if their door is placed within 75 ft (UNVERIFIED). Seating is TBD.
  - **TBD:** exit discharge from E1 needs ≥ 466.5 in (1028.3). The 28 ft walk is 336 in.
- **Data:** `phase2.yaml` v18 (A-101 Rev F frozen, Rev G entry, new sheet P2-A-111).
- **Research:** R-007.4 addendum (1003.6, 1010.5, 1007.1.1–1007.1.2, 1017.3, T1006.2.1 / 1006.2.1 exception 3, 1030.8, 1028.3, 1028.5).
- **Frozen check:** every other revision re-renders byte-identical (PDF cmp, DXF entities).

## 2026-10-04 11:24 AM CT — D-066 OPEN (exit discharge); P2-A-401 Rev A enlarged plans (event locker rooms 1-4)
- **New finding D-066 (OPEN, no redesign):** the exit discharge from E1 must be ≥ 466.5 in (IBC 1028.3). The Champion Walk is 28 ft = 336 in (D-046), and so is the portal arch opening (D-050), so the discharge must bypass the arch too.
  - Option 1: widen the walk / plaza to ≥ 39 ft at the discharge.
  - Option 2: add a parallel paved discharge path of ≥ 130.5 in beside the walk / portal.
  - Open count 19 → 20.
- **P2-A-401 Rev A** (new `params/phase2_enlarged.yaml`, `phase2/src/p2_a_401.py`; `phase2.yaml` v19): the 4 event locker rooms only, at 1/8" = 1'-0", with a key plan.
  - Envelopes come from plan Rev G: 4 × 900 = 3,600 SF (D-060), under the upper tier at the tier line (D-061, 7'-6" clear).
  - Two templates: rooms 1-2 have the door on the side wall to EXIT (N); rooms 3-4 have it on the end wall to EXIT (E). Rooms 2 and 4 are mirrors.
  - **Each room (ASSUMED):**
    - 2 WC: 1 wheelchair 60×60 (ADA 604.8.1.1) + 1 ambulatory 36×60 (604.8.2.1).
    - 2 lavatories: 1 accessible (606).
    - 60 in turning circle (304.3.1).
    - 4 showers: 1 roll-in 30×60 with 30×60 clearance (608.2.2) + 3 at 36×36.
    - 31-32 lockers, 15 in (2 accessible, 225.2.1 / 811).
    - 2 team benches + 1 accessible bench, 24×48 wall-affixed (903).
    - Trainer table.
    - Room door 36 in (34 in clear, 404.2.3), swinging into the room (IBC 1010.1.2.1, < 50 occupants; ADA 803.3).
  - **Common path (T1006.2.1, ≤ 49 occupants, ≤ 75 ft), measured on this layout:** rooms 1-2 45.6 ft, rooms 3-4 50.9 ft. All PASS.
  - Travel to X5 / X7 is ≤ 66 ft (vs 250).
  - The restroom core is NOT drawn: it waits on D-064, and the sheet says so.
- **Research:** ADA 2010 Standards text saved to the box (`research_src/ada2010_v2.txt`, www.ada.gov, retrieved 2026-10-04). Sections are quoted in the new note `research/R-024-ada-locker-rooms.md`.
- **Frozen check:** every other revision re-renders byte-identical.

## 2026-10-04 11:45 AM CT — P2-A-103 Rev A floor overlays (mats, court, telescopic tier, floor cases)
- D-064, D-065 and D-066 stay OPEN (Shane has not answered; nothing assumed). D-054 (floor uses) stays OPEN. Open count stays 20.
- **P2-A-103 Rev A** (new `params/phase2_overlays.yaml`, `phase2/src/p2_a_103.py`; `phase2.yaml` v20): four overlays on the P2-A-101 Rev G plan at 1" = 50'-0" (cases at 1" = 100'-0").
  - **(a) Wrestling:** 4 × 42 ft mats, 2 × 2 (D-014, D-030). Checked on the layout, all PASS:
    - circle + safety area: 42 ft mat vs ≥ 38 ft (NFHS 2-1-2);
    - space around each mat: W 10 / between 10 / E 16 / S and N 25 ft vs ≥ 10 (2-1-5);
    - scorer's table 10.5 ft from the mat (2-3); benches 10.5 ft from the mat and 10 ft from the table (2-1-5);
    - circle to walls / tier front: W 17 / E 23 / S and N 32 ft vs about 10 ft (KHSAA recommendation).
    - Tables (8 × 2.5 ft) and benches (10 × 1.5 ft) are ASSUMED. The portal and V1 aisles are kept clear. NFHS text is the 2014-15 edition (current book UNVERIFIED).
  - **(b) Basketball:** only the 1 court already in params: 84 × 50 ft (NFHS 1-1) + 10 ft runout (1-2-1); 22 / 28 / 20 / 20 ft to the floor edges. Volleyball and a 2nd court are TBD (not in params or decisions; not drawn).
  - **(c) Telescopic lower tier:** open (12 ft) floor 120 × 144 = 17,280 SF vs closed (3'-6" Hussey stack at the upper-tier face) 128'-6" × 161'-0" = 20,689 SF (+3,409 SF, lower seats stowed). ICC 300 via IBC 1030.1.1.
  - **(d) Floor cases from P2-G-002 Rev A,** hatched on 114 × 144 = 16,416 SF: sports 329 / tables + chairs 1,095 / chairs 2,346 / standing 3,284 (L1 1,803 / 2,569 / 3,820 / 4,758), with layout notes (IBC 1030.9.1, 1030.13.1, 1030.13.2, 1030.13.2.1; posting 1004.9).
    - Tier closed: standing 4,138 / chairs 2,956 with no lower seats gives L1 4,512 / 3,330, below the 4,758 design case (arithmetic).
  - Flag (no new program): chair / table / stage storage is not in the program (TBD, D-054).
- **Research:** R-007.5 addendum (1004.9, 1030.1.1, 1030.1.1.1, 1030.9.1, 1030.13.1, 1030.13.2, 1030.13.2.1).
- **Frozen check:** every other revision re-renders byte-identical.

## 2026-10-04 12:10 PM CT — P2-A-901 Rev A 3D massing model + views (P2-T-011)
- D-054, D-064, D-065 and D-066 stay OPEN. Nothing on the sheet or in the model implies a choice: no checkpoint modelled (D-065), no added restroom volume (D-064), no floor-use staging (D-054), Champion Walk shown at the drawn 28 ft with a D-066 note. Open count stays 20.
- **P2-A-901 Rev A** (new `params/phase2_massing.yaml`, `phase2/src/p2_a_901.py`; `phase2.yaml` v21): MASSING ONLY, PRELIMINARY, NTS axonometric views built from the current params (plan Rev G L1 / Rev F L2, A-201 Rev G heights / portal / brand / walk, A-301 Rev D / A-302 Rev C sections, C-101 Rev C site; D-041, D-043, D-046, D-047, D-050).
  - V1 aerial from the SW (with site: walk, bus loop diagram, road, service apron); V2 cutaway at L2 FF 17'-9" from the SW (roofs removed: tiers, event floor + mats, lobby open to below); V3 aerial from the SE; V4 aerial from the NW (service side, S1); V5 portal + Champion Walk from the SSW.
  - Heights are only those already in params (L2 FF 17'-9" DECIDED; ring roof 32.75 ft / arena roof 42 ft ASSUMED per A-201 Rev G; portal 50 ft max, crown 34 ft, springline 22'-1"). Door 6 × 8 ft drawn symbol ASSUMED. Colours: finish ids from `phase2_elev.yaml` (hex ASSUMED swatches).
  - Not modelled: parapets, rooftop units, structure, windows / cladding, grading, landscaping, lighting, parking (site TBD, D-006), signage content.
  - **Model file:** `phase2/out/3d/P2-A-901_RevA_massing.obj` + `.mtl` (feet, Y-up; deterministic, byte-identical on re-run).
- **Frozen check:** every other revision re-renders byte-identical.

## 2026-10-04 1:21 PM CT — Decisions D-054 / 064 / 065 / 066 + storage room (D-067) applied to the sheets
- **Decisions (Shane, Grok chat, 1:21 / 1:22 PM CT):**
  - **D-054 CLOSED:** event floor = chairs only, 7 net → 2,346 (no standing floor case).
  - **D-064 CLOSED, Option 2:** restrooms sized to the chairs-only case; posted occupant loads; temporary units above that.
  - **D-065 CLOSED, Option 1:** screening in a lobby side bay; 468 in clear kept to the E1 bank (≥ 466.5 in).
  - **D-066 CLOSED:** Champion Walk 40 ft = 28 ft brick + 6 ft bands both sides, around both piers (IBC 1028.3).
  - **D-067 DECIDED (new program item):** chair / table / stage storage annex [52,252]-[122,282] ft = 70 × 30 = 2,100 SF on the north wall, S1 moved to y 282 (sizing ASSUMED except the cart data).
  - **D-068:** approvals logged and frozen: P2-A-111 Rev A, P2-A-401 Rev A, P2-A-103 Rev A, P2-G-002 Rev A.
  - **D-069 OPEN (new finding):** chairs-only L1 restrooms need 22 M / 42 W WC, lav 9 / 12, DF 4 vs 10 / 18, 4 / 5, 2 drawn (+48 fixtures), about +535 to +2,400 SF; 3 options, rooms not redrawn.
  - Open count 20 → **17**.
- **New revisions** (all new params files; frozen revisions untouched; `phase2.yaml` v22):
  - **P2-A-101 Rev H** (`phase2_plan_rev_h.yaml`): storage annex + S1 on the north, screening side bay (468 in clear), restroom D-069 flags (rooms not redrawn).
  - **P2-A-111 Rev B** (`phase2_life_safety_rev_b.yaml`): life safety at the chairs-only floor, screening bay outside the egress width, 40 ft discharge walk.
  - **P2-G-002 Rev B** (`phase2_code_rev_b.yaml`): occupant loads at 2,346 floor, fixture count and D-069 finding with the +535 to +2,400 SF range.
  - **P2-G-003 Rev J** (`phase2_program.yaml` rev_j): program + loop + storage; F 56,515 / L2 28,186 / total 84,701 SF program vs 84,113 drawn.
  - **P2-A-401 Rev B** (`phase2_enlarged_rev_b.yaml`): L1 restroom core tight test-fit (men 34 × 23 ft = 860 SF vs 700; women 41 × 33 ft = 1,488 vs 1,150; + 2 fountain alcoves 36 SF ≈ +535 SF).
  - **P2-A-103 Rev B** (`phase2_overlays_rev_b.yaml`): chairs-only floor case, storage route diagram annex → floor.
  - **P2-C-101 Rev D** (`phase2_site.yaml` rev_d): annex footprint, 40 ft walk with 6 ft bands (mirrored about x 226), service apron [52,282]-[85,306] ft.
  - **P2-A-901 Rev B** (`phase2_massing_rev_b.yaml`): annex (16 ft high ASSUMED), walk bands, screening zone; model `phase2/out/3d/P2-A-901_RevB_massing.obj` + `.mtl`.
- **Areas:** GSF drawn 82,013 → **84,113** (+2,100); L1 53,081 → 55,181; L2 28,933 unchanged.
- **Follow-up:** P2-A-201 north elevation does not yet show the annex. G-001 cover, combined set and PR are ON HOLD (Shane 1:46 PM CT).
- **Frozen check:** every frozen / approved revision re-renders byte-identical (PDF + DXF entities; A-901 Rev A OBJ / MTL unchanged).

## 2026-10-04 3:31 PM CT — D-069 closed: east restroom bump-out (Option 2)
- **Decision (Shane, 3:31 PM CT):** **D-069 CLOSED = Option 2** ("Option B"): second restroom pair in a one-storey bump-out opposite the lobby core. East concourse width and the SW FLEX room unchanged (D-039 unchanged). Open count 17 → **16**.
- **Location: EAST** (KEYSTONE pick, as asked): bump-out [210,161.09]-[240,217.09] = **30 × 56 ft = 1,680 SF**, one storey, 16 ft ASSUMED, centred on V2 / EXIT (E). Why east: the north side is the back-of-house yard (service drive, S1 apron, storage annex x 52-122, X4 / X5 / ST-2 discharges); the east side is open and the public reaches it straight from the floor / east tier through V2 and the EXIT (E) passage, which continues 30 ft east as the core-2 corridor. X7 moves 30 ft east to the bump-out east face (x 240).
- **Fixtures (chairs-only, load 3,446, IBC 2021 Table 2902.1, R-009):** required 22 M / 42 W WC, 9 / 12 lav, 4 DF. Lobby core 10 / 18, 4 / 5, 2 (unchanged) + **core 2: men 5 WC + 7 urinals, 5 lav; women 24 WC, 7 lav; 2 DF hi-lo + janitor**. Urinals 7 ≤ 67% of 12 = 8 (IPC 2021 424.2). Totals 22 / 42, 9 / 12, 4 = required.
- **Params first:** `phase2.yaml` v23; `DECISIONS.md` D-069 DECIDED; `phase2_program.yaml` rev_k; new `phase2_plan_rev_i.yaml`, `phase2_life_safety_rev_c.yaml`, `phase2_enlarged_rev_c.yaml`, `phase2_massing_rev_c.yaml`, `phase2_elev_rev_h.yaml`; `phase2_site.yaml` rev_e.
- **New revisions** (frozen revisions untouched):
  - **P2-G-003 Rev K:** program + fixture split (lobby core / core 2) + bump-out 1,680 SF; program F 58,195 / L2 28,186 / total 86,381 SF.
  - **P2-A-101 Rev I:** bump-out drawn (rooms 25-27, corridor), east wall open at EXIT (E), X7 at x 240, D-069 flags removed.
  - **P2-A-111 Rev C:** T1 133.1 → 163.1 ft; new T7 (women's far corner → X7) 67.0 ft; common path women 38 / men 34 ft (≤ 75); diagonal unchanged at 333.2 ft (all outline corners checked); E1-X5 separation 252 ≥ 111.1 ft; locker rooms 3-4 travel 95.9 ft.
  - **P2-A-401 Rev C:** core-2 enlarged plan at 1/16" (men 26 × 14 = 364 SF, women 30 × 34 = 1,020 SF, DF / janitor 56 SF, corridor 240 SF) + fixture table + why-east note; locker rooms unchanged.
  - **P2-C-101 Rev E:** outline + bump-out; area table vs Rev H; X7 east discharge TBD with the parcel.
  - **P2-A-901 Rev C:** bump-out mass (16 ft ASSUMED) with X7; model `phase2/out/3d/P2-A-901_RevC_massing.obj` + `.mtl`.
  - **P2-A-201 Rev H:** annex + bump-out on every face where they show (north: annex in front with S1, bump-out at the east end; east: bump-out in front with X7, annex beyond; west: annex; south: bump-out beyond the east end); N / E / W at 1" = 40'.
- **Areas (D-057):** L1 55,181 → **56,861** (+1,680); L2 28,933 (unchanged); TOTAL GSF 84,113 → **85,793** (+1,680). Program Rev K 86,381.
- **Findings:** (1) chair layouts on the floor must keep an aisle to V2 (core 2 is reached through V2); (2) X7's discharge path from x 240 to a public way is TBD with the parcel (D-006); (3) core-2 plumbing (waste, vent, water) is an MEP item; (4) P2-G-002 Rev B still shows D-069 OPEN (no G-002 Rev C was ordered).
- **Still PAUSED:** G-001 cover, combined set PDF and PR not built.
- **Frozen check:** `/tmp/cur_check7.sh` (explicit `--rev`, now including the 1:21 PM revs, A-201 A-G and the new revs): every frozen / committed revision re-renders byte-identical (PDF + DXF entities; A-901 OBJ / MTL); new revs deterministic.

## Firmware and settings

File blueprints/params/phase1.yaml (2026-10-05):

# phase1.yaml: SINGLE SOURCE OF TRUTH for Phase 1 (remodel of the existing high school wrestling room)
# Rules (KEYSTONE prompt v1.1 §8): every value carries `source`. Unknown = TBD, drawn as TBD, logged OPEN in DECISIONS.md.
# Phase 2 (new building) values never appear in this file. Superseded Feb 2026 concept values never appear anywhere.
# Sources used: "concept sheet" | "Shane" | "Shane measure" (pending) | "Claude session" | "Grok session" | "intake 2026-10-03" | R-### | D-###

meta:
  project: Hazel Green Regional Athletic Complex
  project_alt_title: North Alabama Regional Athletic Complex
  arena_name: Trojan Horse Arena
  phase: 1
  type: remodel
  units: feet
  version: 1
  version_date: "2026-10-03"
  sheet_size: "11x17 tabloid"
  sheet_date: October 2026
  stamp: "PRELIMINARY — CONCEPTUAL DESIGN — NOT FOR CONSTRUCTION"
  drawn_by: "Drawn by KEYSTONE (AI) for Shane Brazelton"
  source: "Shane (KEYSTONE prompt v1.1 §3, §8, §9) + concept sheet"

brand:
  color_primary: "#CC0000"
  color_secondary: "#1A1A1A"
  use: covers and renders only; technical sheets black on white
  tagline: "Building Champions, One Mat at a Time"
  source: "Shane (colors); repo (tagline); prompt §9 (use)"

site:
  owner: Public high school property, Madison County
  owner_detail: Madison County Schools
  district: Madison County District 1
  location: Hazel Green, Madison County, Alabama
  building: existing high school building
  rooms_in_scope: existing wrestling room + adjacent walk-through room
  room_location_in_building: TBD
  source: "concept sheet; intake 2026-10-03 (owner_detail; room location UNKNOWN → D-001)"

existing:
  wrestling_room:
    length_ft: 55       # 55'-0", inside, wall to wall, north-south (long side)
    width_ft: 45        # 45'-0", inside, wall to wall, east-west
    shape: rectangle
    long_side: north-south
    measured_at: inside face of wall to inside face of wall
    floor_area_sf_calc: 2475   # 55 x 45, calculated by KEYSTONE from the tape dimensions (inside)
    wall_thickness: TBD                 # actual, unverified
    wall_thickness_assumed_in: 8        # ASSUMED 8 in CMU unless noted (drawn on P1-A-101 outside the inside face)
    wall_thickness_label: "8\" CMU — ASSUMED"
    ceiling_ft: 10                      # 10'-0"
    ceiling_label: "CLG 10'-0\""
    wall_material: CMU (concrete masonry unit) building
    doors: TBD          # measured location, width, swing for each (still TBD)
    door_assumed:       # applies to all 4 openings (3 emergency exits + 1 hallway door). ASSUMED, not measured.
      width_ft: 3       # 3'-0"
      height_ft: 7      # 7'-0"
      type: single hollow metal door
      label: "ASSUMED STANDARD, VERIFY"
      swing_drawn: outward from the wrestling room (direction of egress); hinge side arbitrary — both ASSUMED, verify
      south_exit_note: "Shane's markup shows two triangles at the south exit; it may be a pair of doors — verify"
      confirmation: "locations confirmed by Shane vs markup 2026-10-03; exit swings out confirmed; hallway door swing + south exit single/pair still to verify"
      exit_swing: outward (CONFIRMED, Shane 2026-10-03 10:29 PM CT)
      hallway_door_swing: outward as drawn — ASSUMED, verify
      south_exit_leaves: single as drawn — ASSUMED, verify (may be a pair)
      source: "Shane 2026-10-03 10:12 PM CT (assume standard 3'-0\" x 7'-0\" single HM doors, label ASSUMED STANDARD, VERIFY); swing/hinge drawing choice by KEYSTONE; confirmation → Shane 2026-10-03 10:29 PM CT (D-026: locations match markup, exits swing out; hallway swing + south single/pair left unfilled)"
    doors_approx:       # APPROX. locations read off Shane's aerial markup. NOT measured (not dimensioned). Confirmed by Shane vs markup 2026-10-03 (D-026).
      exit_west:
        wall: west
        kind: emergency exit
        along_wall_from: north
        fraction_approx: 0.65     # read from sketch pixels (~0.63), rounded to 0.05
        source: "Shane aerial sketch 2026-10-03 (triangle on west side); position read by KEYSTONE, APPROX."
      exit_south:
        wall: south
        kind: emergency exit (sketch shows two triangles, possibly a pair of doors)
        along_wall_from: west
        fraction_approx: 0.5      # read from sketch pixels (~0.49)
        source: "Shane aerial sketch 2026-10-03 (triangles on south side); position read by KEYSTONE, APPROX."
      exit_northeast:
        wall: east
        kind: emergency exit (to the outside, north of the support wing)
        along_wall_from: north
        fraction_approx: 0.3      # read from sketch pixels (~0.29)
        source: "Shane aerial sketch 2026-10-03 (triangle near NE, drawn just outside the roof line); position read by KEYSTONE, APPROX."
      hallway_door:
        wall: east
        kind: door to the support wing / open hallway
        along_wall_from: north
        fraction_approx: 0.7      # read from sketch pixels (~0.67-0.73)
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

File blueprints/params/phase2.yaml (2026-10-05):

# phase2.yaml: SINGLE SOURCE OF TRUTH for Phase 2 (new building + campus)
# v1 SEED, 2026-10-03: P2-T-001 pulled forward at Shane's request, only to hold his data.
# v2, 2026-10-03 10:45 PM CT: PHASE 2 ACTIVE in parallel with Phase 1 (D-027). Phase 2 is Shane's build, not a school
# project (D-028): no school ownership, district approval, school bidding or school review is assumed here. Owner OPEN (D-007).
# Program test-fit inputs live in params/phase2_program.yaml (P2-T-003b).
# v3, 2026-10-03 11:09 PM CT: 55,000 SF is a FOOTPRINT cap; up to 2 levels; total GSF no longer capped at 55,000 (D-031).
# v4, 2026-10-03 11:26 PM CT: ~1,370-seat option rejected (D-032); suites to keep ~2,200 spectators under study (D-030 OPEN).
# v5, 2026-10-03 11:39 PM CT: PROGRAM LOCKED (D-030 DECIDED): 16,400 SF event floor, 4 x 42 ft mats, 2,200 bowl seats, 2 levels,
#     no suites (PARKED), S&C + cross-training on Level 2 over the lockers. The 22,000 SF tag is SUPERSEDED for the event
#     floor and kept as history (sf_tagged_superseded). Locked facts change only on "CHANGE APPROVED".
# v6, 2026-10-04 4:30 AM CT: SEATING TYPE LOCKED (D-009 DECIDED): MIX — telescopic lower tier, fixed upper tier.
#     Block plan Rev B direction: entry south-center on the arena N-S axis, mech off the west public side (Shane review).
# v7, 2026-10-04 4:43 AM CT: ACCESS CONTROL DECIDED (D-033): single controlled entry for everyone at the south grand entrance
#     (security checkpoint); perimeter doors EXIT ONLY; deliveries / buses OPEN (D-034). Block plan Rev C.
# v8, 2026-10-04 4:55 AM CT: LEVEL 2 RUNNING / TRAINING LOOP DECIDED (D-035): S&C 6,000 → 5,224 SF and cross-training
#     4,000 → 3,500 SF (Shane's approval to change these locked values); new spaces.training_loop. Block plan Rev D.
# v9, 2026-10-04 5:27 AM CT: P2-A-101/102 Rev D + P2-G-003 Rev F APPROVED (D-036) and FROZEN as "Phase 2 Schematic Set
#     Rev A" (sets.phase2_schematic_set_rev_a). Loop 2 lanes x 42 in DECIDED for now (D-037); concourse width vs egress
#     OPEN (D-038, R-018). West unprogrammed space kept as-is, labeled FLEX (D-039). P2-A-201 elevations Rev A started.
# v10, 2026-10-04 6:16 AM CT: OFFICIAL MARK DECIDED (D-041): circular horse-head badge with Greek key border
#     (brand.official_mark, blueprints/brand/THA_logo_*.svg); D-040 closed; trademark search OPEN (D-042). P2-A-201 Rev A
#     frozen; Rev B puts the mark on the portal.
# v11, 2026-10-04 6:22 AM CT: GRAND ENTRANCE PORTAL FREESTANDING over the brick CHAMPION WALK (donor bricks) (D-043; approach);
#     walk size + donor-brick program OPEN (D-044). P2-A-201 Rev B shows it; next A-101 revision adds it to the plan.
# v12, 2026-10-04 6:45 AM CT: P2-A-201 Rev B approved + frozen; underside crimson + gold trim (D-045); Champion Walk 28 x 30 ft,
#     brick tiers (D-046); badge 11 ft (D-047); stairs 70 in clear (D-038 closed); service S1 north + south bus loop (D-034);
#     reference photo held off-repo (D-048 OPEN). P2-A-201 Rev C; P2-A-301 sections Rev A.
# v13, 2026-10-04 7:24 AM CT: photo is Shane's own, held off-repo by choice (D-048 closed); upper tier steps down from the
#     loop, storage / mech under its low front, lockers only at full height (D-049); portal <= 50 ft, crown 34 ft (D-050);
#     switchback mid landing 70 in (D-051); egress 76 in stairs PROPOSED (D-052); sight-line fix PROPOSED (D-053).
#     P2-A-201 Rev C + P2-A-301 Rev A frozen; P2-A-201 Rev D, P2-A-301 Rev B, P2-A-302 Rev A (sight lines).
# v14, 2026-10-04 7:49 AM CT: D-053 DECIDED (upper risers 19 in, east seats 6 ft further out, +~1,512 SF) and D-052 DECIDED
#     (4 stairs x 76 in clear + intermediate handrails); both apply at the next A-101/A-102/A-301 revision. Footprint
#     53,026.7 SF drawn basis (margin wording retired by D-056). R-006 / R-007 done; D-054 (event floor uses) OPEN.
#     New site sheet P2-C-101 Rev A (campus diagram).
# v15, 2026-10-04 8:36 AM CT: NO 55,000 SF cap (D-056): 55,000 SF was an early rough estimate, not a limit; D-031 retired;
#     margin language removed (frozen sheets keep it as history). Every area table reports L1 footprint, L2 area, TOTAL GSF
#     and change vs the last revision (D-057). Size is controlled by budget and parcel. building.size_next_revision (R-021).
# v16, 2026-10-04 10:27 AM CT: D-061 DECIDED Option B (L2 FF 17'-9", 21 in upper risers, front row 9.0 ft = 7'-6" clear, no
#     seats lost); D-060 settled (event lockers 3,600 SF); A-201 Rev F, G-003 Rev H, P1-G-001 Rev E, R-023 APPROVED + frozen (D-062).
# v17, 2026-10-04 10:48 AM CT: new sheet P2-G-002 Rev A (code analysis, params/phase2_code.yaml); C-12 rule D-063 (Phase 1 only).
# v18, 2026-10-04 11:07 AM CT: L1 exits Option 1 DECIDED (E1 8-pair door bank, 512 in clear; D-054 note); P2-A-101 Rev G
#     (params/phase2_plan_rev_g.yaml), Rev F frozen; new sheet P2-A-111 Rev A life safety plan (params/phase2_life_safety.yaml).
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

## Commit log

2026-02-05 Add Hazel Green Trojans Sports Complex Phase 1 3D model and renders
    Generate complete architectural model for the North Alabama Regional
    Athletic Complex wrestling facility using CadQuery (STEP/STL exports)
    and matplotlib (2D floor plan + 3D perspective renders). Phase 1 design:
    120x250ft, ~30,000 SF, 800-seat capacity, 4 practice mats + 1
    championship center mat in Trojan Red (#CC0000) and Black (#1A1A1A).
    https://claude.ai/code/session_016jPwTrQfuvSCWy6fE44vE8
    [Hazel_Green_Trojans_Complex.step, Hazel_Green_Trojans_Complex.stl]
2026-02-05 Improve 3D renders with branding, better angles, and FreeCAD macro
    - Enhanced 3D views: ground plane, red accent band on exterior,
    parapet roof edges, red signage banner above entrance, zoomed
    entrance perspective, zone-specific floor colors
    - Added branding watermarks and budget info to all renders
    - Added import_to_freecad.py macro for STEP -> FCStd conversion
    - Updated README with FreeCAD conversion instructions
    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
2026-03-12 Add CLAUDE.md and update README.md with infrastructure docs
    - Create CLAUDE.md following thebardchat/constitution pattern with
    project overview, Pi 5 + Pironman 5-MAX infrastructure table,
    NVMe RAID 1 details (2x WD Blue SN5000 2TB, mdadm), repo structure,
    and credits section
    - Update README.md with Constitution link, infrastructure table,
    and credits (Claude, Raspberry Pi 5, Pironman 5-MAX)
    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
2026-04-23 Add GitHub Pages landing page — ShaneBrain ecosystem
2026-04-24 chore: add sponsor button (YouTube + Buy Me a Coffee)
2026-10-03 Add professional interactive 3D floor plan visualization
    - Three.js r128 with OrbitControls for smooth navigation
    - Interactive zones with hover/click detection
    - Information panel with zone details (SF, description)
    - Architectural maquette aesthetic with shadows and lighting
    - Wrestling mats with decorative rings, tiered seating, grand portal entrance
    - All zones color-coded per master floor plan (arena, seating, lockers, S&C, cross-training, concourse)
    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
2026-10-03 Rebuild 3D visualization to match physical maquette proportions
    Major improvements:
    - Arena repositioned as dominant central feature (22,000 SF)
    - Four wrestling mats displayed as distinct circular elements with crimson rings
    - Tiered stadium seating (12 rows, dark crimson) on east side of arena
    - Proper zone spatial layout matching floor plan:
    * Grand portal (limestone) at south entry
    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
2026-10-03 Add bloom effects and architectural polish to 3D visualization
    Enhancements:
    - UnrealBloomPass post-processing for sophisticated lighting
    - Emissive materials on all zones (glow effect on seating, rings)
    - Improved material properties: metalness, roughness, emissive intensity
    - Better lighting setup: ambient + directional + rim light
    - Tone mapping (ReinhardToneMapping) for professional renders
    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
2026-10-03 Deploy interactive diorama viewer with drag-and-drop floor plan
    Major UX upgrade:
    - Drag-and-drop floor plan image directly onto the board
    - Table-top diorama aesthetic (looking down at physical model)
    - Neon zone overlays that glow on hover
    - Bloom post-processing for professional polish
    - Spotlight + directional lights mimicking overhead lighting
    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
2026-10-03 Production-ready diorama: refined color accuracy and bloom optimization
    Critical fixes applied:
    - sRGBEncoding for texture color fidelity (architectural plans render true)
    - ACESFilmicToneMapping for professional color grading
    - High bloom threshold (1.5) prevents white backgrounds from glowing
    - Zone emissive intensity: 10.0 on hover (far exceeds threshold for crisp neon effect)
    - Material properties tuned: no emissive bleed on board surface
    - Ambient light increased to 0.8 (better plan visibility)
    - Spotlight penumbra 0.5 for soft shadows
    Result: Floor plan images display with accurate colors, zones glow bright neon on hover,
    professional architectural aesthetic. Ready for high-stakes pre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
2026-10-05 Add Phase 2 blueprints (KEYSTONE schematic set through Rev D) from grok/keystone
    [P1-A-101_RevA.dxf, P1-G-001_RevA_internal.dxf, P1-G-001_RevB_principal.dxf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]
2026-10-09 Site: concept studies landing page (SRM-style arena + metal pop-outs), live updates.json feed
    Replaces the old strategy-game landing page. Preliminary / not for construction. Concept renders in concepts/, update via add_update.py (see SITE.md).
2026-10-09 Deploy only the public site files; stop serving blueprints/research/decisions and the set PDF
    The Set Rev D cover prints the planning budget range, so the PDF is not published; the site says the set is available on request.
2026-10-09 P2-A-101 Rev K: curved envelope R = 20 ft, ST-2 inside the envelope, mech bay; site update
    [P2-A-101_RevK.dxf]
2026-10-09 P2-A-102 Rev G (Level 2) sheet + site update
    [P2-A-102_RevG.dxf]
2026-10-09 P2-G-002 Rev E exit recheck + site update
    [P2-G-002_RevE.dxf]
